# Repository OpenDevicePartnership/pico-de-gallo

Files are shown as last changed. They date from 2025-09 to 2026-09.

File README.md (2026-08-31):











# Pico de Gallo

A USB bridge that turns a [Raspberry Pi Pico 2](https://www.raspberrypi.com/products/raspberry-pi-pico-2/)
into a host-accessible I²C, SPI, UART, GPIO, PWM, ADC, and 1-Wire interface. Write and test
embedded Rust drivers on your development machine without cross-compiling
or flashing firmware to a target board.

## Overview

Pico de Gallo provides:

- **I²C**: read, write, write-then-read, bus scanning, and transaction batching
- **SPI**: read, write, full-duplex transfer, write-then-read, and transaction batching
- **UART**: read, write, flush, and baud rate configuration
- **GPIO**: digital input/output, edge event monitoring (subscribe/unsubscribe)
- **PWM**: 4-channel PWM output with configurable frequency and duty cycle
- **ADC**: 4 GPIO-based analog inputs (12-bit)
- **1-Wire**: bus reset, read, write, strong pullup, and ROM search (PIO hardware)
- **Configuration**: runtime I²C/SPI/UART/PWM frequency and SPI mode changes

All communication uses [postcard-rpc](https://docs.rs/postcard-rpc) over
USB — a compact, typed, binary RPC protocol.

## Book

The [Pico de Gallo Book](https://balbi.sh/pico-de-gallo/)
covers hardware assembly, firmware flashing, and a step-by-step guide to
writing an embedded device driver using Pico de Gallo.

## Crates

| Crate | Description |
|---|---|
| [`pico-de-gallo-firmware`](crates/pico-de-gallo-firmware) | Embassy-rs firmware for the RP2350 |
| [`pico-de-gallo-lib`](crates/pico-de-gallo-lib) | Async host library (requires tokio) |
| [`pico-de-gallo-hal`](crates/pico-de-gallo-hal) | `embedded-hal` + `embedded-hal-async` implementation |
| [`pico-de-gallo-ffi`](crates/pico-de-gallo-ffi) | C FFI bindings (shared library + header) |
| [`gallo`](crates/pico-de-gallo-app) | CLI application for batch-mode access |
| [`gallo-mcp`](crates/pico-de-gallo-mcp) | MCP server exposing the device to AI agents |
| [`pico-de-gallo-internal`](crates/pico-de-gallo-internal) | Shared wire-protocol types (internal) |

### Firmware

Embassy-rs firmware for the RP2350 that exposes I²C, SPI, UART, and GPIO
peripherals over USB via postcard-rpc endpoints.

Two mutually exclusive board-revision features select the target. `hw-rev2`
(v1.1 and later) is the **default**. `hw-rev1` (v1.0) is **deprecated** — it
stays supported, built in CI, and published as `firmware-rev1.uf2`, with
removal no earlier than 2031-09-01 — and must now be requested explicitly
with `--no-default-features --features hw-rev1`. See
[`crates/pico-de-gallo-firmware/README.md`](crates/pico-de-gallo-firmware/README.md)
for build commands and
[Revisions](https://balbi.sh/pico-de-gallo/hardware/revisions.html) for the
policy.

### Library

Async host-side library wrapping the postcard-rpc transport. Provides
typed methods for every firmware endpoint. Requires the tokio runtime.

### HAL

Implements both `embedded-hal` and `embedded-hal-async` traits — including
`I2c`, `SpiBus`, `SpiDevice`, GPIO digital I/O, delay, and `embedded-io`
Read/Write for UART (0.6 and 0.7, selectable by Cargo feature) — so embedded
device drivers written against those traits can be tested on a host machine
with real hardware attached to the Pico de Gallo.

### App

Command-line tool (`gallo`) for interactive and batch-mode I²C/SPI/UART/GPIO
access. Supports hex, binary, and ASCII output formats.

### FFI

C-compatible shared library wrapping the Rust host library. Generates a
C header via cbindgen. Suitable for integration into C/C++/Python/etc.
projects.

### Internal

Shared wire-protocol crate defining all postcard-rpc endpoints, request
and response types, and constants. Used by both firmware and host crates.

## Zephyr

Zephyr module that lets a Zephyr application running on `native_sim` drive
real I²C, SPI, and GPIO peripherals through the `pico_de_gallo` shield — so
you can write and debug a Zephyr driver on your laptop against real silicon,
without cross-compiling or flashing. See [`zephyr/README.md`](zephyr) for the
full guide; the module is documented there rather than in the book, by the
carve-out recorded in `AGENTS.md` §15.1.

## Hardware

KiCAD schematic and PCB design for a Pico 2 daughter board. The v1.1
board features a single keyed 2x12 shrouded header that routes all 20
firmware signals with on-board I²C pull-ups and ADC input protection.

## Case

3D-printable snap-fit enclosure (FreeCAD) in two parts — body and lid.

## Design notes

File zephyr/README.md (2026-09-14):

# pico-de-gallo Zephyr Module

This README describes the `pico-de-gallo/zephyr` Zephyr module, including how
to build and run it. It is the **authoritative** guide for the module: by a
deliberate ruling recorded in `AGENTS.md` §15.1, the module has no `book/`
chapter while it remains work-in-progress. That ruling is revisited once the
upstreaming tracked in
[#98](https://github.com/OpenDevicePartnership/pico-de-gallo/issues/98) lands.

`pico-de-gallo/zephyr` is a Zephyr module that lets Zephyr applications drive
real I2C, SPI, UART, GPIO and PWM peripherals from `native_sim`. It provides the
`pico_de_gallo` [shield](https://docs.zephyrproject.org/latest/hardware/porting/shields.html),
whose drivers forward Zephyr I2C, SPI, UART, GPIO and PWM API calls through the
`pico-de-gallo-ffi` C API to a Pico de Gallo board attached to the host over
USB.

The practical upshot: you write and debug a Zephyr device driver on your
laptop, against the real silicon, without cross-compiling or flashing.

---

## Prerequisites

| Requirement | Notes |
|---|---|
| Zephyr revision | The measured build environment was `main` at `v4.4.0-6123-g26f811ee9d0d`, commit `26f811ee9d0dc8f67e8e596f6aef9e6e79a55db0`. CI pins that exact commit; `.github/workflows/zephyr.yml` fails if this line and its `ZEPHYR_REVISION` disagree. The driver uses `spi_cs_control.delay`, `spi_context`'s `ctx->num_cs_gpios`, `SPI_CONTEXT_CS_GPIOS_INITIALIZE`, and `DEVICE_API`. This checkout does not establish the earliest compatible Zephyr release; treat `main` as the verified baseline rather than an asserted minimum. |
| A 64-bit `native_sim` | Always build `native_sim/native/64`. `zephyr/Kconfig` has `depends on 64BIT`, because `corrosion_set_hostbuild()` forces the rustc host triple. Plain `native_sim` is 32-bit and will not work. |
| Rust 1.90+ and Cargo | The FFI is built from this repository by Corrosion during the Zephyr build. |
| A host C toolchain | `native_sim` compiles with host GCC/Clang. No Zephyr SDK is required. |
| CMake 3.20+ | Corrosion 0.5.2 is used specifically because it still supports Zephyr's 3.20 baseline. |

Record the Zephyr revision before reporting a build result:

```bash
git -C "$ZEPHYR_BASE" describe --always --dirty
```

---

## Setting up a workspace

**You do not need to clone this repository inside your Zephyr workspace.** The
samples add the module themselves via `EXTRA_ZEPHYR_MODULES` in their
`CMakeLists.txt`, so the checkout can live anywhere.

If you do not already have a Zephyr workspace, create one on `main`:

```bash
python3 -m venv ~/zephyr-venv
~/zephyr-venv/bin/pip install west

source ~/zephyr-venv/bin/activate
west init -m https://github.com/zephyrproject-rtos/zephyr --mr main ~/zephyrproject
cd ~/zephyrproject
west update
west packages pip --install
west zephyr-export
```

`west update` pulls several GB and takes a while. A partial clone is much
faster and is sufficient for building:

```bash
west update --narrow -o=--filter=blob:none
```

### Environment

Every command below assumes these three:

```bash
export ZEPHYR_BASE=~/zephyrproject/zephyr
export ZEPHYR_TOOLCHAIN_VARIANT=host
export PATH=~/zephyr-venv/bin:$PATH
```

`ZEPHYR_TOOLCHAIN_VARIANT=host` is the one people miss. `native_sim` needs no
Zephyr SDK, but Zephyr still *searches* for one first and fails hard if what it
finds is too old:

```text
CMake Error at .../FindZephyr-sdk.cmake:165 (find_package):
  Could not find a configuration file for package "Zephyr-sdk" that is
  compatible with requested version "1.0".
```

Setting the variant skips that search. `ZEPHYR_BASE` additionally pins which
Zephyr is used if you have stale entries in `~/.cmake/packages/Zephyr`.

---

## Continuous integration

`.github/workflows/zephyr.yml` builds this module on every pull request that
touches `zephyr/`, `crates/pico-de-gallo-ffi/`, `crates/pico-de-gallo-internal/`,
either root Cargo file, or its own `.github/workflows/zephyr.yml` definition.
It pins Zephyr to the commit recorded above and drives
`zephyr/scripts/ci-build.sh`, which builds fifteen targets: three viable samples,
the two IS31 samples (asserted to fail exactly as they do at baseline), the
four M5 test applications, the UART driver build target, the I2C gather-write
regression image, the UART recording-fake image, the board-attached UART
configuration application, the PWM recording-fake image, and the PWM fade
sample.

To reproduce a CI failure locally, with a Zephyr workspace already set up:

```bash
export ZEPHYR_BASE=~/zephyrproject/zephyr
export ZEPHYR_TOOLCHAIN_VARIANT=host
zephyr/scripts/ci-build.sh --targets i2c_bridge
```

`--self-test` runs the assertion parsers against checked-in fixtures and needs
no Zephyr workspace at all.

The `ci-build.sh` job is build-only. Twister also builds every board-attached
image, but executes the I2C, UART and PWM recording-fake scenarios because their
bottom layers replace USB and the C FFI. A green workflow therefore proves that
the module compiles and links and that those fake-driven top halves pass. It
does **not** prove that the module works against hardware. That remains
`tests/pdg_mfd_m5/run-m5.sh` and `tests/pdg_i2c_burst`, run by hand with a board
and, for the M5 images, the physical jumpers in place. The UART-specific manual
applications are `samples/uart_bridge` and `tests/pdg_board/uart`. **PWM has no
hardware-attached counterpart at all**: it has never been run against a board in
this project, so `tests/pdg_fake/pwm` is the primary evidence for that driver
rather than a supplement to a hardware demo.

For the UART driver specifically, M6 adds executed recording-fake evidence for
top-half control flow and argument transcription. Its compile-time mapping and
topology assertions were checked by review plus a recorded mutation, but
`ci-build.sh` has no target kind that asserts a `BUILD_ASSERT` fires, so CI does
not exercise those negative cases. M7 has since run the driver on hardware; see
[UART hardware verification](#uart-hardware-verification) for the measured
results and the remaining equipment-dependent gaps.

### Twister metadata

Thirteen applications carry a `tests.yaml`: four samples, six board-attached test
images, and the I2C, UART and PWM recording-fake suites. Together they declare
fourteen scenarios. A second CI job runs twister over `zephyr/samples` and
`zephyr/tests`.

Three things about that file are easy to get wrong:

- **It is `tests.yaml`, not `sample.yaml` or `testcase.yaml`.** Upstream has
  retired both older names: `filename:sample.yaml` and
  `filename:testcase.yaml path:tests/drivers` each return zero results against
  `zephyrproject-rtos/zephyr`, while `tests/drivers` alone holds 268
  `tests.yaml` files. Samples keep a `sample:` key *inside* `tests.yaml`.
- **Ten scenarios are `build_only: true`.** Twister classifies `native_sim`
  as `type: native` and would otherwise execute board-attached binaries, which
  reach `gallo_init_strict()` on a runner with no board. The four exceptions
  are the I2C fake scenario, the UART fake's capability-present and
  capability-absent scenarios, and the PWM fake scenario.
- **None declares `depends_on`.** That key is matched against the board's
  `supported:` list, and `native_sim/native/64` does not name `i2c`, `spi`,
  `uart` or `pwm` — only the 32-bit `native_sim` names some of them. Claiming
  one would filter the
  scenario away to nothing on the only platform this module targets, and would
  report it as skipped rather than as an error.

Twister duplicates most of what `ci-build.sh` already does, and does it with
weaker build assertions — it has no equivalent of the two-sided
translation-unit and Kconfig checks. It earns its place for two other reasons.
It forces `CONFIG_COMPILER_WARNINGS_AS_ERRORS=y` **and** `--edtlib-Werror`, so
devicetree
*binding* warnings become build failures; this module ships six custom
bindings and a plain `west build` never checks them that way. It also executes
the four hardware-free recording-fake scenarios. The measured M6 run passed
all three UART and I2C configurations and all 19 cases:

```text
drivers.pico_de_gallo.i2c.fake                 passed   2/2
drivers.pico_de_gallo.uart.fake                passed  14/14
drivers.pico_de_gallo.uart.fake_no_capability  passed   3/3
3 of 3 configurations passed, 19 of 19 test cases passed
```

Adding the PWM fake suite brought that to four executed configurations. The
measured sweep over `zephyr/samples` and `zephyr/tests` at Zephyr
`v4.4.0-6123-g26f811ee9d0d`:

```text
14 test scenarios (14 configurations) selected, 0 configurations filtered
4 of 14 executed test configurations passed (28.57%), 10 built (not run), 0 failed, 0 errored
44 of 44 executed test cases passed (100.00%)
```

The 25 new cases are `drivers.pico_de_gallo.pwm.fake`.

The UART scenarios use one source tree and select capability present or absent
with the compile-time `PDG_FAKE_UART_CAPABILITY` CMake cache variable. This must
be compile-time policy: `POST_KERNEL` device initialization runs before any
ztest hook could change a runtime fake.

#### UART recording-fake coverage

The capability-present scenario enables five dedicated UART instances at
115200, 57600, 38400, 19200 and 9600 baud. Those distinct rates are
load-bearing: every child borrows the same parent `ctx`, so the recorded baud is
the only way to attribute an initialization `set_config` call to a child. The
instances are dedicated because the RX and TX transport latches are permanent
and cannot be re-armed. Keep `CONFIG_ZTEST_SHUFFLE` disabled.

The executed suite covers:

- capability-gated initialization, including aggregate capability/configuration
  event ordering — no configuration is ever preceded by fewer capability probes
  than configurations — and a latched parent close count that remains exactly
  zero. Per-child ordering is NOT proven: capability events carry no child
  discriminator, because the shared parent fake hands every child the same
  context, so that remains source-review evidence;
- the ISR-context refusal matrix and absence of bottom calls;
- exact `uart_poll_in() == -1` behaviour for an empty ring, plus one refill
  serving eight polls with one bottom read and a ninth poll causing the second;
- one bottom write per output byte;
- transcription of all supported data-bit, parity (including mark and space),
  and stop-bit values, with rejected configurations making no bottom call and
  the cached configuration following acknowledged success only;
- side-effect-free `-ENOTSUP` behaviour from the asynchronous and wide stubs;
- RX and TX transport latches that suppress every subsequent call in the
  bounded tested sequence, including staged-ring discard; device-lifetime
  permanence is established by source review, not by this suite; and
- the 10 ms non-transport receive backoff and a successful recovery attempt
  after its deadline.

#### What the UART recording fake does not prove

The recording fake replaces the bottom layer, so that run proves top-half
control flow and recorded arguments only. M7 later closed some of these gaps on
hardware, but not through the fake itself. In particular, the fake does not
prove:

- USB enumeration or transport, firmware execution or rings, postcard framing,
  host timeouts, real backpressure, or the real FFI `Status`-to-errno mapping;
  the tests inject errnos directly and bypass `pdg_common_status_to_errno()`;
- the values of private `tx_dropped`, `rx_errors`, `last_errno`, or
  `link_failed`; exposing them would widen the production driver, so the suite
  asserts their externally visible effects instead;
- that the ISR guard precedes the mutex. It proves only that an ISR-context call
  returns the documented value and makes no bottom call; moving the guard just
  after an uncontended lock would still pass;
- that a successful refill explicitly clears backoff. Success can occur only
  after the deadline has expired, making that assertion vacuous;
- `k_is_pre_kernel()` guards, mutex contention, queued-caller behaviour, or the
  pre-lock/post-lock latch checks with a real waiting thread;
- the console-reentrancy hazard behind `uart_poll_out()`'s never-log rule; the
  suite does not make this UART the active console;
- the measured `timeout_ms = 0` latency (about 359 us versus about 1489 us), the
  low-baud clamp, physical framing, firmware ring behaviour, or the
  indeterminate "byte applied but acknowledgement lost" case; and
- per-child capability-before-configuration ordering. Capability events carry no
  child discriminator, because the shared parent fake hands every child the same
  context, so only the aggregate running-prefix invariant is asserted;
- that the RX and TX transport latches are permanent for the device's lifetime.
  The suite proves suppression only across the bounded sequence of immediate
  follow-up calls it makes; permanence is a source-review property;
- a real read result greater than 1014 bytes, which real firmware cannot
  produce. Only the defensive top-half handling of an injected value is tested.

The manual M7 run below measured physical word lengths, the low-baud clamp, and
RX-ring overflow recovery. It did not make the fake stronger, and the other gaps
above remain limits unless that section says otherwise.

---

## Running the I2C sample

`samples/i2c_bridge` reads ambient temperature from a TI TMP117 at address
`0x48` through the Zephyr sensor API.

Wire a TMP117 to the board's I2C pins, attach the board over USB, then:

```bash
cd zephyr/samples/i2c_bridge
west build -p always -b native_sim/native/64 -- -DSHIELD=pico_de_gallo
west build -t run
```

> **Pass `-b` and `-DSHIELD=` explicitly on the first build.** The sample's
> `CMakeLists.txt` sets `BOARD` and `SHIELD` with `set(... CACHE ...)`, but west
> resolves `BOARD` *before* invoking CMake, so those defaults never take effect.
> A bare `west build -t run` in a clean tree therefore fails. Once the build
> directory is configured, plain `west build -t run` works.

With a board and sensor attached, expect:

```text
*** Booting Zephyr OS build v4.4.0-... ***
Temperature: 23.500000 C
Temperature: 23.507812 C
```

Without a board attached you get this instead, which is the normal way this
looks when the bridge is missing:

```text
gallo_init_strict: device not reachable: Failed to find matching nusb device!
<err> mfd_pico_de_gallo: pico-de-gallo: failed to open a Pico de Gallo bridge (default selector). Returning -ENODEV.
<err> i2c_pico_de_gallo: i2c: Pico de Gallo parent pico-de-gallo is not ready. Returning -ENODEV.
<err> TMP11X: i2c device not ready
*** Booting Zephyr OS build v4.4.0-... ***
TMP117 not ready (Pico de Gallo bridge connected?)
```

The MFD parent owns the USB connection, so it is the node that reports the
open failure. Each controller then fails fast against the parent rather than
retrying the open itself.

The strict parent open can block for up to **300 seconds**. During that wait all
children remain unavailable; this is expected worst-case timeout behaviour, not
by itself evidence of a hang. Registry and FFI diagnostics are written to host
`stderr` and may not appear in the Zephyr log. Capture both streams under west,
CI, services, and redirected runners.

The sample loops forever. `native_sim` accepts runner arguments directly, so
bound the run or slow it to wall-clock time:

```bash
./build/zephyr/zephyr.exe -stop_at=10   # exit after 10 simulated seconds
./build/zephyr/zephyr.exe -rt           # run at host real time, not as fast as possible
./build/zephyr/zephyr.exe --help        # full list of runner options
```

Simulated time otherwise advances as fast as the host allows, which makes
`k_sleep()`-based sampling loops run far faster than the wall clock.

## Running the UART sample

`samples/uart_bridge` is a bounded polling example for `uart_poll_out()` and
`uart_poll_in()`. It sends a fixed greeting one byte at a time, makes at most 64
receive attempts, prints any received bytes, and exits. Set the parent
`serial-number` in `app.overlay`, connect a UART peer to the board's TX/RX pins,
then build and run it:

```bash
cd zephyr/samples/uart_bridge
west build -p always -b native_sim/native/64 -- -DSHIELD=pico_de_gallo
west build -t run
```

The sample's Twister scenario is **build-only**. Running the image reaches
`gallo_init_strict()` and opens a USB device, so CI never executes it. The UART
recording-fake suite described under *Continuous integration* is the
hardware-free runtime coverage; it does not execute this sample or its real
bottom layer.

### Board-attached UART configuration application

`tests/pdg_board/uart` is a plain `main()` application for manual UART driver
bring-up. It exercises `uart_configure()` and `uart_config_get()`, word-length
masking, frame-length timing, invalid-configuration errno mapping, and final
restoration to 115200 8N1. Its Twister scenario is
`board.pico_de_gallo.uart.loopback`, marked `build_only: true`; CI compiles it as
the thirteenth `ci-build.sh` target, `board_uart`, but never runs it.

Physically short UART TX (GPIO 0) to UART RX (GPIO 1) before running it. The
committed `app.overlay` intentionally contains a placeholder serial number.
Create a scratch overlay **outside the repository** with the real selector:

```dts
&pdg0 { serial-number = "5256657D8A5D7F03"; };
```

Then build and run from the repository root:

```bash
west build -p always -b native_sim/native/64 \
    zephyr/tests/pdg_board/uart -- \
    -DSHIELD=pico_de_gallo \
    -DEXTRA_ZEPHYR_MODULES="$PWD" \
    -DEXTRA_DTC_OVERLAY_FILE=/path/to/serial.overlay
west build -t run
```

Use `EXTRA_DTC_OVERLAY_FILE`, which appends the scratch assignment after the
application overlay. `DTC_OVERLAY_FILE` replaces `app.overlay` and silently
loses the UART child configuration. Keep
`CONFIG_UART_USE_RUNTIME_CONFIGURE=y`; without it Zephyr leaves the driver's
configuration slots unavailable and `uart_configure()` returns `-ENOSYS`.

### UART hardware verification

M7 ran on board `5256657D8A5D7F03` with TX and RX shorted, using firmware build
`firmware-v0.11.0-109-g6c4d42fd0796` (firmware 0.12.0, schema 0.8.0,
`hw-rev2`). This was the first execution of the Zephyr UART driver against real
hardware.

Verified results:

- `uart_bridge` echoed all 27 greeting bytes exactly:
  `48 65 6c 6c 6f 20 66 72 6f 6d 20 50 69 63 6f 20 64 65 20 47 61 6c 6c 6f 21 0d 0a`.
- `uart_configure()` and `uart_config_get()` worked through the driver. The 7N1
  masking probe returned `7f 00 55 2a`; restoring 8N1 returned
  `ff 00 55 aa`.
- Invalid configurations remained distinct: baud rate 0 returned `-EINVAL`
  (`-22`), while unsupported data bits returned `-ENOTSUP` (`-95`).
- All four word lengths changed the wire result as expected: 8, 7, 6, and 5
  bits returned `ff 00 55 aa`, `7f 00 55 2a`, `3f 00 15 2a`, and
  `1f 00 15 0a`, respectively.
- A frame-length timing fit measured a 6.18 ms slope per bit per character,
  93% of the physical 6.67 ms prediction. A stale framing register would have
  produced a zero slope.
- The firmware's roughly 143-baud divisor floor was measured at about 147 baud,
  with convergence beginning between requested rates 143 and 100. Earlier
  documentation had inferred this clamp from embassy-rp rather than measuring
  it.
- RX-error latch recovery was provoked by writing 1280 bytes without an
  intervening read against the firmware's 1024-byte RX ring. All three overflow
  trials surfaced `Endpoint(Other)` exactly once and then recovered; both
  no-overflow controls completed without an error. Exactly 1024 bytes arrived
  in order, with four discontinuities at write boundaries, matching an overrun.
- A strict open with the wrong serial refused in 511 ms, named the requested
  selector, and did not fall back to the one attached board.

The loopback rig cannot verify everything:

- Odd versus even and mark versus space parity need an independent UART peer or
  a logic analyser. One PL011 drives and receives both ends, and 8E1, 8O1, 8M1,
  and 8S1 are all 11-bit frames. All four looped back cleanly and had
  statistically indistinguishable medians (511.5, 511.1, 411.5, and 514.3 ms),
  which is evidence of the limitation rather than proof of parity selection.
- The `hw-rev1` capability refusal needs a v1.0 board.
- Unplug, re-enumeration, firmware reset, transport faults, lost
  acknowledgements, TX-ring saturation, and active-console fault injection were
  not exercised.
- Embassy's private `rx_error` register and RX interrupt-enable bits were not
  observed directly; that requires RTT or a debugger. Their recovery
  consequences were measured, but the mechanism remains inferred.

Two measurement traps matter when repeating this work. First, `native_sim` time
was simulated with `CONFIG_NATIVE_SIM_SLOWDOWN_TO_REAL_TIME=y`: elapsed
milliseconds in a drain advance through its polling `k_sleep()`, so absolute
values are not wall-clock measurements even though the fitted slope reflects
physical frame length. Second, separate `gallo` processes cannot measure wire
timing: process startup costs roughly 200–300 ms, timing is quantized around
100 ms, and the line drains between the write and read invocations. A control
even gave the 9600-versus-115200 median difference the wrong sign. Future UART
timing measurements must perform write and read in one process.

### The other two samples do not build yet

`samples/spi_bridge` and `samples/combined_i2c_spi_bridge` drive an
IS31FL3743B LED matrix, and that driver is **not** in Zephyr `main` — only
`is31fl319x`, `is31fl3216a` and `is31fl3733` are upstream. Until it lands,
those two samples cannot be built against an upstream checkout. Use
`samples/spi_nor_id` for SPI instead.

Neither carries a `tests.yaml`, so twister does not see them. That is
deliberate, not an omission. `ci-build.sh` already covers them far more
precisely than twister could: `assert_basefail()` requires the build to fail,
requires `zephyr.elf` to have linked anyway, requires *exactly one* undefined
`__device_dts_ord_N`, and requires that ordinal to resolve to an
`is31fl3743b` node. A twister scenario could only say "this failed", which any
unrelated breakage would also satisfy. Giving them one would add a second,
weaker signal that could go green for the wrong reason.

When the driver lands upstream, `assert_basefail()` starts failing on purpose —
its comment says a *success* is what to act on — and both samples should get a
`tests.yaml` at that point.

### The I2C gather-write regression image

`tests/pdg_i2c_burst` is a board-attached regression test for
[#102](https://github.com/OpenDevicePartnership/pico-de-gallo/issues/102), where
`i2c_burst_write()` was rejected with `-ENOTSUP`. It needs the same TMP117 or
TMP102 at `0x48` as `samples/i2c_bridge`, and it writes to a limit register
rather than reading temperature, restoring the entry value before it exits.

```bash
west build -p always -b native_sim/native/64 zephyr/tests/pdg_i2c_burst \
    -- -DSHIELD=pico_de_gallo -DEXTRA_ZEPHYR_MODULES=$PWD \
       -DDTC_OVERLAY_FILE=$PWD/zephyr/tests/pdg_i2c_burst/burst.overlay
west build -t run
```

Success is `PDG_I2C_BURST_PASS` and exit status 0. Any failure prints
`PDG_I2C_BURST_FAIL` naming the step, the expected value and the observed one.

Every assertion compares against a reference read-back rather than against the
bytes written, because a peripheral need not return what you wrote — a TMP102 in
12-bit mode zeroes the low nibble of its limit registers while a TMP117 keeps
all sixteen bits. Each case first writes its pattern through a single-message
`i2c_write()`, a shape that has always been accepted, and then requires the
gather path to reproduce exactly that result. The register is also set to the
*other* pattern immediately beforehand, so a driver that reported success
without issuing any bus traffic still fails.

CI builds and links this image but never runs it, so a green CI run is not
evidence that it passes.

---

## Running the SPI sample

`samples/spi_nor_id` identifies a JEDEC SPI NOR flash. Nothing in it is Pico
de Gallo specific: it uses Zephyr's stock `jedec,spi-nor` driver and the
generic flash API, and the bridge is just another SPI controller as far as
they are concerned. Geometry is discovered from the part at runtime over SFDP
(`CONFIG_SPI_NOR_SFDP_RUNTIME`), so the values printed are read from the
device rather than echoed back out of the devicetree.

Wire the flash to SCK/MOSI/MISO and put its chip-select on **firmware user
GPIO0 (RP2350 GPIO8, header pin 11)**, then:

```bash
cd zephyr/samples/spi_nor_id
west build -p always -b native_sim/native/64 -- -DSHIELD=pico_de_gallo
west build -t run
```

Illustrative output from a GigaDevice GD25Q16 holding an iCE40 bitstream (the
initialization prefixes and device names vary by Zephyr revision):

```text
<inf> mfd_pico_de_gallo: pico-de-gallo: ready ...
<inf> gpio_pico_de_gallo: gpio: ready ...
<inf> spi_pico_de_gallo: spi: ready on Pico de Gallo serial-number "..." with 1 chip select(s).
<inf> spi_nor: nor@0: SFDP v 1.0 AP ff with 2 PH
<inf> spi_nor: PH0: ff00 rev 1.0: 9 DW @ 30
<inf> spi_nor: nor@0: 2 MiBy flash
<inf> spi_nor: PH1: ffc8 rev 1.0: 3 DW @ 60
*** Booting Zephyr OS build v4.4.0-... ***
Flash device ready: nor@0
size:     2048 KiB
write:    1 B block, erased value 0xFF
erase:    65536 B pages, 32 total
@000000:  FF 00 00 FF 7E AA 99 7E 51 00 01 05 92 00 20 62
```

That the driver reaches `ready` at all is most of the result: it read the
JEDEC ID and walked the SFDP parameter tables across the USB bridge during
initialisation, and refuses to initialise if either fails. `PH1: ffc8` is the
GigaDevice vendor parameter header, so the tables really came from this part.

### Keeping it read-only

The sample calls only `flash_read()`. It never calls `flash_write()`,
`flash_erase()` or `flash_ex_op()`.

That alone is not sufficient, because the driver can also write during
initialisation. Every such path is gated on a devicetree property, and
`app.overlay` omits all of them:

| Property | Would allow |
|---|---|
| `has-lock` | `WREN`+`WRSR` to clear block-protect bits |
| `requires-ulbpr` | `ULBPR` |
| `enter-4byte-addr` | `WREN`+`4BA` |
| `has-dpd` | `DPD` / `RDPD` |
| `mxicy-mx25r-power-mode` | `WREN`+`WRSR` on the configuration registers |
| `use-flag-status-register` | `CLRFLSR` |

With those absent, initialisation issues only `RDID` and `RDSFDP`. Verified
on hardware: both status registers read `0x00` before and after, and flash
contents were byte-identical across the run.

**If you add any of those properties, or call a writing API, the driver will
write to your part.** That is the intended behaviour of the driver, not a
defect — just be deliberate about it when the flash holds something you care
about, such as an FPGA bitstream.

---

## Using the drivers in your own application

The shield declares a `pdg0` multi-function-device parent node and, as its
direct children, the `pdg_gpio0`, `pdg_i2c0`, `pdg_pwm0`, `pdg_uart0` and
`pdg_spi0` controller nodes. All six are **disabled by default**. Your
application enables `pdg0` *and* the controllers it needs, then declares its
peripherals as ordinary child nodes.

`pdg0` owns the USB connection to one physical board; the controllers borrow
it. An enabled controller whose parent is missing, disabled, or of the wrong
compatible is rejected at build time with an explanatory assertion.

### GPIO

`app.overlay`:

```dts
&pdg0 {
	status = "okay";
	serial-number = "E6614C311B8C9E37";
};

&pdg_gpio0 {
	status = "okay";
};
```

`prj.conf`:

```conf
CONFIG_GPIO=y
```

The pins are the board's firmware GPIO indices 0..3, which are RP2350 GPIO
8..11. `ngpios` must equal the firmware-reported GPIO count; a mismatch is a
local devicetree/firmware configuration error and fails initialization with
`-EINVAL`.

**`serial-number` on `&pdg0` is mandatory for an enabled GPIO child**, and the
build fails with an explanatory assertion without it. GPIO actuates physical
pins, and a selector-less connection cannot report which attached board it
selected, so an unpinned parent would drive unidentifiable hardware. Presence
is not uniqueness: two parents carrying the same explicit serial still alias to
one board. The configured serial is logged when the controller initializes
successfully.

Every operation that reaches hardware is a blocking USB round trip. Calls from interrupt context
return `-EWOULDBLOCK`; a transport failure is `-EIO`.

Multi-pin writes are **not atomic**: they are deterministic ascending, per-pin
round trips. If one fails, the acknowledged prefix definitely changed, the
failed pin is indeterminate because its request may have executed with only the
response lost, and later selected pins were never issued. The driver logs the
operation, the failed pin, the requested mask and value, and the acknowledged
prefix, and does not roll back. Output initialization is likewise two round
trips — configure, then level — so the pin becomes an output before the
requested level arrives and the previous or HAL-defined level may briefly
appear. After a failed `gpio_pin_configure()` the requested direction and pull
may nevertheless have been applied, and logical polarity is unreliable until a
successful reconfiguration.

Reads are scoped to input pins, as Zephyr specifies and as the reference
`gpio_emul` controller behaves: a pin the firmware records as an explicit
output reports a zero bit and the scan continues. That is only sound because
`GPIO_INPUT | GPIO_OUTPUT` is rejected, so a reported zero is provably not an
input pin. `gpio_pin_get()` is not a direction oracle. Direction-query APIs are
also unavailable on this controller (`gpio_pin_is_input()` and
`gpio_pin_is_output()` return `-ENOSYS`).

Reads are **not state-neutral**. `gpio_port_get_raw()` scans every pin, and
firmware `gpio/get` switches a `LegacyAuto` pad to input. Because
`gpio_pin_get()` is implemented through that whole-port scan, reading one pin
can reconfigure other, unrelated unconfigured pins. Configure every pin
explicitly before reading and do not use reads as passive state queries.

**Toggle and interrupts are unavailable.** `gpio_pin_toggle()` returns
`-ENOTSUP`, because an explicit output cannot be read back and this driver
deliberately caches no pin state. Interrupt configuration, callback management
and the pending-interrupt query return `-ENOSYS`. Generic toggle consumers,
including blinky, the GPIO shell, the TPS382x watchdog and the LS0xx display,
therefore do not work with this controller.

### I2C

`app.overlay`:

```dts
&pdg0 {
	status = "okay";
};

&pdg_i2c0 {
	status = "okay";

	tmp117: tmp117@48 {
		compatible = "ti,tmp11x";
		reg = <0x48>;
		status = "okay";
	};
};
```

`prj.conf`:

```conf
CONFIG_I2C=y
```

Bus speed comes from the `clock-frequency` property on the controller node
(the shield defaults to `<400000>`).

### UART

`app.overlay`:

```dts
&pdg0 {
	status = "okay";
	/* REQUIRED: UART drives physical TX and RX pads. */
	serial-number = "REPLACE_WITH_YOUR_PICO_DE_GALLO_SERIAL";
};

&pdg_uart0 {
	status = "okay";
	current-speed = <115200>;
	data-bits = <8>;
	parity = "none";
	stop-bits = "1";
};
```

`prj.conf`:

```conf
CONFIG_SERIAL=y
CONFIG_UART_USE_RUNTIME_CONFIGURE=y
```

The UART must be a direct child of an enabled `odp,pico-de-gallo` parent, and
that parent must carry `serial-number`. UART drives two physical pads, so
transmitting onto the wrong board's TX pin is the same class of mistake as
driving the wrong board's chip select. A missing, disabled or wrong-compatible
parent, or a parent without `serial-number`, fails the build with an explanatory
assertion. Presence is not uniqueness: two parents with the same serial still
alias one board.

This is a **thread-context-only polling controller**. Every hardware operation
is a blocking USB round trip. It is not callable from an ISR or before the
kernel is up: `k_mutex_lock()` asserts `!arch_is_in_isr()`, and USB I/O is not
ISR-safe. In either prohibited context `uart_poll_in()` returns `-1` and
`uart_poll_out()` drops and counts the byte without taking the mutex or issuing
an RPC. Implemented and explicit-stub driver callbacks with integer returns use
`-EWOULDBLOCK` from an ISR and `-EAGAIN` pre-kernel; NULL slots follow Zephyr's
wrapper behaviour documented in the limitation matrix below.

It also cannot be an early console. `CONFIG_EARLY_CONSOLE` installs its hook at
`PRE_KERNEL_1`, while this controller initializes at `POST_KERNEL`, so
`device_is_ready()` is false when the hook runs. A per-instance `BUILD_ASSERT`
rejects choosing a Pico de Gallo UART as `zephyr,console` with early console
enabled; another UART may still fill that role.

#### Receive path and permanent transport faults

`uart_poll_in()` stages reads in a 1014-byte ring. It consumes staged bytes
without I/O; when the ring is empty it performs one refill with
**`timeout_ms = 0`**, selecting the firmware's single-poll branch. On board
`5256657D8A5D7F03`, firmware
`firmware-v0.11.0-109-g6c4d42fd0796`, an empty 1014-byte refill measured about
359 us, versus about 1489 us with `timeout_ms = 1` and about 1422 us before the
firmware fast path. The 1 ms design therefore imposed a 4.15x idle-poll
penalty and retained -6% of the optimization.

Zero preserves the load-bearing recovery path. Both firmware branches call
`AsyncRead::read()`, whose first poll reaches Embassy `try_read()`, consumes
the latched `rx_error`, and re-enables RX interrupts. There is deliberately no
`read_ready()` shortcut: it inspects only the software ring and would leave
the error latched forever. M7 later provoked RX-ring overrun three times; each
trial surfaced one error and the next read recovered. That verifies the
driver-visible consequence. Embassy's private `rx_error` register and interrupt
enable bits were not observed directly, so the internal mechanism remains
inferred from source.

The mutex remains held during a refill. **The lost-response mutex bound is the
host library's ordinary call timeout, 5 seconds by default. This bound is
derived from `DEFAULT_CALL_TIMEOUT` in `crates/` and has not been observed.**
No M5, M6 or M7 test can drive it: the M6 fake bypasses the transport, while
unplug produces a fast `-ECOMM`. The previous 30-minute hazard was real:
`bounded_for(0)` gives zero its GPIO meaning of "no caller deadline". The host
library now routes zero-timeout UART reads through `uart_read_bound()` instead;
`uart_read_bound_zero_timeout_is_the_call_bound` and
`uart_read_bound_nonzero_timeout_still_tracks_the_firmware` pin both cases.
TX and reconfiguration queue behind that call. After a non-transport refill
error, the driver records the error and waits 10 ms before another refill. The
interval remains larger than the approximately 359 us refill round trip and
prevents a tight RPC loop. The error is not permanently latched, because a
later read is required for the firmware recovery path.

A confirmed transport error, `-ECOMM` or `-ETIMEDOUT`, instead discards the
staged ring and **permanently** fails fast for the device lifetime. Every later
`uart_poll_in()` returns `-1`, every later `uart_poll_out()` drops and counts its
byte, and neither issues another round trip. There is no reconnect path.

#### Transmit path and diagnostics

Transmission is deliberately unbuffered: every `uart_poll_out()` byte is one
`uart/write` RPC. The function returns `void`, so a dropped byte is never
reported to its caller and is never logged. Logging through the same UART would
re-enter `uart_poll_out()` once per character and could deadlock or recurse
without bound.

The capability gate prevents an unsupported board from becoming ready, but it
does not make later delivery reliable. After initialization a byte can still be
lost because of unplug or detach, a firmware supervisor reset, a half-open
transport, a host call timeout, a lost acknowledgement after the byte was
already queued, an endpoint error, schema skew, or a stale handle. A timed-out
write may therefore already have queued the byte: the driver never retries, and
blind retry is unsafe.

The driver records private `tx_dropped`, `rx_errors`, `last_errno` and
`link_failed` diagnostics. There is no public API, shell command or statistics
surface. M6 deliberately kept them private and tested their externally visible
effects instead; direct observation remains outside the current interface.

#### Configuration and initialization cost

The supported configuration envelope is 5, 6, 7 or 8 data bits; none, odd,
even, mark or space parity; 1 or 2 stop bits; and no flow control. Every non-zero
baud is forwarded. The firmware clamps its divisor to a floor of roughly 143
baud and does not report rounding, so `uart_config_get()` returns a software
shadow of what was requested, not the achieved line rate.

Reconfiguration is not atomic. The firmware restores an enabled `UARTCR` before
returning, leaving a brief window with the new divisor and old framing. Quiesce
and drain **both directions** before calling `uart_configure()`. On acknowledged
success the driver clears its local RX ring, but bytes decoded under the old
framing may remain in the firmware ring and arrive afterwards; they cannot be
distinguished from new-framing bytes.

Initialization gates the driver on `GALLO_CAP_UART` from `device/info`. This is
**not warm and not cached**: `gallo_get_device_info()` re-validates
unconditionally, issuing a fresh `device/info` request after the parent has
already completed its own validation.
**The capability probe's 300-second ceiling is derived from the host library's
`DEVICE_INFO_TIMEOUT` constant, not observed.** A clear capability bit returns
`-ENODEV`; a query failure returns its mapped errno, so unsupported hardware and
an unreachable device remain distinct outcomes.

`uart_err_check()` returns 0 for a healthy initialized thread-context call and
never invents `UART_ERROR_*` bits. The firmware collapses every Embassy UART
error to one `Other` value, so a receive overrun is silent at every layer. The
driver's private health diagnostics above are not line-error bits.

### PWM

`app.overlay`:

```dts
&pdg0 {
	status = "okay";
	serial-number = "REPLACE_WITH_YOUR_PICO_DE_GALLO_SERIAL";
};

&pdg_pwm0 {
	status = "okay";
};
```

`prj.conf`:

```conf
CONFIG_PWM=y
```

Like every other child, the PWM controller must be a direct child of an enabled
`odp,pico-de-gallo` parent that carries `serial-number`, and each of those is a
build-time assertion rather than a runtime surprise. PWM drives physical pads,
so the selector is as load-bearing here as it is for GPIO, UART and SPI.

Four channels, `0` through `3`, are exposed. They are **not** the firmware user
GPIO indices that the `gallo` CLI and `cs-gpios` use — that is a separate
namespace — and they are not header pin numbers:

| PWM channel | RP2350 GPIO | RP2350 slice |
|---|---|---|
| 0 | GPIO12 | slice 6, channel A |
| 1 | GPIO13 | slice 6, channel B |
| 2 | GPIO14 | slice 7, channel A |
| 3 | GPIO15 | slice 7, channel B |

Every operation is a blocking USB round trip. A single `pwm_set_cycles()` costs
up to three of them — `pwm/set-config`, `pwm/get-duty-cycle`,
`pwm/set-duty-cycle` — plus a fourth `pwm/enable` on a slice's first use.

#### Cycles are source-clock ticks

`pwm_get_cycles_per_sec()` reports **150000000**, the PWM *source* clock, for
every channel and in every configuration. `period_cycles` and `pulse_cycles`
are therefore source-clock ticks, and `PWM_HZ()`, `PWM_KHZ()` and `PWM_MSEC()`
work as usual.

It deliberately does not report the counter rate. The counter advances at
`150e6/divider`, the divider changes with every frequency change and differs
between the two slices, and it is not on the wire at all — so it could never be
the stable per-device constant Zephyr's API requires. Reporting the source
clock makes `period_cycles` independent of it.

The driver converts a period to a frequency with a **ceiling**,
`ceil(150e6 / period_cycles)`, and scales the pulse into the firmware's raw
compare domain with round-half-up against the full-scale duty it reads back
from the device. The full scale is read rather than computed: it is `top + 1`
for whatever divider the firmware's own search settled on, which the driver
cannot predict without duplicating that search and then drifting from it
silently.

#### Period bounds

| Period (source-clock cycles) | Result |
|---|---|
| Below 2 | `-EINVAL`; the firmware requires `top >= 1` |
| 2 through 16711680 | accepted |
| Above 16711680 (roughly 9 Hz) | `-ENOTSUP` |

The upper bound is a **panic guard, not a capability statement**. A longer
period derives a frequency the firmware would try to reach with a clock divider
above 255, which embassy-rp panics on rather than refusing, taking the whole
device down. This contains
[#192](https://github.com/OpenDevicePartnership/pico-de-gallo/issues/192) for
Zephyr consumers only; the CLI, `pico-de-gallo-lib`, the C FFI, Python and MCP
can all still reach it.

The ceiling on the frequency conversion is what makes 16711680 safe. Flooring
would lengthen the period and yield 8 Hz there, needing divider 287 — which is
exactly the panic. Ceiling yields 9 Hz, needing exactly 255. The bound itself is
`255 * 65536`, chosen because it is obviously safe by inspection. It is
substantially conservative, not marginally so: with the ceiling conversion the
derived frequency stays at 9 Hz for every period up to 18749999, and only drops
to 8 Hz at 18750000, where `150e6 / period` is exactly 8. So the true safe
maximum is 18749999 and this bound sits comfortably below it.

#### Slice sharing

Channels 0 and 1 share RP2350 slice 6; channels 2 and 3 share slice 7. **A
slice has one period and one enable.** Requesting a period on a channel whose
slice sibling is already configured at a different period is refused with
`-EINVAL`, before any device call, rather than silently changing a period its
owner never asked for. Plan for one period per slice, or use channels 0 and 2
if you need two independent periods. Duty cycles are always independent.

`pwm/set-config` rescales **both** channels' compare values with truncating
integer division, so a reconfiguration would drift a sibling's duty downward.
This driver never has to compensate for that: the conflicting-period refusal
means a slice is never reconfigured while its sibling is in use, so the drift is
**unreachable rather than mitigated**. `tests/pdg_fake/pwm` pins that invariant
directly, so relaxing the conflict rule fails a test rather than quietly
introducing the drift.

#### The driver never disables a slice

There is no disable path, and the omission is structural rather than a
convention: `drivers/pwm/pdg_pwm_bottom.h` declares no disable function, so the
top half cannot call one by accident. The firmware's disable acts on a whole
slice, so disabling one channel would stop its sibling mid-operation.

A slice is enabled on first successful use and left enabled. A pulse width of
zero already produces a constant-low output, which is what "off" means here.

#### Failure behaviour and initialization

A failure *after* the slice has been reconfigured leaves the device in a state
the driver cannot describe, so it discards everything it believed about that
slice and both its channels rather than remembering something possibly false.
That costs nothing: `pwm_set_cycles()` always supplies both period and pulse, so
the next call on either channel re-establishes the lot. The `enabled` flag is
discarded with the rest — not because the slice is believed disabled, but
because the driver no longer claims to know, so it re-asserts the enable on the
next successful call. `pwm/enable` is idempotent, so that costs one extra RPC
and buys a state model with no exceptions.

A failing *enable* is the one post-`set_config` failure that does **not**
invalidate, and deliberately so. By that point both the reconfiguration and the
duty write have succeeded, so the tracked period and duty are accurate and the
device really is at that period; forgetting would throw away true information.
Leaving `enabled` false is the correct residue — the next call retries the
enable.

Initialization gates the driver on `GALLO_CAP_PWM` from `device/info`. Every
shipped firmware advertises PWM on **both** hardware revisions, so this gate
does not fire today; it exists because the capability bit is the contract. A
clear bit returns `-ENODEV`, while a failed query returns its own mapped errno,
so unsupported hardware and an unreachable board stay distinct. As with the
UART gate, this is not a warm read: `gallo_get_device_info()` re-validates
unconditionally and costs a fresh `device/info` round trip.

#### The PWM fade sample

`samples/pwm_fade` fades an LED on a PWM channel. Its Twister scenario is
**build-only**: running it reaches `gallo_init_strict()` and opens a USB device.

```bash
cd zephyr/samples/pwm_fade
west build -p always -b native_sim/native/64 -- -DSHIELD=pico_de_gallo
west build -t run
```

The committed `app.overlay` carries a placeholder serial number; replace it
before running, the same way `tests/pdg_board/uart` describes.

**The PWM driver has never been run against hardware.** `tests/pdg_fake/pwm` is
the primary evidence for it, not a supplement to a hardware demo, and the fake
models the firmware's own divider search — stopping at 255 rather than the
firmware's 4095 — so a test cannot pass on a configuration that would take down
a real board.

### SPI

`app.overlay`:

```dts
#include <zephyr/dt-bindings/gpio/gpio.h>

&pdg0 {
	status = "okay";
	/*
	 * REQUIRED for SPI: chip select actuates a physical GPIO, so the
	 * parent must name the board. Use the serial from `gallo list`.
	 */
	serial-number = "REPLACE_WITH_YOUR_PICO_DE_GALLO_SERIAL";
};

&pdg_gpio0 {
	status = "okay";
};

&pdg_spi0 {
	status = "okay";
	cs-gpios = <&pdg_gpio0 2 GPIO_ACTIVE_LOW>,
		   <&pdg_gpio0 0 GPIO_ACTIVE_LOW>;

	my_device: my-device@0 {
		compatible = "vendor,my-device";
		reg = <0>;
		spi-max-frequency = <1000000>;
		status = "okay";
	};
};
```

`prj.conf`:

```conf
CONFIG_SPI=y
```

#### Chip select is standard `cs-gpios`

`cs-gpios` is **required** on every enabled controller. There is no native-CS
fallback: a missing property fails devicetree processing with
`'cs-gpios' is marked as required in 'properties:'`. A child's `reg` has its
standard Zephyr meaning — an index into the `cs-gpios` array. Above, `reg = <0>`
selects firmware GPIO index 2 and `reg = <1>` selects index 0.

The pin cell is a **firmware user GPIO index**, the same namespace the `gallo`
CLI uses, *not* an RP2350 pin number and not a header pin number:

| Firmware index | Board GPIO | RP2350 GPIO | Header pin |
|---|---|---|---|
| 0 | GPIO0 | GPIO8 | 11 |
| 1 | GPIO1 | GPIO9 | 12 |
| 2 | GPIO2 | GPIO10 | — |
| 3 | GPIO3 | GPIO11 | — |

The board's separately silkscreened `SPI_CS` signal (RP2350 GPIO5) is not
claimed by the firmware and cannot be used here.

`GPIO_ACTIVE_LOW` is typical. `GPIO_ACTIVE_HIGH` is permitted, because GPIO
logical polarity determines the physical edge; the SPI operation flag
`SPI_CS_ACTIVE_HIGH` remains rejected with `-ENOTSUP`.

Every entry must target an **enabled** `odp,pico-de-gallo-gpio` controller
under the **same** `odp,pico-de-gallo` parent, and the parent must declare
`serial-number`. Each of these is a build-time failure with an assertion naming
the `cs-gpios` array index:

| Devicetree mistake | Result |
|---|---|
| No `cs-gpios` on an enabled controller | **Devicetree error** — required property |
| Entry targets a foreign (non-PDG) GPIO controller | **Build fails** — compatible assertion |
| Entry targets a disabled PDG GPIO sibling | **Build fails** — status assertion |
| Entry targets a PDG GPIO under a *different* parent | **Build fails** — same-parent assertion |
| Parent has no `serial-number` | **Build fails** — serial assertion |

The cross-parent case is the one that matters most. It is a real, enabled Pico
de Gallo GPIO port — but on a *different physical board*, so chip select would
be driven on one board while data was clocked on another.

#### What this costs

Chip select is no longer part of an atomic firmware batch. An ordinary
successful transceive is **four** USB round trips:

```text
spi/set-config -> gpio/put(assert) -> spi/transfer -> gpio/put(deassert)
```

Each can fail independently. Host death after the assert leaves chip select
asserted; a fresh session can deassert ordinary residue.
Every host RPC is bounded by a timeout since #178. A response lost at the
transport therefore returns `-ETIMEDOUT` rather than leaving the calling thread
pending forever. The SPI lock remains held until that bounded call returns;
normal deassert and fault-latch handling then apply. Firmware #157 also added a
watchdog supervisor that resets a genuinely wedged dispatcher in about 10.5
seconds.

The Zephyr SPI driver rejects any transfer whose clocked length exceeds 1014
bytes. Every Zephyr SPI operation is one full-duplex `gallo_spi_transfer()`, so
the response frame is the binding limit. The ceiling is derived as 1024 bytes
for the postcard-rpc host inbound transfer buffer, minus a 7-byte response
header, 1-byte postcard `Result` discriminant and 2-byte varint length prefix.
Each term is pinned by a test in `pico-de-gallo-internal`; #179 exports the
result to C as `GALLO_MAX_RESPONSE_PAYLOAD`, and a `_Static_assert` ties the
Zephyr constant to it.

This supersedes the earlier measurements: TX-only 1013 succeeded, 1014 was not
tested, full duplex succeeded at 512 and failed at 3072, and the range from 513
through 1013 was not tested duplex. Issue #158 measured the full-duplex
`spi/transfer` endpoint directly on board `5256657D8A5D7F03`: 1014 works and
1015 fails cleanly; #179 confirmed the boundary on board `49742081C885AC69`.
The old 512-byte documented-safe advice is therefore no longer needed. #158's
triage also could not reproduce the historical 1015-byte TX-only dispatcher
wedge on firmware `62dd64e710fd`: the call returned a clean error in 12 ms and
the board stayed responsive. That is a non-reproduction on one firmware build,
not proof that the earlier wedge never occurred; #157 and #178 landed between
the two runs. The protocol's 4096-byte constant remains a packet-buffer and
argument bound, not the usable response-payload ceiling.

The Zephyr I2C driver uses separate driver limits. Reads are limited to 1014
bytes: 1014 returned exactly the requested length, while the tested lengths at
and above 1015 returned `Postcard(DeserializeUnexpectedEnd)` rather than
wedging the dispatcher. Writes remain limited to 4096 bytes because write
requests at every length through 4096 crossed USB intact, were decoded, started
a bus transaction and returned `NoAcknowledge` cleanly. The probes used an
unpopulated address, so the address NACKed before any payload byte was clocked;
they verify request framing at 4096, not successful bus-level clocking of a
4096-byte payload. The wire format cannot represent a larger probe. No hang was
found at any tested length; that does not prove that no hang window exists. Only
the one-byte-write row of the write/read frontier was measured. Treating the
two limits as independent is an **inference from the request/response
mechanism**, not an observation of longer combined transfers.

Zephyr collapses a child's `spi-cs-setup-delay-ns` and `spi-cs-hold-delay-ns`
into one `DIV_ROUND_UP(MAX(setup_ns, hold_ns), 1000)` microsecond value and
applies it after the assert and before the deassert. Microsecond waits between
millisecond USB round trips cannot provide meaningful nanosecond timing.

Read-only and write-only transfers become **full-duplex** transfers of
`max(tx_len, rx_len)` bytes, with zero-filled TX or discarded RX respectively.

Declaring a pin in `cs-gpios` makes this driver the sole *driver path* for that
pin's mode; it is **not** an ownership reservation. Your application must give
SPI exclusive ownership of every declared chip-select pin, because a direct
GPIO consumer can reconfigure or drive it between SPI operations and nothing
detects it.

#### Initialization

The controller initializes at `CONFIG_SPI_PICO_DE_GALLO_INIT_PRIORITY`
(default 50), after the GPIO child (45) and the MFD parent
(`KERNEL_INIT_PRIORITY_DEFAULT`, currently 40). It configures
every declared chip-select pin as an **explicit output, inactive**, in
ascending array order — two round trips per pin.

Kconfig cannot check that arithmetic, so runtime readiness is authoritative: an
inverted priority makes the loop see an unready GPIO port and return `-ENODEV`
*before* configuring any pin, rather than actuating the wrong line.

There is no rollback on failure. If a pin fails, earlier entries are
acknowledged inactive, that entry's state is indeterminate, and later entries
were never issued; the device stays not-ready. `-EBUSY` means a firmware GPIO
event subscription owns the pin — reset it explicitly with
`gallo_system_reset_subscriptions()` after a strict open and reinitialize, or
power-cycle.

#### Holding chip select, and the fault latch

`SPI_HOLD_ON_CS` requires `SPI_LOCK_ON` and returns `-ENOTSUP` without it:
holding chip select while another configuration could select a second slave
would leave two peripherals selected at once. A successful hold commits the
received data and keeps the line asserted and the bus locked until
`spi_release()` is called with that same configuration. A thread or process
that never releases strands both the line and software ownership. A transceive
with a different configuration then blocks forever; there is no timeout and the
independently fed watchdog does not recover this ownership wait. HOLD alone is
rejected because releasing the controller while CS remained asserted would let
another configuration select a second peripheral, causing simultaneous
selection and MISO contention. On the documented loopback fixture, MOSI and
MISO are physically shorted, so that contention is not hypothetical.

Received data is committed only after the deassert that ends the transaction is
acknowledged, or immediately on a successful deliberate hold. A transfer that
succeeds but whose deassert fails returns the deassert errno and does **not**
commit RX; the peripheral may still be selected.

If a forced deassert returns an error, the driver cannot tell whether the line
went inactive, so the controller **latches**. Every later transceive returns
`-EHOSTDOWN` before issuing any configuration, chip-select edge or clocking,
because a previous peripheral may still be selected. Only a `spi_release()`
whose checked deassert succeeds clears it; a failed release still releases
software ownership so nothing wedges, but leaves the latch set so the exact
configuration can be retried. If release cannot clear it, terminate and
reinitialize, deassert the pin explicitly, or power-cycle.

If you would rather not declare a child node, build the `spi_config` yourself
and address the controller directly. Note that `.cs` must be populated — a
zeroed `.cs` means "no GPIO chip select", and this driver will then drive no
line at all:

```c
static const struct device *const bus = DEVICE_DT_GET(DT_NODELABEL(pdg_spi0));

static const struct spi_config cfg = {
	.frequency = 10000000,
	.operation = SPI_WORD_SET(8) | SPI_OP_MODE_MASTER | SPI_TRANSFER_MSB,
	.cs = SPI_CS_GPIOS_DT_SPEC_GET(DT_NODELABEL(my_device)),
};
```

The driver allocates flattened transfer buffers from the system heap. You do
**not** need to set `CONFIG_HEAP_MEM_POOL_SIZE`: enabling the driver
contributes `CONFIG_HEAP_MEM_POOL_ADD_SIZE_PDG_SPI` (8192 by default) and the
kernel sizes the pool automatically. Lower it if you know your transfers are
small.

### Selecting a specific board

Board selection lives on the `pdg0` parent, not on the controllers. With more
than one Pico de Gallo attached, pin each parent to a board with the optional
`serial-number` property:

```dts
&pdg0 {
	status = "okay";
	serial-number = "E6614C311B8C9E37";
};
```

Every controller under that parent inherits the selection and shares the one
USB connection, so I2C, UART, SPI, GPIO and PWM children on the same board work
without your code managing that. `serial-number` is **not** accepted on a controller node;
a leftover one fails devicetree processing with an undeclared-property error
naming the node and the binding.

If omitted, the first matching board is used, and the host API cannot report
which one it chose. An omitted serial number is therefore safe **only when
exactly one matching board is attached**. A genuine multi-board setup needs a
unique explicit `serial-number` on every enabled parent; the build-time check
rejects two enabled parents that both omit it, but it verifies presence, not
uniqueness, so two parents sharing one explicit value still silently alias to
one board.

---

## Driver limitations

These are enforced in the drivers and reported as errors, not silently ignored.

### GPIO

| Limitation | Result |
|---|---|
| Enabled GPIO child whose parent has no `serial-number` | **Build fails** with an explanatory assertion |
| `ngpios` outside 1..32 | **Build fails** with an explanatory assertion |
| `ngpios` not equal to the firmware-reported GPIO count | `-EINVAL` at init |
| Any call from interrupt context | `-EWOULDBLOCK` |
| `GPIO_DISCONNECTED` (neither input nor output) | `-ENOTSUP` |
| `GPIO_INPUT \| GPIO_OUTPUT` together | `-ENOTSUP` |
| Single-ended, open-source, open-drain | `-ENOTSUP` |
| Interrupt-mode flags, including `GPIO_INT_WAKEUP` | `-ENOTSUP` |
| Any flag bit outside the supported set | `-ENOTSUP` |
| Both pull-up and pull-down | `-EINVAL` |
| Both output init levels, or an init level without `GPIO_OUTPUT` | `-EINVAL` |
| Mask or pins outside the `ngpios`-derived port mask | `-EINVAL` |
| `gpio_pin_toggle()` / `gpio_port_toggle_bits()` | `-ENOTSUP` |
| Interrupt configure, callback management, pending interrupt | `-ENOSYS` |
| `gpio_pin_get_config()`, `gpio_port_get_direction()` | `-ENOSYS` |
| Configure/write pin owned by a live event subscription | `-EBUSY`; a read normalizes subscription `-EBUSY` to `-EIO` |
| Write pin recorded as an explicit input | `-EACCES` |
| Reading a pin configured as an explicit output | reports `0`; the read path treats its `-EACCES` as a zero bit |
| Transport failure | `-EIO` |

`GPIO_ACTIVE_LOW` is supported and handled by Zephyr's common GPIO layer.

### I2C

| Limitation | Result |
|---|---|
| 10-bit addressing | `-ENOTSUP` |
| Target/peripheral mode | `-ENOTSUP`; only `I2C_MODE_CONTROLLER` |
| Addresses above 7 bits | `-EINVAL` |
| `I2C_SPEED_HIGH` / `I2C_SPEED_ULTRA` | `-EINVAL`; use standard, fast, or fast-plus |
| A read that is not the last message of its `I2C_MSG_STOP`-delimited group | `-ENOTSUP` |
| More than one read in a group | `-ENOTSUP` |
| A write-then-read group whose read omits `I2C_MSG_RESTART` | `-ENOTSUP` |
| A final group with no `I2C_MSG_STOP` | `-ENOTSUP` |
| A `NULL` message buffer with a non-zero length | `-EINVAL` |
| A group carrying no data bytes in either direction (an address-only probe) | `-ENOTSUP`, unless `CONFIG_I2C_PICO_DE_GALLO_PROBE_WITH_READ` |
| A probe whose substituted read is NACKed, with that option set | `-ENXIO` |
| A group whose writes total over 4096 bytes | `-EMSGSIZE` |
| A group whose read exceeds 1014 bytes | `-EMSGSIZE` |
| Merge buffer allocation failure on a gather write | `-ENOMEM` |

A group is every message since the previous `I2C_MSG_STOP`, and each group
becomes exactly one bridge transaction. Three shapes are supported:

- **N writes** concatenate into a single write. This is what `i2c_burst_write()`
  and hand-rolled gather writes emit, and it reaches the bus as one START, one
  address phase, all the bytes, one STOP.
- **A single read**, which becomes a plain read.
- **N writes followed by one read**, which becomes a write-then-read with a
  repeated start.

A validated group is then reduced to the operation its data bytes actually
require, so a message carrying no bytes never reaches the bus. Empty writes are
dropped, and a terminating read of zero bytes is dropped rather than sent as an
empty read phase: `W(0) + R(2)` is a plain read, `W(2) + R(0)` is a plain write,
and `W(0) + W(3)` is a 3-byte write. An empty write consumes none of the
per-group size budget.

Only a group holding two or more non-empty writes allocates a merge buffer; see
`CONFIG_HEAP_MEM_POOL_ADD_SIZE_PDG_I2C`. Every other shape is sent straight from
the caller's buffers with no copy.

Validation is a complete pre-pass. A rejected transfer returns before the
controller lock is taken and before any USB call, so no partial bus traffic is
ever emitted.

These bounds and their evidence are described with the SPI measurements above.
In particular, 4096 is not the I2C write ceiling: it is the largest
wire-representable request and the largest request-framing value probed. The
unpopulated target NACKed the address before any payload byte was clocked.

#### Zero-length transfers and the address-only probe

Zephyr permits `msg.buf == NULL` whenever `msg.len == 0`, and both
`i2c_write(dev, NULL, 0, addr)` and `i2c_write_read(dev, addr, NULL, 0, rx, n)`
produce exactly that. A `NULL` buffer is therefore refused only when the message
claims to carry bytes. Relaxing that alone would accomplish nothing: the FFI
rejects a `NULL` pointer unconditionally, ahead of any length check, because
`slice::from_raw_parts(NULL, 0)` is undefined behaviour in Rust. It is the
reduction described above that keeps the pointer away from it.

What is left when a group carries no data bytes in either direction is an
address-only `START + ADDR + STOP` probe. The RP2040/RP2350 `DW_apb_i2c` block
drives the address phase only as a side effect of pushing bytes into
`IC_DATA_CMD`, so that transaction is physically unreachable — see
[rp-rs/rp-hal#678](https://github.com/rp-rs/rp-hal/issues/678) and
[embassy-rs/embassy#4474](https://github.com/embassy-rs/embassy/issues/4474).
It is a hardware limitation, not a policy choice. The driver refuses it with
`-ENOTSUP`, in the validation pre-pass, so a multi-group transfer containing one
is rejected before the controller lock is taken and before any earlier group has
reached the bus.

`CONFIG_I2C_PICO_DE_GALLO_PROBE_WITH_READ` (default `n`) substitutes a 1-byte
read to the same address instead: an ACK means the device is present, a NACK
surfaces as `-ENXIO`.

This matters for Zephyr's shell `i2c scan`, which probes each address with a
single zero-length write message. At the default it reports every address
absent — `i2c scan` prints `0 devices found` on a populated bus. With the option
set it produces a correct per-address answer, at one blocking USB round trip per
address, roughly 116 for the `0x04..0x77` range the shell scans.

Two caveats, which are why the option is off by default. A read probe is not
semantically identical to a write probe: a write-only device may acknowledge its
write address while NACKing its read address, so a scan performed this way can
under-report. That is the same known limitation the firmware's own `i2c/scan`
carries. And the substituted read consumes a byte, which can pop a FIFO or step
an EEPROM address pointer; Zephyr's own `i2c_shell.c` carries the same warning,
that scanning "can confuse your I2C bus, cause data loss, and is known to
corrupt the Atmel AT24RF08 EEPROM". A bus scan is a deliberate act, whereas a
driver silently turning every zero-length write into a read is not.

The supported way to scan through this bridge remains `gallo i2c scan`, or the
firmware's `i2c/scan` endpoint, which probes the whole bus in one round trip.

### UART

| Limitation | Result |
|---|---|
| Enabled UART whose parent is missing, disabled or not `odp,pico-de-gallo` | **Build fails** with an explanatory assertion |
| Enabled UART whose parent has no `serial-number` | **Build fails** with an explanatory assertion |
| Chosen as `zephyr,console` with `CONFIG_EARLY_CONSOLE=y` | **Build fails**; this `POST_KERNEL` device is not ready at the `PRE_KERNEL_1` hook |
| `uart_poll_in()` from ISR or pre-kernel context | `-1`; no lock or RPC |
| `uart_poll_out()` from ISR or pre-kernel context | silently drops and counts the byte; no lock, RPC or log |
| Implemented or explicit-stub integer driver callbacks from ISR / pre-kernel context | `-EWOULDBLOCK` / `-EAGAIN` respectively |
| Baud rate 0 | `-EINVAL` |
| 9 data bits | `-ENOTSUP`; use 5, 6, 7 or 8 |
| 0.5 or 1.5 stop bits | `-ENOTSUP`; use 1 or 2 |
| `UART_CFG_FLOW_CTRL_RTS_CTS` | `-ENOTSUP`; RTS/CTS pins are not routed |
| `UART_CFG_FLOW_CTRL_DTR_DSR` | `-ENOTSUP`; modem-control pins are not exposed |
| `UART_CFG_FLOW_CTRL_RS485` | `-ENOTSUP`; no driver-enable line is exposed |
| `poll_in`, `poll_out`, `err_check` | implemented polling slots |
| `configure`, `config_get` | implemented with `CONFIG_UART_USE_RUNTIME_CONFIGURE` |
| `poll_out_u16` with `CONFIG_UART_WIDE_DATA` | explicit void stub; silently drops and counts |
| `poll_in_u16` | NULL slot: `-ENOSYS` when wide data is enabled, `-ENOTSUP` when it is disabled |
| Async `tx`, `tx_abort`, `rx_enable`, `rx_buf_rsp`, `rx_disable` | explicit `-ENOTSUP` stubs when the global async API is enabled |
| Async wide `tx_u16`, `rx_enable_u16`, `rx_buf_rsp_u16` | explicit `-ENOTSUP` stubs when async and wide APIs are enabled |
| `callback_set` | NULL slot: `-ENOSYS` when the async API is enabled, `-ENOTSUP` when disabled |
| Integer FIFO/IRQ wrappers (`fifo_fill`, `fifo_read`, wide `fifo_fill_u16` / `fifo_read_u16`, `irq_tx_ready`, `irq_tx_complete`, `irq_rx_ready`, `irq_is_pending`, `irq_callback_set`) | NULL slots: `-ENOSYS` when interrupt-driven UART is enabled, `-ENOTSUP` when disabled |
| Void IRQ wrappers (`irq_tx_enable`, `irq_tx_disable`, `irq_rx_enable`, `irq_rx_disable`, `irq_err_enable`, `irq_err_disable`, `irq_update`) | NULL slots: silently no-op; they do **not** return `-ENOSYS` |
| `line_ctrl_set`, `line_ctrl_get`, `drv_cmd` | NULL slots: integer wrappers return `-ENOSYS` when enabled, `-ENOTSUP` when the corresponding global API is disabled |
| Confirmed transport failure (`-ECOMM` or `-ETIMEDOUT`) | ring discarded; permanent fail-fast with no reconnect or later RPC |
| Non-transport RX refill error | `uart_poll_in()` returns `-1`; next refill waits 10 ms |

Parity none, odd, even, mark and space are supported. `uart_err_check()` does
not expose framing, parity or overrun detail; see the UART section above for the
firmware limitation and private diagnostics. Unsupported async stubs are
side-effect-free, but on a failed-init device they report `-ENODEV` first; the
context errors in the table likewise take precedence.

### PWM

| Flag / feature | Result |
|---|---|
| Enabled controller whose parent is missing, disabled or not `odp,pico-de-gallo` | **Build fails** with an explanatory assertion |
| Enabled controller whose parent has no `serial-number` | **Build fails** with an explanatory assertion |
| Channel index above 3 | `-EINVAL`, from both `pwm_set_cycles()` and `pwm_get_cycles_per_sec()` |
| `PWM_POLARITY_INVERTED` | `-ENOTSUP`. Not emulated by inverting the duty cycle, which would change the idle level rather than the polarity |
| `pwm_capture_*` | `-ENOSYS` with `CONFIG_PWM_CAPTURE=y`; the functions do not exist without it. The firmware exposes no capture endpoint, so the API slots are left NULL |
| Phase-correct mode | unreachable. Zephyr has no corresponding concept, and in that mode the firmware's reported full-scale duty no longer tracks the period |
| Disabling a channel | not implemented. Disable acts on a whole slice and would stop the sibling channel; a zero pulse gives a constant-low output instead |
| Independent periods on channels 0+1, or on 2+3 | `-EINVAL`. Each pair shares one RP2350 slice, which has a single period |
| Period below 2 cycles | `-EINVAL`; the firmware requires `top >= 1` |
| Period above 16711680 cycles | `-ENOTSUP`. Would need a clock divider above 255, which panics the firmware — see [#192](https://github.com/OpenDevicePartnership/pico-de-gallo/issues/192) |
| Pulse longer than the period | `-EINVAL`, from Zephyr's own wrapper and independently from the driver's slot |
| Board that does not advertise `GALLO_CAP_PWM` | `-ENODEV` at init; a failed capability query instead returns its own mapped errno |
| Firmware reports a full-scale duty of zero | `-EIO`; every duty cycle would otherwise be a division by zero |
| Any call on a device whose initialization failed | `-ENODEV` |

There is no `set_cycles` fast path that skips the device: even an unchanged
period still reads the full-scale duty back and re-sends the compare value,
because the driver caches no device-side duty.

### SPI

| Limitation | Result |
|---|---|
| `CONFIG_SPI_ASYNC` or `CONFIG_SPI_RTIO` | **Build fails** with an explanatory assertion |
| Enabled controller without `cs-gpios` | **Devicetree error**; the property is required |
| A `cs-gpios` entry on a foreign, disabled, or cross-parent GPIO controller | **Build fails** with an assertion naming the array index |
| Enabled controller whose parent has no `serial-number` | **Build fails** with an explanatory assertion |
| Priority inversion (SPI initializes before its GPIO port) | `-ENODEV` at init, before any pin is configured |
| Peripheral mode | `-ENOTSUP`; only `SPI_OP_MODE_MASTER` |
| Word sizes other than 8-bit | `-ENOTSUP` |
| `SPI_TRANSFER_LSB`, `SPI_MODE_LOOP`, `SPI_HALF_DUPLEX`, `SPI_FRAME_FORMAT_TI` | `-ENOTSUP` |
| `SPI_CS_ACTIVE_HIGH` | `-ENOTSUP`; use `GPIO_ACTIVE_HIGH` in `cs-gpios` |
| `SPI_HOLD_ON_CS` without `SPI_LOCK_ON` | `-ENOTSUP` |
| Chip-select pin explicitly configured as an input | `-EACCES` |
| Chip-select pin under a live GPIO event subscription | `-EBUSY` |
| Transfers over 1014 bytes | `-EMSGSIZE` |
| Legacy firmware lacks a required SPI operation | `-ENOSYS` |
| Firmware SPI operation times out | `-ETIMEDOUT` |
| Controller latched by an unacknowledged chip-select deassert | `-EHOSTDOWN` until a successful `spi_release()` |

Every operation is a blocking USB round trip, so the asynchronous and RTIO
driver ops are deliberately not implemented. Zephyr's SPI subsystem dispatches
`transceive_async()` and `iodev_submit()` without a NULL check, so enabling
either option is refused at build time rather than crashing at runtime. Note
that `CONFIG_SPI_RTIO` is selected transitively by `CONFIG_SENSOR_ASYNC_API`
and by several in-tree SPI sensor drivers, so you can acquire it without asking
for it.

---

## Troubleshooting

**`Could not find a configuration file for package "Zephyr-sdk"`**
Set `ZEPHYR_TOOLCHAIN_VARIANT=host`. `native_sim` does not need the SDK.

**`Failed to find matching nusb device!` / `Returning -ENODEV`**
No board found. The `pdg0` parent reports this; its controllers then fail with
`Pico de Gallo parent ... is not ready`. Check the board is attached and that
you have permission to open it (on Linux, a udev rule or membership of the
right group). If several boards are attached, see *Selecting a specific
board* — the `serial-number` goes on `&pdg0`.

**Build fails with `does not implement iodev_submit()`**
Something enabled `CONFIG_SPI_RTIO`, very likely `CONFIG_SENSOR_ASYNC_API`.
Turn it off; this driver cannot support it. The same applies to
`CONFIG_SPI_ASYNC` and `transceive_async()`.

**`undefined reference to k_malloc`**
An older checkout of this module, before the SPI driver declared its heap
requirement. Update, or set `CONFIG_HEAP_MEM_POOL_SIZE=8192` as a stopgap.

**Build fails with `odp,pico-de-gallo-gpio parent must define serial-number`**
An enabled `pdg_gpio0` requires an explicit `serial-number` on `&pdg0`. See
*GPIO* above for why: GPIO drives physical pins, and an unpinned parent cannot
report which attached board it selected.

**`gpio_pin_toggle()` returns `-ENOTSUP`, or blinky does not work**
Expected. Toggle is unavailable on this controller; use `gpio_pin_set()` with
the level you want. Interrupt-driven GPIO consumers get `-ENOSYS`.

**`i2c scan` prints `--` for every address, or `0 devices found`**
Expected at the default configuration. The shell probes each address with a
zero-length write, which is an address-only transaction the RP2040/RP2350 I2C
block cannot emit, so the driver returns `-ENOTSUP` for every address. Set
`CONFIG_I2C_PICO_DE_GALLO_PROBE_WITH_READ=y` to substitute a 1-byte read per
address — read the caveats in *I2C* above first — or use `gallo i2c scan` on the
host, which scans the whole bus in one round trip.

**Devicetree errors about `pdg_i2c0` / `pdg_spi0`**
`-DSHIELD=pico_de_gallo` was not passed, so the nodes do not exist. It is
required on the first build of a clean tree.

**`'cs-gpios' is marked as required in 'properties:'`**
An enabled `pdg_spi0` has no `cs-gpios`. The property is required and there is
no native-CS fallback; add one entry per chip select. This is raised during
devicetree processing, so nothing is compiled.

**Build fails with `cs-gpios entry N must target an odp,pico-de-gallo-gpio
controller ...`**
The named entry points at a foreign GPIO controller, a disabled Pico de Gallo
GPIO sibling, or — the message ending *"under the same odp,pico-de-gallo
parent"* — a Pico de Gallo GPIO controller belonging to a **different board**.
The last one is the dangerous case: chip select would be driven on one board
while data was clocked on another. Also remember to set
`&pdg_gpio0 { status = "okay"; };`.

**Build fails with `odp,pico-de-gallo-spi parent must define serial-number`**
Same reason as the GPIO child above: SPI chip select actuates a physical pin,
so the parent must name the board.

**SPI returns `-EHOSTDOWN`**
The controller latched after a chip-select deassert that was not acknowledged,
so a previous peripheral may still be selected. Call `spi_release()` with the
retained configuration; only a release whose deassert succeeds clears it. If it
cannot be cleared, terminate the process, reinitialize and deassert the pin
explicitly, or power-cycle the board.

**SPI init fails with `-ENODEV` and a "not ready" chip-select message**
Initialization priority inversion. `CONFIG_SPI_PICO_DE_GALLO_INIT_PRIORITY`
must be greater than `CONFIG_GPIO_PICO_DE_GALLO_INIT_PRIORITY`, which must be
greater than `CONFIG_MFD_PICO_DE_GALLO_INIT_PRIORITY`. No pin was configured.

**SPI init fails with `-EBUSY` on a chip-select pin**
A firmware GPIO event subscription owns that pin — often orphaned by a host
process that died. Call `gallo_system_reset_subscriptions()` after a strict
open, then reinitialize, or power-cycle.

**The application builds but the device is never ready**
Check that `&pdg0` and every required controller node are `status = "okay"` in
your overlay. The parent and all five controllers ship disabled, and a controller
whose parent failed to open reports `Pico de Gallo parent ... is not ready`
rather than a connection error of its own.

If initialization appears idle, allow for the strict parent's 300-second
worst-case open timeout. Capture host `stderr` as well as the Zephyr log because
registry and FFI diagnostics may appear only there.

**An SPI call never returns, and later RPCs also stop responding**
A historical 1015-byte TX-only transfer reproduced a device-wide
firmware-dispatcher wedge. Issue #158 could not reproduce it on firmware
`62dd64e710fd`: the call returned a clean error in 12 ms and the board remained
responsive. That single-build non-reproduction does not prove the earlier wedge
never occurred. Two intervening changes supersede its recovery guidance: #157
added a watchdog supervisor that resets a genuinely wedged dispatcher in about
10.5 seconds, and #178 bounds every host RPC so a lost response becomes a clean
timeout. Issue #158 also made the Rust library, FFI, Python, MCP and `gallo` CLI
refuse over-ceiling payloads locally; Zephyr's 1014-byte check is no longer the
only host-side containment.

If older firmware or host software still wedges, the reproduced historical
recovery was USB re-enumeration; on Windows/WSL this used `usbipd detach`
followed by attach. That observation does not prove detach cancels the blocked
handler. On Linux/macOS unplug/reconnect or use USB unbind/rebind. Power-cycle
if re-enumeration is unavailable or ineffective. `system/reset-subscriptions`
cannot recover a currently blocked dispatcher because it cannot service the
request.

**Corrosion or crates.io is unreachable**
The FFI itself builds from this repository and needs no network. Corrosion is
still fetched from GitHub; point at a local checkout with
`-DFETCHCONTENT_SOURCE_DIR_CORROSION=/path/to/corrosion`.

---

## Notes

Applications are not limited to raw I2C and SPI calls. As `samples/i2c_bridge`
shows, higher-level subsystem APIs — sensor, LED, and others — work as long as
the underlying device sits on a bridged bus, because the bridge is an ordinary
Zephyr bus controller as far as the rest of the system is concerned.

Test coverage, Twister metadata, and CI for this module are tracked in
[#109](https://github.com/OpenDevicePartnership/pico-de-gallo/issues/109);
documentation parity with `book/` is tracked in
[#110](https://github.com/OpenDevicePartnership/pico-de-gallo/issues/110).

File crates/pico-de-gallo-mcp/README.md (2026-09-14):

# gallo-mcp

A [Model Context Protocol](https://modelcontextprotocol.io) (MCP) server that
exposes a [Pico de Gallo](https://github.com/OpenDevicePartnership/pico-de-gallo)
USB bridge to AI coding agents. It wraps
[`pico-de-gallo-lib`](https://crates.io/crates/pico-de-gallo-lib) and presents
one MCP tool per peripheral operation (I²C, SPI, UART, GPIO, PWM, ADC, 1-Wire)
over stdio, so an agent can probe and drive real hardware while writing an
embedded driver.

## Install

```bash
cargo install gallo-mcp
```

## Run

```bash
gallo-mcp [--serial-number <SN>]
```

The server holds no persistent connection to the board. Each tool call opens
the device, runs the operation, and releases it when the call completes, so
the board stays free for the `gallo` CLI or other host processes between
calls. Each call re-opens and re-validates the device, so there is a small
fixed per-call connection cost. The server starts even with no board
attached; tools begin working as soon as a Pico de Gallo is plugged in. Logs
go to stderr; stdout carries the MCP protocol. On each successful connection,
the default `info` filter logs the board serial, firmware version, and firmware
build identity. `RUST_LOG` overrides the filter when set.

The `status` response always includes a `build_id` key: it is `null` before a
board is reached and contains that image's build-time `git describe` identity
after a successful connection. `device_info` returns the same identity. It is
diagnostic only and never controls whether a tool call succeeds.

## Protocol revisions

`gallo-mcp` supports MCP `2024-11-05`, `2025-03-26`, `2025-06-18`,
`2025-11-25`, and `2026-07-28`, negotiating during `initialize`: it echoes the
revision the client requests when it is one of those, and otherwise falls back
to `2025-11-25`.

The tool surface does not vary by revision — the same tools, arguments,
annotations, and JSON payloads are served to every client. Only the envelope
differs: a session on `2026-07-28` receives the `resultType` discriminator and
`ttlMs`/`cacheScope` cache hints on results, and may start with a stateless
`server/discover` instead of `initialize`. Sessions on `2025-11-25` and older
keep the legacy wire shape unchanged.

## SPI chip-select preflight

`spi_batch` runs its steps in a fixed order: parse every operation
payload, connect exactly once, read the GPIO count from the `DeviceInfo`
that connection already validated, classify `cs`, then call the library
once. No second metadata query is issued.

Parsing precedes connecting on purpose. `connect` runs
`system_reset_subscriptions`, which tears down every GPIO subscription on
the board — including ones owned by other host processes — so a merely
malformed request must not reach it. A payload that fails to parse
returns `-32602` (invalid params) without opening the device at all.

Error codes stay disjoint:

- `-32602` — malformed payload, a `cs` at or beyond the reported GPIO
  count, or a device reporting zero GPIOs (its own distinct message).
  Nothing is transmitted and no pin is driven.
- `-32603` — the GPIO count could not be established: transport failure,
  a `device/info` timeout after 300 seconds, legacy firmware, or a schema
  mismatch. Never reported as an invalid argument.

## Choosing a board

Every tool that touches a device takes an optional `serial_number`, and every
device response is wrapped as `{ "serial_number": ..., "result": ... }`, naming
the board that served the call. (`list_devices` and `status` are not wrapped:
one opens no board, the other already reports a serial of its own.) With one
board attached you can omit the argument. With two or more, omitting it is an
error that lists the available serials rather than a silent guess:

```text
Multiple Pico de Gallo devices attached; `serial_number` is required.
Available: 5256657D8A5D7F03, 568E9AAEC72B0D49
```

`--serial-number` pins the server to one board, which then refuses any tool
call naming a different one — use it to scope an agent session to a single
board. A pinned server makes `serial_number` optional again however many
boards are attached. Call `list_devices` to see what is attached and whether a
serial is required. A pin that names no attached board is logged as a warning
at startup rather than refused, so that starting with no board attached keeps
working. That warning is on by default (on stderr, never on the JSON-RPC
stream); `RUST_LOG` still overrides verbosity when set.

Calls to different boards run concurrently; calls to the same board queue, so
a long `gpio_wait_*` holds only the board it addressed.

## UART configuration

`uart_set_config` replaces the complete UART configuration. It requires
`baud_rate` and accepts these optional string arguments:

| Argument | Accepted values | Default when omitted |
|---|---|---|
| `data_bits` | `"5"`, `"6"`, `"7"`, `"8"` | `"8"` |
| `parity` | `"none"`, `"odd"`, `"even"`, `"mark"`, `"space"` | `"none"` |
| `stop_bits` | `"1"`, `"2"` | `"1"` |
| `serial_number` | a board USB serial number | normal target-selection rules |

Omitting a framing field selects its 8N1 default and overwrites the previous
value; it is not a partial update. Repeat all framing fields when changing only
the baud rate. The result contains `baud_rate`, `data_bits`, `parity`, and
`stop_bits` inside the usual `{ "serial_number", "result" }` envelope.

`uart_get_config` returns the same structured fields and spellings, so its
result can be passed back to `uart_set_config`. These are firmware software-
shadow values from the last successful request, not a register read-back; the
reported baud is requested rather than achieved after divisor rounding.

Reconfiguration is not atomic at the UART pins: the device applies the divisor
before the framing and drains neither direction. Quiesce transmit and receive
traffic during the call.

## Use with an MCP client

Add it to your client's MCP configuration. For example, opencode
(`opencode.json`, safe to commit per-project):

```json
{
  "$schema": "https://opencode.ai/config.json",
  "mcp": {
    "pico-de-gallo": { "type": "local", "command": ["gallo-mcp"], "enabled": true }
  }
}
```

## Security

Tools that write to a bus or actuate pins are annotated `destructiveHint`;
read-only tools are annotated `readOnlyHint`. `gallo-mcp` does **not** gate
writes itself — approval is delegated to the MCP client. Configure your
client's permission system (e.g. opencode `permission`) to prompt before
destructive tool calls. Under a client with no permission system, an agent can
actuate hardware without confirmation.

See the [book chapter](https://balbi.sh/pico-de-gallo/crates/mcp.html)
for the full tool catalog and details.

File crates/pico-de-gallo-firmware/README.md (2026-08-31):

# Pico de Gallo Firmware

Embassy-rs firmware for the Raspberry Pi Pico 2 (RP2350) that turns it into
a USB bridge for I2C, SPI, and GPIO access.

## Building

```console
$ rustup target add thumbv8m.main-none-eabihf
```

For rev2 hardware (v1.1 and later) — this is the default:

```console
$ cargo build --release --manifest-path crates/pico-de-gallo-firmware/Cargo.toml --target thumbv8m.main-none-eabihf
```

For rev1 hardware (v1.0):

```console
$ cargo build --release --manifest-path crates/pico-de-gallo-firmware/Cargo.toml --target thumbv8m.main-none-eabihf --no-default-features --features hw-rev1
```

> **`hw-rev1` is deprecated.** It is no longer the default and must be
> requested explicitly. It stays fully supported and built in CI, and
> **will not be removed before 2031-09-01**. Enabling it prints a
> `cargo:warning` at build time and logs a `defmt::warn!` at every boot.
> On rev1 the UART, ADC, and 1-Wire endpoints return `Unsupported`,
> because those signals are not routed on the v1.0 landing board.

## Flashing

Convert the ELF to UF2 and copy to the Pico 2 in BOOTSEL mode:

```console
$ picotool uf2 convert crates/pico-de-gallo-firmware/target/thumbv8m.main-none-eabihf/release/pico-de-gallo-firmware -t elf firmware.uf2
$ picotool load firmware.uf2
```

Or simply drag `firmware.uf2` onto the `RP2350` USB mass storage drive.

## Peripheral Mapping

| Function | RP2350 Pins | Notes |
|---|---|---|
| I2C1 SDA | GPIO 2 | 7-bit addressing, async mode |
| I2C1 SCL | GPIO 3 | |
| SPI0 SCK | GPIO 6 | DMA-backed full-duplex |
| SPI0 TX  | GPIO 7 | |
| SPI0 RX  | GPIO 4 | |
| GPIO 0–3 | GPIO 8–11 | Input/output/edge-wait |
| PWM 0–3  | GPIO 12–15  | PWM slices 6–7 |
| USB | Native USB  | postcard-rpc transport |

## License

Licensed under the terms of the [MIT license](http://opensource.org/licenses/MIT).

## Contribution

Any contribution intentionally submitted for inclusion in the work by
you shall be licensed under the terms of the same MIT license, without
any additional terms or conditions.

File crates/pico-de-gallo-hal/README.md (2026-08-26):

# Pico de Gallo HAL




[embedded-hal](https://crates.io/crates/embedded-hal) and
[embedded-hal-async](https://crates.io/crates/embedded-hal-async)
implementation backed by a [Pico de Gallo](https://github.com/OpenDevicePartnership/pico-de-gallo)
USB bridge.

Run embedded Rust drivers on your host machine by forwarding I²C, SPI,
GPIO, and delay operations to real hardware via USB.

## Quick Start

```rust
use pico_de_gallo_hal::Hal;
use embedded_hal::i2c::I2c;

let hal = Hal::new();
let mut i2c = hal.i2c();

let mut buf = [0u8; 2];
i2c.write_read(0x48, &[0x00], &mut buf).unwrap();
```

Check out the
[examples](https://github.com/OpenDevicePartnership/pico-de-gallo/tree/main/crates/pico-de-gallo-hal/examples)
for more usage patterns.

## Implemented Traits

| Peripheral | Blocking | Async |
|---|---|---|
| GPIO | `OutputPin`, `InputPin`, `StatefulOutputPin` | `Wait` |
| I²C | `I2c` | `I2c` |
| SPI | `SpiBus`, `SpiDevice` | `SpiBus`, `SpiDevice` |
| UART | `embedded_io::Read`, `embedded_io::Write` | `embedded_io_async::Read`, `embedded_io_async::Write` |
| Delay | `DelayNs` | `DelayNs` |

`SpiDevice` manages chip-select (CS) automatically via a GPIO pin.
Use `hal.spi_device(cs_pin)` to create one. It returns
`Result<SpiDev, SpiHalError>` after validating the pin against the
device-reported GPIO count. For raw bus access without CS management,
use `hal.spi()`.

## Feature Flags

`embedded-io` 0.6 and 0.7 have separate feature flags. Enable either
version on its own, or both to support drivers targeting either major.

| Feature | Default | `hal.uart()` implements |
|---|---|---|
| `embedded-io-07` | no | `embedded-io` 0.7 + `embedded-io-async` 0.7 traits |
| `embedded-io-06` | yes | `embedded-io` 0.6 + `embedded-io-async` 0.6 traits |

```toml
# 0.6 only (default)
pico-de-gallo-hal = "0.7"

# 0.7 only
pico-de-gallo-hal = { version = "0.7", default-features = false, features = ["embedded-io-07"] }

# both majors
pico-de-gallo-hal = { version = "0.7", features = ["embedded-io-07"] }
```

Turning both off drops the `embedded-io` dependency.

# License

Licensed under the terms of the [MIT license](http://opensource.org/licenses/MIT).

# Contribution

Any contribution intentionally submitted for inclusion in the work by
you shall be licensed under the terms of the same MIT license, without
any additional terms or conditions.

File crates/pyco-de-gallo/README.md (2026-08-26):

# pyco-de-gallo

Python bindings for [Pico de Gallo](https://github.com/OpenDevicePartnership/pico-de-gallo),
a USB-attached protocol bridge built on the
[Raspberry Pi Pico 2](https://www.raspberrypi.com/products/raspberry-pi-pico-2/)
(RP2350). Talk **I²C, SPI, UART, GPIO, PWM, ADC, and 1-Wire** straight from
Python — no cross-compiling, no flashing on every change. Develop and test
your embedded drivers on your laptop and let the Pico do the wiggling.

The native extension wraps the async Rust host library (`pico-de-gallo-lib`)
with [PyO3](https://pyo3.rs). Every method is **synchronous** from Python's
point of view; the async USB I/O is driven by a Tokio runtime owned by each
device handle, and the GIL is released for the duration of each round-trip so
your other Python threads keep running.

## Requirements

`pip install` gives you the host-side library. To do anything useful you also
need the hardware: a Raspberry Pi Pico 2 (or a Pico de Gallo landing board)
running the [Pico de Gallo firmware](https://github.com/OpenDevicePartnership/pico-de-gallo).

- **Python:** CPython 3.8+ (and PyPy). Prebuilt wheels are published for
  CPython 3.8–3.14.
- **Platforms:** Linux (x86_64 / aarch64, manylinux + musllinux),
  Windows (x64 / x86), macOS (Apple silicon).

## Installation

```sh
pip install pyco-de-gallo
```

The Python import name is `pyco_de_gallo` (underscores), while the
distribution name on PyPI is `pyco-de-gallo` (hyphens).

## Quick start

```python
import pyco_de_gallo as gallo

# Connect to the first attached board and verify the firmware is
# wire-compatible with this library. Raises RuntimeError on mismatch.
dev = gallo.open_strict()

v = dev.version()
print(f"Firmware {v.major}.{v.minor}.{v.patch}")

# I²C: switch to 400 kHz, then write a register pointer and read it back.
dev.i2c_set_config(gallo.I2cFrequency.Fast)
data = dev.i2c_write_read(0x50, [0x00], 16)   # e.g. read 16 bytes from an EEPROM
print(list(data))
```

If several boards are connected, pick one deterministically by serial number:

```python
import pyco_de_gallo as gallo

for d in gallo.list_devices():
    print(d.serial_number, d.manufacturer, d.product)

dev = gallo.open_strict_with_serial_number("E6625C087B...")
```

> `open()` / `open_with_serial_number()` are the lazy variants: they connect
> but only surface failures on the first RPC call. Prefer the `*_strict`
> variants in real code — they fail fast with a clear exception if the device
> is unreachable or the firmware schema doesn't match.

## Peripherals

| Bus | Highlights |
|---|---|
| I²C | `i2c_read` / `i2c_write` / `i2c_write_read`, `i2c_scan`, `i2c_batch`, 100 kHz–1 MHz |
| SPI | `spi_read` / `spi_write` / `spi_transfer`, `spi_batch` under chip-select, configurable phase/polarity |
| UART | `uart_read` (with timeout) / `uart_write` / `uart_flush`, configurable baud rate |
| GPIO | read/write, blocking edge waits (with optional timeout), and push-based edge events |
| PWM | per-channel duty cycle, frequency, phase-correct, enable/disable |
| ADC | single-shot 12-bit reads on 4 channels |
| 1-Wire | reset/presence, read/write, strong-pullup, and ROM search |

> Some peripherals (ADC, UART, 1-Wire) require **hw-rev2** firmware, and not
> every signal is broken out on the V1 landing board. See the firmware and
> hardware docs for the routing details.

### Blink an LED (GPIO)

```python
import time
import pyco_de_gallo as gallo

dev = gallo.open_strict()
dev.gpio_set_config(0, gallo.GpioDirection.Output, gallo.GpioPull.Disabled)

while True:
    dev.gpio_put(0, True)
    time.sleep(0.5)
    dev.gpio_put(0, False)
    time.sleep(0.5)
```

### React to GPIO edges (push events)

```python
import pyco_de_gallo as gallo

dev = gallo.open_strict()

# The subscription must be live before the firmware will buffer events.
with dev.subscribe_gpio_events() as events:
    dev.gpio_subscribe(0, gallo.GpioEdge.Falling)
    for event in events:
        print(event.pin, event.edge, event.state, event.timestamp_us)
```

### Scan the I²C bus

```python
import pyco_de_gallo as gallo

dev = gallo.open_strict()
dev.i2c_set_config(gallo.I2cFrequency.Standard)

for addr in dev.i2c_scan(include_reserved=False):
    print(f"0x{addr:02x}")
```

## Error handling

Failures from the underlying transport and firmware are raised as Python
`RuntimeError` exceptions with a descriptive message (for example, an I²C
NACK, a GPIO timeout, or a firmware schema mismatch).

## More examples

Runnable scripts for every peripheral — including a live TMP108 temperature
graph, a PWM sine-wave fade, a SPI loopback test, and a 1-Wire ROM search —
live in the
[`examples/`](https://github.com/OpenDevicePartnership/pico-de-gallo/tree/main/crates/pyco-de-gallo/examples)
directory.

## Documentation

- Project book: <https://balbi.sh/pico-de-gallo/>
- Source and issues: <https://github.com/OpenDevicePartnership/pico-de-gallo>

## License

MIT

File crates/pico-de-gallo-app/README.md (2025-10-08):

# Gallo



Batch mode application to communicate with a *Pico de Gallo* device.

# Usage

`gallo` is built with [clap](https://crates.io/crates/clap),
therefore, the built-in help is as useful as possible.

```console
$ gallo help
Access I2C/SPI devices through Pico De Gallo

Usage: gallo.exe [OPTIONS] [COMMAND]

Commands:
  version     Get firmware version
  i2c         I2C access methods
  spi         SPI access methods
  set-config  Set bus parameters for I2C and SPI
  help        Print this message or the help of the given subcommand(s)

Options:
  -s, --serial-number <SERIAL_NUMBER>
  -h, --help                           Print help
  -V, --version                        Print version
```

# License

Licensed under the terms of the MIT license
(http://opensource.org/licenses/MIT).

# Contribution

Any contribution intentionally submitted for inclusion in the work by
you shall be licensed under the terms of the same MIT license, without
any additional terms or conditions.

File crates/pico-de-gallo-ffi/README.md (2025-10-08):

# Pico de Gallo FFI



C FFI for Pico de Gallo Lib.

# License

Licensed under the terms of the MIT license
(http://opensource.org/licenses/MIT).

# Contribution

Any contribution intentionally submitted for inclusion in the work by
you shall be licensed under the terms of the same MIT license, without
any additional terms or conditions.

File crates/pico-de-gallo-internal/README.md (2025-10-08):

# Pico de Gallo Internal



Internal library crate shared between Firmware and Library portions of
the pico-de-gallo project. Do not use directly.

# License

Licensed under the terms of the [MIT license](http://opensource.org/licenses/MIT).

# Contribution

Any contribution intentionally submitted for inclusion in the work by
you shall be licensed under the terms of the same MIT license, without
any additional terms or conditions.

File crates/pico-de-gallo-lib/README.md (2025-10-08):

# Pico de Gallo Lib



A library crate used to communicate with a Pico de Gallo device. The
library requires the `tokio` runtime.

[Examples](https://github.com/OpenDevicePartnership/pico-de-gallo/tree/main/crates/pico-de-gallo-lib/examples)
exist to help you understand how to work with this library.

# License

Licensed under the terms of the [MIT license](http://opensource.org/licenses/MIT).

# Contribution

Any contribution intentionally submitted for inclusion in the work by
you shall be licensed under the terms of the same MIT license, without
any additional terms or conditions.

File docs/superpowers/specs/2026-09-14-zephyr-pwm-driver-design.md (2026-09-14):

# Zephyr PWM driver for Pico de Gallo — design

Date: 2026-09-14
Issue: [#155](https://github.com/OpenDevicePartnership/pico-de-gallo/issues/155)
Related: [#192](https://github.com/OpenDevicePartnership/pico-de-gallo/issues/192) (firmware divider panic, filed from this work)

## 1. Goal

Add a Zephyr `pwm` driver as a child of the `odp,pico-de-gallo` MFD parent,
implementing `pwm_set_cycles()` and `pwm_get_cycles_per_sec()` on top of the
existing C FFI (`gallo_pwm_*`).

The hard part is not the plumbing. It is that Zephyr and Pico de Gallo model
PWM differently, and the mapping between them is lossy in ways that are easy
to get wrong silently:

- Zephyr expresses period and pulse in **clock cycles**, against a
  cycles-per-second the driver declares.
- Pico de Gallo expresses configuration as a **frequency** (`pwm/set-config`)
  plus a **raw compare value** (`pwm/set-duty-cycle`), whose usable range is
  the `max_duty` reported by `pwm/get-duty-cycle`.

## 2. Corrections to the issue's premises

Two statements in #155 are wrong and were verified against the source before
this design was settled.

**PWM is not `hw-rev2`-gated.** `crates/pico-de-gallo-firmware/src/handlers/info.rs:30-40`
sets `Capabilities::PWM` on both revisions, and no PWM code path carries a
`#[cfg(feature = "hw-rev2")]` — unlike `adc`, `onewire`, and `uart`, whose
`Context` fields are genuinely gated. The driver still probes the capability
bit, because that is the correct contract and costs little, but the gate will
never fire on a shipped image. Relatedly, `hw-rev2` is the default feature
today (`crates/pico-de-gallo-firmware/Cargo.toml:14`), not `hw-rev1` as the
issue states.

**The firmware PWM code is not in `main.rs`.** It is in
`crates/pico-de-gallo-firmware/src/handlers/pwm.rs`.

## 3. Facts the design depends on

Established by reading the firmware, the wire crate, and embassy-rp 0.10.0.

- `SYS_CLK_HZ = 150_000_000`, `crates/pico-de-gallo-firmware/src/context.rs:43`.
  It is `pub(crate)`: not on the wire, not in `pico_de_gallo.h`.
- Channels 0–3 map to GPIO12–15. Channels 0 and 1 share RP2350 slice 6;
  channels 2 and 3 share slice 7. `pwm/enable` and `pwm/disable` act on the
  **whole slice**.
- `max_duty == top + 1`, not `top`. The doc comment on
  `PwmDutyCycleInfo::max_duty` in `pico-de-gallo-internal` says `top` and is
  wrong; `pico-de-gallo-lib` says `top + 1` and is right.
- Legal compare range is `0..=top+1`, i.e. `0..=max_duty`. A compare of 0 is
  always-low; `top + 1` is always-high. An over-range duty is silently clamped
  by the firmware, never rejected — `PwmError::InvalidDutyCycle` is dead on
  the wire.
- `pwm/set-config` rescales both channels' compares proportionally with
  **truncating** integer division, so duty ratios drift downward on every
  reconfiguration.
- Boot default is `enable = true`, `divider = 1`, `top = 0xFFFF`, compares 0 —
  a running ~2288.8 Hz carrier at 0% duty.
- In phase-correct mode the period is `2 × top` counts while `max_duty` still
  reports `top + 1`.
- Dividers above 255.9375 panic inside embassy-rp (`src/pwm.rs:250-253`),
  while the firmware's search runs to 4095. This is #192.
- All nine PWM `Status` codes are already mapped in
  `zephyr/drivers/common/common.c`. That file needs no change.

## 4. Cycle domain

`pwm_get_cycles_per_sec()` returns a hardcoded **150 000 000**, defined in
`pdg_pwm_bottom.h` with a comment naming `firmware/src/context.rs:43` as the
source of truth.

The value reported is the PWM **source clock**, not the counter rate. This is
the decision the rest of the design rests on. The counter rate is
`150e6 / divider`, which changes with every frequency change and can differ
between the two slices — so it cannot serve as the stable per-device constant
Zephyr's API requires. Reporting the source clock instead makes `period_cycles`
a divider-independent quantity, and the divider then never needs to be known
by the driver at all. That matters because the divider is not on the wire.

Hardcoding was chosen over probing the value at init. Probing is possible —
configuring a channel to 10 kHz yields `divider == 1` exactly, making
`frequency_hz × max_duty` an exact reading of the source clock — but it costs
two RPCs and reconfigures a slice as an init side effect. The coupling to
`context.rs` is accepted and documented instead.
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

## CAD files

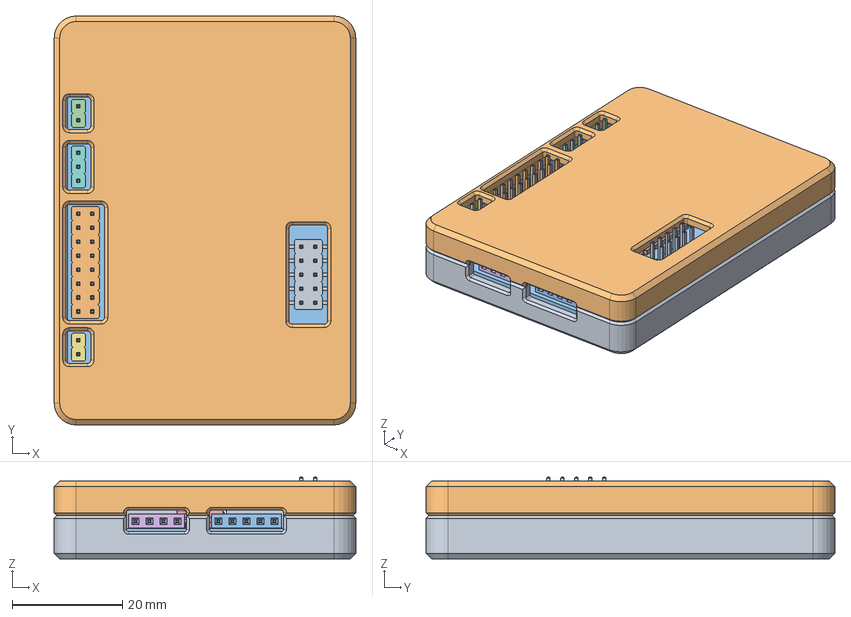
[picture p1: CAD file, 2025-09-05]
case/Case.FCStd
54.8 x 74.3 x 14.9 mm
Lid
PinSocket_1x05_P2.54mm_Horizontal
PinHeader_1x02_P2.54mm_Vertical
RaspberryPi_Pico_Module_KiCad
PinSocket_1x04_P2.54mm_Horizontal
PinHeader_1x02_P2.54mm_Vertical001
PinHeader_1x03_P2.54mm_Vertical
PinHeader_2x05_P2.54mm_Vertical_SMD
PinHeader_2x08_P2.54mm_Vertical
pico-de-gallo_PCB

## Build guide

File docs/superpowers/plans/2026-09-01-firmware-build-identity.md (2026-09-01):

# Firmware Build Identity Implementation Plan

> **For agentic workers:** REQUIRED SUB-SKILL: Use superpowers:subagent-driven-development (recommended) or superpowers:executing-plans to implement this plan task-by-task. Steps use checkbox (`- [ ]`) syntax for tracking.

**Goal:** Add a `build_id` field to `device/info` so a host can tell two firmware builds apart when they report the same schema version.

**Architecture:** The firmware `build.rs` runs `git describe --always --dirty --tags --match firmware-v*` on every build and emits a `BUILD_ID` const. The `device/info` handler returns it as a `heapless::String<64>` appended to the end of the `DeviceInfo` wire struct. Every host surface (lib, CLI, MCP, FFI, Python) then exposes it as informational data — it is never a compatibility gate.

**Tech Stack:** Rust 2024, `postcard` / `postcard-rpc` 0.12 / `postcard-schema` 0.2.5, `heapless` 0.9, `embassy` (no_std RP2350), `tabled` 0.21, PyO3, cbindgen.

**Design doc:** `docs/superpowers/specs/2026-09-01-firmware-build-identity-design.md`

---

## Ground rules for every task

Read these once before Task 1. They are repo policy from `AGENTS.md`, and violating them fails CI.

1. **Every commit must build cleanly on its own** (§4 rule 9). That is why Task 2 is large: appending a field to `DeviceInfo` breaks every construction site at once, so they are fixed in the same commit.
2. **Never bump `[package].version`** anywhere in this plan (§4 rule 12). No exceptions.
3. **LF line endings** on every file (§3).
4. **Firmware logs with `defmt` only** — no `println!`, no `log` (§4 rule 5).
5. **Commit trailers** on every commit:
   ```
   Assisted-by: OpenCode:claude-opus-5
   Co-authored-by: Copilot <223556219+Copilot@users.noreply.github.com>
   ```
   Never `Signed-off-by:` (§4 rule 7).
6. **Two Cargo workspaces.** Host commands run from the repo root. Firmware commands run from `crates/pico-de-gallo-firmware/` and need `--target thumbv8m.main-none-eabihf`.
7. **`pico-de-gallo-internal` tests need `use-std`** or must be run from the workspace root, or the `vec!` macro fails under `no_std` (§13.14).

---

## File Structure

| File | Responsibility | Task |
|---|---|---|
| `crates/pico-de-gallo-firmware/build.rs` | Run `git describe`, emit `BUILD_ID`, force unconditional re-run | 1 |
| `crates/pico-de-gallo-firmware/src/main.rs` | Boot-time `defmt` log of `BUILD_ID`; compile-time length assert | 1, 2 |
| `crates/pico-de-gallo-internal/Cargo.toml` | `heapless` dep, `postcard-schema` feature | 2 |
| `crates/pico-de-gallo-internal/src/lib.rs` | `BUILD_ID_CAPACITY`, the `build_id` field, the `build_id()` accessor, freeze-marker hygiene | 2 |
| `crates/pico-de-gallo-firmware/src/handlers/info.rs` | Populate `build_id` in the handler | 2 |
| `crates/pico-de-gallo-lib/src/lib.rs` | Test fixtures; `validate()` doc; the "never a gate" regression test | 2, 3 |
| `crates/pico-de-gallo-app/src/lib.rs` | `render_device_info` (pure, testable) + `version` printing it | 4 |
| `crates/pico-de-gallo-mcp/src/device.rs` | `StatusResult.build_id`; `fill_status_from_device` extraction | 5 |
| `crates/pico-de-gallo-mcp/src/lib.rs` | Connect-time `tracing` line | 5 |
| `crates/pico-de-gallo-mcp/src/main.rs` | Default `EnvFilter` raised to `info` so that line is emitted | 5 |
| `crates/pico-de-gallo-ffi/src/lib.rs` | `GalloDeviceInfo.build_id` as `char[65]` | 6 |
| `crates/pyco-de-gallo/src/lib.rs` | Python `DeviceInfo.build_id` | 7 |
| `book/src/**`, `crates/*/CHANGELOG.md`, `AGENTS.md` | Documentation parity (§15.1) | 8 |

---

## Task 1: Firmware `build.rs` emits `BUILD_ID`

This lands first and alone because it must not create dead code: the boot log in
`main.rs` consumes `BUILD_ID` immediately, so `clippy -D warnings` stays clean.

**Files:**
- Modify: `crates/pico-de-gallo-firmware/build.rs`
- Modify: `crates/pico-de-gallo-firmware/src/main.rs`

- [ ] **Step 1: Confirm the git incantation on this machine**

Run:
```bash
cd /home/balbi/workspace/pico-de-gallo
git describe --always --dirty --tags --match 'firmware-v*'
```
Expected: something shaped like `firmware-v0.11.0-27-g8ddb1da5a681` (the commit
count will differ). If it prints an `application-v*` string, the `--match` was
dropped; if it prints `firmware-v0.10.0-3xx-g...`, the `--tags` was dropped.

- [ ] **Step 2: Add the build-ID generation to `build.rs`**

In `crates/pico-de-gallo-firmware/build.rs`, add `use std::process::Command;` to
the imports at the top (joining `use std::env;`, `use std::fs::File;`,
`use std::io::Write;`, `use std::path::PathBuf;`).

Then add this function below `fn main()`:

```rust
/// Describe the current firmware build from git.
///
/// Every flag is load-bearing, and each has a *silent* failure mode:
///
/// * `--tags` — the `firmware-v*` tags are a MIX of annotated and lightweight.
///   Without this, `git describe` considers only annotated tags and resolves
///   hundreds of commits too far back (measured: `firmware-v0.10.0-302-g...`).
/// * `--match firmware-v*` — without it, describe picks the nearest tag in ANY
///   namespace (measured: `application-v0.9.0-25-g...`).
/// * `--always` — falls back to a bare hash instead of failing when no matching
///   tag is reachable, e.g. in a shallow CI clone.
/// * `--dirty` — marks a locally modified tree. This is the single most
///   valuable part of the field for a bisecting developer.
///
/// No shell is involved: the arguments are separate argv entries, so
/// `firmware-v*` is passed through literally and is never glob-expanded.
///
/// Returns `"unknown"` when git is unavailable, exits non-zero, or there is no
/// repository. The build always succeeds; a source tarball must still build.
fn build_id() -> String {
    let output = Command::new("git")
        .args([
            "describe",
            "--always",
            "--dirty",
            "--tags",
            "--match",
            "firmware-v*",
        ])
        .current_dir(env!("CARGO_MANIFEST_DIR"))
        .output();

    let described = match output {
        Ok(o) if o.status.success() => String::from_utf8_lossy(&o.stdout).trim().to_string(),
        _ => {
            println!(
                "cargo:warning=`git describe` unavailable; \
                 device/info will report build_id=\"unknown\""
            );
            return "unknown".to_string();
        }
    };

    if described.is_empty() {
        return "unknown".to_string();
    }

    // Truncate on a char boundary. git describe output is ASCII in practice,
    // but a tag name may legally carry UTF-8 and a byte-index slice would
    // panic mid-codepoint. Keep this in sync with
    // `pico_de_gallo_internal::BUILD_ID_CAPACITY`.
    const BUILD_ID_CAPACITY: usize = 64;
    if described.len() <= BUILD_ID_CAPACITY {
        described
    } else {
        let mut end = BUILD_ID_CAPACITY;
        while !described.is_char_boundary(end) {
            end -= 1;
        }
        described[..end].to_string()
    }
}
```

- [ ] **Step 3: Emit `BUILD_ID` into the generated `version.rs`**

In `crates/pico-de-gallo-firmware/build.rs`, replace the `File::create(out.join("version.rs"))` block (currently lines 26-39) with:

```rust
    let build_id = build_id();

    // `{:?}` on a &str emits a properly escaped Rust string literal, quotes
    // included. Git refnames forbid backslash but permit `"`, so a tag like
    // `firmware-v1.0"x` would otherwise emit a syntax error.
    File::create(out.join("version.rs"))
        .unwrap()
        .write_all(
            format!(
                r##"
pub(crate) const VERSION_MAJOR: u16 = {major};
pub(crate) const VERSION_MINOR: u16 = {minor};
pub(crate) const VERSION_PATCH: u32 = {patch};

/// Firmware build identity from `git describe`, or `"unknown"`.
pub(crate) const BUILD_ID: &str = {build_id:?};
"##
            )
            .as_bytes(),
        )
        .unwrap();
```

Note this switches the `format!` from positional to inline captured
identifiers, matching the style already used in
`crates/pico-de-gallo-internal/build.rs`.

- [ ] **Step 4: Force `build.rs` to re-run on every build**

In `crates/pico-de-gallo-firmware/build.rs`, replace the single line
`println!("cargo:rerun-if-changed=memory.x");` (currently line 41) with:

```rust
    println!("cargo:rerun-if-changed=memory.x");

    // Force this build script to re-run on EVERY build. Cargo treats a
    // nonexistent path as always-changed.
    //
    // This is deliberate and load-bearing. `rerun-if-changed=memory.x` above
    // NARROWS re-runs to that one file, so without this line the embedded
    // BUILD_ID goes stale across incremental builds: after a commit, or after
    // editing a handler, cargo rebuilds the crate but does not re-run this
    // script, and the firmware keeps reporting the previous commit with no
    // `-dirty` marker. A stale build ID is worse than none — it would CONFIRM
    // a wrong conclusion, which is exactly the misidentification this field
    // exists to prevent (issue #159; AGENTS.md §13.17, 2026-08-26).
    //
    // Cost is one `git describe` (~5 ms) per build. Do not "optimise" it away.
    // The path is resolved relative to the package root and MUST NOT exist.
    println!("cargo:rerun-if-changed=.pdg-always-rerun");
```

- [ ] **Step 5: Log the build ID at boot**

In `crates/pico-de-gallo-firmware/src/main.rs`, find the `hw-rev1` deprecation
warning inside `main()`. Search for it:

```bash
cd /home/balbi/workspace/pico-de-gallo
rg -n 'hw-rev1' crates/pico-de-gallo-firmware/src/main.rs
```

Immediately **before** that `#[cfg(feature = "hw-rev1")]` warn block, add:

```rust
    // Logged unconditionally at boot so an RTT capture records exactly which
    // image is running, independent of any host-side query.
    defmt::info!("build {}", BUILD_ID);
```

`BUILD_ID` is already in scope via the existing
`include!(concat!(env!("OUT_DIR"), "/version.rs"));` at `main.rs:122`.

- [ ] **Step 6: Build the firmware and verify it compiles**

Run:
```bash
cd /home/balbi/workspace/pico-de-gallo/crates/pico-de-gallo-firmware
cargo build --release --locked --target thumbv8m.main-none-eabihf
```
Expected: PASS, no warnings about unused `BUILD_ID`.

- [ ] **Step 7: Verify the generated constant actually contains the tag**

Run:
```bash
cd /home/balbi/workspace/pico-de-gallo/crates/pico-de-gallo-firmware
grep -rh 'BUILD_ID' target/thumbv8m.main-none-eabihf/release/build/*/out/version.rs
```
Expected: a line like
`pub(crate) const BUILD_ID: &str = "firmware-v0.11.0-27-g8ddb1da5a681";`

It must start with `firmware-v` (not `application-v`), and the commit count
must be small (tens, not hundreds).

- [ ] **Step 8: Verify the always-rerun trigger works**

Run:
```bash
cd /home/balbi/workspace/pico-de-gallo/crates/pico-de-gallo-firmware
touch /tmp/pdg-dirty-probe
cargo build --release --locked --target thumbv8m.main-none-eabihf 2>&1 | tail -3
grep -rh 'BUILD_ID' target/thumbv8m.main-none-eabihf/release/build/*/out/version.rs
```
Expected: the build re-runs the script (the `out/version.rs` timestamp updates)
rather than being fully cached. Confirm with:
```bash
stat -c '%y' crates/pico-de-gallo-firmware/target/thumbv8m.main-none-eabihf/release/build/*/out/version.rs
```
Expected: a timestamp from the run you just did.

- [ ] **Step 9: Lint the firmware**

Run:
```bash
cd /home/balbi/workspace/pico-de-gallo/crates/pico-de-gallo-firmware
cargo fmt --check
cargo clippy --target thumbv8m.main-none-eabihf -- -D warnings
```
Expected: both PASS.

- [ ] **Step 10: Commit**

```bash
cd /home/balbi/workspace/pico-de-gallo
git add crates/pico-de-gallo-firmware/build.rs crates/pico-de-gallo-firmware/src/main.rs
git commit -F - <<'EOF'
feat(firmware): Derive a build identity from git describe

`validate()` gates on the schema version, which tracks type changes
rather than behaviour changes, so two builds can report the same
version and still frame the bus differently. Generate a build identity
so the running image can be named.

`build.rs` now runs `git describe --always --dirty --tags --match
firmware-v*` and emits `BUILD_ID`, which `main()` logs at boot. Every
flag is load-bearing and commented as such: without `--tags` describe
sees only annotated tags and resolves 302 commits too far back, since
the `firmware-v*` tags are a mix of annotated and lightweight; without
`--match` it returns an `application-v*` description.

Force the script to re-run on every build. The pre-existing
`rerun-if-changed=memory.x` narrows re-runs to one file, so the
embedded identity would go stale across incremental builds and report
a clean tree for a dirty one. A stale identity is worse than none
because it confirms a wrong conclusion.

Fall back to "unknown" when git is unavailable so a source tarball
still builds, and truncate on a char boundary at 64 bytes.

Refs: #159

Assisted-by: OpenCode:claude-opus-5
Co-authored-by: Copilot <223556219+Copilot@users.noreply.github.com>
EOF
```

---

## Task 2: Append `build_id` to the `DeviceInfo` wire type

This is the largest commit by necessity: appending a field breaks every
construction site simultaneously, and AGENTS.md §4 rule 9 requires each commit to
build cleanly on its own.

**Files:**
- Modify: `crates/pico-de-gallo-internal/Cargo.toml`
- Modify: `crates/pico-de-gallo-internal/src/lib.rs`
- Modify: `crates/pico-de-gallo-firmware/Cargo.toml` (lockfile only — see Step 9)
- Modify: `crates/pico-de-gallo-firmware/src/handlers/info.rs`
- Modify: `crates/pico-de-gallo-firmware/src/main.rs`
- Modify: `crates/pico-de-gallo-lib/src/lib.rs` (test fixture only)

- [ ] **Step 1: Write the failing tests**

In `crates/pico-de-gallo-internal/src/lib.rs`, inside `mod tests`, add these
three tests immediately after the existing `device_info_no_capabilities_round_trip`
test (which ends around line 3627):

```rust
    #[test]
    fn device_info_round_trip_carries_build_id() {
        // Sweep the three shapes the firmware can actually produce: a full
        // describe string, the git-unavailable fallback, and empty (which a
        // buggy build.rs could emit and which must still decode).
        for id in [
            "firmware-v0.11.0-27-g8ddb1da5a681-dirty",
            "unknown",
            "",
            // Exactly BUILD_ID_CAPACITY bytes.
            "0123456789012345678901234567890123456789012345678901234567890123",
        ] {
            let info = DeviceInfo {
                fw_major: 0,
                fw_minor: 11,
                fw_patch: 0,
                schema_major: 0,
                schema_minor: 7,
                schema_patch: 0,
                hw_version: 2,
                capabilities: Capabilities::I2C,
                num_gpios: NUM_GPIOS as u8,
                build_id: heapless::String::try_from(id).unwrap(),
            };
            let bytes = to_allocvec(&info).unwrap();
            let decoded: DeviceInfo = from_bytes(&bytes).unwrap();
            assert_eq!(info, decoded, "build_id {id:?} must round-trip");
            assert_eq!(decoded.build_id(), id);
        }
    }

    #[test]
    fn build_id_capacity_is_sixty_four() {
        // Pinned because the firmware build script hardcodes the same number
        // for truncation and cannot import this constant.
        assert_eq!(BUILD_ID_CAPACITY, 64);
    }

    #[test]
    fn device_info_rejects_overlong_build_id() {
        // heapless deserialization errors rather than truncating, so an
        // over-long id is a decode failure, not silent data loss. This is why
        // the firmware build script must do the truncating.
        #[derive(Serialize)]
        struct OverlongDeviceInfo {
            fw_major: u16,
            fw_minor: u16,
            fw_patch: u32,
            schema_major: u16,
            schema_minor: u16,
            schema_patch: u32,
            hw_version: u8,
            capabilities: Capabilities,
            num_gpios: u8,
            build_id: &'static str,
        }

        let overlong = OverlongDeviceInfo {
            fw_major: 1,
            fw_minor: 2,
            fw_patch: 3,
            schema_major: 4,
            schema_minor: 5,
            schema_patch: 6,
            hw_version: 7,
            capabilities: Capabilities(8),
            num_gpios: 9,
            // 65 bytes: one past BUILD_ID_CAPACITY.
            build_id: "01234567890123456789012345678901234567890123456789012345678901234",
        };
        let bytes = to_allocvec(&overlong).unwrap();
        assert!(from_bytes::<DeviceInfo>(&bytes).is_err());
    }
```

- [ ] **Step 2: Extend the byte-image test**

The existing `device_info_encodes_fields_in_declared_order` test (around line
3713) asserts an exact 9-byte encoding and **will** fail once the field is
added. That is by design — it is the test that proves the field is genuinely on
the wire in the declared position. Update it.

In `crates/pico-de-gallo-internal/src/lib.rs`, replace the body of
`device_info_encodes_fields_in_declared_order` with:

```rust
    fn device_info_encodes_fields_in_declared_order() {
        // A plain round-trip is self-consistent by construction: it would
        // still pass if a field were never serialized at all. This test pins
        // the actual byte image, which is what proves each field is genuinely
        // on the wire, in the declared position. Every numeric value is below
        // 128 so each postcard varint occupies exactly one byte.
        //
        // `build_id` is last, and postcard encodes a string as a varint length
        // followed by UTF-8 bytes -- `heapless`'s Serialize impl is
        // `serialize_str`, so neither N nor LenT appears on the wire.
        let info = DeviceInfo {
            fw_major: 1,
            fw_minor: 2,
            fw_patch: 3,
            schema_major: 4,
            schema_minor: 5,
            schema_patch: 6,
            hw_version: 7,
            capabilities: Capabilities(8),
            num_gpios: 9,
            build_id: heapless::String::try_from("ab").unwrap(),
        };
        let bytes = to_allocvec(&info).unwrap();
        assert_eq!(bytes.as_slice(), &[1u8, 2, 3, 4, 5, 6, 7, 8, 9, 2, b'a', b'b'][..]);
        assert_eq!(bytes.len(), 12);
        let decoded: DeviceInfo = from_bytes(&bytes).unwrap();
        assert_eq!(info, decoded);

        // An empty build_id costs exactly one byte (the zero length).
        let empty = DeviceInfo {
            build_id: heapless::String::new(),
            ..info
        };
        let bytes = to_allocvec(&empty).unwrap();
        assert_eq!(bytes.as_slice(), &[1u8, 2, 3, 4, 5, 6, 7, 8, 9, 0][..]);
    }
```

Note: `..info` requires `DeviceInfo` to be movable here; `info` is consumed by
the struct-update syntax after its last use, which is fine because the
assertions on `info` happen before it.

- [ ] **Step 3: Run the tests to verify they fail**

Run:
```bash
cd /home/balbi/workspace/pico-de-gallo
cargo test -p pico-de-gallo-internal 2>&1 | tail -20
```
Expected: FAIL to compile — `DeviceInfo` has no field named `build_id`, and
`BUILD_ID_CAPACITY` is not found.

- [ ] **Step 4: Add the dependencies**

In `crates/pico-de-gallo-internal/Cargo.toml`, in `[dependencies]`, add the
`heapless` line and extend the `postcard-schema` features:

```toml
serde = { version = "1.0.228", default-features = false, features = ["derive"] }
postcard = { version = "1", default-features = false }
postcard-rpc = "0.12"
postcard-schema = { version = "0.2.5", features = ["derive", "heapless-v0_9"] }
# Bounded string for `DeviceInfo::build_id`, so the field needs no `use-std`
# split. 0.9.3 is already in both lockfiles via postcard-rpc, and is already a
# direct firmware dependency, so this introduces no new major to either graph.
heapless = { version = "0.9", default-features = false, features = ["serde"] }
```

- [ ] **Step 5: Add the capacity constant and the field**

In `crates/pico-de-gallo-internal/src/lib.rs`, add the constant immediately
above the `DeviceInfo` doc comment (just before the `/// Extended device
information...` block that precedes the struct at ~line 1578):

```rust
/// Maximum length of [`DeviceInfo::build_id()`], in bytes.
///
/// The field must always be spelled `heapless::String<BUILD_ID_CAPACITY>`,
/// leaving `LenT` at its default. `postcard-schema` implements `Schema` only
/// for `String<N>` at the default `LenT`, so naming a non-default `LenT`
/// silently breaks the `Schema` derive.
///
/// This is a *receive-side* bound. `heapless` deserialization rejects a longer
/// string rather than truncating it, so the firmware build script is
/// responsible for truncating; see `crates/pico-de-gallo-firmware/build.rs`.
/// Raising this value is not a wire-format change (the encoding is a plain
/// postcard string either way), but it is a `Schema` change and still needs a
/// lockstep bump per AGENTS.md §6.2.
pub const BUILD_ID_CAPACITY: usize = 64;
```

Then append the field as the **last** field of `DeviceInfo`, after `num_gpios`:

```rust
    /// Firmware build identity.
    ///
    /// The output of `git describe --always --dirty --tags --match
    /// firmware-v*` captured when the firmware was built, or `"unknown"` when
    /// git was unavailable at build time.
    ///
    /// Informational only. This is **never** a compatibility gate: schema
    /// version answers "can we talk?", and this field answers "are you the
    /// build I think you are?". `PicoDeGallo::validate()` deliberately ignores
    /// it. Use [`DeviceInfo::build_id()`] to read it as a `&str`.
    pub build_id: heapless::String<BUILD_ID_CAPACITY>,
```

- [ ] **Step 6: Add the accessor**

In `crates/pico-de-gallo-internal/src/lib.rs`, immediately after the closing
brace of the `DeviceInfo` struct, add:

```rust
impl DeviceInfo {
    /// The firmware build identity as a string slice.
    ///
    /// Provided so host crates never need to name `heapless` themselves.
    ///
    /// Note for doc authors: this method and the `build_id` field share a
    /// name, so a bare intra-doc link `[DeviceInfo::build_id]` is ambiguous
    /// and fails the `RUSTDOCFLAGS` doc job. Always write
    /// `[DeviceInfo::build_id()]` for this method.
    pub fn build_id(&self) -> &str {
        &self.build_id
    }
}
```

- [ ] **Step 7: Fix the schema-freeze markers**

Two `SCHEMA FREEZE` comments are stale — the bump they demanded was performed
and released as `internal-v0.7.0`. Verify that first:

```bash
cd /home/balbi/workspace/pico-de-gallo
git show internal-v0.7.0:crates/pico-de-gallo-internal/Cargo.toml | grep '^version'
git show internal-v0.7.0:crates/pico-de-gallo-internal/src/lib.rs | grep -c 'num_gpios: u8'
```
Expected: `version = "0.7.0"` and a count of `1` — proving the released tag
already contains the change the markers describe.

Now **delete** the stale marker above `SpiError` (currently at `lib.rs:433`):

```rust
// SCHEMA FREEZE: SpiError and DeviceInfo change shape on the `zephyr` branch
```
(delete that comment and its continuation lines)

And **replace** the stale marker above `DeviceInfo` (currently at `lib.rs:1583`,
the four-line `// SCHEMA FREEZE: This field addition is intentionally
incompatible...` block) with:

```rust
// SCHEMA FREEZE: `build_id` was appended after the schema 0.7.0 release
// (tags `internal-v0.7.0` / `firmware-v0.11.0`). The addition is append-only,
// but a host built from this tree cannot decode `device/info` from a released
// 0.11.0 firmware -- postcard hits end-of-input on the new field -- and
// `validate()` cannot warn, because both peers still report schema 0.7.
// Host and firmware must therefore be built from the same tree until release.
//
// Do not release or tag this branch until the maintainer performs the lockstep
// version bump required by AGENTS.md §6.5. The next `pico-de-gallo-internal`
// release must be 0.8.0, NOT 0.7.1: a new wire field is not a patch.
```

- [ ] **Step 8: Populate the field in the firmware handler**

In `crates/pico-de-gallo-firmware/src/handlers/info.rs`:

Change the `crate` import on line 10 from:
```rust
use crate::{HW_VERSION, VERSION_MAJOR, VERSION_MINOR, VERSION_PATCH};
```
to:
```rust
use crate::{BUILD_ID, HW_VERSION, VERSION_MAJOR, VERSION_MINOR, VERSION_PATCH};
```

Then add the field as the last entry of the returned `DeviceInfo` literal,
after `num_gpios: NUM_GPIOS as u8,`:

```rust
        // Cannot fail: `build.rs` truncates to BUILD_ID_CAPACITY and
        // `main.rs` asserts the bound at compile time. `unwrap_or_default()`
        // rather than `unwrap()` because postcard-rpc dispatches handlers
        // serially on a shared context, so a panic here would take the whole
        // dispatcher down rather than failing one call.
        build_id: heapless::String::try_from(BUILD_ID).unwrap_or_default(),
```

- [ ] **Step 9: Add the compile-time length assertion**

In `crates/pico-de-gallo-firmware/src/main.rs`, immediately after the
`include!(concat!(env!("OUT_DIR"), "/version.rs"));` line (currently line 122),
add:

```rust
// Bounds the generated value against the wire capacity: a BUILD_ID that
// would not fit `DeviceInfo::build_id` is a build failure here rather than
// a runtime `unwrap_or_default()` silently reporting an empty identity.
//
// Note what this does NOT do. `build.rs` duplicates the capacity literal
// because a build script cannot import from the crate it is building, and
// this assertion does not compare the two literals -- it only checks the
// value that was actually produced. A build.rs truncating at 128 would
// still pass here whenever `git describe` happened to emit under 64 bytes.
const _: () = assert!(BUILD_ID.len() <= pico_de_gallo_internal::BUILD_ID_CAPACITY);
```

- [ ] **Step 10: Fix the host-lib test fixture**

In `crates/pico-de-gallo-lib/src/lib.rs`, in `mod tests`, the `make_device_info`
helper (around line 1875) constructs a `DeviceInfo` and will no longer compile.
Add the field as its last entry, after `num_gpios: NUM_GPIOS as u8,`:

```rust
            build_id: "test-build".try_into().unwrap(),
```

- [ ] **Step 11: Run the host tests**

Run:
```bash
cd /home/balbi/workspace/pico-de-gallo
cargo test --locked 2>&1 | tail -30
```
Expected: PASS, including the three new `internal` tests and the updated
`device_info_encodes_fields_in_declared_order`.

- [ ] **Step 12: Refresh both lockfiles**

`heapless` becomes a direct dependency of `pico-de-gallo-internal`, so both
workspaces need their locks regenerated (AGENTS.md §7.1).

Run:
```bash
cd /home/balbi/workspace/pico-de-gallo
cargo check --workspace --locked 2>&1 | tail -5 || cargo generate-lockfile
cargo check --workspace --locked
cd crates/pico-de-gallo-firmware
cargo check --locked --target thumbv8m.main-none-eabihf 2>&1 | tail -5 \
  || cargo update -p pico-de-gallo-internal
cargo check --locked --target thumbv8m.main-none-eabihf
```
Expected: both `cargo check --locked` invocations PASS. If the first attempt
reports the lock is out of date, the fallback regenerates it; re-run the check.

- [ ] **Step 13: Confirm cargo-deny is still clean**

`heapless` 0.7 / 0.8 / 0.9 already coexist, so `bans.multiple-versions = "warn"`
status must be unchanged — not newly worse.

Run:
```bash
cd /home/balbi/workspace/pico-de-gallo
cargo deny --manifest-path Cargo.toml check 2>&1 | tail -20
```
Expected: no *new* errors. Pre-existing `multiple-versions` warnings for
`heapless` are acceptable and already documented in `deny.toml`.

- [ ] **Step 14: Build the firmware**

Run:
```bash
cd /home/balbi/workspace/pico-de-gallo/crates/pico-de-gallo-firmware
cargo build --release --locked --target thumbv8m.main-none-eabihf
cargo clippy --target thumbv8m.main-none-eabihf -- -D warnings
cargo clippy --target thumbv8m.main-none-eabihf \
    --no-default-features --features hw-rev1 -- -D warnings
```
Expected: all PASS.

- [ ] **Step 15: Lint and format the host workspace**

Run:
```bash
cd /home/balbi/workspace/pico-de-gallo
cargo fmt --all
cargo fmt --check
cargo clippy --all-targets --locked -- -D warnings
```
Expected: all PASS.

- [ ] **Step 16: Commit**

```bash
cd /home/balbi/workspace/pico-de-gallo
git add crates/pico-de-gallo-internal crates/pico-de-gallo-firmware \
        crates/pico-de-gallo-lib/src/lib.rs Cargo.lock
git commit -F - <<'EOF'
feat(internal,firmware): Report the firmware build identity in device/info

Append `build_id` to `DeviceInfo` as a `heapless::String<64>` and
populate it from the `BUILD_ID` the firmware build script derives from
`git describe`. `postcard-schema` already implements `Schema` for
heapless strings, and heapless 0.9.3 is already in both lockfiles via
postcard-rpc, so this adds no new major to either dependency graph.

The field is informational and is never a compatibility gate.
`validate()` is deliberately untouched: the schema version answers
"can we talk?", and this field answers "are you the build I think you
are?". Those are separate questions, and conflating them would force a
dishonest schema bump for every behavioural change.

Delete two stale SCHEMA FREEZE markers. Both demanded a lockstep bump
that has since been performed and released; `internal-v0.7.0` is
tagged and already contains the changes they describe. Leaving false
markers beside a live one destroys the signal. Replace them with one
that names `build_id` and records that the next internal release must
be 0.8.0, not 0.7.1, because a new wire field is not a patch.

Because the field was appended after 0.7.0 shipped, a host built from
this tree cannot decode `device/info` from a released 0.11.0 firmware,
and `validate()` cannot warn since both peers still report schema 0.7.
Host and firmware must be built from the same tree until release.

Refs: #159

Assisted-by: OpenCode:claude-opus-5
Co-authored-by: Copilot <223556219+Copilot@users.noreply.github.com>
EOF
```

---

## Task 3: Pin the "never a gate" policy in `pico-de-gallo-lib`

**Files:**
- Modify: `crates/pico-de-gallo-lib/src/lib.rs`

- [ ] **Step 1: Write the failing test**

In `crates/pico-de-gallo-lib/src/lib.rs`, in `mod tests`, add this after the
existing `check_schema_compatible_accepts_matching_versions` test:

```rust
    #[test]
    fn check_schema_compatible_ignores_build_id() {
        // `build_id` is informational: it names the image, it does not gate
        // compatibility. If this ever starts failing, someone has wired the
        // field into the compatibility policy, which would force a dishonest
        // schema bump for every behavioural change (issue #159).
        for id in ["", "unknown", "firmware-v0.11.0-27-gdeadbee-dirty"] {
            let mut info = make_device_info(SCHEMA_VERSION_MAJOR, SCHEMA_VERSION_MINOR);
            info.build_id = id.try_into().unwrap();
            check_schema_compatible(&info)
                .unwrap_or_else(|e| panic!("build_id {id:?} must not gate: {e}"));
        }
    }

    #[test]
    fn device_info_exposes_build_id_accessor() {
        let mut info = make_device_info(SCHEMA_VERSION_MAJOR, SCHEMA_VERSION_MINOR);
        info.build_id = "firmware-v0.11.0".try_into().unwrap();
        assert_eq!(info.build_id(), "firmware-v0.11.0");
    }
```

- [ ] **Step 2: Run the tests to verify they pass**

These should pass immediately — `check_schema_compatible` already ignores the
field. That is the point: the tests are regression guards, not drivers.

Run:
```bash
cd /home/balbi/workspace/pico-de-gallo
cargo test -p pico-de-gallo-lib check_schema_compatible_ignores_build_id -- --nocapture
cargo test -p pico-de-gallo-lib device_info_exposes_build_id_accessor
```
Expected: both PASS.

- [ ] **Step 3: Verify the guard actually guards**

A regression test that cannot fail is worthless. Temporarily add this to
`check_schema_compatible` in `crates/pico-de-gallo-lib/src/lib.rs`:

```rust
    if info.build_id() != "expected" {
        return Err(ValidateError::LegacyFirmware);
    }
```

Run:
```bash
cd /home/balbi/workspace/pico-de-gallo
cargo test -p pico-de-gallo-lib check_schema_compatible_ignores_build_id 2>&1 | tail -5
```
Expected: FAIL with `build_id "" must not gate`. **Now remove those three
lines again** and re-run to confirm PASS.

- [ ] **Step 4: Update the `validate()` rustdoc**

In `crates/pico-de-gallo-lib/src/lib.rs`, find the `validate()` doc comment
(around line 1114). Replace the stale paragraph that begins `/// Note: during
the schema freeze on this branch,` and references `0.6.1` with:

```rust
    /// This checks the reported numbers; it cannot make them trustworthy,
    /// and there are two distinct ways they can mislead.
    ///
    /// Wire *shape*: during the current unreleased schema freeze a
    /// matching schema version does not prove shape compatibility.
    /// `DeviceInfo` gained `build_id` after schema 0.7.0 was released, so
    /// this host cannot decode `device/info` from a released firmware
    /// 0.11.0 even though both peers report schema 0.7. Build host and
    /// firmware from the same tree until the 0.8.0 release.
    ///
    /// Wire *behaviour*: the schema version is derived from the wire
    /// crate's package version, so it is intended to track wire-type
    /// changes, not handler changes. Two firmware builds can report
    /// identical versions and still frame the bus differently. To
    /// identify the image, read
    /// [`DeviceInfo::build_id()`](method@pico_de_gallo_internal::DeviceInfo::build_id).
    /// It is informational only and never affects the outcome of this
    /// call.
```

- [ ] **Step 4b: Guard the dated claim with an executable expiry test**

The freeze warning added in Step 4 has an expiry date, and nothing else
forces anyone to revisit it — the paragraph it replaced was itself a stale
dated claim about an already-shipped 0.6.1 freeze. Add this to `mod tests`,
next to the other `build_id` tests:

```rust
    #[test]
    // Both operands are compile-time constants, which is exactly the point:
    // the assertion exists to fail the build's test run when the schema
    // reaches 0.8, not to check anything about runtime state.
    #[allow(clippy::assertions_on_constants)]
    fn validate_schema_freeze_rustdoc_must_be_revisited_before_schema_0_8() {
        // `validate()`'s rustdoc carries a DATED claim: that host and firmware
        // must be built from the same tree "until the 0.8.0 release". Nothing
        // else forces anyone to revisit it, and the paragraph it replaced was
        // itself a stale dated claim about a 0.6.1 freeze that had already
        // shipped. This test is the guard: it fails the moment the schema
        // reaches 0.8, so whoever cuts that release must delete or rewrite the
        // freeze warning rather than leaving public rustdoc quietly wrong.
        assert!(
            SCHEMA_VERSION_MAJOR == 0 && SCHEMA_VERSION_MINOR < 8,
            "validate() rustdoc says host and firmware must be built from the \
             same tree only until schema 0.8.0; remove or rewrite that dated \
             freeze warning as part of the 0.8.0 release"
        );
    }
```

Prove the guard can fire: temporarily change `< 8` to `< 0`, run
`cargo test -p pico-de-gallo-lib validate_schema_freeze`, observe the
failure, then restore `< 8` and confirm it passes.

- [ ] **Step 4c: Add the matching release-checklist item**

Defense in depth, so a human sees it too. Add a numbered step to the
"Step-by-step: cutting a release" list in `.github/RELEASE.md` (renumbering
the following steps to match the file's existing style):

```markdown
5. **If this release bumps the schema minor, revisit the dated
   wire-shape freeze warning** in `PicoDeGallo::validate()`'s rustdoc
   (`crates/pico-de-gallo-lib/src/lib.rs`) and remove or rewrite it.
   The `validate_schema_freeze_rustdoc_must_be_revisited_before_schema_0_8`
   test fails until this is done, so a forgotten warning blocks the
   release rather than shipping stale public documentation.
```

- [ ] **Step 5: Verify the docs build cleanly**

The field and the accessor share a name, so a bare intra-doc link would be
ambiguous and fail the doc job.

Run:
```bash
cd /home/balbi/workspace/pico-de-gallo
RUSTDOCFLAGS="--cfg docsrs" cargo +nightly doc -p pico-de-gallo-lib \
    -p pico-de-gallo-internal --no-deps --all-features 2>&1 | tail -20
```
Expected: PASS with **no** `ambiguous link` warnings.

- [ ] **Step 6: Run the full lib test suite and lint**

Run:
```bash
cd /home/balbi/workspace/pico-de-gallo
cargo test -p pico-de-gallo-lib --locked
cargo clippy -p pico-de-gallo-lib --all-targets --locked -- -D warnings
cargo fmt --check
```
Expected: all PASS.

- [ ] **Step 7: Commit**

```bash
cd /home/balbi/workspace/pico-de-gallo
git add crates/pico-de-gallo-lib/src/lib.rs
git commit -F - <<'EOF'
test(lib): Pin build_id as informational, never a compatibility gate

`check_schema_compatible` already ignores `build_id`, which is the
intended policy but was not enforced by anything. Add regression tests
that fail if someone wires the field into the compatibility decision,
verified by temporarily introducing that bug and watching them fail.

Conflating the two would be actively harmful: the schema version
answers "can we talk?" and must move only when the wire types change,
so gating on build identity would force a dishonest schema bump for
every behavioural change.

Also replace the stale `validate()` note, which described a schema
freeze at 0.6.1 that has since been released, with a pointer to
`DeviceInfo::build_id()` as the way to answer the question `validate()
cannot.

Refs: #159

Assisted-by: OpenCode:claude-opus-5
Co-authored-by: Copilot <223556219+Copilot@users.noreply.github.com>
EOF
```

---

## Task 4: Render `gallo version` with `tabled`

**Files:**
- Modify: `crates/pico-de-gallo-app/src/lib.rs:786-833` (the `version` method)

- [ ] **Step 1: Write the failing test**

The current `version` method prints directly with `println!`, which is
untestable. The fix is to extract a pure rendering function.

In `crates/pico-de-gallo-app/src/lib.rs`, in `mod tests` (starts line 1586), add:

```rust
    fn sample_device_info() -> pico_de_gallo_lib::DeviceInfo {
        pico_de_gallo_lib::DeviceInfo {
            fw_major: 0,
            fw_minor: 11,
            fw_patch: 0,
            schema_major: 0,
            schema_minor: 7,
            schema_patch: 0,
            hw_version: 2,
            capabilities: pico_de_gallo_lib::Capabilities::I2C
                | pico_de_gallo_lib::Capabilities::SPI,
            num_gpios: 4,
            build_id: "firmware-v0.11.0-27-gdeadbee-dirty".try_into().unwrap(),
        }
    }

    /// Index of the rendered line holding `label`, for same-row assertions.
    ///
    /// Asserting a label and its value as unrelated substring searches proves
    /// almost nothing: both would still pass if the values were swapped
    /// between rows. Locating the row is what makes it a real pin.
    fn summary_row(out: &str, label: &str) -> (usize, String) {
        let (idx, line) = out
            .lines()
            .enumerate()
            .find(|(_, line)| line.contains(label))
            .unwrap_or_else(|| panic!("no row for label {label:?}:\n{out}"));
        (idx, line.to_string())
    }

    fn assert_summary_row(out: &str, label: &str, value: &str) {
        let (_, line) = summary_row(out, label);
        assert!(
            line.contains(value),
            "row for {label:?} does not carry value {value:?}:\n{line}\n\nfull output:\n{out}"
        );
    }

    #[test]
    fn render_device_info_reports_every_field() {
        let out = render_device_info(&sample_device_info());
        // Label AND value, on the same rendered row, for every summary field.
        assert_summary_row(&out, "Firmware", "v0.11.0");
        assert_summary_row(&out, "Schema", "v0.7.0");
        assert_summary_row(&out, "HW revision", "2");
        assert_summary_row(&out, "GPIOs", "4");
        assert_summary_row(&out, "Build", "firmware-v0.11.0-27-gdeadbee-dirty");
        // The summary table is key/value, so it must have no internal rule:
        // `Builder` renders record 0 as a header unless horizontals are
        // removed, which would draw a rule under `Firmware` and imply it is a
        // column heading. Counting the left tee across both tables is the
        // robust pin: exactly one may appear, the capabilities table's own
        // genuine header rule. It fails if the summary rule returns (2) and
        // also if someone strips the capabilities header rule (0), without
        // hard-coding either table's full box-drawing layout.
        assert_eq!(
            out.matches('├').count(),
            1,
            "expected exactly one header rule (capabilities only):\n{out}"
        );
    }

    #[test]
    fn render_device_info_puts_build_last() {
        // `Build` is rendered last to mirror `build_id` being the last field
        // of the wire type. Comparing row indices pins the ordering without
        // hard-coding the whole table layout.
        let out = render_device_info(&sample_device_info());
        let (build, _) = summary_row(&out, "Build");
        for label in ["Firmware", "Schema", "HW revision", "GPIOs"] {
            let (other, _) = summary_row(&out, label);
            assert!(
                build > other,
                "`Build` (row {build}) must come after {label:?} (row {other}):\n{out}"
            );
        }
    }

    #[test]
    fn render_device_info_marks_capabilities() {
        let out = render_device_info(&sample_device_info());
        // Every capability column must be present and in the documented order.
        let names = ["I2C", "SPI", "UART", "GPIO", "PWM", "ADC", "1-Wire"];
        let (header_idx, header) = summary_row(&out, "1-Wire");
        for name in names {
            assert!(
                header.contains(name),
                "capability column {name:?} missing from header:\n{header}\n\nfull output:\n{out}"
            );
        }
        // The marks row is two lines below the header (header, rule, marks).
        // Assert its exact contents rather than merely that some tick exists:
        // the fixture sets I2C and SPI only, so dropping or miswiring any
        // column changes this sequence.
        let marks: Vec<&str> = out
            .lines()
            .nth(header_idx + 2)
            .unwrap_or_else(|| panic!("no marks row after header:\n{out}"))
            .split('│')
            .map(str::trim)
            .filter(|cell| !cell.is_empty())
            .collect();
        assert_eq!(
            marks,
            ["✓", "✓", "✗", "✗", "✗", "✗", "✗"],
            "capability marks do not match the fixture (I2C+SPI only):\n{out}"
        );
    }

    #[test]
    fn render_device_info_covers_every_known_capability() {
        // `Capabilities` is an extensible u64 newtype and `render_device_info`
        // keeps its own display list, so a bit added to the wire crate would
        // otherwise be silently missing from `gallo version` with nothing
        // failing. If this test breaks, a capability was added upstream: add
        // it to the table in `render_device_info` and extend this mask.
        use pico_de_gallo_lib::Capabilities;
        let rendered = Capabilities::I2C
            | Capabilities::SPI
            | Capabilities::UART
            | Capabilities::GPIO
            | Capabilities::PWM
            | Capabilities::ADC
            | Capabilities::ONEWIRE;
        assert_eq!(
            rendered.bits(),
            0x7F,
            "a capability bit was added to pico-de-gallo-internal but not to \
             the `gallo version` capability table"
        );
    }

    #[test]
    fn render_device_info_shows_dirty_marker_verbatim() {
        // The `-dirty` suffix is the most valuable part of the build id for a
        // bisecting developer, so make sure nothing strips or reformats it.
        let out = render_device_info(&sample_device_info());
        assert!(out.contains("-dirty"), "dirty marker lost:\n{out}");
    }
```

- [ ] **Step 2: Run the test to verify it fails**

Run:
```bash
cd /home/balbi/workspace/pico-de-gallo
cargo test -p gallo render_device_info 2>&1 | tail -10
```
Expected: FAIL to compile — `render_device_info` not found.

- [ ] **Step 3: Write the rendering function**

In `crates/pico-de-gallo-app/src/lib.rs`, add this as a free function at module
level (outside the `impl Cli` block, near the other helpers):

```rust
/// Render `device/info` as two tables.
///
/// Pure and returning `String` rather than printing, so the formatting is
/// testable. Two tables rather than one because capabilities are naturally a
/// wide boolean row; packing seven ticks into a single value cell is what the
/// previous hand-rolled output did badly.
fn render_device_info(info: &DeviceInfo) -> String {
    use pico_de_gallo_lib::Capabilities;

    let mut summary = Builder::with_capacity(5, 2);
    summary.push_record([
        "Firmware".to_string(),
        format!("v{}.{}.{}", info.fw_major, info.fw_minor, info.fw_patch),
    ]);
    summary.push_record([
        "Schema".to_string(),
        format!(
            "v{}.{}.{}",
            info.schema_major, info.schema_minor, info.schema_patch
        ),
    ]);
    summary.push_record(["HW revision".to_string(), info.hw_version.to_string()]);
    summary.push_record(["GPIOs".to_string(), info.num_gpios.to_string()]);
    // Last, mirroring `build_id` being the last wire field.
    summary.push_record(["Build".to_string(), info.build_id().to_string()]);

    let mut summary = summary.build();
    // Key/value rows, not a header plus data: `Builder` would otherwise
    // render record 0 as a header and draw a rule under `Firmware`.
    summary.with(Style::rounded().remove_horizontals());

    let caps = [
        ("I2C", Capabilities::I2C),
        ("SPI", Capabilities::SPI),
        ("UART", Capabilities::UART),
        ("GPIO", Capabilities::GPIO),
        ("PWM", Capabilities::PWM),
        ("ADC", Capabilities::ADC),
        ("1-Wire", Capabilities::ONEWIRE),
    ];

    let mut caps_table = Builder::with_capacity(2, caps.len());
    caps_table.push_record(caps.iter().map(|(name, _)| (*name).to_string()));
    caps_table.push_record(caps.iter().map(|(_, flag)| {
        if info.capabilities.contains(*flag) {
            "✓".to_string()
        } else {
            "✗".to_string()
        }
    }));

    let mut caps_table = caps_table.build();
    caps_table.with(Style::rounded());

    format!("{summary}\n{caps_table}")
}
```

- [ ] **Step 4: Run the test to verify it passes**

Run:
```bash
cd /home/balbi/workspace/pico-de-gallo
cargo test -p gallo render_device_info 2>&1 | tail -10
```
Expected: 3 tests PASS.

- [ ] **Step 5: Wire it into the `version` command**

In `crates/pico-de-gallo-app/src/lib.rs`, in the `version` method, replace the
entire `Ok(info) => { ... }` arm body (the five `println!` calls and the
`status` closure, currently lines 789-816) with:

```rust
            Ok(info) => {
                println!("{}", render_device_info(&info));
                Ok(())
            }
```

Leave the `Err(_) =>` legacy-firmware arm exactly as it is: that branch has only
a version number and one explanatory sentence, and exists for firmware too old
to have `device/info` at all, so a one-row table would be worse.

- [ ] **Step 6: Verify the whole crate still builds and lints**

Run:
```bash
cd /home/balbi/workspace/pico-de-gallo
cargo test -p gallo --locked
cargo clippy -p gallo --all-targets --locked -- -D warnings
cargo fmt --check
```
Expected: all PASS. If clippy complains about an unused `Alignment` or `Rows`
import, that means the `i2c scan` code no longer needs it — do **not** remove
those imports; `i2c_scan` still uses them.

- [ ] **Step 7: Commit**

```bash
cd /home/balbi/workspace/pico-de-gallo
git add crates/pico-de-gallo-app/src/lib.rs
git commit -F - <<'EOF'
feat(application): Show the firmware build identity in gallo version

Print the build identity so a developer can tell which image is
actually flashed, which the firmware and schema versions cannot
answer on their own.

Rebuild the output on `tabled`, which the crate already depends on for
`i2c scan`, leaving one table idiom rather than two. `version` was the
last hand-rolled `println!` block. Render into a `String` from a pure
function so the formatting is covered by tests instead of eyeballed.

Also print the GPIO count, which is on the wire type and on the Python
class but has never been shown by the CLI.

The legacy-firmware fallback keeps plain `println!`: it has only a
version number and one explanatory sentence, and exists for firmware
predating `device/info` entirely.

Refs: #159

Assisted-by: OpenCode:claude-opus-5
Co-authored-by: Copilot <223556219+Copilot@users.noreply.github.com>
EOF
```

---

## Task 5: Surface the build identity in `gallo-mcp`

**Files:**
- Modify: `crates/pico-de-gallo-mcp/src/device.rs` (`StatusResult`, `build_status`, `status`)
- Modify: `crates/pico-de-gallo-mcp/src/lib.rs` (`connect`)
- Modify: `crates/pico-de-gallo-mcp/src/main.rs` (default `EnvFilter`)

- [ ] **Step 1: Write the failing test**

In `crates/pico-de-gallo-mcp/src/device.rs`, in the existing `mod tests` block
(near line 252), add:

```rust
    #[test]
    fn status_result_serializes_build_id() {
        let mut out = build_status(vec![Some("ABC123".to_string())], None, None);
        out.build_id = Some("firmware-v0.11.0-27-gdeadbee-dirty".to_string());
        let json = serde_json::to_value(&out).unwrap();
        assert_eq!(
            json["build_id"],
            serde_json::json!("firmware-v0.11.0-27-gdeadbee-dirty")
        );
    }

    #[test]
    fn status_result_build_id_is_null_before_connecting() {
        // `build_status` runs before any connection, so it cannot know the
        // build identity. It must say null rather than inventing one.
        let out = build_status(vec![Some("ABC123".to_string())], None, None);
        assert!(out.build_id.is_none());
        let json = serde_json::to_value(&out).unwrap();
        assert!(json.get("build_id").is_some(), "field must still be present");
        assert!(
            json["build_id"].is_null(),
            "build_id must serialize as null, not be omitted"
        );
    }
```

Also add a test for the extracted population helper introduced in Step 5a.
`status` can only reach that logic through `connect()`, i.e. with a physical
board attached, so without this test the population is completely uncovered:
deleting the `build_id` assignment leaves the whole suite green.

```rust
    #[test]
    fn fill_status_from_device_populates_every_device_field() {
        let mut out = build_status(vec![Some("ABC123".to_string())], None, None);
        let info = DeviceInfo {
            fw_major: 0,
            fw_minor: 11,
            fw_patch: 0,
            schema_major: 0,
            schema_minor: 7,
            schema_patch: 0,
            hw_version: 2,
            capabilities: pico_de_gallo_lib::Capabilities::NONE,
            num_gpios: pico_de_gallo_lib::NUM_GPIOS as u8,
            build_id: "firmware-v0.11.0-27-gdeadbee-dirty".try_into().unwrap(),
        };
        fill_status_from_device(&mut out, Some("ABC123"), &info);
        assert_eq!(out.serial_number.as_deref(), Some("ABC123"));
        assert_eq!(out.firmware_version.as_deref(), Some("0.11.0"));
        assert_eq!(out.schema_major, Some(0));
        assert_eq!(out.schema_minor, Some(7));
        assert_eq!(
            out.build_id.as_deref(),
            Some("firmware-v0.11.0-27-gdeadbee-dirty")
        );
    }
```

- [ ] **Step 2: Run the tests to verify they fail**

Run:
```bash
cd /home/balbi/workspace/pico-de-gallo
cargo test -p gallo-mcp status_result_ 2>&1 | tail -10
cargo test -p gallo-mcp fill_status_from_device 2>&1 | tail -10
```
Expected: FAIL to compile — `StatusResult` has no field `build_id`, and
`fill_status_from_device` does not exist.

- [ ] **Step 3: Add the field to `StatusResult`**

In `crates/pico-de-gallo-mcp/src/device.rs`, add to the `StatusResult` struct as
the last field, after `schema_minor: Option<u16>,`:

```rust
    /// Firmware build identity (`git describe`), null until a board is
    /// reached. Informational: it names the running image, and never affects
    /// whether a call succeeds.
    build_id: Option<String>,
```

- [ ] **Step 4: Initialize it in `build_status`**

In the same file, in `build_status`, add to the returned `StatusResult` literal
as the last field, after `schema_minor: None,`:

```rust
        build_id: None,
```

- [ ] **Step 5a: Extract the device-field population into a pure function**

The five assignments inside `status`'s `Ok(dev)` arm sit behind `connect()`,
so they can only be exercised with a physical board. Extract them so they are
unit-testable. Add above the `#[tool_router(...)] impl GalloMcp` block in
`crates/pico-de-gallo-mcp/src/device.rs`:

```rust
/// Fill in the fields of a `status` response that require a reached board.
///
/// Split out from `status` so it is unit-testable: the caller needs a live
/// `connect()` and therefore a physical board, which means anything left
/// inline there has no automated coverage at all.
fn fill_status_from_device(out: &mut StatusResult, serial: Option<&str>, info: &DeviceInfo) {
    out.serial_number = serial.map(str::to_string);
    out.firmware_version = Some(format!(
        "{}.{}.{}",
        info.fw_major, info.fw_minor, info.fw_patch
    ));
    out.schema_major = Some(info.schema_major);
    out.schema_minor = Some(info.schema_minor);
    out.build_id = Some(info.build_id().to_string());
}
```

`DeviceInfo` needs importing: widen the existing import at the top of the file
to `use pico_de_gallo_lib::{DeviceDescription, DeviceInfo};`.

`Device::serial()` returns `Option<&str>` and `Device::info()` returns
`&DeviceInfo`, so the signature above needs no clone-juggling at the call site.

- [ ] **Step 5b: Call it from the `status` tool**

In the same file, replace the whole `Ok(dev) => { ... }` arm body — the five
inline assignments — with a single call:

```rust
                Ok(dev) => fill_status_from_device(&mut out, dev.serial(), dev.info()),
```

This reads the **cached** `dev.info()` captured at connect-time validation, so
it costs no extra RPC. The serialized JSON is unchanged by the extraction.

- [ ] **Step 6: Run the tests to verify they pass**

Run:
```bash
cd /home/balbi/workspace/pico-de-gallo
cargo test -p gallo-mcp status_result_ 2>&1 | tail -10
cargo test -p gallo-mcp fill_status_from_device 2>&1 | tail -10
```
Expected: 3 tests PASS.

- [ ] **Step 7: Log the build identity on connect**

In `crates/pico-de-gallo-mcp/src/lib.rs`, in `connect`, immediately after the
line `let info = inner.validate().await.map_err(error::map_validate_err)?;`
(currently line 420), add:

```rust
        // Put the build identity in the transcript on every connect. An
        // agent-driven session otherwise has no record of which image it
        // talked to, and the schema version cannot supply one: two builds can
        // report the same version and behave differently (issue #159).
        tracing::info!(
            serial = serial.as_deref().unwrap_or("<none>"),
            firmware = %format_args!("{}.{}.{}", info.fw_major, info.fw_minor, info.fw_patch),
            build_id = info.build_id(),
            "connected"
        );
```

- [ ] **Step 7a: Raise the default log filter so that line is actually emitted**

The `info!` above is discarded by default without this. `main.rs` supplies a
fallback `EnvFilter` used whenever `RUST_LOG` is unset — the normal case, since
MCP clients spawn the server with whatever environment they happen to have —
and that fallback was `error,gallo_mcp=warn`. `EnvFilter` treats a directive's
level as a *maximum* verbosity, so `gallo_mcp=warn` enables ERROR and WARN and
excludes INFO: the connect line would never reach the transcript.

In `crates/pico-de-gallo-mcp/src/main.rs`, change the fallback:

```rust
                .unwrap_or_else(|_| tracing_subscriber::EnvFilter::new("error,gallo_mcp=info")),
```

Do **not** downgrade the log call to `warn!` to sneak past the filter — INFO is
the correct level for a successful routine connection.

While there, fix the now-stale comment above that fallback. It claimed
`gallo_mcp` "has exactly two tracing call sites, one `warn!` and one `debug!`",
which the new line falsifies. Reword it so it describes the *policy* rather
than enumerating call sites, or it will go stale again on the next log line:
say that INFO carries routine-but-important facts (notably the per-connect
identity line), and that anything chattier belongs at `debug!` or below, which
the filter still excludes.

Verify it executably rather than by inspection — a temporary test that builds a
subscriber with each filter string over a capturing writer and emits a
`tracing::info!` from inside this crate shows `""` under
`error,gallo_mcp=warn` and the formatted event under `error,gallo_mcp=info`.

- [ ] **Step 8: Verify the whole crate builds, lints and tests**

Run:
```bash
cd /home/balbi/workspace/pico-de-gallo
cargo test -p gallo-mcp --locked
cargo clippy -p gallo-mcp --all-targets --locked -- -D warnings
cargo fmt --check
```
Expected: all PASS. Note the 7 board-attached tests remain `#[ignore]`d and are
not expected to run.

- [ ] **Step 9: Commit**

```bash
cd /home/balbi/workspace/pico-de-gallo
git add crates/pico-de-gallo-mcp/src/device.rs crates/pico-de-gallo-mcp/src/lib.rs \
    crates/pico-de-gallo-mcp/src/main.rs
git commit -F - <<'EOF'
feat(mcp): Report the firmware build identity in status and on connect

`device_info` already serializes the whole wire struct, so it gained
the field for free. Add it to `status`, which is the tool an agent
reaches for first, reading the DeviceInfo cached at connect-time
validation so it costs no extra round trip.

Also log serial, firmware version and build identity once per connect.
An agent-driven session otherwise leaves no record of which image it
talked to, and the schema version cannot supply one, which is how a
hardware verification session previously reached a wrong conclusion.

The field is null until a board is actually reached, rather than
being invented: `build_status` runs before any connection exists.

Refs: #159

Assisted-by: OpenCode:claude-opus-5
Co-authored-by: Copilot <223556219+Copilot@users.noreply.github.com>
EOF
```

---

## Task 6: Expose the build identity through the C FFI

**Files:**
- Modify: `crates/pico-de-gallo-ffi/src/lib.rs` (`GalloDeviceInfo`, `gallo_get_device_info`)

- [ ] **Step 1: Write the failing test**

In `crates/pico-de-gallo-ffi/src/lib.rs`, in `mod tests`, add:

```rust
    #[test]
    fn gallo_build_id_len_matches_wire_capacity() {
        // cbindgen folds const initializers syntactically, so the array bound
        // must be a literal. This assertion is what stops the literal from
        // drifting away from the wire capacity.
        assert_eq!(GALLO_BUILD_ID_LEN, lib::BUILD_ID_CAPACITY + 1);
    }

    #[test]
    fn write_build_id_nul_terminates() {
        let mut buf = [0xAA_u8 as c_char; GALLO_BUILD_ID_LEN];
        write_build_id(&mut buf, "abc");
        assert_eq!(buf[0], b'a' as c_char);
        assert_eq!(buf[1], b'b' as c_char);
        assert_eq!(buf[2], b'c' as c_char);
        assert_eq!(buf[3], 0, "must be NUL terminated");
    }

    #[test]
    fn write_build_id_handles_maximum_length() {
        // A full-capacity id must fit with room for the terminator, and must
        // not run off the end of the array.
        let full = "0123456789012345678901234567890123456789012345678901234567890123";
        assert_eq!(full.len(), lib::BUILD_ID_CAPACITY);
        let mut buf = [0xAA_u8 as c_char; GALLO_BUILD_ID_LEN];
        write_build_id(&mut buf, full);
        assert_eq!(buf[lib::BUILD_ID_CAPACITY], 0, "terminator must be present");
        for (i, b) in full.bytes().enumerate() {
            assert_eq!(buf[i], b as c_char);
        }
    }

    #[test]
    fn write_build_id_truncates_overlong_input() {
        // The helper's truncation branch is otherwise never executed by the
        // suite. A wire-decoded build_id cannot exceed BUILD_ID_CAPACITY, but
        // the bound is enforced here rather than assumed, so it must be tested
        // rather than trusted.
        let overlong = "0123456789012345678901234567890123456789012345678901234567890123456789";
        assert!(overlong.len() > lib::BUILD_ID_CAPACITY);
        let mut buf = [0xAA_u8 as c_char; GALLO_BUILD_ID_LEN];
        write_build_id(&mut buf, overlong);
        assert_eq!(buf[GALLO_BUILD_ID_LEN - 1], 0, "must still be terminated");
        for (i, b) in overlong.bytes().take(lib::BUILD_ID_CAPACITY).enumerate() {
            assert_eq!(buf[i], b as c_char, "byte {i} must be copied verbatim");
        }
    }

    #[test]
    fn write_build_id_handles_empty() {
        let mut buf = [0xAA_u8 as c_char; GALLO_BUILD_ID_LEN];
        write_build_id(&mut buf, "");
        assert_eq!(buf[0], 0);
    }
```

- [ ] **Step 2: Run the test to verify it fails**

Run:
```bash
cd /home/balbi/workspace/pico-de-gallo
cargo test -p pico-de-gallo-ffi build_id 2>&1 | tail -10
```
Expected: FAIL to compile — `GALLO_BUILD_ID_LEN` and `write_build_id` not found.

- [ ] **Step 3: Add the length constant**

In `crates/pico-de-gallo-ffi/src/lib.rs`, next to the existing
`GALLO_NUM_GPIOS` constant (around line 298), add:

```rust
/// Size of [`GalloDeviceInfo::build_id`], in bytes.
///
/// One more than `pico_de_gallo_internal::BUILD_ID_CAPACITY` to leave room for
/// the NUL terminator.
///
/// Written as a literal on purpose: cbindgen folds const initializers
/// syntactically and silently emits nothing for a computed value, so
/// `BUILD_ID_CAPACITY + 1` here would vanish from the generated header. The
/// assertion below is what keeps the literal honest.
pub const GALLO_BUILD_ID_LEN: usize = 65;
```

And add to the existing block of assertions just below (which already contains
`const _: () = assert!(GALLO_NUM_GPIOS == lib::NUM_GPIOS);`):

```rust
const _: () = assert!(GALLO_BUILD_ID_LEN == lib::BUILD_ID_CAPACITY + 1);
```

- [ ] **Step 4: Add the struct field**

In `crates/pico-de-gallo-ffi/src/lib.rs`, add to `GalloDeviceInfo` as the
**last** member, after `pub capabilities: u64,`:

```rust
    /// Firmware build identity, NUL-terminated.
    ///
    /// The firmware's `git describe --always --dirty --tags --match
    /// firmware-v*` output, or `"unknown"` when git was unavailable when the
    /// firmware was built. A trailing `-dirty` means the firmware was built
    /// from a modified working tree.
    ///
    /// Informational only: it names the running image and never affects
    /// whether a call succeeds.
    ///
    /// Terminated only when the call returned `Status::Ok`; see
    /// [`gallo_get_device_info`].
    pub build_id: [c_char; GALLO_BUILD_ID_LEN],
```

Also update the struct's doc comment, changing
`schema (wire protocol) version, hardware revision, and peripheral
capabilities.` to
`schema (wire protocol) version, hardware revision, peripheral capabilities,
and the firmware build identity.`

- [ ] **Step 5: Add the writer helper**

In `crates/pico-de-gallo-ffi/src/lib.rs`, immediately above
`gallo_get_device_info`, add:

```rust
/// Copy `src` into a fixed C buffer and NUL-terminate it.
///
/// Truncates rather than overflowing if `src` somehow exceeds the buffer. That
/// cannot happen for a wire-decoded `build_id`, whose length is already bounded
/// by `BUILD_ID_CAPACITY`, but the bound is enforced here rather than assumed.
fn write_build_id(dst: &mut [c_char; GALLO_BUILD_ID_LEN], src: &str) {
    let n = src.len().min(GALLO_BUILD_ID_LEN - 1);
    for (slot, byte) in dst.iter_mut().zip(src.as_bytes()[..n].iter()) {
        *slot = *byte as c_char;
    }
    dst[n] = 0;
}
```

- [ ] **Step 6: Populate the field**

In `gallo_get_device_info`, inside the `unsafe { ... }` block, after
`(*out).capabilities = info.capabilities.bits();`, add:

```rust
                write_build_id(&mut (*out).build_id, info.build_id());
```

Also add to `gallo_get_device_info`'s doc comment, after the `Returns
Status::Ok on success, ...` paragraph, a paragraph documenting that the
out-param is untouched on failure. Without it the `build_id` field's own
"NUL-terminated" claim reads as unconditional, and a caller could inspect an
uninitialised struct after an error:

```rust
/// `*out` is written **only** on `Status::Ok`. On every error path —
/// including a null pointer and a failed `validate()` — no field is
/// written, so an uninitialised `GalloDeviceInfo` still holds
/// indeterminate bytes and `build_id` is NOT NUL-terminated. Inspect the
/// struct only after a successful return.
```

- [ ] **Step 7: Run the tests to verify they pass**

Run:
```bash
cd /home/balbi/workspace/pico-de-gallo
cargo test -p pico-de-gallo-ffi build_id 2>&1 | tail -10
```
Expected: 5 tests PASS.

- [ ] **Step 8: Verify the generated header contains the field**

cbindgen prunes anything not reachable from an exported prototype.
`GalloDeviceInfo` is reachable via `gallo_get_device_info`, so no
`cbindgen.toml` change should be needed — but verify rather than assume.

Run:
```bash
cd /home/balbi/workspace/pico-de-gallo
cargo build -p pico-de-gallo-ffi 2>&1 | tail -3
find . -name 'pico_de_gallo.h' -newer crates/pico-de-gallo-ffi/src/lib.rs \
  -exec grep -n -A2 'build_id\|GALLO_BUILD_ID_LEN' {} +
```
Expected: the header shows `#define GALLO_BUILD_ID_LEN 65` and a
`char build_id[GALLO_BUILD_ID_LEN];` member inside `GalloDeviceInfo`.

If `GALLO_BUILD_ID_LEN` is **absent** from the header, the constant was pruned:
add `"GALLO_BUILD_ID_LEN"` to the `[export] include` list in
`crates/pico-de-gallo-ffi/cbindgen.toml` and re-run.

- [ ] **Step 9: Check the Zephyr consumer still compiles**

`zephyr/` links the FFI. Growing `GalloDeviceInfo` at the end should not break
it, but check that nothing there does a positional initialization.

Run:
```bash
cd /home/balbi/workspace/pico-de-gallo
rg -n 'GalloDeviceInfo' zephyr/
```
Expected: any hits either use designated initializers or only read fields. If a
positional initializer exists, add `.build_id = {0}` to it.

- [ ] **Step 10: Lint and format**

Run:
```bash
cd /home/balbi/workspace/pico-de-gallo
cargo test -p pico-de-gallo-ffi --locked
cargo clippy -p pico-de-gallo-ffi --all-targets --locked -- -D warnings
cargo fmt --check
```
Expected: all PASS.

- [ ] **Step 11: Commit**

```bash
cd /home/balbi/workspace/pico-de-gallo
git add crates/pico-de-gallo-ffi
git commit -F - <<'EOF'
feat(ffi): Expose the firmware build identity in GalloDeviceInfo

Add `build_id` as a NUL-terminated `char[65]`, the last member of
`GalloDeviceInfo`, filled by `gallo_get_device_info`.

Inline rather than a separate accessor so C callers get the identity
from the call they already make. The struct grows only at the end, so
the layout change reaches only consumers that recompile, and `zephyr/`
recompiles in-tree.

The array bound is a literal because cbindgen folds const initializers
syntactically and would silently emit nothing for a computed value; a
const assertion ties it to `BUILD_ID_CAPACITY + 1` so the literal
cannot drift. This follows the existing `GALLO_NUM_GPIOS` precedent.

No new `Status` code: status values are stable C ABI and consumers are
told to write an exhaustive switch with no default, so a new value
would fall through. The field cannot fail independently of the call.

Refs: #159

Assisted-by: OpenCode:claude-opus-5
Co-authored-by: Copilot <223556219+Copilot@users.noreply.github.com>
EOF
```

---

## Task 7: Expose the build identity in the Python bindings

**Files:**
- Modify: `crates/pyco-de-gallo/src/lib.rs`

- [ ] **Step 1: Write the failing test**

In `crates/pyco-de-gallo/src/lib.rs`, in `mod tests`, add after the existing
`device_info_conversion_carries_num_gpios` test:

```rust
    #[test]
    fn device_info_conversion_carries_build_id() {
        for id in ["", "unknown", "firmware-v0.11.0-27-gdeadbee-dirty"] {
            let mut info = lib_info(4);
            info.build_id = id.try_into().unwrap();
            let converted: DeviceInfo = info.into();
            assert_eq!(converted.build_id, id);
        }
    }
```

- [ ] **Step 2: Run the test to verify it fails**

Run:
```bash
cd /home/balbi/workspace/pico-de-gallo
cargo test -p pyco-de-gallo build_id 2>&1 | tail -10
```
Expected: FAIL to compile — `DeviceInfo` has no field `build_id`.

- [ ] **Step 3: Add the field to the Python class**

In `crates/pyco-de-gallo/src/lib.rs`, add to the `#[pyclass] struct DeviceInfo`
as the last field, after the `num_gpios: u8,` entry:

```rust
    /// Firmware build identity.
    ///
    /// The firmware's ``git describe --always --dirty --tags --match
    /// firmware-v*`` output captured at build time, or ``"unknown"`` when git
    /// was unavailable. A trailing ``-dirty`` means the firmware was built
    /// from a modified working tree.
    ///
    /// Informational only: it names the running image and never affects
    /// whether a call succeeds. Two firmware builds can report the same
    /// firmware and schema version and still behave differently, so this is
    /// the field to log when reproducing a result.
    #[pyo3(get)]
    build_id: String,
```

- [ ] **Step 4: Convert it**

In the same file, in `impl From<LibDeviceInfo> for DeviceInfo`, add as the last
entry after `num_gpios: info.num_gpios,`:

```rust
            build_id: info.build_id().to_string(),
```

- [ ] **Step 5: Run the test to verify it passes**

Run:
```bash
cd /home/balbi/workspace/pico-de-gallo
cargo test -p pyco-de-gallo build_id 2>&1 | tail -10
```
Expected: PASS.

- [ ] **Step 6: Lint, format and run the full crate suite**

Run:
```bash
cd /home/balbi/workspace/pico-de-gallo
cargo test -p pyco-de-gallo --locked
cargo clippy -p pyco-de-gallo --all-targets --locked -- -D warnings
cargo fmt --check
```
Expected: all PASS.

- [ ] **Step 7: Commit**

```bash
cd /home/balbi/workspace/pico-de-gallo
git add crates/pyco-de-gallo/src/lib.rs
git commit -F - <<'EOF'
feat(pyco): Expose the firmware build identity on DeviceInfo

Add `build_id` to the Python `DeviceInfo` class, converted from the
wire type's accessor. The docstring is Google/Sphinx style so it
renders as the attribute's `__doc__`.

No `Clone` or `from_py_object` needed: `DeviceInfo` is only ever
returned to Python, never accepted as an argument.

Refs: #159

Assisted-by: OpenCode:claude-opus-5
Co-authored-by: Copilot <223556219+Copilot@users.noreply.github.com>
EOF
```

---

## Task 8: Documentation parity

AGENTS.md §15.1 makes this a blocker, not a nit: a PR that ships code without the
matching `book/` edits is incomplete.

**Files:**
- Modify: `book/src/internals/wire-protocol.md`
- Modify: `book/src/appendix/endpoints.md`
- Modify: `book/src/getting-started/verify.md`
- Modify: `book/src/internals/firmware.md`
- Modify: `book/src/crates/{lib,ffi,mcp,python}.md`
- Modify: `crates/pico-de-gallo-mcp/README.md`
- Modify: `crates/pico-de-gallo-{internal,lib,app,mcp,ffi,firmware}/CHANGELOG.md`, `crates/pyco-de-gallo/CHANGELOG.md`
- Modify: `AGENTS.md`

- [ ] **Step 1: Capture the real CLI output to paste into the book**

The book must describe the code that is on `main`, so copy real output rather
than inventing it. If no board is attached, render it from the test fixture
instead:

```bash
cd /home/balbi/workspace/pico-de-gallo
cargo test -p gallo render_device_info_reports_every_field -- --nocapture 2>&1 | head -30
```

Use the actual table characters from that output.

- [ ] **Step 2: Update `book/src/internals/wire-protocol.md`**

In the `DeviceInfo` discussion (the section around the `num_gpios`
runtime-authoritative paragraph, ~lines 123-127), add after that paragraph:

```markdown
### Build identity

`DeviceInfo::build_id` carries the firmware's
`git describe --always --dirty --tags --match firmware-v*` output, captured when
the firmware was built, or `"unknown"` when git was unavailable. A trailing
`-dirty` means the image was built from a modified working tree.

It is **informational only and never a compatibility gate.** `validate()`
deliberately ignores it.

The two fields answer different questions, and conflating them would be a
mistake in both directions:

| Question | Field |
|---|---|
| *Can we talk?* | `schema_major` / `schema_minor` |
| *Are you the build I think you are?* | `build_id` |

The schema version is derived from `pico-de-gallo-internal`'s package version,
so it moves when the wire **types** change. Firmware behaviour can change while
the types do not — `i2c/batch` moved from per-operation START/STOP to a single
transaction inside an unchanged schema 0.7 — and bumping the schema version for
such a change would falsely signal a wire-format break. `build_id` covers that
gap without disturbing the compatibility axis.

The field is a `heapless::String<BUILD_ID_CAPACITY>` (64 bytes), encoded by
postcard as a plain varint-length string, so an empty value costs one byte.
Decoding an over-long string fails rather than truncating; the firmware build
script truncates.
```

- [ ] **Step 3: Update `book/src/appendix/endpoints.md`**

Change the `device/info` row (line 27) from:

```markdown
| device/info | Firmware version + schema version + capability bitfield + runtime GPIO count. |
```
to:
```markdown
| device/info | Firmware version + schema version + capability bitfield + runtime GPIO count + firmware build identity. |
```

- [ ] **Step 4: Update `book/src/getting-started/verify.md`**

The sample output block there is stale — it shows `FW v0.8.0` / `Schema v0.4.0`
and the old flat format. Replace the output block with the real two-table output
captured in Step 1, and add two rows to the "What Each Field Means" table:

```markdown
| `GPIOs` | Number of user-controllable GPIO pins this firmware exposes. This is the authoritative bound for a GPIO index and for an SPI chip-select pin. |
| `Build` | Firmware build identity from `git describe`. A trailing `-dirty` means the image was built from a modified working tree. Informational only — it never affects whether a command succeeds. Quote this when reporting a bug or reproducing a measurement. |
```

- [ ] **Step 5: Update `book/src/internals/firmware.md`**

Add a subsection describing the build-script behaviour. Note the outer fence
is four backticks because the content itself contains a fenced block:

````markdown
### Build identity

`crates/pico-de-gallo-firmware/build.rs` runs

```text
git describe --always --dirty --tags --match firmware-v*
```

and emits the result as a `BUILD_ID` constant, which `main()` logs at boot over
`defmt` and the `device/info` handler returns.

Every flag matters, and each has a *silent* failure mode:

| Flag | Removing it causes |
|---|---|
| `--tags` | The `firmware-v*` tags are a mix of annotated and lightweight. Without this, `git describe` sees only annotated tags and resolves hundreds of commits too far back. |
| `--match firmware-v*` | Describe picks the nearest tag in any namespace, returning an `application-v*` description. |
| `--always` | Describe fails outright when no matching tag is reachable, e.g. in a shallow CI clone. |
| `--dirty` | The locally-modified marker is lost — the single most useful part for a developer mid-bisect. |

When git is unavailable, exits non-zero, or there is no repository, the script
emits `"unknown"` and a `cargo:warning`. The build still succeeds, so a source
tarball remains buildable.

The script re-runs on **every** build, by design. The pre-existing
`rerun-if-changed=memory.x` narrows re-runs to a single file, so without an
unconditional trigger the embedded identity would go stale across incremental
builds and keep reporting a clean tree for a dirty one. A stale identity is
worse than none, because it confirms a wrong conclusion rather than merely
failing to prevent one.

Release workflows must fetch tags (`fetch-depth: 0`), or `git describe`
degrades to a bare commit hash.
````

- [ ] **Step 6: Update the four crate chapters and the MCP README**

- `book/src/crates/lib.md` — note `DeviceInfo::build_id()` and that `validate()` ignores it.
- `book/src/crates/ffi.md` — add `build_id` to the `GalloDeviceInfo` description and mention `GALLO_BUILD_ID_LEN`.
- `book/src/crates/mcp.md` and `crates/pico-de-gallo-mcp/README.md` — `status` gains `build_id`; the server logs it on connect.
- `book/src/crates/python.md` — `DeviceInfo.build_id`.

- [ ] **Step 7: Add CHANGELOG entries**

For each of `crates/pico-de-gallo-internal`, `pico-de-gallo-lib`,
`pico-de-gallo-app`, `pico-de-gallo-mcp`, `pico-de-gallo-ffi`,
`pyco-de-gallo`, `pico-de-gallo-firmware`, insert an `## [Unreleased]` section
immediately below the Keep-a-Changelog preamble and above the current top
release heading. No `[package].version` changes.

For `pico-de-gallo-internal/CHANGELOG.md`:

```markdown
## [Unreleased]

### Breaking Changes

- Appended `DeviceInfo::build_id`, a `heapless::String<64>` carrying the
  firmware's `git describe --always --dirty --tags --match firmware-v*`
  output, or `"unknown"` when git was unavailable. The field is
  informational and is never a compatibility gate: `validate()` ignores
  it. Closes #159.

  This is append-only on the wire, but it landed **after** schema 0.7.0
  shipped, so a host built from this tree cannot decode `device/info`
  from a released firmware 0.11.0 — postcard hits end-of-input on the new
  field — and `validate()` cannot warn, because both peers still report
  schema 0.7. **Host and firmware must be built from the same tree until
  the next release.** That release must be 0.8.0, not 0.7.1: a new wire
  field is not a patch.

### Added

- `BUILD_ID_CAPACITY` (64) and the `DeviceInfo::build_id()` accessor, so
  host crates never need to name `heapless` themselves.
```

Write the corresponding shorter entries for the other six crates, each
describing only that crate's surface.

- [ ] **Step 8: Add the AGENTS.md regression row**

In `AGENTS.md` §13.17, append a row to the table:

```markdown
| 2026-09-01 | Two firmware builds reporting the same schema version behaving differently on the wire — `i2c/batch` framing (2026-08-26) and the zero-length-write guard (2026-08-26), the latter of which **misidentified a flash during its own hardware verification**. | `validate()` compares schema versions only, and `SCHEMA_VERSION_*` is derived from `pico-de-gallo-internal`'s package version, so it tracks type changes rather than handler behaviour. Nothing distinguished the two images, and the recorded mitigation was "track the flashed image yourself", which is not a mitigation. | Appended `DeviceInfo::build_id` (`heapless::String<64>`), generated by the firmware `build.rs` from `git describe --always --dirty --tags --match firmware-v*` and surfaced by `gallo version`, `gallo-mcp` `status` / `device_info` / connect log, the FFI `GalloDeviceInfo`, and `pyco-de-gallo`. Informational only — never a gate, with a regression test that fails if anyone wires it into `check_schema_compatible`. Three traps recorded in `build.rs` comments: without `--tags` describe sees only annotated tags and resolves 302 commits too far back, since the `firmware-v*` tags are a mix of annotated and lightweight; without `--match` it returns an `application-v*` description; and the pre-existing `rerun-if-changed=memory.x` narrows re-runs to one file, so the script must be forced to re-run unconditionally or the embedded identity goes stale and reports a clean tree for a dirty one. Also deleted two stale `SCHEMA FREEZE` markers whose bump had already been released as `internal-v0.7.0`; they caused a wrong conclusion during this very design session. Issue #159. |
```

- [ ] **Step 9: Verify the book builds**

Run:
```bash
cd /home/balbi/workspace/pico-de-gallo
mdbook build book 2>&1 | tail -20
```
Expected: PASS, no broken links or missing files.

- [ ] **Step 10: Confirm LF endings on every edited file**

Run:
```bash
cd /home/balbi/workspace/pico-de-gallo
git diff --cached --name-only | xargs -r file | grep -i crlf || echo "all LF"
```
Expected: `all LF`.

- [ ] **Step 11: Commit**

```bash
cd /home/balbi/workspace/pico-de-gallo
git add book AGENTS.md crates/*/CHANGELOG.md crates/pico-de-gallo-mcp/README.md
git commit -F - <<'EOF'
docs(repo): Document the firmware build identity

Cover the new `device/info` field across the book, the per-crate
CHANGELOGs, and the MCP README, per the book/code parity rule.

Explain why build identity and schema version are separate axes:
the schema version is derived from the wire crate's package version
and so tracks type changes, while firmware behaviour can change with
the types unchanged. Bumping the schema for a behavioural change would
falsely signal a wire-format break, and not bumping it leaves two
indistinguishable images.

Record the three build-script traps: the `firmware-v*` tags are a mix
of annotated and lightweight so `--tags` is required, `--match` is
required to avoid an `application-v*` description, and the script must
re-run unconditionally or the embedded identity goes stale.

Refresh the stale `gallo version` sample in the verify chapter, which
still showed FW v0.8.0 / Schema v0.4.0 in the old flat format, and add
an AGENTS.md regression row.

Refs: #159

Assisted-by: OpenCode:claude-opus-5
Co-authored-by: Copilot <223556219+Copilot@users.noreply.github.com>
EOF
```

---

## Task 9: Full CI preflight

**Files:** none — verification only.

- [ ] **Step 1: Run the host workspace gates**

Run:
```bash
cd /home/balbi/workspace/pico-de-gallo
cargo fmt --check
cargo clippy --all-targets --locked -- -D warnings
cargo test --locked
cargo check --workspace --locked
cargo deny --manifest-path Cargo.toml check
```
Expected: all PASS. Test count should be the ~589 baseline plus the roughly
14 tests added by this plan.

- [ ] **Step 2: Run the per-crate feature powerset**

Run:
```bash
cd /home/balbi/workspace/pico-de-gallo/crates/pico-de-gallo-internal
cargo hack --feature-powerset check
```
Expected: PASS. This specifically exercises `pico-de-gallo-internal` **without**
`use-std`, i.e. the `no_std` path that the firmware uses.

- [ ] **Step 3: Check the MSRV**

Run:
```bash
cd /home/balbi/workspace/pico-de-gallo/crates/pico-de-gallo-internal
cargo +1.90 check
```
Expected: PASS. `heapless` 0.9.3 declares `rust-version = "1.87"`, comfortably
under the repo's 1.90.

- [ ] **Step 4: Build both firmware revisions**

Both are published as release artifacts, so a preflight that only exercises the
default leaves the deprecated-but-still-published image untested.

Run:
```bash
cd /home/balbi/workspace/pico-de-gallo/crates/pico-de-gallo-firmware
cargo fmt --check
cargo clippy --target thumbv8m.main-none-eabihf -- -D warnings
cargo build --release --locked --target thumbv8m.main-none-eabihf
cargo clippy --target thumbv8m.main-none-eabihf \
    --no-default-features --features hw-rev1 -- -D warnings
cargo build --release --locked --target thumbv8m.main-none-eabihf \
    --no-default-features --features hw-rev1
cargo deny --manifest-path Cargo.toml check
```
Expected: all PASS.

- [ ] **Step 5: Build the docs**

Run:
```bash
cd /home/balbi/workspace/pico-de-gallo
RUSTDOCFLAGS="--cfg docsrs" cargo +nightly doc --workspace --no-deps --all-features 2>&1 | tail -20
mdbook build book 2>&1 | tail -5
```
Expected: both PASS, with **no** ambiguous-intra-doc-link warnings (the
`build_id` field and `build_id()` method share a name).

- [ ] **Step 6: Confirm no version was bumped**

Run:
```bash
cd /home/balbi/workspace/pico-de-gallo
git diff upstream/main --stat -- '*/Cargo.toml'
git diff upstream/main -- '*/Cargo.toml' | grep -E '^[-+]version' || echo "no version changes"
```
Expected: `no version changes`. The only `Cargo.toml` diff should be the
`heapless` dependency and the `postcard-schema` feature in
`pico-de-gallo-internal`.

- [ ] **Step 7: Confirm both lockfiles are in sync**

Run:
```bash
cd /home/balbi/workspace/pico-de-gallo
cargo check --workspace --locked && echo "host lock OK"
cd crates/pico-de-gallo-firmware
cargo check --locked --target thumbv8m.main-none-eabihf && echo "firmware lock OK"
```
Expected: both `OK`.

- [ ] **Step 8: Review the full diff**

Run:
```bash
cd /home/balbi/workspace/pico-de-gallo
git log --oneline upstream/main..HEAD
git diff upstream/main --stat
```
Expected: 8 commits (2 spec + 6 implementation) plus the docs commit. Confirm no
stray files, no `.pdg-always-rerun` file was created, and no generated header was
committed.

---

## Task 10: Hardware acceptance (manual, board required)

This is the issue's stated acceptance criterion. It **cannot** run in CI and
**must not** be skipped before claiming the issue is closed.

**Files:** none — verification only.

- [ ] **Step 1: Flash a clean build and record the identity**

```bash
cd /home/balbi/workspace/pico-de-gallo
git status --porcelain    # must be empty for a clean -dirty-free build
cd crates/pico-de-gallo-firmware
cargo build --release --locked --target thumbv8m.main-none-eabihf
```
Flash the resulting image, then:
```bash
cd /home/balbi/workspace/pico-de-gallo
cargo run -p gallo -- version
```
Record the `Build` value. Expected: `firmware-v0.11.0-N-g<hash>` with **no**
`-dirty`.

- [ ] **Step 2: Make a behaviour-only change and rebuild**

Edit any firmware handler in a way that changes behaviour but no wire type — for
example add a `defmt::info!` line to `crates/pico-de-gallo-firmware/src/handlers/info.rs`.
Do **not** commit it. Rebuild and reflash:
```bash
cd /home/balbi/workspace/pico-de-gallo/crates/pico-de-gallo-firmware
cargo build --release --locked --target thumbv8m.main-none-eabihf
```

- [ ] **Step 3: Verify the two builds are now distinguishable**

```bash
cd /home/balbi/workspace/pico-de-gallo
cargo run -p gallo -- version
```
Expected: the `Build` value now ends in `-dirty` and therefore **differs** from
Step 1, while `Firmware` and `Schema` are unchanged.

**This is the acceptance criterion.** Two images differing only in handler
behaviour now produce two distinguishable `device/info` responses, which is
precisely what `validate()` could not do.

- [ ] **Step 4: Verify the always-rerun trigger under incremental build**

This is the regression test for the staleness failure mode. Without Step 4 of
Task 1, this step reports a **stale** identity.

Revert the edit from Step 2, rebuild **without** cleaning, and re-check:
```bash
cd /home/balbi/workspace/pico-de-gallo
git checkout -- crates/pico-de-gallo-firmware/src/handlers/info.rs
cd crates/pico-de-gallo-firmware
cargo build --release --locked --target thumbv8m.main-none-eabihf
```
Reflash, then:
```bash
cd /home/balbi/workspace/pico-de-gallo
cargo run -p gallo -- version
```
Expected: the `-dirty` suffix is **gone** without a `cargo clean`. If it is
still present, the always-rerun trigger is not working.

- [ ] **Step 5: Verify the MCP surfaces**

With a board attached, confirm the `status` tool reports `build_id`, and that
the server log contains a `connected` line carrying `build_id`.

- [ ] **Step 6: Record the results in the PR body**

State which board, which two build IDs were observed, and that Step 4 passed
without a clean. Per AGENTS.md, behavioural claims about hardware require the
manual procedure, and CI is not evidence for them.

---

## Post-implementation notes for the PR body

Include these explicitly — reviewers need them and they are easy to forget:

1. **No version bumps.** This PR deliberately moves no `[package].version`
   (AGENTS.md §4 rule 12). The maintainer cuts the lockstep 0.8.0 release
   separately.
2. **Same-tree requirement.** Until that release, a host built from this tree
   cannot decode `device/info` from released firmware 0.11.0, and `validate()`
   cannot warn. Build both sides from the same tree.
3. **Zephyr impact.** `GalloDeviceInfo` grew a member at the end.
   `zephyr.yml` is path-filtered on `crates/pico-de-gallo-ffi/`, so confirm it
   actually ran, and note that a green run proves it compiles and links, not
   that behaviour is unchanged.
4. **Stale markers removed.** Two `SCHEMA FREEZE` comments were deleted because
   their bump has already shipped as `internal-v0.7.0`; leaving them beside a
   live marker caused a wrong conclusion during design.
5. **Known gap.** Nothing automated covers the `build.rs` git invocation or the
   firmware handler; both need real git and real registers. Task 10 is the only
   coverage, and it is manual.

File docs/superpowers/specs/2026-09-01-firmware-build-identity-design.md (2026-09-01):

# Firmware build identity in `device/info`

Design for issue [#159](https://github.com/OpenDevicePartnership/pico-de-gallo/issues/159).

Date: 2026-09-01
Status: approved, ready for implementation planning
Scope: `pico-de-gallo-internal`, `pico-de-gallo-firmware`, `pico-de-gallo-lib`,
`pico-de-gallo-app`, `pico-de-gallo-mcp`, `pico-de-gallo-ffi`, `pyco-de-gallo`, `book/`

---

## 1. Problem

`PicoDeGallo::validate()` gates on the schema version. Two firmware builds
reporting the **same** schema version can behave differently on the wire, because
`SCHEMA_VERSION_*` is derived from `pico-de-gallo-internal`'s `[package].version`
and therefore tracks **type** changes, not **behaviour** changes.

This has bitten twice, both recorded in AGENTS.md §13.17:

- **2026-08-26, `i2c/batch` atomicity.** Framing moved from per-operation
  START/STOP to a single `transaction()` call inside unchanged schema 0.7.
  AGENTS.md: *"schema-0.7 firmware built before this commit reports the same
  version but frames the bus differently."*
- **2026-08-26, zero-length I2C write guard.** The A/B verification session
  *"misidentified a flash during this very verification"*, and the recorded
  mitigation is *"track the flashed image yourself"*.

The second case is the motivating one: this is not a theoretical hazard. It
produced a wrong conclusion during a hardware verification session, and the
offered mitigation is not a mitigation.

Version numbers answer *"can we talk?"*. They cannot answer *"are you the build I
think you are?"*. That needs a separate field.

### 1.1 Non-goals

- Making build identity a compatibility gate. It is informational only (§6).
- Recording host-side build identity. Firmware only.
- Reproducible-build metadata beyond the git description. No timestamp.

---

## 2. Decisions

| # | Decision | Rationale |
|---|---|---|
| D1 | Carry the identity as `heapless::String<64>` appended to `DeviceInfo` | `postcard-schema` 0.2.5 ships a native `Schema` impl; `heapless` 0.9.3 is already in **both** lockfiles and is already a direct firmware dep, so no new major enters the graph |
| D2 | `git describe --always --dirty --tags --match firmware-v*` | Yields the tag on CI release builds, `tag-N-ghash` mid-branch, `-dirty` for a modified tree |
| D3 | Fall back to the literal `"unknown"`; the build always succeeds | A source tarball or shallow CI checkout must still build |
| D4 | `build.rs` re-runs on **every** build | A stale build ID is worse than none — it would have *confirmed* the 2026-08-26 misidentification |
| D5 | Inline `char build_id[65]` as the last member of `GalloDeviceInfo` | One call, no lifetime questions, mirrors the wire type; struct grows only at the end |
| D6 | Informational only; `validate()` never gates on it | Matches the issue framing; keeps the compatibility policy single-axis |
| D7 | No `[package].version` edits in this PR | AGENTS.md §4 rule 12: a version bump is a deliberate release commit, never a drive-by |
| D8 | `gallo version` renders via `tabled` | The crate already depends on `tabled` for `i2c scan`; `version` was the last hand-rolled `println!` block |
| D9 | `gallo list` is untouched | It makes zero RPCs today; adding one means opening every board, which is slow, per-board fallible, and re-enters the WinUSB single-claim hazard (AGENTS.md §13.17, 2026-07-20) |

---

## 3. Wire type — `pico-de-gallo-internal`

Append **one** field to the end of `DeviceInfo`. postcard encodes struct fields
positionally with no names, so appending is the only safe edit — identical to the
enum-variant rule in AGENTS.md §6.1.

```rust
/// Maximum length of [`DeviceInfo::build_id`], in bytes.
///
/// The field must always be spelled `heapless::String<BUILD_ID_CAPACITY>`,
/// leaving `LenT` at its default. `postcard-schema`'s `Schema` impl is
/// `impl<const N: usize> Schema for String<N>`, i.e. for the default `LenT`
/// only; naming a non-default `LenT` silently breaks the `Schema` derive.
pub const BUILD_ID_CAPACITY: usize = 64;

pub struct DeviceInfo {
    // ... existing nine fields, unchanged, in order ...

    /// Firmware build identity: the output of
    /// `git describe --always --dirty --tags --match firmware-v*` at firmware
    /// build time, or `"unknown"` when git was unavailable.
    ///
    /// Informational only. This is **never** a compatibility gate — see
    /// [`DeviceInfo::build_id()`] and `PicoDeGallo::validate()`.
    pub build_id: heapless::String<BUILD_ID_CAPACITY>,
}

impl DeviceInfo {
    /// The firmware build identity as a string slice.
    ///
    /// Provided so host crates never need to name `heapless` themselves.
    pub fn build_id(&self) -> &str {
        &self.build_id
    }
}
```

**Rustdoc disambiguation.** A public field `build_id` and an inherent method
`build_id()` coexist fine in Rust, but an intra-doc link written as
`[`DeviceInfo::build_id`]` is **ambiguous** and rustdoc emits a warning — which
CI turns into a failure via the `RUSTDOCFLAGS` doc job. Every intra-doc link to
the accessor must therefore be written with parentheses,
`[`DeviceInfo::build_id()`]`, and links to the field with the `field@`
disambiguator. This applies to every crate that documents the field, not just
`internal`.

### 3.1 Dependencies

Added to `crates/pico-de-gallo-internal/Cargo.toml`:

```toml
heapless = { version = "0.9", default-features = false, features = ["serde"] }
postcard-schema = { version = "0.2.5", features = ["derive", "heapless-v0_9"] }
```

Cost analysis:

- `heapless` 0.9.3 is already in the host `Cargo.lock` (via postcard-rpc) and in
  the firmware `Cargo.lock`, and is already a **direct** firmware dependency
  (`crates/pico-de-gallo-firmware/Cargo.toml`, `heapless = "0.9"`). No new major
  enters either graph.
- `heapless` 0.7.17 and 0.8.0 also exist transitively; `deny.toml` already
  documents the 0.7 situation. `bans.multiple-versions = "warn"` status is
  therefore unchanged by this work.
- `heapless` 0.9.3 declares `rust-version = "1.87"`, below the repo MSRV of 1.90.

### 3.2 Derives

`DeviceInfo` derives `Serialize, Deserialize, Schema, Debug, PartialEq`.
`heapless::String` satisfies all five, so **no derive changes are required**. In
particular `DeviceInfo` deliberately remains non-`Clone` and non-`Copy`.

### 3.3 No `use-std` split

Unlike the byte-payload response types, `build_id` uses one type on both sides.
This is possible because `heapless::String` is `no_std`-native and the host does
not need to grow the value.

### 3.4 Wire encoding

`heapless`'s `Serialize` impl is `serializer.serialize_str(self)`, so postcard
encodes the field as a **plain varint-length string**: one length byte for
anything under 128 bytes, then the UTF-8 payload. Neither `N` nor `LenT` appears
on the wire. An empty `build_id` therefore costs exactly one byte.

Consequences:

- `BUILD_ID_CAPACITY` is a *receive-side* bound only. Deserialization of a longer
  string fails with an `invalid_length` error rather than truncating, so the
  firmware must do the truncating (§4.1).
- Raising the capacity later is **not** a wire-format change; it only widens what
  a host will accept. It is still a `Schema` change and so still needs a bump.

---

## 4. Firmware

### 4.1 `build.rs`

`crates/pico-de-gallo-firmware/build.rs` already writes `$OUT_DIR/version.rs`
containing `VERSION_MAJOR/MINOR/PATCH`. Extend that generated file with:

```rust
pub(crate) const BUILD_ID: &str = "...";
```

Generation, via `std::process::Command` — **no shell is involved**, so
`firmware-v*` is passed through literally as its own argv entry and is never
glob-expanded:

```rust
Command::new("git")
    .args(["describe", "--always", "--dirty", "--tags", "--match", "firmware-v*"])
    .current_dir(env!("CARGO_MANIFEST_DIR"))
    .output()
```

Every flag is load-bearing. `build.rs` carries a comment saying so, because each
one has a specific silent-failure mode if removed:

| Flag | Consequence of removing it |
|---|---|
| `--tags` | The `firmware-v*` tags are a **mix** of annotated and lightweight. Without `--tags`, describe considers only annotated tags and resolves to `firmware-v0.10.0-302-g417739147e1c` — 302 commits wrong, with no error. |
| `--match firmware-v*` | Describe picks the nearest tag in **any** namespace. Measured on this tree: `application-v0.9.0-25-g417739147e1c`. |
| `--always` | Describe fails outright in a repo with no matching tag instead of falling back to a bare hash. |
| `--dirty` | Loses the locally-modified marker, which is the state a bisecting developer is in and the single most valuable part of this field. |

Measured on `417739147e1c` at design time:

```
git describe --always --dirty --tags                        -> application-v0.9.0-25-g417739147e1c
git describe --always --dirty --match firmware-v*           -> firmware-v0.10.0-302-g417739147e1c
git describe --always --dirty --tags --match firmware-v*    -> firmware-v0.11.0-25-g417739147e1c
```

**Fallback.** If `git` is absent, exits non-zero, or there is no `.git`, emit the
literal `"unknown"` and additionally emit a `cargo:warning` so the degradation is
visible rather than silent. The build succeeds either way.

**Truncation.** `build.rs` truncates to `BUILD_ID_CAPACITY` bytes on a `char`
boundary. git describe output is ASCII in practice, but a tag name can legally
carry UTF-8, and a byte-index slice would panic mid-codepoint.

**Always re-run (D4).** The existing `cargo:rerun-if-changed=memory.x` *narrows*
re-runs to that single file, so after a commit — or after editing a handler —
cargo rebuilds the crate but does not re-run `build.rs`, and the embedded ID
would keep reporting the previous commit with no `-dirty` marker. That is the
exact misidentification this field exists to prevent. Therefore:

```rust
// Force build.rs to re-run on EVERY build. Cargo treats a nonexistent path as
// always-changed. This is deliberate and load-bearing: without it the embedded
// BUILD_ID goes stale across incremental builds and reports a clean tree for a
// dirty one, which is precisely the misidentification this field exists to
// prevent (issue #159, AGENTS.md §13.17 2026-08-26). Cost is one `git describe`
// (~5 ms) per build. Do not "optimise" this away.
println!("cargo:rerun-if-changed=.pdg-always-rerun");
```

Cargo resolves that path relative to the package root, i.e.
`crates/pico-de-gallo-firmware/.pdg-always-rerun`. The file **must not exist**
and must not be created; a `.gitignore` entry is unnecessary and would only
invite someone to create it.

The existing `rerun-if-changed=memory.x` line stays: it is harmless once an
always-rerun trigger is present, and it documents the real dependency.

### 4.2 Bound enforcement

The firmware carries a compile-time assertion:

```rust
const _: () = assert!(BUILD_ID.len() <= BUILD_ID_CAPACITY);
```

so a capacity mistake is a build failure rather than a runtime
`unwrap_or_default()` that silently reports an empty string.

### 4.3 Handler

`handlers/info.rs::device_info_handler` stays synchronous and infallible. It adds
one field:

```rust
build_id: heapless::String::try_from(BUILD_ID).unwrap_or_default(),
```

The `unwrap_or_default()` is unreachable given §4.2, but keeps the handler
panic-free. `main.rs` registers this handler as `blocking`, and postcard-rpc
dispatches handlers serially on a shared context, so a panic here takes the whole
dispatcher with it.

### 4.4 Boot log

`main()` logs the identity once at boot, beside the existing `hw-rev1`
deprecation warning:

```rust
defmt::info!("build {}", BUILD_ID);
```

`BUILD_ID` is a `&'static str`, so this needs no `heapless/defmt` feature.

---

## 5. Host surfaces

### 5.1 `pico-de-gallo-lib`

No structural change. `DeviceInfo` is re-exported verbatim, so the field arrives
on both call paths — `device_info()` (unbounded, unvalidated) and `validate()`
(bounded by `DEVICE_INFO_TIMEOUT`, schema-checked).

`check_schema_compatible` is **not** touched (D6).

`validate()`'s rustdoc gains a pointer to `DeviceInfo::build_id()`. That doc
already warns that a matching schema version is not proof of matching behaviour;
`build_id` is the field that closes the gap it describes.

### 5.2 `gallo` CLI

`version` is rebuilt on `tabled`, following the `i2c_scan` idiom exactly
(`Builder` → `build()` → `Style::rounded()`), so the crate has one table idiom:

```
╭─────────────┬─────────────────────────────────────────╮
│ Firmware    │ v0.11.0                                 │
│ Schema      │ v0.7.0                                  │
│ HW revision │ 2                                       │
│ GPIOs       │ 4                                       │
│ Build       │ firmware-v0.11.0-25-g417739147e1c-dirty │
╰─────────────┴─────────────────────────────────────────╯
╭─────┬─────┬──────┬──────┬─────┬─────┬────────╮
│ I2C │ SPI │ UART │ GPIO │ PWM │ ADC │ 1-Wire │
├─────┼─────┼──────┼──────┼─────┼─────┼────────┤
│ ✓   │ ✓   │ ✓    │ ✓    │ ✓   │ ✓   │ ✓      │
╰─────┴─────┴──────┴──────┴─────┴─────┴────────╯
```

Two tables, not one: capabilities are a wide boolean row, and packing seven ✓/✗
into a single value cell is what the current `println!` already does badly.

- **`GPIOs` is new output.** `num_gpios` is on the wire type and on the Python
  class but has never been printed by the CLI. Including it is coherent with
  rebuilding this block.
- **`Build` is last**, mirroring `build_id` being the last wire field and the
  last `GalloDeviceInfo` member.
- **The legacy-firmware fallback keeps plain `println!`.** That branch has only a
  version number and one explanatory sentence, and exists for firmware too old to
  have `device/info` at all.
- `tabled` is already a dependency, so there is no `Cargo.toml` or lockfile churn.

`list` is untouched (D9).

### 5.3 `gallo-mcp`

- `device_info` tool: free — it already serializes the whole wire struct.
- `StatusResult` gains `build_id: Option<String>`, filled from the **cached**
  `dev.info()` next to `firmware_version`. No extra RPC.
- One `tracing` line on connect carrying serial, firmware version, and build ID,
  so an agent-driven session has it in the transcript. This is the specific
  ask in the issue.

### 5.4 `pico-de-gallo-ffi`

`GalloDeviceInfo` gains `char build_id[65]` as its **last** member,
NUL-terminated, written by `gallo_get_device_info`.

- Growing only at the end means the layout change affects only consumers who
  recompile. `zephyr/` recompiles in-tree, and `zephyr.yml` is path-filtered to
  include `crates/pico-de-gallo-ffi/`, so the gate will run.
- `GalloDeviceInfo` survives cbindgen pruning today only because
  `gallo_get_device_info`'s signature references it (AGENTS.md §8). That is
  unchanged, so `cbindgen.toml` needs no edit.
- The `65` must be written as a **literal**, because cbindgen folds const
  initializers syntactically and silently emits nothing for a computed value.
  A `const` assertion ties it to `BUILD_ID_CAPACITY + 1`, following the
  `GALLO_NUM_GPIOS` precedent.
- No new `Status` code. Status values are stable C ABI, and C consumers are told
  to write an exhaustive `switch ((enum Status)x)` with no `default:`
  (AGENTS.md §8), so a new value would fall through.

### 5.5 `pyco-de-gallo`

`DeviceInfo` gains `build_id: String` with `#[pyo3(get)]`, converted in the
existing `From<LibDeviceInfo>` impl. It is only ever returned, never taken as an
argument, so no `Clone` / `from_py_object` is needed.

---

## 6. Compatibility policy

`build_id` is **informational and never a gate**.

`validate()` continues to compare schema major and minor only. A host that wants
to assert it is talking to a specific image reads `DeviceInfo::build_id()` and
decides for itself. No new `ValidateError` variant, no new FFI `Status` value, no
new policy surface in any binding.

This is the issue's own framing: version numbers answer *"can we talk?"*,
`build_id` answers *"are you the build I think you are?"*, and only the former is
a gate.

---

## 7. Versioning

**No `[package].version` is edited by this change** (D7).

### 7.1 Why the issue's Notes are not followed literally

The issue says *"schema bump, lockstep version bumps across all eight released
crates, both `Cargo.lock`s"*. That describes the **release commit**, not the
feature commit. AGENTS.md §4 rule 12 is unconditional: a version bump is a
deliberate, manual release step, never a drive-by edit in a feature PR.

The established two-step is visible in the tree: a feature PR lands the wire
change and leaves a `SCHEMA FREEZE` marker; the maintainer's later release commit
performs the lockstep bump across all eight crates, rewrites every cross-crate
dep spec, hand-writes the CHANGELOGs, and regenerates both lockfiles.

### 7.2 Stale markers to delete

`pico-de-gallo-internal/src/lib.rs` carries two `SCHEMA FREEZE` comments, at
`:433` (`SpiError`) and `:1583` (`DeviceInfo`), both saying *"Do not release or
tag this branch until the maintainer performs the lockstep version bump."*

**Both are stale.** Verified at design time:

- `internal-v0.7.0` is tagged, and that tag's `lib.rs` already contains
  `num_gpios: u8` and the appended `SpiError` variants.
- `git show internal-v0.7.0:crates/pico-de-gallo-internal/Cargo.toml` reads
  `version = "0.7.0"`.
- `firmware-v0.11.0` is tagged.

The bump those markers demanded **has been performed**; nobody removed them at
release. Delete both. Leaving false markers beside a live one destroys the
signal — during this very design session they caused an incorrect recommendation
that schema 0.7 was still unreleased. This cleanup is in scope precisely because
the change depends on that mechanism being readable.

### 7.3 New marker

Add a fresh `SCHEMA FREEZE` marker on `build_id` recording that:

- the addition is append-only but still requires a lockstep bump per §6.2;
- the next release of `pico-de-gallo-internal` must therefore be **0.8.0**, not
  0.7.1 — a new wire field is not a patch;
- the branch must not be released or tagged until that bump is performed.

### 7.4 CHANGELOGs

Each affected crate gets an entry under a new `## [Unreleased]` heading, which is
the Keep a Changelog answer for "landed, not yet versioned". There is no root
`CHANGELOG.md`.

---

## 8. Risks and accepted limitations

| # | Risk | Disposition |
|---|---|---|
| R1 | A **new host** talking to **released firmware 0.11.0** never gets a `device/info` answer at all. Appending `build_id` changed `DeviceInfo`'s schema, and postcard-rpc derives each endpoint's key from the response type's schema (`Key::for_path::<T>(path)`, `RESP_KEY` in the `endpoints!` macro), so the endpoint is silently re-keyed. The firmware replies under the old key, the new host's dispatcher finds no match, drops the frame, and never wakes the pending call. `validate()` cannot warn, because both sides still report schema 0.7. | **Accepted and unavoidable** for any shape change to an already-released type — this is broader than appends. It is **not** a decode error: postcard is never reached, so `map_validate_error` never sees `DeserFailed`. `validate()` surfaces it as `ValidateError::Timeout` after the full `DEVICE_INFO_TIMEOUT` (300 s), misattributed to an unresponsive board; the host cannot distinguish the two, and the remediation text now says so. `gallo version` bounds its `device/info` call at 5 s and falls back to the legacy `version` endpoint, whose `VersionInfo` schema — and therefore key — is unchanged. `device_info_response_key_is_pinned` in `pico-de-gallo-internal` now makes any future re-key a test failure instead of a field hang. Host and firmware must be built from the same tree until the 0.8.0 release. Stated in the PR body and the CHANGELOG entries. |
| R2 | `GalloDeviceInfo` layout change breaks C consumers that do not recompile. | Accepted. The struct grows only at the end; every released crate bumps in lockstep at release; `zephyr/` recompiles in-tree and `zephyr.yml` covers the FFI path filter. |
| R3 | Always-rerunning `build.rs` costs one `git describe` per firmware build. | Accepted, ~5 ms. The alternative (tracking `.git/HEAD`, refs and index) misses unstaged `.rs` edits, which reintroduces the exact stale-ID failure. |
| R4 | No automated test covers the `build.rs` git invocation or the firmware handler. | **Honest gap.** The git invocation is not unit-testable in-tree and the handler needs real registers. Covered only by the manual acceptance procedure in §9.2. |
| R5 | Spelling the field with a non-default `LenT` silently breaks the `Schema` derive, since `postcard-schema` only impls `Schema for String<N>` at the default. | Guarded by the doc comment on `BUILD_ID_CAPACITY` (§3) and by the `Schema` derive failing to compile if violated. `LenT` has no wire effect (§3.4). |
| R6 | `git describe` in a shallow CI clone may not reach a `firmware-v*` tag, yielding a bare hash. | Acceptable — `--always` still gives a usable identity. Release workflows should fetch tags; noted in §9.1. |
| R7 | The field `build_id` and the accessor `build_id()` share a name, making bare intra-doc links ambiguous and failing the `RUSTDOCFLAGS` doc job. | Guarded by convention: always write `[`DeviceInfo::build_id()`]` for the method and the `field@` disambiguator for the field (§3). |

---

## 9. Testing

### 9.1 Automated

| Layer | Test |
|---|---|
| `internal` | `device_info_round_trip_carries_build_id` — postcard round-trip with a full 64-char ID, an empty ID, and `"unknown"`. `device_info_encodes_fields_in_declared_order` is **extended** to pin the new byte image, since it currently asserts an exact 9-byte encoding and will fail loudly otherwise. `device_info_rejects_overlong_build_id` asserts that decoding a 65-byte string errors rather than truncating (§3.4). |
| `lib` | Extend the fake-transport `make_device_info` helper with a build ID. Assert `validate()` **succeeds** on an unexpected build ID, pinning D6. |
| `app` | Snapshot the two-table `version` output for a fixed `DeviceInfo`, so the `tabled` formatting is covered rather than eyeballed. |
| `ffi` | `build_id` is NUL-terminated; a full 64-char ID does not overflow `char[65]`; the `const` assert ties `65` to `BUILD_ID_CAPACITY + 1`. |
| `pyco` | Sibling of `device_info_conversion_carries_num_gpios` covering `build_id`. |
| `mcp` | `StatusResult` serializes `build_id`; it is absent when not connected. |
| firmware | None — see R4. |

Release workflows that build firmware must fetch tags (`fetch-depth: 0` or an
explicit tag fetch), or `git describe` degrades to a bare hash (R6).

### 9.2 Manual acceptance (board-attached, not CI)

From the issue: flash two firmware images built from commits that differ only in
handler behaviour, and confirm `gallo version` reports two **different** `Build`
values. Additionally confirm that editing a source file without committing
produces a `-dirty` suffix on the next build, which is the D4 regression test.

---

## 10. Documentation

Per AGENTS.md §15.1 book-parity, in the same PR:

| File | Change |
|---|---|
| `book/src/internals/wire-protocol.md` | New `DeviceInfo` field; the "informational, never a gate" ruling; the R1 same-tree caveat |
| `book/src/appendix/endpoints.md` | `device/info` row wording gains build identity |
| `book/src/getting-started/verify.md` | The `gallo version` sample output block — **currently stale** at `FW v0.8.0` / `Schema v0.4.0`, and now also the wrong format. Replace with the two-table output and extend the field-meanings table. |
| `book/src/internals/firmware.md` | `build.rs` behaviour, the four load-bearing git flags, and the always-rerun rationale |
| `book/src/crates/{lib,ffi,mcp,python}.md` | New field on each surface |
| `crates/pico-de-gallo-mcp/README.md` | `status` gains `build_id`; connect-time log line |
| `AGENTS.md` §13.17 | A row recording that this closes the documented misidentification class |

---

## 11. Out of scope

- Host-side (CLI / library) build identity.
- Any expected-build-id assertion API. Explicitly rejected in favour of D6;
  callers can compare `build_id()` themselves.
- `gallo list` build-ID column (D9).
- The lockstep 0.8.0 release itself (§7).

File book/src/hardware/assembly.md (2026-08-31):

# Assembly & Flashing

Getting a working Pico de Gallo on your desk takes two steps:

1. **Get a populated PCB.**
2. **Flash the firmware.**

Step 1 has three options, ordered from easiest to most hands-on.
Step 2 is the same regardless of how you got the board.

## Step 1: Get a Populated PCB

### Option A — Have the PCB house assemble it

Most modern PCB fabrication services (JLCPCB, PCBWay, OSH Park
with their assembly partners, Aisler, etc.) will both fabricate
**and assemble** the board for you. Upload the gerbers, BOM, and
pick-and-place files from the
[`hardware-v*`](https://github.com/OpenDevicePartnership/pico-de-gallo/releases)
release, choose your solder mask color, and a fully-built board
arrives at your door. This is the recommended path — it's cheap
at small quantities, and your time is worth more than the
assembly fee.

> [!NOTE]
>
> Pico de Gallo PCB assembly is not affiliated with any specific
> PCB house. Any cost, mistake, or damage associated with PCB
> fabrication and assembly is your responsibility.

### Option B — Fabricate bare, solder yourself

If you'd rather solder, the board uses through-hole and
medium-pitch components only — there's nothing exotic.

**Order of operations:**

1. **Solder the Pico 2 first.** It's the lowest component on the
   board. Tack one corner pad, check alignment, tack the opposite
   corner, then run a bead along all remaining pads. A bit of
   no-clean flux makes this much easier — solder follows flux onto
   exposed copper.
2. **Right-angle headers next.** Hold them in place with a piece
   of polyimide ("Kapton") tape or a third hand, tack one pin,
   verify the header sits flush, then solder the rest.
3. **Straight headers last.** Same approach — one pin first, check
   alignment, finish the rest.
4. **Clean off the flux** with 99% IPA and an ESD-safe brush in a
   well-ventilated area.

> [!CAUTION]
>
> Isopropyl alcohol is flammable. Don't smoke or have open flames
> near it. Use it in a well-ventilated area.

After cleanup, eyeball the board for solder bridges between
adjacent pins before applying USB power.

### Option C — Skip the PCB, wire a bare Pico 2

The firmware works on a bare Pico 2 too. Wire your peripherals
directly to the RP2350 GPIOs listed in [Pinout &
Connector](./pinout.md). You'll need to provide your own I²C
pull-ups (4.7 kΩ to 3.3 V on SDA and SCL) if you want I²C to work.

## Step 2: Flash the Firmware

The Pico 2 ships with a built-in UF2 bootloader, so you don't need
a programmer, a debug probe, or any extra software. Just a USB
cable.

1. Download the latest `firmware.uf2` from the
   [Releases](https://github.com/OpenDevicePartnership/pico-de-gallo/releases)
   page (look for a tag like `firmware-v0.8.0`). Pick the build
   that matches your board revision:
   - `firmware-rev2.uf2` for the v1.1 board — this is the default
   - `firmware-rev1.uf2` for the v1.0 board — `hw-rev1` is
     [deprecated](./revisions.md#hw-rev1-is-deprecated) but still
     built and published; removal not before 2031-09-01
2. With the Pico 2 **unplugged**, press and **hold** the `BOOTSEL`
   button on top of the module.
3. Plug the USB cable in while still holding `BOOTSEL`, then
   release.
4. A USB mass-storage drive named `RP2350` appears on your host.
5. Drag-and-drop the `firmware.uf2` onto that drive (or
   `cp`/`Copy-Item` from a shell).
6. The drive vanishes; the Pico 2 reboots into the new firmware
   automatically.

That's it — no command-line flashing tool required.

> [!TIP]
>
> If the `RP2350` drive doesn't show up, the Pico 2 didn't enter
> bootloader mode. Unplug, hold `BOOTSEL`, plug back in. Don't
> release `BOOTSEL` until you see the drive.

## Step 3: Verify

Confirm the firmware is alive by running `gallo version`. See
[Verifying Your Device](../getting-started/verify.md) for the
expected output and what each field means.

## When Things Go Wrong

- **Drive doesn't appear in BOOTSEL mode** — try a different USB
  cable (some "charge-only" cables don't carry data) or a
  different USB port.
- **`gallo` can't find the device after flashing** — on Linux you
  may need a udev rule; on Windows the WinUSB driver may need to
  be installed via Zadig. See
  [USB & OS Notes](../getting-started/usb.md).
- **You flashed `hw-rev1` onto a v1.1 board (or vice versa)** —
  no damage done; just re-enter BOOTSEL and flash the right
  build.

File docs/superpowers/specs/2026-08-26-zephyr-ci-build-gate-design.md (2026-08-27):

# Zephyr CI build gate — design

- **Date:** 2026-08-26
- **Issue:** [#130](https://github.com/OpenDevicePartnership/pico-de-gallo/issues/130) — *ci: No CI job builds or lints the Zephyr module*
- **Related:** #98 (upstreaming tracker), #109 (twister metadata and hardware-free
  unit tests), #131 (the human-review half, landed in #144 as `bf06fc9`)
- **Status:** approved, pending implementation

---

## 1. Problem

Nothing in CI builds, compiles or lints `zephyr/`. `rg -ln zephyr .github/workflows/`
returns nothing. `check.yml` covers the seven host crates, `nostd.yml` covers the
firmware for both hardware revisions, `gh-pages.yml` builds the book. The Zephyr
module — five drivers, four samples, four test applications, four devicetree
bindings and a shield — has no gate at all.

This matters more than an ordinary coverage gap because the Zephyr drivers are a
**consumer of `pico-de-gallo-ffi`**. They call `gallo_*` through the cbindgen-generated
`pico_de_gallo.h`, linked by Corrosion at Zephyr build time. An FFI change can
therefore break `zephyr/` while every existing gate stays green:

- `check.yml` builds the FFI crate, which still compiles.
- cbindgen regenerates the header without complaint.
- The Zephyr translation unit that consumed the removed or renamed symbol is
  never compiled by anyone.

AGENTS.md §15.1 already states the consequence outright: the module's two
compile-time safety mechanisms "only fire when a human runs a Zephyr build by
hand."

Those two mechanisms are real and currently dormant:

- `zephyr/drivers/common/common.c` maps every FFI `Status` to an `errno` in a
  switch with no `default:` inside it, compiled under `-Werror=switch`
  (`zephyr/drivers/CMakeLists.txt:34`). A new `Status` variant is a build failure.
- `zephyr/tests/pdg_mfd_m5/common/m5_bottom.c:37-51` carries eight
  `_Static_assert`s pinning `GalloGpioEdge`, `GalloGpioDirection` and
  `GalloGpioPull` to the wire-enum variant order, which is itself ABI (§6.1). A
  reordered wire enum is a build failure.

Neither has ever fired in CI, because CI has never compiled them.

## 2. Scope

### 2.1 In scope

A single GitHub Actions workflow that **builds** the Zephyr module against a
pinned upstream Zephyr revision on `native_sim/native/64`, and asserts per-target
outcomes including non-vacuity.

### 2.2 Explicitly out of scope — this gate is BUILD ONLY

The workflow never executes a produced binary. No `west build -t run`, no direct
launch of `zephyr.exe`, no invocation of `zephyr/tests/pdg_mfd_m5/run-m5.sh`, no
twister run. GitHub-hosted runners have no USB and no attached board.

This is safe, and the safety is a property of the code rather than of the
workflow's good manners. Per
`docs/superpowers/specs/2026-08-17-zephyr-mfd-m1-parent.md:236-240`:

> No build path reaches `gallo_init_strict()`. Configure invokes only
> `rustc --version --verbose`; Corrosion compiles and cbindgen generates; linking
> merely resolves the call compiled into `gallo_registry.c`. USB opens only when
> the native_sim process starts. Builds are safe; produced binaries must never run
> (no direct launch, `west build -t run`, test runner, or hardware command).

`gallo_init_strict()` is called from `zephyr/drivers/common/gallo_registry.c:174`,
reached only at runtime. Linking resolves the symbol; it never calls it.

### 2.3 What the gate does and does not catch

| Regression class | Caught | Mechanism |
|---|---|---|
| `gallo_*` renamed or removed | yes | undefined reference at the native_simulator runner link |
| `gallo_*` signature changed | yes | compile error at the call site |
| New FFI `Status` variant | yes | `-Werror=switch` in `common.c` |
| Reordered wire enum | yes | `_Static_assert` in `m5_bottom.c` (M5 targets only) |
| DT binding, Kconfig or shield breakage | yes | configure or devicetree error |
| `Cargo.lock` out of sync with `Cargo.toml` | yes | `corrosion_import_crate(... LOCKED)` |
| Wire or firmware **behaviour** change | **no** | needs attached hardware |
| Anything `run-m5.sh` verifies | **no** | needs attached hardware and physical jumpers |

Issue #130's claim that "compile coverage alone would have caught both prior
regressions" is not adopted here. The AGENTS.md §13.17 rows dated 2026-08-17 and
2026-08-19 record wire and firmware **behaviour** defects found on hardware; a
compile gate would not have caught either. This spec claims the narrower thing
that is true: the gate closes the FFI/link-surface hole, and hardware coverage
remains a separate, manual procedure.

## 3. Decisions

### D1 — Pin Zephyr to `26f811ee9d0dc8f67e8e596f6aef9e6e79a55db0`

`zephyr/README.md:26` records the measured build environment as `main` at
`v4.4.0-6123-g26f811ee9d0`. The `git describe` form in
`docs/superpowers/specs/2026-08-17-zephyr-mfd-m1-parent.md:242` is
`v4.4.0-6123-g26f811ee9d0d`; the README truncates the abbreviated SHA by one
character. The full commit is
`26f811ee9d0dc8f67e8e596f6aef9e6e79a55db0`, committed 2026-06-24, verified present
upstream.

Pinning to that exact revision is chosen over any newer commit because it is the
only revision this module has ever been measured against. Selecting a newer one
would assert an untested compatibility claim. The README's own framing — "treat
`main` as the verified baseline rather than an asserted minimum" — is honestly
encoded by pinning the measured commit rather than by tracking a moving branch.

Pin rot is the accepted cost. A non-blocking scheduled job tracking Zephyr `main`
was considered and deferred (§8).

### D2 — One job driving a checked-in helper script

Rejected: a matrix over the eight build targets. It matches house style more
closely (`check.yml` and `nostd.yml` both matrix heavily) and yields eight
independent checks, but every leg re-restores a multi-gigabyte west workspace
cache and re-runs Corrosion's `PROFILE release` build of `pico-de-gallo-ffi`.

Chosen: one `ubuntu-latest` job that performs workspace setup once and then runs
`zephyr/scripts/ci-build.sh`, which builds all eight targets sequentially and
writes a per-target result table to `$GITHUB_STEP_SUMMARY`. Per-target attribution
is recovered from the summary table and `::group::` log folding.

The script is checked in rather than inlined in YAML for three reasons: the
assertion logic in §5 is intricate enough that it needs to be readable and
greppable; a maintainer with a Zephyr environment can run the whole gate by hand
with one command; and the repository has no local Zephyr environment, so a
hand-runnable artifact is the only practical escape hatch for reproducing a CI
failure.

### D3 — Eight build targets; the fifth M5 image is excluded

The four samples and the four M5 test applications are built. The fifth M5 image,
`spi_loopback`, is deliberately excluded.

`spi_loopback` builds the **upstream** suite at
`$ZEPHYR_BASE/tests/drivers/spi/spi_loopback` with this repository's overlay and
config fragments, and additionally requires `/tmp/m5-measured.conf`, which
`zephyr/tests/pdg_mfd_m5/run-m5.sh:537` synthesises from a live hardware timing
measurement. A build-only gate would have to fabricate that value.

Its marginal value for this issue is nil: it links the same
`pdg_spi.c`, `pdg_spi_bottom.c`, `common.c` and `gallo_registry.c` as the
`m5_acceptance` target, so it adds no `gallo_*` call site that target 7 does not
already cover. What it does add is upstream Zephyr API-surface coverage, which is
not what #130 is about, plus a dependency on an upstream source path and a
fabricated config value.

### D4 — Every pass target asserts non-vacuity

A green build proves nothing if the shield overlay silently left every
`CONFIG_*_PICO_DE_GALLO` disabled: the sample would compile with zero of this
module's translation units and pass forever, including under mutation.
`2026-08-17-zephyr-mfd-m1-parent.md` §6.2 flags the same hazard, requiring an
enabling overlay to "prove any otherwise-disabled translation unit is compiled."

Each pass target therefore additionally asserts the artefacts listed in §5.1.
Without this, the mutation check in §7.2 could pass for the wrong reason.

### D5 — Baseline failures are attributed by node, not by ordinal

`2026-08-17-zephyr-mfd-m1-parent.md` §6.2 is explicit:

> Baseline symbols were `__device_dts_ord_43` and `__device_dts_ord_44`, but the
> new shield node may renumber ordinals. Compare per sample by the same single
> undefined symbol's attribution, never by literal integer or cross-sample
> identity.

The assertion in §5.2 resolves the ordinal from the generated devicetree header at
build time and compares against the undefined symbol, so it is correct under
renumbering.

### D6 — The workflow and README SHA agreement is enforced, not promised

Issue #130's acceptance criterion 2 requires that the pinned revision be recorded
in both the workflow and `zephyr/README.md`, and that the two agree. A step greps
`zephyr/README.md` for the literal pinned SHA held in the workflow's `env:` and
fails if it is absent. The criterion becomes a test.

### D7 — Path-filtered triggers, with a required-check caveat

Triggers are `push` to `main` and `pull_request`, both filtered on `zephyr/**`,
`crates/pico-de-gallo-ffi/**`, `crates/pico-de-gallo-internal/**`, `Cargo.lock`,
`Cargo.toml` and `.github/workflows/zephyr.yml`.

`Cargo.lock` is in the list because `zephyr/CMakeLists.txt` imports the crate with
`corrosion_import_crate(... LOCKED)`, so a manifest/lock split breaks the Zephyr
build as well as `check.yml`'s `lockfile` job.

**Caveat, recorded deliberately:** a path-filtered workflow reports as *skipped* on
unrelated pull requests. If this job is later configured as a required status
check, GitHub will block merges on the skipped result unless a companion no-op job
is added. That configuration choice belongs to the maintainer and is not made here.

## 4. Target inventory

All builds use `-p always`, board `native_sim/native/64`, `-DSHIELD=pico_de_gallo`,
an absolute `-DEXTRA_ZEPHYR_MODULES=<repo root>`, and a build directory under
`/tmp`. Repository-root `build/` is not gitignored (only `zephyr/build/` is), so
build directories must never land in the tree.

The M5 applications use named overlays rather than `app.overlay`, so west does not
apply them automatically; each is passed explicitly via `-DDTC_OVERLAY_FILE`. The
command forms below follow
`docs/superpowers/specs/2026-08-19-zephyr-mfd-m5-acceptance.md:562-566` verbatim.

| # | Target | Source directory | Overlay | Expected |
|---|---|---|---|---|
| 1 | `i2c_bridge` | `zephyr/samples/i2c_bridge` | automatic (`app.overlay`) | pass |
| 2 | `spi_nor_id` | `zephyr/samples/spi_nor_id` | automatic | pass |
| 3 | `spi_bridge` | `zephyr/samples/spi_bridge` | automatic | baseline-fail |
| 4 | `combined_i2c_spi_bridge` | `zephyr/samples/combined_i2c_spi_bridge` | automatic | baseline-fail |
| 5 | `m5_reset` | `zephyr/tests/pdg_mfd_m5/reset_subscriptions` | `reset.overlay` | pass |
| 6 | `m5_jumper` | `zephyr/tests/pdg_mfd_m5/jumper_preflight` | `jumper.overlay` | pass |
| 7 | `m5_acceptance` | `zephyr/tests/pdg_mfd_m5/acceptance` | `acceptance.overlay` | pass |
| 8 | `m5_teardown` | `zephyr/tests/pdg_mfd_m5/recovery_teardown` | `recovery.overlay` | pass |

Targets 3 and 4 fail because they instantiate an `is31fl3743b@0` node whose
`issi,is31fl3743b` driver is not in Zephyr `main`; only `is31fl319x`,
`is31fl3216a` and `is31fl3733` are upstream. `zephyr/README.md` documents this.
That compatible string appears in exactly two files in the repository, both
`app.overlay` files of targets 3 and 4.

### 4.1 Expected translation units per target

Derived from each target's overlay, which decides the `DT_HAS_*_ENABLED` Kconfig
defaults. Used by the §5.1 non-vacuity assertion.

| Target | Zephyr-side objects | native_simulator-side objects |
|---|---|---|
| 1 `i2c_bridge` | `pdg_mfd`, `pdg_i2c` | `common`, `gallo_registry`, `pdg_i2c_bottom` |
| 2 `spi_nor_id` | `pdg_mfd`, `pdg_gpio`, `pdg_spi` | `common`, `gallo_registry`, `pdg_gpio_bottom`, `pdg_spi_bottom` |
| 5 `m5_reset` | `pdg_mfd` | `common`, `gallo_registry`, `m5_bottom` |
| 6 `m5_jumper` | `pdg_mfd`, `pdg_gpio` | `common`, `gallo_registry`, `pdg_gpio_bottom` |
| 7 `m5_acceptance` | `pdg_mfd`, `pdg_gpio`, `pdg_spi` | `common`, `gallo_registry`, `pdg_gpio_bottom`, `pdg_spi_bottom`, `m5_bottom` |
| 8 `m5_teardown` | `pdg_mfd`, `pdg_gpio`, `pdg_spi` | `common`, `gallo_registry`, `pdg_gpio_bottom`, `pdg_spi_bottom`, `m5_bottom` |

Target 6 deliberately does not link `m5_bottom.c`; its `CMakeLists.txt` says so
explicitly ("This image uses only the Zephyr GPIO API. It needs no host-context
shim"). Target 5 sets `CONFIG_GPIO=n` and `CONFIG_SPI=n` in `prj.conf`.

The two halves are detected by different means, following M4's measured
practice. Zephyr-side translation units appear in the build's
`compile_commands.json`; native_simulator-side units do not, because the runner
is a separate sub-build, so those are located as object files. Object-file
suffix is matched tolerantly (`.o` or `.obj`) because it varies by generator and
platform.

## 5. Assertion contracts

All four mechanisms below are taken from
`docs/superpowers/specs/2026-08-19-zephyr-mfd-m4-acceptance.md` (checks A-01,
A-08 and A-11) and `2026-08-17-zephyr-mfd-m3-gpio-tests.md` §"Ordinal
resolution". They are reused verbatim rather than reinvented, because they were
executed against real builds of this module and this design cannot be executed
locally before merge.

### 5.1 Pass targets (1, 2, 5, 6, 7, 8)

1. `west build` exits zero.
2. `libpico_de_gallo_ffi.a` exists under the build directory — proves Corrosion
   built the crate and cbindgen generated the header.
3. `grep -o 'pdg_[a-z0-9_]*\.c' <build>/compile_commands.json | sort -u` contains
   every Zephyr-side translation unit in the target's §4.1 row, and contains
   none of the other three driver translation units. This is M4 A-01's
   mechanism.
4. Every native_simulator-side object in the §4.1 row is found under the build
   directory by name — this is the half that actually calls `gallo_*`. M4 A-08
   locates the same objects this way.
5. `<build>/zephyr/.config` contains `CONFIG_MFD_PICO_DE_GALLO=y` plus the
   `CONFIG_{GPIO,I2C,SPI}_PICO_DE_GALLO=y` entries implied by the target's §4.1
   row. A Kconfig symbol silently dropping to `n` is the precise mechanism by
   which a vacuous pass would occur, so it is asserted directly rather than
   inferred from the compiled set.

Assertion 3 is deliberately two-sided rather than a plain containment check: a
target that compiles *more* drivers than its overlay enables signals a broken
overlay just as much as one that compiles fewer.

It is scoped to the four driver translation units — `pdg_mfd.c`, `pdg_gpio.c`,
`pdg_i2c.c`, `pdg_spi.c` — rather than asserted as whole-file set equality,
because M4 A-01 recorded only that `compile_commands.json` *contains* those
names. It did not establish whether the native_simulator sub-build contributes
its own `pdg_*_bottom.c` entries to the same file. Asserting equality over every
`pdg_*.c` match would therefore encode an unverified assumption about the
sub-build's layout, and would fail for a reason unrelated to the property under
test. Assertion 4 covers the bottom half independently and by a different
mechanism.

### 5.2 Baseline-failure targets (3, 4)

1. `west build` exits **non-zero**. A zero exit is a failure of this gate: it means
   the IS31FL3743B driver reached upstream Zephyr and this branch of the script,
   plus `zephyr/README.md`, must be revisited.
2. `<build>/zephyr/zephyr.elf` exists — proves the failure is at the
   native_simulator runner link producing `zephyr.exe`, not earlier.
3. The build log contains exactly one distinct undefined `__device_dts_ord_N`
   symbol.
4. `N` equals the ordinal resolved for the `is31fl3743b@0` node from
   `<build>/zephyr/include/generated/zephyr/devicetree_generated.h`.

Step 4 reuses M3's measured resolution idiom, which maps ordinal to node rather
than the reverse:

```bash
grep -o '__device_dts_ord_[0-9]*' "$log" | sort -u | while read -r s; do
  n=${s##*_}
  grep -n "DT_N_.*ORD $n\$" "$build"/zephyr/include/generated/zephyr/devicetree_generated.h
done
```

The trailing `$` anchor is load-bearing: it pins the match to the `_ORD` define
whose value is the bare ordinal, excluding the sibling `_ORD_STR_SORTABLE`
define, whose value is a quoted string. The resolved define name embeds the
node's full devicetree path, which the shield can change, so the resulting name
is then required to contain `is31fl3743b`. M4 A-11 recorded the resolved path as
`/pico-de-gallo/spi/is31fl3743b@0` for both targets, and recorded distinct
ordinals for them (49 and 50), which is why cross-sample ordinal identity must
never be asserted.

Steps 3 and 4 together are the per-sample attribution D5 requires, expressed
without reference to any literal ordinal.

## 6. Workflow structure

`.github/workflows/zephyr.yml`, one job, `runs-on: ubuntu-latest`, no container.
House style is followed: a top-of-file comment block explaining why the workflow
exists, `permissions: contents: read`, the standard `concurrency` block from
`check.yml`, and a `name:` following the `platform / toolchain / purpose` idiom
(`ubuntu / host / zephyr`).

No Zephyr SDK is installed. `ZEPHYR_TOOLCHAIN_VARIANT=host` builds `native_sim`
with the host compiler, and `native/64` avoids `gcc-multilib`. This removes the
single most expensive component of a conventional Zephyr CI setup and is why a
plain runner suffices where the repository otherwise uses containers only for
`docker://rhysd/actionlint`.

Steps, in order:

1. `actions/checkout@v7` with `submodules: true`, matching house style.
2. Assert `zephyr/README.md` contains the pinned SHA (D6).
3. Install apt build dependencies with `--no-install-recommends`.
4. Install `west` via pip.
5. `actions/cache` over the west workspace, keyed on the pinned SHA. The key is
   stable because the revision is pinned, so steady-state runs restore rather than
   clone.
6. On cache miss only: `west init -m <zephyr> --mr <SHA>` followed by
   `west update --narrow -o=--filter=blob:none`, the fast path documented in
   `zephyr/README.md`.
7. `dtolnay/rust-toolchain@stable`.
8. Run `zephyr/scripts/ci-build.sh`.

`actions/cache` is a deliberate deviation from house style, which uses no caching
anywhere. The justification is that a Zephyr west workspace is multi-gigabyte and
the cache key is exactly stable under D1.

The script is invoked from the west workspace root with absolute source paths into
this repository, rather than relying on west discovering its topdir by walking up
from the repository directory. This sidesteps west workspace resolution entirely.

## 7. Verification

### 7.1 Static

- `actionlint` on the new workflow. The repository baseline is clean (exit 0
  across all ten existing workflows), so any finding is attributable to this
  change. `check.yml` also runs `actionlint` in CI.
- `shellcheck -S warning` on the new script. The repository baseline is clean at
  that severity for the existing 600-line `run-m5.sh`, so the new script is held
  to the same bar.
- `dos2unix` on both new files, per AGENTS.md §3. CRLF in a workflow `run:` block
  breaks `actionlint` with `unexpected character $'\r'`.

### 7.2 Mutation check

Issue #130's acceptance criterion 3 requires demonstrating that a deliberate FFI
symbol rename fails the job. No Zephyr environment is available locally, so the
demonstration is performed by CI, using this protocol agreed with the maintainer:

1. Push the clean branch and confirm the workflow passes.
2. Add a commit renaming a `gallo_*` symbol in `pico-de-gallo-ffi`.
3. Push; confirm the workflow fails at the native_simulator runner link.
4. `git reset --hard` back to the clean commit and `git push --force-with-lease`.
5. Link the failing run in the pull request body as evidence.

The mutated symbol is `gallo_gpio_unsubscribe`, chosen because it is called only
from `zephyr/tests/pdg_mfd_m5/common/m5_bottom.c` and not from any sample.
A green result under that mutation would therefore also prove targets 5 through 8
are vacuous, making the mutation a simultaneous check of D4.

The mutation is never merged.

### 7.3 Not verifiable before first CI run

Everything else. The first CI run is the first execution of both new files.

Reusing M3's and M4's measured idioms (§5) removes the largest category of
guesswork, since those greps ran against real builds of this module. What remains
unverified is the surrounding scaffolding rather than the assertion logic. In
descending order of expected probability:

1. A missing or misnamed apt package in the runner setup.
2. `west` workspace or `ZEPHYR_BASE` resolution, mitigated by invoking builds
   from the workspace root with absolute source paths.
3. The native_simulator object-file path or suffix in §5.1 assertion 4, which is
   the one place a `find` by name could come up empty for a benign reason.
4. Cache key or restore behaviour on the first populated run.

None of these are silent-pass failures: each fails loudly and visibly. The
failure mode this design most needs to avoid — a green run that proves nothing —
is guarded by §5.1 assertions 3 and 5, and independently by the §7.2 mutation
check.

## 8. Follow-ups, deliberately not in this change

- **Weekly non-blocking `main` tracker.** Pin rot is D1's accepted cost. A
  `schedule:` job building against Zephyr `main` with `continue-on-error: true`
  would surface upstream drift without failing pull requests. Deferred because
  #130's acceptance criteria say nothing about upstream drift, and adding a
  scheduled job that has never been observed to pass is poor practice.
- **Twister metadata and hardware-free unit tests.** Issue #109 covers
  `sample.yaml` and `testcase.yaml` files, the dangling `tests:` and
  `snippet_root:` entries in `zephyr/module.yml`, and unit tests for the pure
  helper functions. This change deliberately does not add twister metadata; it
  drives `west build` directly.

  > **Partly overtaken 2026-08-27.** Two of those premises were already stale
  > when this was written, and a third was wrong. `zephyr/tests/` exists, so
  > only `snippet_root:` dangled. And upstream has retired *both* `sample.yaml`
  > and `testcase.yaml` in favour of `tests.yaml`
  > (`filename:sample.yaml repo:zephyrproject-rtos/zephyr` → 0 results;
  > `filename:testcase.yaml path:tests/drivers` → 0, against 268 `tests.yaml`).
  > Twister metadata and a `twister` CI job landed under #109; the unit tests
  > for the helpers remain outstanding.
- **Hardware runs.** `run-m5.sh` remains a manual, board-attached procedure.
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

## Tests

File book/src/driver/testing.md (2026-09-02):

# Testing with `pico-de-gallo-hal`

This is the whole payoff.

Because the driver is written against `embedded-hal`, and because
`pico-de-gallo-hal` implements those traits on top of a USB-connected
Pico de Gallo board, we can run the driver on a host machine against a
*real* TMP102.

No mocks. No firmware flashing loop. No sacrificial example binary that
only exists so you can manually test one register read.

## A hardware-in-the-loop test

Our public API is async, so the test is too:

```rust,no_run
#[cfg(feature = "hil")]
#[tokio::test]
async fn tmp102_reports_a_plausible_temperature() {
    use pico_de_gallo_hal::Hal;
    use tmp102::{Celsius, Tmp102, A0};

    let hal = Hal::new();
    let i2c = hal.i2c();
    let mut sensor = Tmp102::new(i2c, A0::Gnd);

    let Celsius(temp) = sensor.temperature().await.unwrap();

    assert!((-40.0..=125.0).contains(&temp));
}
```

That range is intentionally broad: it matches the device's operating
range and keeps the test robust across different lab environments.

The blocking siblings we add in the next chapter work the same way with
a plain `#[test]` and no `.await`.

## Why this is special

Most embedded-driver test setups force you into one of two extremes:

- pure mocks, which are fast but can only prove your expectations about
  bus traffic
- target-hardware tests, which are realistic but slow and usually drag
  in flashing, runners, probes, and target-specific setup

Pico de Gallo sits in a very productive middle ground:

- the sensor is real
- the electrical path is real
- the I<sup>2</sup>C transactions are real
- the test still runs from your normal host-side Rust test harness

That means you can put a USB-connected board on a CI runner and execute
real hardware-in-the-loop tests with `cargo test`.

## Gate HIL tests behind a feature

Not every CI environment has hardware attached, so gate the test behind
an opt-in feature:

```rust,noplayground
#[cfg(feature = "hil")]
#[tokio::test]
async fn tmp102_reports_a_plausible_temperature() {
    // ...
}
```

And in `Cargo.toml`:

```toml
[features]
default = []
defmt = ["dep:defmt", "device-driver/defmt"]
hil = []
```

Now normal CI can run `cargo test`, while the hardware-backed runner can
run:

```console
$ cargo test --features hil
```

> [!TIP]
> Keep `pico-de-gallo-hal` in `[dev-dependencies]`. End users of your
> published crate do not need the host transport layer just because you
> used it for tests.

## Mocks still have a place

`pico-de-gallo-hal` is not a replacement for `embedded-hal-mock`.
Instead, the two complement each other nicely:

- use `embedded-hal-mock` for pure logic tests, edge cases, and exact
  bus-sequence assertions
- use Pico de Gallo for integration tests against a real sensor

That combination is hard to beat:

- mocks keep your fast inner loop fast
- HIL tests catch the mistakes that only show up with actual hardware

For driver authors, that is exactly why `pico-de-gallo-hal` exists.

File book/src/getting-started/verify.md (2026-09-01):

# Verifying Your Device

Plug the freshly-flashed Pico de Gallo into your host and run:

```console
$ gallo version
╭─────────────┬──────────────────────────────╮
│ Firmware    │ v0.12.0                      │
│ Schema      │ v0.8.0                       │
│ HW revision │ 2                            │
│ GPIOs       │ 4                            │
│ Build       │ firmware-v0.12.0-42-g1a2b3c4 │
╰─────────────┴──────────────────────────────╯
╭─────┬─────┬──────┬──────┬─────┬─────┬────────╮
│ I2C │ SPI │ UART │ GPIO │ PWM │ ADC │ 1-Wire │
├─────┼─────┼──────┼──────┼─────┼─────┼────────┤
│ ✓   │ ✓   │ ✓    │ ✓    │ ✓   │ ✓   │ ✓      │
╰─────┴─────┴──────┴──────┴─────┴─────┴────────╯
```

If you see that block, you're done. Success 🎉.

## What Each Field Means

| Field | What it tells you |
|---|---|
| `Firmware` | The firmware semver. Lockstepped with the wire crate at release time. |
| `Schema` | The wire-protocol schema version. The host crate must understand this. |
| `HW revision` | `1` if you flashed `hw-rev1` firmware, `2` for `hw-rev2`. |
| `GPIOs` | Number of user-controllable GPIO pins this firmware exposes. This is the authoritative bound for a GPIO index and for an SPI chip-select pin. |
| `Build` | Firmware build identity from `git describe`. A trailing `-dirty` means the image was built from a modified working tree. Informational only — it never affects whether a command succeeds. Quote this when reporting a bug or reproducing a measurement. |
| Capability table | Which peripherals **this firmware build** exposes. A `✗` means the endpoint returns `Unsupported`. |

> [!IMPORTANT]
>
> The `HW revision` line reflects the **firmware build**, not the
> PCB you have. If you flashed the wrong build, re-enter BOOTSEL
> and flash the right one. See [Assembly &
> Flashing](../hardware/assembly.md).

## Ping

For a quick round-trip sanity check:

```console
$ gallo ping
Ping OK
```

`ping` sends a random `u32` to the firmware and asserts the echo
matches. If you can ping, USB and the wire protocol are fully
functional.

The payload is randomised per invocation, so a stale or
default-initialised response can't pass as a healthy round trip. If
the round trip completes but the value comes back wrong, you get the
mismatch instead of a generic transport error:

```console
$ gallo ping
Error: ping echo mismatch: sent 0x9f2c41ab, received 0x00000000
```

> [!NOTE]
>
> `ping` and `version` are the only device subcommands that skip the
> up-front schema check described below. That is deliberate: a board
> whose schema doesn't match your `gallo` build should still be able
> to prove its USB path works.

## Listing Multiple Devices

If you have more than one Pico de Gallo connected, `gallo list`
shows them:

```console
$ gallo list
Serial Number         Bus    Address
E6633861A34B8C24      2      14
E6633861A34B9F17      1      8
```

Pick a specific device with `-s` (or `--serial-number`):

```console
$ gallo -s E6633861A34B8C24 version
```

Without `-s`, `gallo` uses the first device it finds — which is
non-deterministic if you have more than one plugged in.

## Schema Mismatch

If the firmware and your host CLI disagree on the wire protocol,
`gallo version` will tell you:

```console
$ gallo version
Error: schema mismatch (firmware v0.5.0, host expects v0.4.x)
```

The fix is to update whichever side is behind. See
[Releases & Compatibility](../internals/releases.md) for the rules
on which versions are compatible.

## Next

You're up and running. Pick an interface to play with — start
with [I²C](../interfaces/i2c.md) or [GPIO](../interfaces/gpio.md),
or skip to [Writing a Device Driver](../driver/index.md) for the
guided tour.

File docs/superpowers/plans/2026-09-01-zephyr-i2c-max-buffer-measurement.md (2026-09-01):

# I2C Transfer-Ceiling Measurement Implementation Plan

> **For agentic workers:** REQUIRED SUB-SKILL: Use superpowers:subagent-driven-development (recommended) or superpowers:executing-plans to implement this plan task-by-task. Steps use checkbox (`- [ ]`) syntax for tracking.

**Goal:** Measure the real `i2c/write` and `i2c/write-read` payload ceilings on attached hardware, and set `PDG_I2C_MAX_BUFFER` from that measurement instead of from the unmeasured 4096-byte protocol constant.

**Architecture:** A throwaway Rust harness in `/tmp/opencode/i2c-probe/` drives one RPC per probe under a timeout, classifies the result into returned / errored / hung, and recovers a hung board via `USBDEVFS_RESET`. Three sweep phases (write edge, read edge, write+read frontier) locate the boundary by coarse ladder then bisection. The resulting numbers drive a one-line constant change plus documentation across the Zephyr module and the book.

**Tech Stack:** Rust 1.97 / edition 2024, `pico-de-gallo-lib` 0.8.0 by path dependency, `tokio` (rt-multi-thread, macros, time), `libc` for the `USBDEVFS_RESET` ioctl, Linux sysfs for device resolution. Zephyr via `~/zephyrproject` with `west` and `twister`. `mdbook` for the book.

**Spec:** `docs/superpowers/specs/2026-09-01-zephyr-i2c-max-buffer-measurement.md`

**Board under test:** serial `49742081C885AC69`, firmware 0.11.0, schema 0.7, hardware revision 2. Bus has exactly one target, a TMP102 at `0x48`. Address `0x50` is unpopulated and is the write-probe target.

---

## File Structure

**Harness — throwaway, never committed.** Lives outside the repo so it cannot be committed by accident.

| File | Responsibility |
|---|---|
| `/tmp/opencode/i2c-probe/Cargo.toml` | package manifest, path deps into the repo |
| `/tmp/opencode/i2c-probe/src/record.rs` | CSV line formatting and append-and-flush recorder |
| `/tmp/opencode/i2c-probe/src/usb.rs` | sysfs device resolution and `USBDEVFS_RESET` |
| `/tmp/opencode/i2c-probe/src/probe.rs` | `Outcome`, the single-RPC probe, liveness ping, recovery loop |
| `/tmp/opencode/i2c-probe/src/search.rs` | pure `bisect` helper, unit-tested |
| `/tmp/opencode/i2c-probe/src/main.rs` | phase orchestration and CLI phase selection |
| `/tmp/opencode/i2c-probe/results.csv` | raw measurement output |

Split by responsibility: USB recovery knows nothing about I2C, the search is pure and testable without hardware, and the recorder is independent of both.

**Repository — what actually lands.**

| File | Change |
|---|---|
| `zephyr/drivers/i2c/pdg_i2c.c:101` | `PDG_I2C_MAX_BUFFER` value and its comment |
| `zephyr/README.md` | measured-limits paragraph and the `-EMSGSIZE` table row |
| `zephyr/CHANGELOG.md` | Changed entry |
| `book/src/interfaces/batching.md` | the "no general ceiling is published" claim |
| `book/src/interfaces/i2c.md` | I2C containment note |
| `book/src/appendix/troubleshooting.md` | I2C limit narrative and host-surface reachability warning |
| `AGENTS.md` | §13.17 row, only if a hang is found |

---

## Task 1: Scaffold the harness and the recorder

**Files:**
- Create: `/tmp/opencode/i2c-probe/Cargo.toml`
- Create: `/tmp/opencode/i2c-probe/src/main.rs`
- Create: `/tmp/opencode/i2c-probe/src/record.rs`

- [ ] **Step 1: Create the package directory**

```bash
mkdir -p /tmp/opencode/i2c-probe/src
```

- [ ] **Step 2: Write the manifest**

Create `/tmp/opencode/i2c-probe/Cargo.toml`:

```toml
[package]
name = "i2c-probe"
version = "0.1.0"
edition = "2024"
publish = false

[dependencies]
pico-de-gallo-lib = { path = "/home/balbi/workspace/pico-de-gallo/crates/pico-de-gallo-lib" }
pico-de-gallo-internal = { path = "/home/balbi/workspace/pico-de-gallo/crates/pico-de-gallo-internal", features = ["use-std"] }
tokio = { version = "1", features = ["rt-multi-thread", "macros", "time"] }
libc = "0.2"
```

- [ ] **Step 3: Write the failing test for CSV formatting**

Create `/tmp/opencode/i2c-probe/src/record.rs`:

```rust
//! Append-and-flush CSV recording. Every probe is written immediately so a
//! crash or a power-cycle never loses data already gathered.

use std::fs::{File, OpenOptions};
use std::io::Write;

/// Formats one probe result as a CSV line, without the trailing newline.
///
/// `detail` is free text and is quoted, because error Debug output contains
/// commas.
pub fn csv_line(kind: &str, w_len: u32, r_len: u32, outcome: &str, detail: &str, elapsed_ms: u128) -> String {
    let escaped = detail.replace('"', "'");
    format!("{kind},{w_len},{r_len},{outcome},\"{escaped}\",{elapsed_ms}")
}

/// Owns the results file and appends to it.
pub struct Recorder {
    file: File,
}

impl Recorder {
    /// Opens `path`, creating it and writing the header if it is new.
    pub fn open(path: &str) -> std::io::Result<Self> {
        let is_new = !std::path::Path::new(path).exists();
        let mut file = OpenOptions::new().create(true).append(true).open(path)?;
        if is_new {
            writeln!(file, "kind,w_len,r_len,outcome,detail,elapsed_ms")?;
            file.flush()?;
        }
        Ok(Self { file })
    }

    /// Appends one line and flushes immediately.
    pub fn record(&mut self, line: &str) -> std::io::Result<()> {
        writeln!(self.file, "{line}")?;
        self.file.flush()
    }
}

#[cfg(test)]
mod tests {
    use super::*;

    #[test]
    fn csv_line_quotes_detail_and_orders_fields() {
        let line = csv_line("write", 1013, 0, "nack", "NoAcknowledge", 7);
        assert_eq!(line, "write,1013,0,nack,\"NoAcknowledge\",7");
    }

    #[test]
    fn csv_line_replaces_embedded_quotes() {
        let line = csv_line("write", 1, 0, "err", "Comms(\"boom\")", 1);
        assert_eq!(line, "write,1,0,err,\"Comms('boom')\",1");
    }
}
```

- [ ] **Step 4: Write a placeholder main so the crate builds**

Create `/tmp/opencode/i2c-probe/src/main.rs`:

```rust
mod record;

fn main() {
    println!("i2c-probe");
}
```

- [ ] **Step 5: Run the tests and verify they pass**

```bash
cd /tmp/opencode/i2c-probe && cargo test
```

Expected: `test result: ok. 2 passed`. If the path dependency fails to resolve, the repo checkout has moved — fix the paths in `Cargo.toml`, do not vendor the crate.

---

## Task 2: USB resolution and reset

**Files:**
- Create: `/tmp/opencode/i2c-probe/src/usb.rs`
- Modify: `/tmp/opencode/i2c-probe/src/main.rs`

- [ ] **Step 1: Write the module**

Create `/tmp/opencode/i2c-probe/src/usb.rs`:

```rust
//! Device resolution via sysfs and re-enumeration via USBDEVFS_RESET.
//!
//! The bus path changes across re-enumeration, so it is resolved fresh on
//! every call and never cached.

use std::os::fd::AsRawFd;
use std::time::{Duration, Instant};

const VID: &str = "045e";
const PID: &str = "067d";

/// `_IO('U', 20)` — Linux `USBDEVFS_RESET`.
const USBDEVFS_RESET: libc::c_ulong = 0x5514;

/// Returns the `/dev/bus/usb/BBB/DDD` node for the board with `serial`.
///
/// Walks `/sys/bus/usb/devices/` matching vendor, product and serial, then
/// reads `busnum` and `devnum` to build the device node path.
pub fn resolve_node(serial: &str) -> Option<String> {
    let entries = std::fs::read_dir("/sys/bus/usb/devices").ok()?;
    for entry in entries.flatten() {
        let dir = entry.path();
        let read = |name: &str| std::fs::read_to_string(dir.join(name)).ok().map(|s| s.trim().to_string());

        if read("idVendor").as_deref() != Some(VID) {
            continue;
        }
        if read("idProduct").as_deref() != Some(PID) {
            continue;
        }
        if read("serial").as_deref() != Some(serial) {
            continue;
        }

        let bus: u32 = read("busnum")?.parse().ok()?;
        let dev: u32 = read("devnum")?.parse().ok()?;
        return Some(format!("/dev/bus/usb/{bus:03}/{dev:03}"));
    }
    None
}

/// Issues `USBDEVFS_RESET` on the board, forcing re-enumeration.
///
/// Returns an error string rather than panicking: a failed reset is a
/// result worth recording, not a crash.
pub fn reset(serial: &str) -> Result<(), String> {
    let node = resolve_node(serial).ok_or_else(|| format!("no device node for serial {serial}"))?;
    let file = std::fs::OpenOptions::new()
        .write(true)
        .open(&node)
        .map_err(|e| format!("open {node}: {e}"))?;

    // SAFETY: `file` is an open USB device node and USBDEVFS_RESET takes no
    // argument, so the third parameter is ignored by the kernel.
    let rc = unsafe { libc::ioctl(file.as_raw_fd(), USBDEVFS_RESET, 0) };
    if rc != 0 {
        return Err(format!("USBDEVFS_RESET on {node}: {}", std::io::Error::last_os_error()));
    }
    Ok(())
}

/// Blocks until the board reappears in sysfs, up to `timeout`.
pub fn wait_for_node(serial: &str, timeout: Duration) -> Result<String, String> {
    let deadline = Instant::now() + timeout;
    loop {
        if let Some(node) = resolve_node(serial) {
            // The node exists but udev may not have applied its ACL yet.
            std::thread::sleep(Duration::from_millis(500));
            return Ok(node);
        }
        if Instant::now() >= deadline {
            return Err(format!("device {serial} did not reappear within {timeout:?}"));
        }
        std::thread::sleep(Duration::from_millis(200));
    }
}
```

- [ ] **Step 2: Register the module**

Replace `/tmp/opencode/i2c-probe/src/main.rs` with:

```rust
mod record;
mod usb;

fn main() {
    let serial = "49742081C885AC69";
    match usb::resolve_node(serial) {
        Some(node) => println!("resolved {serial} to {node}"),
        None => println!("could not resolve {serial}"),
    }
}
```

- [ ] **Step 3: Verify resolution works against the live board**

```bash
cd /tmp/opencode/i2c-probe && cargo run
```

Expected: `resolved 49742081C885AC69 to /dev/bus/usb/001/025` (the device number will differ if the board has re-enumerated since).

If it prints `could not resolve`, the board is unplugged or the serial is wrong. Confirm with `lsusb -d 045e:067d` before continuing — every later task assumes resolution works.

- [ ] **Step 4: Verify reset works, before relying on it for recovery**

This is the single riskiest assumption in the plan (spec §8), so test it in isolation now rather than discovering it mid-sweep.

Temporarily replace the body of `main` with:

```rust
fn main() {
    let serial = "49742081C885AC69";
    println!("before: {:?}", usb::resolve_node(serial));
    match usb::reset(serial) {
        Ok(()) => println!("reset issued"),
        Err(e) => println!("reset failed: {e}"),
    }
    match usb::wait_for_node(serial, std::time::Duration::from_secs(15)) {
        Ok(node) => println!("after: {node}"),
        Err(e) => println!("did not reappear: {e}"),
    }
}
```

Run it:

```bash
cd /tmp/opencode/i2c-probe && cargo run
```

Expected: `reset issued` followed by `after: /dev/bus/usb/001/NNN` with a **different** device number than `before`. A changed device number is the evidence that re-enumeration actually happened.

**Stop and report if the reset fails or the node does not reappear.** Without working recovery the sweep cannot bisect through a hang, and the plan needs revisiting with the user rather than pressing on.

---

## Task 3: The pure bisection helper

**Files:**
- Create: `/tmp/opencode/i2c-probe/src/search.rs`
- Modify: `/tmp/opencode/i2c-probe/src/main.rs`

Written before the hardware probe deliberately: it is the only part of the harness that can be tested without a board, and a bisection bug would silently produce a wrong boundary.

- [ ] **Step 1: Write the failing test**

Create `/tmp/opencode/i2c-probe/src/search.rs` with the test module only, plus a stub:

```rust
//! Pure boundary search. No hardware, no I/O — so it can be tested.

/// Finds the largest value in `(lo, hi)` for which `passes` holds.
///
/// Caller must establish the invariant: `passes(lo)` is true and
/// `passes(hi)` is false. Returns the largest known-passing value.
pub fn bisect<F>(_lo: u32, _hi: u32, _passes: F) -> u32
where
    F: FnMut(u32) -> bool,
{
    todo!()
}

#[cfg(test)]
mod tests {
    use super::*;

    #[test]
    fn finds_exact_edge_of_a_step_function() {
        // passes for n <= 1013, fails above.
        let edge = bisect(1, 4096, |n| n <= 1013);
        assert_eq!(edge, 1013);
    }

    #[test]
    fn handles_adjacent_bounds_without_probing() {
        let mut probes = 0;
        let edge = bisect(100, 101, |_| {
            probes += 1;
            true
        });
        assert_eq!(edge, 100);
        assert_eq!(probes, 0, "adjacent bounds leave nothing to probe");
    }

    #[test]
    fn finds_edge_at_the_bottom_of_the_range() {
        let edge = bisect(1, 4096, |n| n <= 1);
        assert_eq!(edge, 1);
    }

    #[test]
    fn finds_edge_just_below_the_top() {
        let edge = bisect(1, 4096, |n| n <= 4095);
        assert_eq!(edge, 4095);
    }
}
```

- [ ] **Step 2: Run the test to verify it fails**

```bash
cd /tmp/opencode/i2c-probe && cargo test search
```

Expected: FAIL, panicking at `not yet implemented`.

- [ ] **Step 3: Implement**

Replace the `bisect` stub with:

```rust
pub fn bisect<F>(mut lo: u32, mut hi: u32, mut passes: F) -> u32
where
    F: FnMut(u32) -> bool,
{
    while hi - lo > 1 {
        let mid = lo + (hi - lo) / 2;
        if passes(mid) {
            lo = mid;
        } else {
            hi = mid;
        }
    }
    lo
}
```

- [ ] **Step 4: Run the tests to verify they pass**

```bash
cd /tmp/opencode/i2c-probe && cargo test search
```

Expected: `test result: ok. 4 passed`.

- [ ] **Step 5: Register the module**

Add `mod search;` to `/tmp/opencode/i2c-probe/src/main.rs`.

---

## Task 4: The probe

**Files:**
- Create: `/tmp/opencode/i2c-probe/src/probe.rs`
- Modify: `/tmp/opencode/i2c-probe/src/main.rs`

- [ ] **Step 1: Write the module**

Create `/tmp/opencode/i2c-probe/src/probe.rs`:

```rust
//! One RPC per probe, under a timeout, on a fresh connection.
//!
//! A fresh connection per probe means a hung probe cannot leak transport
//! state into the next one. On Linux the interface is released
//! synchronously on drop, so the repeated open/close does not hit the
//! WinUSB exclusive-claim problem recorded in AGENTS.md 13.17 (2026-07-20).

use std::time::{Duration, Instant};

use pico_de_gallo_lib::PicoDeGallo;

use crate::usb;

/// 4096 bytes at 100 kHz standard-mode I2C is roughly 0.4 s of bus time,
/// so this is about a 10x margin. A false `Hang` would corrupt the
/// boundary, so the bias is deliberately toward over-waiting.
pub const PROBE_TIMEOUT: Duration = Duration::from_secs(5);

/// What happened to a single probe.
#[derive(Debug, Clone, PartialEq, Eq)]
pub enum Outcome {
    /// The call returned success.
    Ok,
    /// `I2cError::NoAcknowledge` — the healthy answer at an unpopulated
    /// address. Counts as "the call returned".
    Nack,
    /// Any other error, recorded verbatim. A working transport refusing a
    /// request.
    Err(String),
    /// The timeout fired. A wedged dispatcher.
    Hang,
}

impl Outcome {
    /// True when the call returned at all, which is the property under
    /// measurement. Both `Ok` and `Nack` qualify.
    pub fn returned(&self) -> bool {
        matches!(self, Outcome::Ok | Outcome::Nack)
    }

    /// Short tag for the CSV `outcome` column.
    pub fn tag(&self) -> &'static str {
        match self {
            Outcome::Ok => "ok",
            Outcome::Nack => "nack",
            Outcome::Err(_) => "err",
            Outcome::Hang => "hang",
        }
    }

    /// Free-text detail for the CSV `detail` column.
    pub fn detail(&self) -> String {
        match self {
            Outcome::Err(e) => e.clone(),
            other => format!("{other:?}"),
        }
    }
}

/// Classifies a `Result` from either I2C call into an `Outcome`.
fn classify<T>(result: Result<T, pico_de_gallo_lib::PicoDeGalloError<pico_de_gallo_internal::I2cError>>) -> Outcome {
    match result {
        Ok(_) => Outcome::Ok,
        Err(pico_de_gallo_lib::PicoDeGalloError::Endpoint(pico_de_gallo_internal::I2cError::NoAcknowledge)) => {
            Outcome::Nack
        }
        Err(e) => Outcome::Err(format!("{e}")),
    }
}

/// What kind of RPC a probe issues.
#[derive(Debug, Clone, Copy, PartialEq, Eq)]
pub enum Kind {
    /// `i2c/write` of `w_len` bytes. `r_len` is ignored.
    Write,
    /// `i2c/write-read` of `w_len` bytes out and `r_len` bytes back.
    WriteRead,
}

impl Kind {
    pub fn tag(&self) -> &'static str {
        match self {
            Kind::Write => "write",
            Kind::WriteRead => "write_read",
        }
    }
}

/// Opens the board, issues exactly one RPC under `PROBE_TIMEOUT`, closes.
///
/// `w_len` of 0 is never issued: the host library refuses an empty write
/// with `ZeroLengthWrite` and the firmware refuses it too (issue #101), so
/// zero is not part of the measurable range.
pub async fn probe(serial: &str, kind: Kind, address: u8, w_len: u32, r_len: u32) -> (Outcome, u128) {
    let started = Instant::now();

    let pg = match PicoDeGallo::try_new_with_serial_number(serial) {
        Ok(pg) => pg,
        Err(e) => return (Outcome::Err(format!("open failed: {e}")), started.elapsed().as_millis()),
    };

    let payload = vec![0u8; w_len as usize];

    let outcome = match kind {
        Kind::Write => {
            let call = pg.i2c_write(address, &payload);
            match tokio::time::timeout(PROBE_TIMEOUT, call).await {
                Ok(result) => classify(result),
                Err(_) => Outcome::Hang,
            }
        }
        Kind::WriteRead => {
            let call = pg.i2c_write_read(address, &payload, r_len as u16);
            match tokio::time::timeout(PROBE_TIMEOUT, call).await {
                Ok(result) => classify(result),
                Err(_) => Outcome::Hang,
            }
        }
    };

    (outcome, started.elapsed().as_millis())
}

/// Cheap liveness check. Run before every probe so that a wedge is
/// detected before its failures get attributed to the next length.
pub async fn alive(serial: &str) -> bool {
    let Ok(pg) = PicoDeGallo::try_new_with_serial_number(serial) else {
        return false;
    };
    matches!(tokio::time::timeout(Duration::from_secs(2), pg.ping(0xC0FFEE)).await, Ok(Ok(_)))
}

/// Resets the board and waits for it to answer a ping again.
///
/// Returns `Err` if the board is still unreachable after `attempts`
/// rounds, so the caller can stop rather than record garbage from a
/// still-wedged board.
pub async fn recover(serial: &str, attempts: u32) -> Result<(), String> {
    for attempt in 1..=attempts {
        eprintln!("  recover: attempt {attempt}/{attempts}");

        if let Err(e) = usb::reset(serial) {
            eprintln!("  recover: reset failed: {e}");
        }
        match usb::wait_for_node(serial, Duration::from_secs(15)) {
            Ok(node) => eprintln!("  recover: reappeared at {node}"),
            Err(e) => {
                eprintln!("  recover: {e}");
                continue;
            }
        }
        if alive(serial).await {
            eprintln!("  recover: board is answering again");
            return Ok(());
        }
    }
    Err(format!(
        "board {serial} still unreachable after {attempts} reset attempts; power-cycle it"
    ))
}
```

- [ ] **Step 2: Register the module**

`/tmp/opencode/i2c-probe/src/main.rs` module list becomes:

```rust
mod probe;
mod record;
mod search;
mod usb;
```

- [ ] **Step 3: Verify it compiles**

```bash
cd /tmp/opencode/i2c-probe && cargo build 2>&1 | tail -20
```

Expected: compiles. If `PicoDeGalloError` or `I2cError` paths are wrong, check the real ones with:

```bash
grep -n "pub use\|pub enum PicoDeGalloError" /home/balbi/workspace/pico-de-gallo/crates/pico-de-gallo-lib/src/lib.rs | head
```

---
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

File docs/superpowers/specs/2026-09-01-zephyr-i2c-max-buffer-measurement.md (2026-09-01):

# Measuring the I2C transfer ceiling (issue #146)

**Status:** design, approved 2026-09-01. Uncommitted by request — the
measurement harness and this document are one-off validation artifacts.
Only the resulting constant and the documentation land.

**Board under test:** serial `49742081C885AC69`, firmware 0.11.0, schema
0.7, hardware revision 2, `num_gpios` 4. One I2C target on the bus: a
TMP102 at `0x48`.

---

## 1. Problem

`PDG_I2C_MAX_BUFFER` in `zephyr/drivers/i2c/pdg_i2c.c:101` is `4096U`,
inherited from `pico_de_gallo_internal::MAX_TRANSFER_SIZE`. That is a
packet-buffer and argument bound, not a measured end-to-end ceiling.

The sibling SPI driver was built on the same mental model and the model
was wrong twice: on `spi/transfer`, 4096 TX-only failed `-ECOMM`, a
reasoned 3072-byte full-duplex guess also failed `-ECOMM`, and 1015
TX-only wedged the firmware dispatcher device-wide.
`PDG_SPI_MAX_BUFFER` was consequently lowered to 1013 (AGENTS.md
§13.17, 2026-08-19).

`i2c/write` carries its whole payload in the request frame exactly as
`spi/transfer` does, and `i2c/write-read` carries a payload in each
direction, which is structurally what defeated the 3072-byte duplex
guess. No equivalent measurement has ever been taken for I2C.

## 2. Goal

Measure, on attached hardware, the largest `i2c/write` and
`i2c/write-read` payloads for which the call returns at all. Set
`PDG_I2C_MAX_BUFFER` from that measurement, with the same explicitly
"measured, not derived" framing `PDG_SPI_MAX_BUFFER` carries.

Out of scope, and deliberately so: guarding the host surfaces (CLI,
Rust, C, Python, MCP), and deriving the ceiling from framing as a shared
contract in `pico-de-gallo-internal`. Both are named in issue #146 as the
longer-term fix; both carry schema and lockstep-release implications.

## 3. Harness

A throwaway binary at `/tmp/opencode/i2c-probe/`, depending on
`pico-de-gallo-lib` by path. Not committed.

### 3.1 `probe(kind, w_len, r_len) -> Outcome`

Opens the board by serial number, issues exactly one RPC under a
`tokio::time::timeout`, and closes the connection. One connection per
probe, so a hang cannot leak state into the next probe.

Four outcomes:

| Outcome | Meaning |
|---|---|
| `Ok` | the call returned success |
| `Nack` | `I2cError::NoAcknowledge` — the expected healthy answer at an unpopulated address |
| `Err(e)` | any other error, recorded verbatim; transport failures live here |
| `Hang` | the timeout fired |

`Ok` and `Nack` both count as "the call returned", which is the property
under measurement. `Err` and `Hang` are distinguished because they mean
very different things: an error is a working transport refusing a
request, a hang is a wedged dispatcher.

**Timeout: 5 s.** 4096 bytes at 100 kHz standard-mode I2C is roughly
0.4 s of bus time, so this is about a 10x margin. A false `Hang` would
corrupt the boundary, so the bias is deliberately toward over-waiting.

### 3.2 `recover()`

Run after any `Hang`:

1. Re-resolve the device by VID:PID `045e:067d`. The bus path changes
   across re-enumeration, so it must be looked up fresh, never cached.
2. Issue `USBDEVFS_RESET` (`0x5514`) on the device node. Verified
   available unprivileged: the node carries an ACL for the invoking
   user.
3. Wait for the node to reappear.
4. Confirm liveness with `ping`.

If `ping` still fails after a bounded number of attempts, the harness
stops and asks for a power-cycle rather than silently producing garbage
from a still-wedged board.

### 3.3 Liveness check between every probe

A `ping` before each probe. Without it, one missed wedge silently
poisons every subsequent data point by attributing the wedge's failures
to the lengths being probed.

### 3.4 Output

One CSV line per probe:
`kind,w_len,r_len,outcome,detail,elapsed_ms`. Appended and flushed
immediately, so a crash or power-cycle does not lose probes already
taken.

## 4. Sweep procedure

### Phase A — write-only edge

`i2c_write(0x50, [0u8; N])` against an unpopulated address. The full
payload still crosses USB and is decoded, so request framing is fully
exercised, but nothing is written to any real device.

Coarse ladder first: 1, 64, 256, 512, 1013, 1015, 1024, 2048, 3072,
4096. Chosen so results are directly comparable to the SPI table and so
the SPI edge pair 1013/1015 is checked explicitly even if the real I2C
edge is elsewhere.
Then bisect between the largest passing and smallest failing rung to the
exact byte.

The healthy outcome here is `Nack`, not `Ok`. An `Ok` at `0x50` would
mean something is actually present; stop and re-scan the bus.

### Phase B — read-only edge

`i2c_write_read(0x48, [0x00], N)` against the TMP102. The 1-byte write
is the pointer register; the TMP102 clocks out its register pair
repeatedly for arbitrary read lengths, so a genuine N-byte response is
produced and response framing is really exercised. Same ladder, same
bisection.

### Phase C — the W+R frontier

For each of roughly five write lengths spanning Phase A's range (1, 25%,
50%, 75%, and just under the Phase A edge), bisect the largest read
length that still returns. Against `0x48`, so both directions are real.

Phase C is the phase that earns its keep. If the frontier is a rectangle
(`max_w` and `max_r` independent), the constraint is per-direction. If
it is a diagonal (`w + r <= K`), it is a shared budget — the shape that
made the SPI 3072-byte duplex guess wrong. Two independent 1-D
bisections cannot distinguish those, which is why they were rejected.

### Bisection and hangs

Bisection treats `Hang` as failure. Every `Hang` costs a `recover()`. If
a hang window exists — a band where the call neither returns nor errors
— record both its edges, and explicitly record any length inside it that
was **not** probed, in the same plainly-stated style the SPI comment
uses.

### TMP102 state

Read back CONFIG (`0x01`), TLOW (`0x02`), THIGH (`0x03`) before Phase B;
restore and verify after Phase C. Phases B and C only ever write the
1-byte pointer, so this should be a no-op. It is there to catch the case
where it is not.

## 5. Derivation rule

Fixed in advance, so the data cannot be rationalised after the fact.

**`PDG_I2C_MAX_BUFFER` becomes the largest length that returned across
every phase** — the minimum of the Phase A edge, the Phase B edge, and
the frontier's worst case.

If Phase C shows a shared budget rather than independent per-direction
limits, a single constant cannot express it faithfully. In that case the
constant takes the conservative value and the comment says outright that
the real constraint is a sum, that the driver's two separate checks
approximate it, and what a caller must do to stay safe. Overstating what
one number can encode is how this constant reached 4096 in the first
place.

Three publishable outcomes:

- **A real ceiling below 4096.** Lower the constant. Issue #146's
  "lowering would regress working behaviour" objection dissolves,
  because those writes are now known not to work.
- **4096 passes everything.** Keep the constant, replace its comment: it
  stops being an unmeasured bound kept out of caution and becomes
  measured and holding. This is a real result, not a null one.
- **A ceiling and a hang window.** Constant goes below the window; the
  comment documents the window's edges and the unprobed lengths inside
  it.

The comment is modelled on `PDG_SPI_MAX_BUFFER`'s, with the same four
parts: what was measured and on what hardware; what is still unknown,
stated plainly; the firmware hang and its recovery procedure if one was
found; and the follow-up warning against raising or lowering by
guesswork. It cites the date, board serial, firmware and schema
versions, and the fact that write probes ran against an unpopulated
address — a future reader needs to know the bus never ACKed in order to
judge whether the number transfers.

No claim is made that the number generalises beyond `i2c/write` and
`i2c/write-read` on firmware 0.11.0 / schema 0.7 on hardware revision 2.
One board, one firmware build, one host stack.

## 6. Deliverables

Branch `issue-146`.

**Code.** `PDG_I2C_MAX_BUFFER` set from the measurement, with the
rewritten comment. The check sites at `pdg_i2c.c:318` (running total for
writes) and `:342` (read check) need no logic change — that is still the
right shape — unless Phase C shows a shared budget, in which case the
read check's error message must stop implying the two limits are
independent.

**Documentation.** This is **not** a book-exempt Zephyr-only change. The
AGENTS.md §15.1 carve-out covers changes the book does not describe, and
the book already publishes claims this measurement will falsify or
sharpen.

| File | Change |
|---|---|
| `zephyr/drivers/i2c/pdg_i2c.c` | constant and comment |
| `zephyr/README.md` | I2C limitation table (`-EMSGSIZE` row, line 713) and a measured-limits paragraph mirroring the SPI one at line 547 |
| `zephyr/CHANGELOG.md` | under Changed, with full reasoning, matching how the SPI lowering was recorded |
| `book/src/interfaces/batching.md` | the "no general ceiling is published" row (line 278) is no longer true for I2C |
| `book/src/interfaces/i2c.md` | the I2C equivalent of the SPI containment note |
| `book/src/appendix/troubleshooting.md` | ditto, including the host-surface reachability warning — a Zephyr constant contains nothing outside Zephyr |
| `AGENTS.md` §13.17 | a new row, if a hang is found: same class as the three existing dispatcher-wedge rows |
| issue #146 | the measurement CSV and a results table, so the raw data outlives the session |

## 7. Verification

In order:

1. `cargo fmt --check` and clippy — unaffected, no Rust changes land.
2. `west build` of `zephyr/tests/pdg_i2c_burst` and the M5 targets
   against `~/zephyrproject`, proving the module still compiles and
   links with the new constant.
3. `twister` on `zephyr/tests/pdg_fake/i2c` — the one hardware-free
   suite that actually executes.
4. `mdbook build book` clean.

**Not claimed as verified:** that the Zephyr driver behaves correctly at
the new boundary on real hardware. `pdg_i2c_burst` is board-attached and
CI only links it. If the new constant is materially lower than 4096,
run `pdg_i2c_burst` on the board manually and say so; if that is not
possible, say that instead. A green build must not be allowed to imply a
behavioural result.

## 8. Open risks

- **A USB reset may not clear the wedge.** The SPI work observed
  recovery via `usbipd detach`/attach on Windows. `USBDEVFS_RESET` on
  Linux is the analogous operation, not the same operation. If it does
  not work, the sweep degrades to manual power-cycles; stop and report
  rather than pressing on.
- **Phase C may show a shape a single constant cannot express.**
  Handled by the derivation rule in §5, but it changes the
  documentation burden.
- **Repeated wedge/reset cycles are the one genuinely aggressive part
  of this plan.** Firmware-level hangs recovered by USB reset, on a
  development board. Judged acceptable for this board and this
  measurement.

## 9. References

- Issue #146; issue #102, the burst-write fix this was split out of
- AGENTS.md §13.17, 2026-08-19 — the SPI framing measurement
- `zephyr/drivers/spi/pdg_spi.c`, the `PDG_SPI_MAX_BUFFER` comment
  (lines 194–234)
- `zephyr/CHANGELOG.md`, "Known Issues" and "Breaking Changes"
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

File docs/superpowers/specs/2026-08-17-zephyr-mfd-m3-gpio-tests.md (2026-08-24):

# Zephyr MFD restructure M3 — adversarial probe suite

Date: 2026-08-17
Branch: `zephyr`
Milestone: M3 — additive `pdg_gpio` controller
Source of truth: `docs/superpowers/specs/2026-08-17-zephyr-mfd-m3-gpio.md`
Written black-box against the spec. **No implementation was read; none exists.**

---

## 0. Assurance boundary — read this first

Nothing on this branch has ever executed (plan §9.3). M5 is the first milestone
that runs anything. There is no `zephyr/tests` directory and M2 resolved
"invent a test framework" as out of inventory. These probes are therefore
**ephemeral**: overlays and Kconfig fragments are materialised into `/tmp` at
execution time, greps are run from a shell, and nothing is added to the
repository.

Every probe below is labelled with exactly one class:

| Class | Meaning | Strength |
| --- | --- | --- |
| **A** | Compile-time provable now. A build that must succeed, or must fail with a *named* diagnostic substring. | Real gate. |
| **B** | Source-structural. A grep/awk assertion that a required construct exists, or a forbidden one does not. | Weaker than execution. Proves shape, never behaviour. |
| **C** | Requires execution. **Cannot be verified in M3 at all.** Listed, deferred, owned by a named later milestone. | No assurance in M3. |

**No Class C case is disguised as A or B.** Where a runtime behaviour has a
structural shadow, the structural probe is listed as B and the behaviour is
*separately* listed as C. Passing the B probe is not evidence for the C case.

### 0.1 Precedent this suite is bound by

- M1's harness test **T10 was explicitly criticised** for grepping the bare
  string `mix`, which an under-documented binding satisfied by luck
  (plan §8.3). Every Class B probe below therefore asserts on **structure with
  positional constraints** (function extents, byte offsets, exact counts),
  never on a lone word that could appear in prose.
- Plan §9.1 records that `pdg_[a-z_]*\.c` **can never match `pdg_i2c.c`** —
  digits are excluded. Every TU grep here uses `pdg_[a-z0-9_]*\.c`.
- #104 acceptance confirmed its suite by **re-introducing the bug** and
  observing 3 of 7 tests fail. §5 below specifies mutations for the strongest
  probes on the same principle.

---
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

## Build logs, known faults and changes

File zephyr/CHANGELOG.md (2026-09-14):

# Changelog

All notable changes to the Pico de Gallo Zephyr module will be documented in
this file.

The format is based on
[Keep a Changelog](https://keepachangelog.com/en/1.1.0/).

## [Unreleased]

### Changed

- `PDG_SPI_MAX_BUFFER` is now **1014**, up from 1013, and moved from
  `drivers/spi/pdg_spi.c` to `drivers/spi/pdg_spi_bottom.h`. Refs #158.

  The old value was measured rather than derived, and was off by one against
  the real edge. It came from the M5 acceptance run, which probed 1013
  (worked) and 1015 (hung) but never 1014, and so could not narrow the
  boundary without stepping into the hang. Issues #179 and #158 closed both
  gaps: the ceiling is now derived exactly as `1024 - 7 - 1 - 2 = 1014` from
  postcard-rpc's host inbound transfer buffer, and 1014/1015 were measured
  directly on `spi/transfer`.

  Every Zephyr SPI operation reaches the device through one full-duplex
  `gallo_spi_transfer()`, so the binding limit is what a single *response*
  frame can carry. `pdg_spi_bottom.c` now carries a `_Static_assert` tying
  the constant to the FFI's `GALLO_MAX_RESPONSE_PAYLOAD`, so drift is a build
  failure. That is the "one shared contract rather than a constant duplicated
  per consumer" the old FOLLOW-UP comment asked for; contrary to the
  expectation recorded there, it needed no wire-format or schema change.

  Three claims attached to the old constant are superseded and are recorded
  as such rather than deleted: that the 1013/1024 relationship was
  "SUGGESTIVE ONLY" with "no evidence" for a framing decomposition (there is
  now, and it is exact); that duplex was unverified above 512 bytes
  (`spi/transfer` *is* the duplex endpoint and was measured at 1014); and
  that a 1015-byte transfer wedges the dispatcher device-wide (#158 could not
  reproduce this on firmware `62dd64e710fd` — a non-reproduction on one
  build, not proof it never happened).

- `M5_SPI_CEILING` in `tests/pdg_mfd_m5/acceptance` tracks the new value, so
  its over-ceiling probe is now 1015. The `BUILD_ASSERT` that previously
  forbade any T5 case from reaching 1015 is retired deliberately, with the
  reasoning recorded inline: 1015 is refused by `bufset_len_()` with
  `-EMSGSIZE` before any transport call, which is exactly what T5b and T5c
  assert, so it cannot reach the wire from this test.

- The module's local checks are no longer the only containment. Issue #158
  made `pico-de-gallo-lib`, the C FFI, Python, MCP and the `gallo` CLI all
  refuse over-ceiling payloads locally, so `zephyr/README.md` no longer
  claims otherwise.

### Added

- A `pwm` driver, `drivers/pwm/pdg_pwm.c`, as a child of the
  `odp,pico-de-gallo` MFD parent, with the binding
  `dts/bindings/pwm/odp,pico-de-gallo-pwm.yaml`. Refs #155.

  Four channels, 0 to 3, map to RP2350 GPIO12 through GPIO15.

  `pwm_get_cycles_per_sec()` reports the 150 MHz PWM **source** clock, not
  the counter rate. The counter advances at `150e6/divider`, which changes
  with every frequency change and differs between the two slices, so it could
  not serve as the stable per-device constant Zephyr's API requires.
  Reporting the source clock makes `period_cycles` independent of the
  divider — which matters, because the divider is not on the wire and the
  driver cannot observe it.

  The frequency is derived with a **ceiling**, not a floor. Flooring
  lengthens the period and forces a larger divider; at the maximum supported
  period it yields 8 Hz, which needs divider 287 and panics inside
  embassy-rp. Ceiling yields 9 Hz, which needs exactly 255. The driver
  therefore refuses any period above `255 * 65536 = 16711680` cycles with
  `-ENOTSUP`, and any period below 2 cycles with `-EINVAL`. The upper bound is
  **containment of #192, not a fix**: the underlying firmware defect remains
  reachable from the CLI, `pico-de-gallo-lib`, the C FFI, Python and MCP.

  Channels 0+1 and 2+3 each share an RP2350 slice, which has a single period
  and a single enable. A channel requesting a period differing from its
  sibling's is refused with `-EINVAL` rather than silently changing the
  sibling's period. The firmware rescales both compares with truncating
  integer division on every reconfiguration, which would drift a sibling's
  duty downward. This driver never has to compensate: the conflicting-period
  refusal means a slice is never reconfigured while its sibling is in use, so
  the drift is unreachable rather than mitigated. The driver enables a slice
  on first use and **never disables one** — a zero pulse already gives a
  constant-low output, and disabling would stop the sibling channel.
  `drivers/pwm/pdg_pwm_bottom.h` declares no disable function at all, so that
  is structurally enforced rather than merely documented.

  `PWM_POLARITY_INVERTED` returns `-ENOTSUP` and is deliberately not
  emulated by inverting the duty cycle, which would change the idle level
  rather than the polarity. Phase-correct mode is never requested.

  Coverage is `tests/pdg_fake/pwm`, executed by twister with no board
  attached. PWM cannot currently be verified on hardware in this project, so
  this suite is the primary evidence rather than a supplement to a hardware
  demo. Its fake models the firmware's `compute_pwm_params()` — including
  stopping the divider search at 255 rather than the firmware's 4095 — so
  the full-scale duty it reports is realistic and a test cannot pass on a
  configuration that would take down a real board.

  The suite also carries the same best-effort post-link `nm` gate as
  `tests/pdg_fake/uart`, `verify_overrides.cmake`. It has nothing to catch
  today, because all five declared bottom functions are overridden; it exists
  for a future sixth, which would otherwise resolve to the weak production
  definition and hand the fake's opaque non-pointer token to the real FFI
  without any link error.

- A `pwm_fade` sample under `samples/`, build-only.

- `scripts/ci-build.sh` gained the `pwm_fake` and `pwm_fade` build targets,
  bringing the table to fifteen. `pdg_pwm.c` and `CONFIG_PWM_PICO_DE_GALLO`
  joined the two-sided translation-unit and Kconfig assertion sets, so a
  target that compiles the PWM driver without asking for it now fails.

- Added `samples/uart_bridge`, a bounded, polling-only example for
  `uart_poll_out()` and `uart_poll_in()`. Its Twister scenario is build-only:
  running it reaches `gallo_init_strict()` and requires a USB-attached board and
  UART peer.

- Added the executed `tests/pdg_fake/uart` recording-fake suite with two
  scenarios: `drivers.pico_de_gallo.uart.fake` (14 cases with UART capability)
  and `drivers.pico_de_gallo.uart.fake_no_capability` (3 cases without it),
  selected by the compile-time `PDG_FAKE_UART_CAPABILITY` cache variable. A
  measured Twister run on `native_sim/native/64`, together with the existing
  two-case I2C fake, passed 3/3 configurations and 19/19 test cases.

  Five dedicated UART children use distinct 115200, 57600, 38400, 19200 and
  9600 baud rates so initialization calls can be attributed despite their
  shared parent context. Dedicated instances isolate permanent transport
  latches; `CONFIG_ZTEST_SHUFFLE` remains off. The shared parent fake now also
  records a latched close count, which the suite requires to remain zero because
  children borrow and must never close the parent connection.

  Executed coverage includes ISR-context refusal results and bottom-call
  suppression; exact empty-ring `uart_poll_in() == -1`; one refill serving
  eight polls with one bottom read; one write per byte; accepted and rejected
  configuration transcription including mark/space parity and both stop-bit
  counts; cache updates only after acknowledged success; async/wide
  `-ENOTSUP` stubs; RX/TX transport latches that suppress every subsequent call
  in the bounded tested sequence, including staged-ring discard;
  10 ms non-transport backoff with a post-deadline recovery attempt; and the
  capability gate, whose capability/configuration ordering is asserted in
  aggregate only.

  This is top-half control-flow and argument-recording evidence only. The fake
  bypasses USB, firmware, postcard framing and real FFI status mapping. It does
  not observe the private diagnostics, prove ISR-guard-before-mutex ordering,
  prove explicit backoff clearing, reach pre-kernel guards, contend the mutex,
  exercise console reentrancy, or establish physical timing, framing,
  backpressure, firmware-ring, baud-clamp or lost-ack behaviour. M7 later
  measured a subset of those properties; the board-attached entry below records
  exactly which ones and which gaps remain.

- Added `tests/pdg_board/uart`, a plain, board-attached `main()` application for
  `uart_configure()` / `uart_config_get()`, loopback masking, frame-length
  timing, invalid configuration mapping, and baseline restoration. Its Twister
  scenario is `board.pico_de_gallo.uart.loopback` with `build_only: true`, and
  `zephyr/scripts/ci-build.sh` registers it as the thirteenth target,
  `board_uart`. It requires TX (GPIO 0) physically shorted to RX (GPIO 1).

  The committed `app.overlay` retains a placeholder serial. Operators append a
  scratch overlay outside the repository with
  `-DEXTRA_DTC_OVERLAY_FILE=/path/to/serial.overlay`; using
  `DTC_OVERLAY_FILE` would replace `app.overlay` and lose its UART child.
  `CONFIG_UART_USE_RUNTIME_CONFIGURE=y` is load-bearing because otherwise
  `uart_configure()` returns `-ENOSYS`.

- M7 hardware verification ran on board `5256657D8A5D7F03`, firmware
  `firmware-v0.11.0-109-g6c4d42fd0796` (firmware 0.12.0, schema 0.8.0,
  `hw-rev2`), with TX and RX shorted. This was the first execution of the driver
  against real hardware.

  The `uart_bridge` sample echoed all 27 greeting bytes exactly. Runtime
  configure/get worked; stable 7N1 returned `7f 00 55 2a` and restored 8N1
  returned `ff 00 55 aa`. All four widths produced the expected masks: 8, 7,
  6, and 5 bits returned `ff 00 55 aa`, `7f 00 55 2a`, `3f 00 15 2a`, and
  `1f 00 15 0a`. Invalid baud 0 and unsupported data bits remained distinct at
  `-EINVAL` (-22) and `-ENOTSUP` (-95).

  Frame-length timing fitted 6.18 ms per bit per character against a physical
  prediction of 6.67 ms (93%); a stale framing register would have produced a
  zero slope. The roughly 143-baud divisor floor, previously inferred from
  embassy-rp, measured about 147 baud, with convergence beginning between 143
  and 100.

  RX-ring overflow closed the driver's highest-risk unverified premise. Sending
  1280 bytes without an intervening read against the 1024-byte firmware ring
  produced one `Endpoint(Other)` and then recovery in all 3 trials; both
  no-overflow controls had no error. Exactly 1024 bytes arrived in order with
  four write-boundary discontinuities. A wrong-serial strict open also refused
  in 511 ms, named the selector, and did not fall back to the attached board.

  Odd/even and mark/space parity remain unverified: one PL011 drives both ends,
  and all four 11-bit configurations loop back cleanly. Their medians (511.5,
  511.1, 411.5, and 514.3 ms) were statistically indistinguishable. An
  independent UART peer or logic analyser is required. A v1.0 board is required
  for the `hw-rev1` capability refusal. Unplug/re-enumeration/reset,
  transport-fault and lost-ack injection, TX saturation, active-console faults,
  and direct observation of embassy's `rx_error` and RX interrupt-enable bits
  also remain untested; the last item requires RTT or a debugger.

  Two method limits are now recorded. `native_sim` time is simulated under
  `CONFIG_NATIVE_SIM_SLOWDOWN_TO_REAL_TIME=y`, so drain milliseconds advance
  through polling sleeps rather than directly measuring wall time, although the
  slope remains physical. Separate `gallo` write/read processes are unusable
  for timing because startup costs 200–300 ms, measurements quantize near
  100 ms, and the line drains between processes; a control produced the
  9600-versus-115200 difference with the wrong sign. Future timing work must
  keep write and read in one process.

- Added the polling-only `odp,pico-de-gallo-uart` controller as a direct child
  of the `odp,pico-de-gallo` MFD parent, with its devicetree binding, Kconfig,
  disabled shield node and build wiring. The child borrows the parent-owned
  connection. Because UART drives two physical pads, every enabled instance
  requires `serial-number` on its parent, as GPIO and SPI do. Part of #152.

  The implemented API is `uart_poll_in()`, `uart_poll_out()` and
  `uart_err_check()`, plus `uart_configure()` and `uart_config_get()` under
  `CONFIG_UART_USE_RUNTIME_CONFIGURE`. The asynchronous and interrupt-driven
  APIs are unsupported. Async slots that Zephyr dispatches without checking
  for `NULL` carry side-effect-free `-ENOTSUP` stubs solely to prevent a crash
  when another driver enables the global async API.

  This controller is thread-context-only: no callback may be used from an ISR
  or before the kernel is up. It cannot serve as an early console because it
  initializes at `POST_KERNEL`, while the `CONFIG_EARLY_CONSOLE` hook installs
  at `PRE_KERNEL_1`; choosing this instance as that console is rejected at
  build time.

  Receive uses a 1014-byte staging ring. An empty ring causes one refill with
  `timeout_ms = 0`, selecting the firmware's single-poll branch; a refill can
  then serve many polling calls. On board `5256657D8A5D7F03`, firmware
  `firmware-v0.11.0-109-g6c4d42fd0796`, an empty refill measured about 359 us,
  versus about 1489 us with `timeout_ms = 1` and about 1422 us before the
  firmware fast path. The superseded 1 ms design therefore cost 4.15x as much
  per idle poll and retained -6% of the optimization. Transmit is deliberately
  unbuffered at one round trip per byte because the firmware already owns an
  interrupt-drained TX ring and the polling API provides no flush hook for a
  second ring.

  `uart_poll_out()` returns `void`, so an unsent or indeterminately delivered
  byte is counted in a private dropped-byte counter and never logged. Logging
  through the same UART would recurse once per character. No failed write is
  retried automatically because its byte may already have been queued before
  the acknowledgement was lost.

  A confirmed `-ECOMM` or `-ETIMEDOUT` permanently latches transport failure,
  discards staged receive bytes and makes later polling calls fail fast without
  another RPC; there is no reconnect path during the device lifetime. A
  non-transport refill error is not permanently latched, because the next read
  drives firmware receive-error recovery, but it receives a 10 ms backoff --
  larger than the approximately 359 us refill round trip -- to prevent an
  unbounded tight loop of RPCs. Both firmware branches call
  `AsyncRead::read()`, whose first poll reaches Embassy `try_read()`, consumes
  the latched `rx_error` and re-enables RX interrupts. There is deliberately no
  `read_ready()` shortcut because it inspects only the software ring and would
  leave the error latched forever.

  Initialization gates the controller on `GALLO_CAP_UART`, so `hw-rev1` fails
  with `-ENODEV` instead of silently swallowing transmitted bytes. This is not
  a cached lookup: it costs a second `device/info` round trip after the parent
  has already validated the connection.

  Supported configuration is 5--8 data bits, none/odd/even/mark/space parity,
  1 or 2 stop bits and no flow control; other framing and flow-control values
  return `-ENOTSUP`. `uart_config_get()` reports the last successfully
  **requested** configuration, not the achieved one: firmware clamps the baud
  divisor to a floor of roughly 143 baud. Reconfiguration is not atomic, and
  clearing the local receive staging cannot identify bytes already decoded in
  the firmware under the old framing, so callers must quiesce and drain both
  directions first.

  `uart_err_check()` returns 0 for a healthy initialized thread-context call
  and never invents `UART_ERROR_*` bits. Firmware collapses all UART line
  errors into one variant, so receive overrun is silent at every layer; exact
  driver health remains in private counters rather than the UART error mask.

  The configuration ABI has two compile-time gates. `_Static_assert`s tie the
  neutral 4 data-bit, 5 parity and 2 stop-bit selectors to the FFI enums, while
  `BUILD_ASSERT`s pin the Zephyr-to-neutral mapping used at runtime. Reordering
  a mirrored wire enum therefore fails the build instead of silently selecting
  different framing.

  `zephyr/scripts/ci-build.sh` now has a tenth target, `uart_driver`, which
  compiles and links the MFD parent and UART top and bottom halves. Its
  two-sided translation-unit and Kconfig universes now cover all five drivers,
  so the other nine targets also prove that UART remains absent when disabled.

  The worst-case mutex hold for a lost refill reply is the host library's
  ordinary call timeout, 5 seconds by default. The previous 30-minute hazard
  was real: `bounded_for(0)` interpreted zero with the GPIO meaning of "no
  caller deadline". The host library now special-cases UART in
  `uart_read_bound()`, pinned by
  `uart_read_bound_zero_timeout_is_the_call_bound` and
  `uart_read_bound_nonzero_timeout_still_tracks_the_firmware`. The 5-second
  mutex bound and the capability probe's 300 s ceiling are **derived from
  constants in `crates/`, not measured**. No M5, M6 or M7 test can drive the
  refill bound because the M6 fake bypasses the transport and unplug produces
  a fast `-ECOMM`.

  **M5 evidence was compile-and-link only: no runtime test and no hardware test
  was performed.** M6 later added the recording-fake coverage above, and M7 has
  now completed the scoped hardware campaign recorded above, including RX-error
  latch recovery. The listed equipment-dependent gaps remain.

- `pdg_common_status_to_errno()` maps the new `CallTimeout` status to
  `-ETIMEDOUT`. Refs #178.

  `CallTimeout` means the request was sent but no reply arrived, with the
  transport and the board both very likely healthy — hence `-ETIMEDOUT`
  rather than `-EIO`. For a batch operation the transaction's fate is
  unknown, so a caller must not retry blindly.

  This case was mandatory rather than optional: the switch carries no
  `default:` and the drivers build with `-Werror=switch`, so the module would
  not compile until it was added. Working as designed.

### Breaking Changes

- **A zero-length I2C write now returns `-ENOTSUP` rather than `-EINVAL`.**
  Callers that passed a non-`NULL` buffer with `len == 0` previously reached
  `gallo_i2c_write(..., 0)` and got `InvalidArgument` → `-EINVAL` back from the
  host-surface guard (#136), or `I2cError::ZeroLengthWrite` from the firmware
  before it (#101). The group is now classified as an address-only probe and
  refused locally, with an errno that names the reason. Callers that were
  probing this way should either enable
  `CONFIG_I2C_PICO_DE_GALLO_PROBE_WITH_READ` or use a 1-byte read.
  ([#137](https://github.com/OpenDevicePartnership/pico-de-gallo/issues/137))

- **The Zephyr SPI driver now rejects transfers over 1013 bytes.** Transfers
  above it return `-EMSGSIZE`
  locally, before any allocation, controller lock, set-config or chip-select
  edge. Applications transferring more than 1013 bytes in one call must split.
  If you are designing around large SPI transfers through this bridge, plan for
  this.

  `PDG_SPI_MAX_BUFFER` was previously documented as
  `pico_de_gallo_internal::MAX_TRANSFER_SIZE`, the "firmware single-transfer
  limit". That was wrong, and the wrong mental model produced two wrong values
  in succession. The constant is a **packet-buffer budget** that must hold the
  payload *plus* the postcard-rpc header, the length varint and the COBS
  framing, and it must cover the **request** frame *and* the **response**
  frame, so usable payload sits strictly below it:

  - **4096** (`MAX_TRANSFER_SIZE`) — 4096 TX-only passes the local check,
    reaches the transport and fails `-ECOMM`.
  - **3072** — a "conservative" guess reasoned from the firmware's
    `PacketBuffers<MAX_TRANSFER_SIZE + 1024>` headroom. 3072 **full duplex**
    also fails `-ECOMM`. That reasoning considered only one direction.
  - **1013** — the largest TX-only length measured to work on hardware.

  Every observed failure was `-ECOMM` and never `-EMSGSIZE`, so the transport
  was always the limiter and the compiled constant never was.

  **1013 is measured, not derived, and the picture is incomplete:** the TX-only
  boundary is unresolved between 1013 and 1015 (1014 was never probed, and 1015
  hangs); full duplex succeeded at 512, failed at 3072, and was not tested from
  513 through 1013; and while 1013 sits just under 1024 in a way
  that would be consistent with a ~1 KiB budget and ~11 bytes of framing, there
  is no evidence for that decomposition and it must not be relied on.

  Still owed: derive the usable `spi/transfer` payload ceiling from the
  worst-case request and response framing, express it as one generated or
  shared contract instead of a constant duplicated per consumer, and pin limit
  and limit+1 tests against it. That requires a wire-crate change with schema
  and lockstep-release implications, so it is out of scope for this module.

  Applications needing a documented-safe duplex size must use 512 bytes or
  less. `PDG_SPI_MAX_BUFFER = 1013` is containment, not a duplex-capacity
  guarantee, and the 4096 protocol constant is a packet-buffer/argument bound,
  not a demonstrated end-to-end application-payload guarantee.

- The `odp,pico-de-gallo-i2c` and `odp,pico-de-gallo-spi` controllers must
  now be **direct children of an enabled `odp,pico-de-gallo` parent**. A
  controller at the devicetree root, under a disabled parent, under an
  unrelated parent, or nested more than one level deep is rejected at build
  time with an explanatory static assertion rather than an unresolved device
  ordinal at link time.

- `serial-number` **moved from the controllers to the parent**. It is no
  longer declared on either controller binding, so a leftover child property
  fails devicetree processing with an undeclared-property error naming the
  node and the binding; it is not silently ignored. The parent's selection
  applies to all of its children. Omitting it remains safe only when exactly
  one matching board is physically attached: the host API cannot report which
  board it chose, and the build-time multi-parent check counts devicetree
  parents, not attached USB devices.

- The shield's controller nodes were renamed and reparented: `/pdg-i2c` and
  `/pdg-spi` are now `/pico-de-gallo/i2c` and `/pico-de-gallo/spi`. **Absolute
  devicetree node paths and the generated identifiers and dependency ordinals
  derived from them change accordingly.** The `pdg0`, `pdg_i2c0` and
  `pdg_spi0` labels are unchanged, so overlays that use `&pdg_i2c0` /
  `&pdg_spi0` continue to resolve; overlays or code referring to the absolute
  paths must be updated. Sample and application overlays must now also enable
  `&pdg0`.

- The parent is now the sole owner of the board's USB handle; the controllers
  borrow it and never close it. Happy-path I2C and SPI transfer behaviour is
  unchanged. Initialization ownership, failure coupling, failure location and
  worst-case boot latency change: one parent validation now gates both
  children. Physical USB opens were already deduplicated to one and remain
  one; registry calls and references drop from three to one. A parent open
  failure now fails both controllers coherently, at the parent's
  `POST_KERNEL/CONFIG_MFD_PICO_DE_GALLO_INIT_PRIORITY` (default
  `KERNEL_INIT_PRIORITY_DEFAULT`, currently 40) rather than the controllers'
  `POST_KERNEL/50`, and the
  worst case falls from as many as three independent five-minute strict opens
  to one attempt plus two fast child failures. The cost is that a controller
  can no longer initialize independently of the parent.

- The SPI controller now uses **standard Zephyr `cs-gpios`**, and the
  temporary Pico-de-Gallo-specific chip-select index property has been
  **deleted**. `cs-gpios` is
  **required** on every enabled controller — a missing property fails
  devicetree processing, because the bridge has no native chip select to fall
  back to — and an SPI child node's `reg` regains its ordinary Zephyr meaning
  as an index into that array. Every entry must target an **enabled**
  `odp,pico-de-gallo-gpio` controller under the **same** `odp,pico-de-gallo`
  parent; a foreign controller, a disabled sibling, and a Pico de Gallo GPIO
  controller belonging to a *different* parent are each rejected at build time
  with an assertion naming the `cs-gpios` array index. The cross-parent case is
  the reason the check exists: it is a real, enabled Pico de Gallo GPIO port on
  a *different physical board*. The parent of an enabled SPI controller must
  now also define `serial-number`, as the GPIO child already required, because
  chip select actuates a physical pin. Enabling `&pdg_gpio0` is consequently a
  prerequisite for SPI. `GPIO_ACTIVE_HIGH` is permitted in `cs-gpios`;
  `SPI_CS_ACTIVE_HIGH` remains `-ENOTSUP`. This supersedes the temporary
  index-mapping property introduced for #104, which never shipped in a
  release; the underlying "`reg` is not a firmware GPIO index" fix is preserved
  by `cs-gpios` giving `reg` its standard meaning.

- **Chip select is no longer atomic with the data phase.** The Zephyr module
  stopped using the `spi/batch` firmware endpoint and now issues
  `spi/set-config`, `gpio/put` (assert), `spi/transfer` and `gpio/put`
  (deassert) — four USB round trips on an ordinary successful transceive, each
  independently fallible. Host death after the assert can leave chip select
  asserted; recovery is a fresh session that deasserts the pin, or a
  power-cycle. Only RPCs that return have defined behaviour: one that never
  returns leaves the call pending forever with no errno, no cleanup and the SPI
  lock still held. The non-Zephyr `spi/batch` APIs (`gallo` CLI, Rust, C,
  Python, MCP) are unchanged and remain fully supported.

  Zephyr also collapses `spi-cs-setup-delay-ns` and `spi-cs-hold-delay-ns` into
  a single `DIV_ROUND_UP(MAX(setup_ns, hold_ns), 1000)` microsecond value
  applied at *both* edges, instead of the batch path's separately honoured
  setup and hold delays. Read-only and write-only transfers are now full-duplex
  transfers of `max(tx_len, rx_len)` bytes with zero-filled TX or discarded RX.

- `SPI_HOLD_ON_CS` is now supported, but **requires `SPI_LOCK_ON`** and returns
  `-ENOTSUP` without it: holding chip select while another configuration could
  select a second slave would leave two peripherals selected at once. A
  successful hold commits received data and retains both the asserted line and
  the bus lock until `spi_release()` is called with that same configuration.
  `SPI_LOCK_ON` is likewise now supported; both were previously rejected.

- Added a **chip-select fault latch**. If a forced deassert returns an error
  the driver cannot tell whether the line went inactive, so the controller
  latches and every later transceive returns `-EHOSTDOWN` before issuing any
  configuration, chip-select edge or clocking. Only a `spi_release()` whose
  checked deassert succeeds clears it; a failed release still releases software
  ownership so nothing wedges, but retains the latch and the exact
  configuration pointer so recovery can be retried. Received data is committed
  only after an acknowledged deassert or a successful deliberate hold — a
  transfer that succeeds but whose deassert fails returns the deassert errno
  and does not commit RX.

- The SPI controller now initializes at
  `CONFIG_SPI_PICO_DE_GALLO_INIT_PRIORITY` (new, default 50) instead of
  `CONFIG_SPI_INIT_PRIORITY`, and **configures every declared chip-select pin
  as an explicit inactive output at init** — two USB round trips per pin, in
  ascending array order. That couples SPI initialization to the GPIO child:
  the SPI priority must be greater than
  `CONFIG_GPIO_PICO_DE_GALLO_INIT_PRIORITY` (45), which must be greater than
  `CONFIG_MFD_PICO_DE_GALLO_INIT_PRIORITY` (40). Kconfig cannot check the
  arithmetic, so runtime readiness is authoritative: an inversion returns
  `-ENODEV` before configuring any pin. There is no rollback on failure —
  earlier entries are acknowledged inactive, the failing entry is
  indeterminate, and later entries were never issued. `-EBUSY` means a firmware
  GPIO event subscription owns the pin; reset it explicitly with
  `gallo_system_reset_subscriptions()` after a strict open, or power-cycle.

- A declared chip-select pin must be owned **exclusively** by SPI. The GPIO
  child being the sole *driver path* for the pin's mode is not an ownership
  reservation; a direct GPIO consumer can reconfigure or drive it between SPI
  operations and nothing detects it. This is an application obligation.

### Changed

- **The Zephyr I2C driver now uses separate read and write limits.** The old
  `PDG_I2C_MAX_BUFFER = 4096` treated
  `pico_de_gallo_internal::MAX_TRANSFER_SIZE` as an end-to-end limit in both
  directions. That was wrong for reads: the constant bounds wire arguments and
  packet buffers, while returned data must still fit response framing.

  Hardware measurement on 2026-09-01 found a 1014-byte read edge. Reads of 1014
  bytes returned exactly 1014 bytes. The 1015-byte probe failed in about 99 ms;
  larger tested lengths returned the same host-side response decode error,
  `Postcard(DeserializeUnexpectedEnd)`, with increasing latency, reaching 391 ms
  at 4096. No dispatcher wedge or hang was found at any tested I2C length. This
  records the observed test range, not a proof that no I2C hang window exists.

  The write limit remains 4096, but its meaning is now explicit. No failing
  write request length was observed from 1 through 4096: every request crossed
  USB intact, was decoded, initiated a bus transaction and returned the
  expected address NACK in 1--4 ms. The address was unpopulated, so no payload
  byte was clocked. This verifies request framing at 4096, not successful
  bus-level clocking of a 4096-byte payload. The probe could go no higher because
  4096 is `MAX_TRANSFER_SIZE`.

  Only write length 1 was paired with the read sweep. The available TMP102
  rejects longer writes, so whether the write/read frontier is rectangular or
  diagonal was not observed. Independent per-direction bounds are an
  **inference from mechanism**: a shared roughly 1015-byte framing budget is
  hard to reconcile with a 4096-byte write request being delivered, decoded and
  initiating a bus transaction, while the read failure occurs during response
  decoding and writes travel in the request. Closing that measurement gap
  requires a target that accepts long writes.
  ([#146](https://github.com/OpenDevicePartnership/pico-de-gallo/issues/146))

### Added

- **Twister metadata, initially for seven buildable applications**, and a
  `twister` job in `.github/workflows/zephyr.yml` that processes them.
  ([#109](https://github.com/OpenDevicePartnership/pico-de-gallo/issues/109))

  The file is `tests.yaml`, not `sample.yaml` or `testcase.yaml`. Upstream has
  retired both older names: against `zephyrproject-rtos/zephyr`,
  `filename:sample.yaml` and `filename:testcase.yaml path:tests/drivers` each
  return zero results, while `tests/drivers` alone holds 268 `tests.yaml`.
  Samples keep their `sample:` key inside `tests.yaml`.

  At introduction, every scenario was `build_only: true`. M6 expanded the
  inventory to ten files and eleven scenarios. The board-attached UART
  application later brought it to eleven files and twelve scenarios: nine are
  build-only, while the I2C fake and two UART fake scenarios execute without
  hardware. None
  declares `depends_on`, because that key matches the board's `supported:` list
  and `native_sim/native/64` names neither `i2c`, `spi` nor `uart` — only the
  32-bit `native_sim` does — so claiming one would silently filter the scenario
  to nothing on the sole platform this module targets.

  This is mostly redundant with `zephyr/scripts/ci-build.sh`, and weaker: there
  is no twister equivalent of that script's two-sided translation-unit and
  Kconfig assertions. It is worth having for two things `ci-build.sh` cannot do.
  Twister forces `CONFIG_COMPILER_WARNINGS_AS_ERRORS=y` **and**
  `--edtlib-Werror`, turning devicetree *binding* warnings into build failures
  — this module ships four custom bindings and a plain `west build` never
  checks them that way. And `type: unit` scenarios run only under twister.

  `samples/spi_bridge` and `samples/combined_i2c_spi_bridge` deliberately get no
  `tests.yaml`. They cannot build (the IS31FL3743B driver is not upstream), and
  `ci-build.sh`'s `assert_basefail()` already pins their failure far more
  precisely than a twister scenario could — it requires exactly one undefined
  `__device_dts_ord_N` resolving to an `is31fl3743b` node.

- `CONFIG_I2C_PICO_DE_GALLO_PROBE_WITH_READ` (default `n`). Substitutes a
  1-byte read to the same address for an address-only probe: an ACK means the
  device is present, a NACK surfaces as `-ENXIO`. That makes Zephyr's shell
  `i2c scan` work, at one blocking USB round trip per address — about 116 for
  the `0x04..0x77` range the shell scans.
  ([#137](https://github.com/OpenDevicePartnership/pico-de-gallo/issues/137))

  Selected with `IS_ENABLED()` inside an ordinary `if`, never `#ifdef`, so both
  arms compile in every configuration.

  It is off by default for two reasons that must be documented rather than
  discovered. A read probe is **not** semantically identical to a write probe:
  a write-only device may acknowledge its write address while NACKing its read
  address, so a scan performed this way can under-report — the same known
  limitation the firmware's own `i2c/scan` carries. And the substituted read
  consumes a byte, which can pop a FIFO or step an EEPROM address pointer;
  Zephyr's own `i2c_shell.c` carries the same warning, that scanning "can
  confuse your I2C bus, cause data loss, and is known to corrupt the Atmel
  AT24RF08 EEPROM". A bus scan is a deliberate act, whereas a driver silently
  turning every zero-length write into a read is not.

  The supported way to scan through this bridge remains `gallo i2c scan`, or
  the firmware's `i2c/scan` endpoint, which probes the whole bus in one round
  trip.

- `CONFIG_HEAP_MEM_POOL_ADD_SIZE_PDG_I2C` (default 8192). The I2C driver now
  `k_malloc()`s a merge buffer for a group holding two or more non-empty
  writes, at most `PDG_I2C_MAX_WRITE` (4096) bytes and at most one live at a
  time. Declaring the contribution is mandatory, not optional: `k_malloc()`
  lives in `kernel/mempool.c`, which Zephyr compiles only when the system heap
  is non-empty, and `CONFIG_HEAP_MEM_POOL_SIZE` defaults to 0 — omitting it
  reproduces #111 exactly, as an undefined reference to `k_malloc` at link
  time.

  Nothing allocates on the common paths. A single message, a single write
  followed by a read, and a group whose writes are all empty are each sent
  straight from the caller's buffers with no copy. Excluding the all-empty case
  from the merge path is deliberate: an empty payload has nothing to merge, and
  allocating for it would introduce an `-ENOMEM` failure mode on a call that
  can otherwise not fail locally. An all-empty group no longer reaches the
  firmware at all: #137 reduces it to an address-only probe and refuses it
  locally, described under *Fixed* above.

- `tests/pdg_i2c_burst`, a board-attached regression image for #102. Covers
  `i2c_burst_write()`, a three-message hand-rolled gather, a gathered
  write-then-read, the three rejection shapes, and the per-group running total
  — including that the oversize rejection emits no bus traffic at all. Every
  assertion compares against a reference read-back through a single-message
  `i2c_write()` rather than against the bytes written, so it holds on parts
  that mask register bits. Registered in `zephyr/scripts/ci-build.sh`, which
  brings the CI target count to nine; that gate builds and links it but, like
  every other target, never runs it.

- CI gate (`.github/workflows/zephyr.yml`) building the module against a pinned
  Zephyr revision on `native_sim/native/64`, driven by
  `zephyr/scripts/ci-build.sh`. Covers the two viable samples, baseline-failure
  assertions for the two IS31 samples, and the four M5 test applications.
  At introduction this was build-only and added no runtime coverage; M6 later
  added the executed recording-fake scenarios described above.
  ([#130](https://github.com/OpenDevicePartnership/pico-de-gallo/issues/130))

- Added the `odp,pico-de-gallo-gpio` devicetree compatible and its Zephyr GPIO
  controller driver. The controller is a direct child of an enabled
  `odp,pico-de-gallo` parent, borrows the parent's USB connection and never
  releases it, and initializes at `POST_KERNEL/45` — after the parent
  (`KERNEL_INIT_PRIORITY_DEFAULT`, currently 40) and
  before the I2C and SPI controllers (50). The shield ships one **disabled**
  `pdg_gpio0` node with `ngpios = <4>`.

  - The parent of every enabled GPIO child **must** define `serial-number`; a
    missing selector is rejected at build time, because GPIO actuates physical
    pins and a selector-less connection cannot report which attached board it
    chose. Presence is not uniqueness — two parents naming the same serial
    still alias. The configured serial is logged on successful initialization.
  - `ngpios` is bounded to 1..32 at build time and must equal the
    firmware-reported `device/info.num_gpios` at initialization; a mismatch is
    a local devicetree/firmware configuration error and fails with `-EINVAL`.
  - Six API slots are implemented: `pin_configure`, `port_get_raw`,
    `port_set_masked_raw`, `port_set_bits_raw`, `port_clear_bits_raw` and
    `port_toggle_bits`.
  - Every operation that reaches hardware is a blocking USB round trip. Calls from interrupt context
    return `-EWOULDBLOCK`; transport failure is reported as `-EIO`.
  - Flag mapping is a positive allow-list, so no flag is silently ignored.
    `GPIO_DISCONNECTED`, `GPIO_INPUT | GPIO_OUTPUT`, single-ended /
    open-source / open-drain, interrupt-mode flags including `GPIO_INT_WAKEUP`,
    and any unknown bit return `-ENOTSUP`; both pulls, both output init levels,
    and an init level without `GPIO_OUTPUT` return `-EINVAL`. `GPIO_ACTIVE_LOW`
    is supported through Zephyr's common GPIO layer.
  - Multi-pin writes and output initialization are explicitly **non-atomic**.
    On a partial failure the acknowledged prefix definitely changed, the failed
    pin is indeterminate because its request may have executed with only the
    response lost, and later selected pins were never issued. The driver logs
    the operation, the failed pin, the requested mask and value, and the
    acknowledged prefix, and never rolls back.
  - Reads are scoped to input pins: a pin the firmware records as an explicit
    output contributes a zero bit and the scan continues, matching Zephyr's
    reference `gpio_emul` controller. This is coupled to the rejection of
    `GPIO_INPUT | GPIO_OUTPUT` and the two must not be changed independently.
  - `port_toggle_bits` dispatches but returns `-ENOTSUP`: an explicit output
    cannot be read back and no pin state is cached. Generic toggle consumers,
    including blinky, the GPIO shell, the TPS382x watchdog and the LS0xx
    display, do not work with this controller.
  - Interrupt configuration, callback management and the pending-interrupt
    query are deliberately not implemented and return `-ENOSYS`.

- Added the `odp,pico-de-gallo` devicetree compatible: a multi-function
  device parent node representing one physical USB-attached board. It owns
  the host connection for that board and exposes its opaque context to child
  peripheral controller drivers. The shield ships one disabled `pdg0` node,
  with the I2C and SPI controllers as its direct children; they borrow the
  parent's connection and carry no selector of their own. At most
  one enabled parent may omit `serial-number`; multiple enabled parents
  without it are rejected at build time.

- Added validation against the firmware-reported GPIO count and explicit
  mappings for all #104 statuses: `-71` to `-EINVAL`, `-72` to `-EACCES`,
  `-73` to `-EBUSY`, `-74` to `-ENODEV`, and `-75` to `-ETIMEDOUT`. The
  mapping uses `switch ((enum Status)status)` with no `default:` label inside
  the switch and is enforced by `-Werror=switch`. At that point full
  `cs-gpios` support was rejected because it would split one atomic `spi/batch`
  into four USB round trips and stop holding chip-select atomically. Closes
  #104. **Superseded in the same Unreleased development cycle:** SP1 later added
  a real GPIO controller and replaced that temporary mapping with required,
  same-parent standard `cs-gpios`; the Zephyr path now uses checked GPIO edges
  around `spi/transfer`, while non-Zephyr `spi/batch` remains supported.

### Removed

- **`snippet_root: zephyr` from `zephyr/module.yml`.** It pointed at a
  `zephyr/snippets/` directory that has never existed. `tests: - zephyr/tests`
  was reported as dangling by the same issue but is now backed by a real
  directory.
  ([#109](https://github.com/OpenDevicePartnership/pico-de-gallo/issues/109))

### Fixed

- **`i2c_burst_write()` no longer returns `-ENOTSUP`.** The I2C controller
  accepted a `I2C_MSG_STOP`-delimited message group only when it held one
  message, or a write followed by a repeated-start read. Zephyr's
  `i2c_burst_write()` emits two *writes* — `I2C_MSG_WRITE`, then
  `I2C_MSG_WRITE | I2C_MSG_STOP` — which matched neither and was rejected. So
  was every hand-rolled gather write, which is where most affected in-tree
  sensor, EEPROM and display drivers actually are; `i2c_burst_write()` and
  `i2c_burst_write_dt()` were the only `i2c.h` helpers that produced the
  rejected shape.
  ([#102](https://github.com/OpenDevicePartnership/pico-de-gallo/issues/102))

  A group's write messages now concatenate into a single payload and reach the
  bus as one transaction: one START, one address phase, all the bytes, one
  STOP. That is what a real controller emits for this message sequence. Three
  shapes are supported — N writes, a single read, and N writes followed by one
  read. Rejections are narrower but still explicit: a read that is not the last
  message of its group, and more than one read in a group, remain `-ENOTSUP`,
  because the FFI has no shape for reading and then continuing within one
  transaction and splitting the group would insert a STOP the caller never
  asked for.

  Requiring `I2C_MSG_RESTART` on the terminating read of a multi-message group
  is **unchanged**: a group that was rejected for lacking it before is still
  rejected for lacking it now.

  This was deliberately **not** fixed by routing through the `i2c/batch`
  firmware endpoint. Zephyr's SPI driver moved *away* from `spi/batch` for
  unrelated reasons, and more importantly `i2c/batch` only became atomic
  recently (#128) inside unreleased schema 0.7, where `validate()` cannot tell
  the two firmware behaviours apart. Depending on it would have converted a
  loud `-ENOTSUP` into silent register corruption against a firmware built
  before that fix. `gallo_i2c_write()` has no such ambiguity.

- **The transfer size limit is now checked per group, not per message.** Two
  4096-byte writes each passed the old per-message check and would have
  concatenated to 8192. The check is now an overflow-safe running total over a
  group's writes, with the group's terminating read bounded separately. At the
  time of this change, both used the same 4096-byte figure and returned
  `-EMSGSIZE`.

  This did not narrow what was accepted at the time: the driver-visible range
  was already `[0, 4096]` through a single `i2c_msg`.

  **Superseded by the newer separate read/write limit entry above.** Later
  measurement established a 1014-byte read edge and verified write-request
  framing through 4096. The write probes used an unpopulated address, so they
  did not establish that 4096 payload bytes can be clocked to an ACKing target.
  The original decision not to lower the write bound by analogy with SPI still
  stands: a bound measured on a differently framed endpoint is a guess.
  ([#146](https://github.com/OpenDevicePartnership/pico-de-gallo/issues/146))

- **A `NULL` message buffer is now refused only when the message claims to
  carry bytes.** Zephyr's I2C API permits `msg.buf == NULL` whenever
  `msg.len == 0`, and both `i2c_write(dev, NULL, 0, addr)` and
  `i2c_write_read(dev, addr, NULL, 0, rx, n)` produce exactly that. The driver
  rejected every `NULL` buffer with `-EINVAL` regardless of length.
  ([#137](https://github.com/OpenDevicePartnership/pico-de-gallo/issues/137))

  Relaxing that check alone would have accomplished nothing. The FFI rejects a
  `NULL` pointer unconditionally, *before* any length check, because
  `slice::from_raw_parts(NULL, 0)` is undefined behaviour in Rust. So the
  pointer had to be kept away from it rather than merely allowed past the
  driver's own guard.

- **A validated group is now reduced to the operation its data bytes actually
  require.** A new `classify_group_()` judges a group by #147's `write_len` —
  already the concatenated total of its writes — and the length of its
  terminating read, and no message carrying zero bytes is forwarded:

  | group | operation |
  |---|---|
  | writes total > 0, read > 0 | write-then-read (unchanged) |
  | writes total > 0, no read or read == 0 | plain write; the empty read phase is dropped |
  | writes total == 0, read > 0 | plain read; the empty writes are dropped |
  | writes total == 0, no read or read == 0 | address-only probe |

  This composes with #147's gather rather than replacing it: `W(0 NULL) + W(3)`
  still gathers to a 3-byte write, and an empty write consumes none of the
  per-group size budget. No `NULL` pointer and no zero length reaches the FFI.

- **An address-only probe is refused with `-ENOTSUP`,** in the validation
  pre-pass — before the controller mutex and before any group reaches the bus,
  preserving the "validation is a complete pre-pass, no partial bus traffic"
  property #147 relies on.

  The refusal is a hardware limitation, not a policy choice. The RP2040/RP2350
  `DW_apb_i2c` block drives the address phase only as a side effect of pushing
  bytes into `IC_DATA_CMD`, so `START + ADDR + STOP` is physically unreachable
  ([rp-rs/rp-hal#678](https://github.com/rp-rs/rp-hal/issues/678),
  [embassy-rs/embassy#4474](https://github.com/embassy-rs/embassy/issues/4474)).

  This also corrects a **live wrong answer** that was independent of the `NULL`
  question. Zephyr's shell `i2c scan` (`drivers/i2c/i2c_shell.c`) probes each
  address with a single `{ buf = &dst, len = 0, flags = I2C_MSG_WRITE |
  I2C_MSG_STOP }` message. `buf` is non-`NULL` there, so the old check never
  blocked it: it reached `gallo_i2c_write(..., 0)` and, since the host-surface
  guard in #136, returned `InvalidArgument` for every address. **`i2c scan`
  prints `0 devices found` on a populated bus today.** At the new default it
  still reports every address absent, but for a stated reason rather than
  silently; with the new Kconfig below it produces a correct answer.

### Known Issues

- **A 1015-byte TX-only `spi/transfer` never returns and wedges the firmware
  dispatcher device-wide.** Deterministic, reproduced across two byte-identical
  consecutive runs on board `5256657D8A5D7F03`.

  Once triggered, **every** subsequent RPC hangs — including from a freshly
  started host process, and including `system/reset-subscriptions`, which is
  the endpoint that exists to recover orphaned state. The condition therefore
  survives host process death entirely.

  The 2 s watchdog does **not** catch it: the dedicated feeder task keeps
  feeding while a request handler blocks, which is precisely the gap left open
  by the serial-dispatch hazard recorded in AGENTS.md §13.17 (2026-06-03).

  In the reproduced tests, the device resumed responding after USB
  re-enumeration. On Windows/WSL this was `usbipd detach` followed by attach.
  This is an observed procedure, not proof that detach directly cancels the
  blocked handler, and it has not been generalized to other dispatcher-wedge
  triggers. On Linux/macOS use cable reconnect or USB unbind/rebind; power-cycle
  if re-enumeration is unavailable or ineffective. The blocked dispatcher cannot
  service `system/reset-subscriptions`.

  Root cause is in the firmware/wire layer (`crates/`) and is out of scope for
  this module. `PDG_SPI_MAX_BUFFER = 1013` puts the hang out of reach *through
  this driver* by rejecting 1014 and above locally with `-EMSGSIZE` before any
  transport call, but that is containment, not a fix, and it does not prove
  that no other hang window exists below 1013.

### Verification

- **#137 was built-only, not behaviourally verified.** No Zephyr environment on
  the authoring machine, no host-side unit-test harness in the module, and no
  board. At that time `.github/workflows/zephyr.yml` gated the PR
  (path-filtered, `zephyr/**` touched) but executed no produced binary, and it
  built only the default configuration, so the
  `CONFIG_I2C_PICO_DE_GALLO_PROBE_WITH_READ=y` arm compiles by construction
  (`IS_ENABLED`, not `#ifdef`) and is never exercised.

  One thing *was* executed. `struct pdg_i2c_group`, `enum pdg_i2c_op`,
  `validate_group_()` and `classify_group_()` were extracted **verbatim** from
  `pdg_i2c.c` into a throwaway host harness and driven through **18 group
  shapes**: the pre-existing shapes; #147's gather shapes crossed with zero
  lengths (`W(1)+W(0 NULL)`, `W(0 NULL)+W(3)`, `W(0)+W(0)`, `W(0)+W(0)+R(2)`,
  `W(2)+W(1)+R(0 NULL)`); the Zephyr shell scan probe; both `NULL`-buffer
  forms; #147's three rejection shapes, which still reject; and the per-group
  running total at and over the 4096-byte limit. All 18 matched, clean under
  `-Wall -Wextra -Werror -Wswitch-enum -Wformat=2` at `-O0`, `-Os`, `-O2` and
  `-O3`.

  The harness is **not committed and is not a test suite**. It covers four
  items and says nothing about `pdg_i2c_transfer()`, `gather_writes_()`, the
  Kconfig wiring, or any transport behaviour, and it cannot fail in CI. Note
  that `tests/pdg_i2c_burst` (added for #102) is board-attached and is not run
  by CI either.

- **Upstream `tests/drivers/spi/spi_loopback` on `native_sim/native/64`:
  41 PASS / 12 SKIP / 1 FAIL / 2 NOT BUILT.** This is **not** a clean upstream
  pass, and must not be read as one.

  The single FAIL is upstream's own `test_spi_complete_multiple_timed`. It is
  **unrunnable on this target rather than a driver defect**: `spi.c:406` asserts
  `time_spent_us >= minimum_transfer_time_us`, a **lower** bound, measured with
  the Zephyr clock — which on `native_sim` does not advance while the host
  thread is blocked inside a USB call, so every transfer measures 0 µs.
  `CONFIG_SPI_IDEAL_TRANSFER_DURATION_SCALING` bounds only the **upper** limit,
  so **no multiplier value can affect this assertion**. It fails on SLOW and
  passes on FAST purely because SLOW's theoretical minimum (432 µs) is larger;
  that is structural, not flaky.

  The 12 SKIPs are all expected and were verified exactly: five word sizes
  rejected by the driver with `-ENOTSUP`, `test_spi_deinit` (no
  `miso-gpios`/`mosi-gpios` on `zephyr,user`) and `test_spi_hold_on_cs`
  (HOLD without LOCK is unsupported), across two spec iterations. The 2 NOT
  BUILT are the async cases, which require `CONFIG_SPI_ASYNC=y`; this driver
  `BUILD_ASSERT`s that off.

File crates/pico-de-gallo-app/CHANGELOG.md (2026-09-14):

# Changelog

All notable changes to `gallo` will be documented in this file.

The format is based on [Keep a Changelog](https://keepachangelog.com/en/1.1.0/),
and this project adheres to [Semantic Versioning](https://semver.org/spec/v2.0.0.html).

## [Unreleased]

### Added

- `gallo uart set-config` now accepts long-only `--data-bits`, `--parity`,
  and `--stop-bits` options and echoes the accepted baud rate and framing.
  Omitting them applies 8N1. No short forms are provided, avoiding ambiguity
  with the top-level `-s, --serial-number`. Closes #152.

### Fixed

- The read-count arguments of `i2c read`, `i2c write-read`, `spi read`, and
  `spi write-read` are now parsed as `u16` instead of `usize` and then cast
  with `as u16`. Part of #158.

  The old cast silently wrapped `--count 65537` to 1, so the command asked
  for 65,537 bytes, exited successfully, and printed one byte. No lower layer
  could reject it because the library received the already-wrapped, legal
  value 1. Clap now refuses values outside the `u16` range; values between
  the response ceiling and `u16::MAX` reach the library's local guard and
  return `BufferTooLong`.

  The byte arguments' `num_args(1..)` setting is a minimum, not a maximum.
  Oversized write payloads are now refused by the inherited library guard
  rather than being accepted without any ceiling.

## [0.10.0] — 2026-09-01

### Changed

- `gallo version` now renders summary and capability tables, including the
  runtime GPIO count and the firmware build identity. Closes #159.

### Fixed

- `gallo version` no longer hangs indefinitely against a firmware built
  from a different tree. `PicoDeGallo::device_info` carries no timeout of
  its own, so the existing fallback to the legacy `version` endpoint was
  unreachable: no `Err` was ever produced. The call is now bounded at five
  seconds — `device/info` has no user-controllable work, unlike the
  `spi_batch` worst case that sizes the library's 300-second bound — and an
  elapsed timeout takes the fallback path. `VersionInfo`'s schema is
  unchanged, so the legacy endpoint still matches across the mismatch.
  Refs #159.

- The firmware-validation failure message no longer advises retrying or
  replugging on a `device/info` timeout. postcard-rpc keys each endpoint by
  its response type's schema, so a host and firmware built from different
  trees exchange `device/info` under different keys and the reply is dropped
  as unmatched rather than decoded — a compile-time mismatch that no retry
  can fix. The message now names both that cause and a genuinely
  unresponsive board, and states that the host cannot distinguish them.
  Refs #159.

## [0.9.0] — 2026-08-27

### Breaking Changes

- Replaced `gallo gpio put --high` with the required
  `--level <high|low>`. There is no `-h` alias: the old derived short
  option collided with clap's `--help`, causing startup to panic and
  making it impossible to request a low level. Closes #104.

### Changed

- `spi batch --cs` is validated against device-reported metadata before
  operations are parsed or anything is transmitted. Closes #104.

- Documented that `gallo i2c batch` sends one I²C transaction rather than one
  independent transaction per operation. Adjacent same-direction operations
  concatenate, direction changes use a repeated START, and only the final
  operation receives a STOP. The command-line surface is unchanged. Closes
  #128.

## [0.8.0] — 2026-08-19

### Breaking Changes

- `gallo spi set-config` now takes `--mode <0|1|2|3>` in place of the
  `--first-transition` and `--idle-low` boolean flags. See the entry
  under **Fixed** for why the old flags could not simply be given
  correct defaults. Values outside 0–3 are rejected by the argument
  parser rather than masked. The old flags were never documented in the
  book — it described a `--phase` / `--polarity` pair that never
  existed — so no working documented invocation changes meaning.

### Added

- `gallo ping` is now implemented. It round-trips a random `u32`
  through the firmware's `ping` endpoint and prints `Ping OK` when the
  echo matches. The subcommand was already documented in the book
  (`getting-started/verify.md`, `appendix/troubleshooting.md`) but had
  never been implemented, so `gallo 0.7.1` answered with
  `error: unrecognized subcommand 'ping'`. The payload is randomised
  per invocation so a stale, duplicated, or default-initialised
  response cannot pass as a healthy round trip; a completed round trip
  carrying the wrong value is reported as
  `ping echo mismatch: sent 0x…, received 0x…` rather than as a generic
  transport error, because the two failures have different causes.
  Fixes [#113](https://github.com/OpenDevicePartnership/pico-de-gallo/issues/113).
- `-s, --serial-number` now has help text. The flag previously rendered
  with an empty description column in `gallo -h`.

### Changed

- `ping` and `version` are now the only device subcommands exempt from
  the up-front schema-version check. `ping` is the transport-level
  liveness probe, so validating first would report a schema error on a
  board whose USB path is precisely what the operator is trying to test.

### Fixed

- `gallo spi set-config` no longer changes the SPI mode as a side
  effect of setting the clock. `--first-transition` and `--idle-low`
  were opt-in flags defaulting to `false`, which the handler mapped to
  `CaptureOnSecondTransition` and `IdleHigh` — so a bare
  `gallo spi set-config --frequency 1000000` silently selected **mode
  3**, while the firmware boots in **mode 0**. Selecting mode 0 required
  passing both flags, the exact inverse of what their names suggest.
  Giving the flags a `true` default does not fix this: `clap` derives
  `ArgAction::SetTrue` for a bare `bool`, so `false` becomes
  unreachable (`--idle-low=false` errors with *"unexpected value for an
  argument found"*) and modes 1–3 would be impossible to select. The
  flags are therefore replaced by `--mode`, which defaults to 0 and
  matches the firmware's power-on configuration. The previous
  regression test asserted the parsed flag values rather than the
  resulting bus configuration, which is why it never caught this; the
  replacement asserts the `(SpiPhase, SpiPolarity)` pair.
- `gallo --help` no longer prints the crate's internal API
  documentation. `clap` derives `long_about` from the `Cli` struct's
  rustdoc when one is present, so long help rendered *"Top-level CLI
  argument parser. Parse with [`clap::Parser::parse`] and execute with
  [`Cli::run`]."* in place of the configured `about` string. `-h` was
  unaffected. Now pinned with `long_about = None`.

## [0.7.1] — 2026-07-20

### Fixed

- `gallo` now opens a **single** USB connection per invocation and
  shares it (by reference) across schema validation and the command
  handler. Previously every subcommand except `list`/`version`
  opened one connection to run `validate()`, dropped it, then opened
  a second connection for the operation (`spi write-read` opened a
  third). On Windows, WinUSB grants exclusive access to one session
  per interface, and the first connection's background `nusb` worker
  had not released the handle before the second `claim_interface`,
  so the operation panicked with
  `Failed claiming interface: … Access is denied`. Commands such as
  `gallo i2c scan`, `i2c get-config`, and `adc info` failed
  deterministically on Windows, while `version`/`list` (single/zero
  connections) worked — making it look like a driver or permissions
  problem. Linux and macOS release the interface synchronously on
  drop, so CI never caught it. Regression from the 2026-06-04
  up-front `validate()` change (Category A finding #4). No CLI
  surface changed.

## [0.7.0] — 2026-06-22

### Fixed (2026-06-04 — Category A hotfix host-only PR)

- `gallo` now calls `validate()` at the top of every subcommand
  except `list` and `version`. Previously the CLI connected
  lazily and surfaced schema-version mismatches as confusing
  `CommsFailed` errors on the first RPC; now the mismatch is
  reported up-front with an actionable error message that
  points at `gallo version` for the device-reported schema and
  recommends either re-flashing the firmware or installing a
  matching `gallo` build. Closes Category A finding #4 (reviewer
  R4) at the CLI layer.

  `list` is exempt because it doesn't touch a connected device.
  `version` is exempt because it IS the diagnostic subcommand
  that reports schema skew (it already handles legacy firmware
  via `device_info()` with fallback).

### Changed (2026-06-04 — Category A hotfix host-only PR)

- Bumped `pico-de-gallo-lib` dependency to 0.6.0 (validate() now
  also checks `schema_major`, so any future major-version skew
  surfaces immediately rather than silently mis-decoding wire
  bytes).

### Changed (2026-06-03 — Category A hotfix wire PR)

- Bumped `pico-de-gallo-lib` dependency to 0.6.0. Required for
  lockstep release with the wire-protocol schema bump in
  `pico-de-gallo-internal` 0.6.0 / `pico-de-gallo-firmware` 0.10.0
  (`timeout_ms` field on `GpioWaitRequest`, `GpioError::Timeout`
  variant).
- Existing `gallo` CLI behavior is unchanged in this release: the
  pre-existing `gpio` subcommands (`get`, `put`, `set-config`,
  `monitor`) all keep working. The CLI does not currently expose
  `gpio wait-for-*` subcommands, so no new flags are added here.
  Bounded waits remain accessible to Rust / C / Python consumers
  via `pico-de-gallo-lib`, `pico-de-gallo-hal`, and `pico-de-gallo-ffi`.

## [0.6.0] — 2026-05-04

### Added

- `gallo version` now shows schema version, HW revision, and
  capabilities with graceful fallback for legacy firmware.

## [0.5.0] — 2026-04-22

### Added

- `gallo gpio monitor --pin N --edge rising|falling|any` command.
  Subscribes, prints edge events with timestamps, unsubscribes on
  Ctrl+C.
- `gallo i2c batch` and `gallo spi batch` CLI commands for
  executing batched operations (e.g.,
  `--op write:0x00,0x10 --op read:16`).
- `gallo pwm` subcommand group with `set-duty`, `get-duty`,
  `enable`, `disable`, `set-config`, and `get-config` commands.
- `gallo adc` subcommand group with `read` and `info` commands.
- `gallo onewire` subcommand group with `reset`, `read`, `write`,
  `write-pullup`, and `search` commands.
- `gallo uart` subcommand group with `read`, `write`, `flush`,
  `set-config`, and `get-config` commands.
- `gallo i2c scan` now uses the dedicated scan endpoint (single
  round-trip) instead of 112 individual reads.
- `gallo gpio set-config`, `gallo gpio get`, and `gallo gpio put`
  subcommands for direct GPIO access from the command line.
- `gallo i2c get-config` and `gallo spi get-config` subcommands.

## [0.4.0] — 2025-04-20

### Breaking Changes

- CLI `set-config` command replaced by `i2c set-config` and
  `spi set-config` subcommands.

### Added

- `list` command to show connected devices with serial numbers.

### Changed

- `I2cFrequency` exposed as `--frequency standard|fast|fast-plus`
  CLI arg.

## [0.2.1] — 2025-03-15

### Fixed

- Bumped library dependency for latest fixes.

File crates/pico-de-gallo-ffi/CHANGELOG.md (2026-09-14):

# Changelog

All notable changes to `pico-de-gallo-ffi` will be documented in this file.

The format is based on [Keep a Changelog](https://keepachangelog.com/en/1.1.0/),
and this project adheres to [Semantic Versioning](https://semver.org/spec/v2.0.0.html).

## [Unreleased]

### Breaking Changes

- `gallo_uart_set_config` and `gallo_uart_get_config` both changed from two
  parameters to five. Every C consumer must be recompiled. Closes #152.

  ```c
  /* Old */
  Status gallo_uart_set_config(const PicoDeGallo *gallo,
                               uint32_t baud_rate);
  Status gallo_uart_get_config(const PicoDeGallo *gallo,
                               uint32_t *out_baud_rate);

  /* New */
  Status gallo_uart_set_config(const PicoDeGallo *gallo,
                               uint32_t baud_rate,
                               uint8_t data_bits,
                               uint8_t parity,
                               uint8_t stop_bits);
  Status gallo_uart_get_config(const PicoDeGallo *gallo,
                               uint32_t *out_baud_rate,
                               uint8_t *out_data_bits,
                               uint8_t *out_parity,
                               uint8_t *out_stop_bits);
  ```

  Valid values are named by `GalloUartDataBits` (`GalloUartDataBits_Five`,
  `GalloUartDataBits_Six`, `GalloUartDataBits_Seven`,
  `GalloUartDataBits_Eight`), `GalloUartParity` (`GalloUartParity_None`,
  `GalloUartParity_Odd`, `GalloUartParity_Even`, `GalloUartParity_Mark`,
  `GalloUartParity_Space`), and `GalloUartStopBits`
  (`GalloUartStopBits_One`, `GalloUartStopBits_Two`). The signatures retain
  `uint8_t`, so these enums are conveniences; the ABI break is the changed
  arity. No `Status` value was added or renumbered.

### Added

- `GALLO_MAX_REQUEST_FRAME` (5119), mirroring
  `pico_de_gallo_internal::MAX_REQUEST_FRAME` and emitted into
  `pico_de_gallo.h` as a `#define`. Part of #186.

  It bounds a whole `gallo_i2c_batch` or `gallo_spi_batch` request frame and
  is the only ceiling on a batch's outgoing bytes; an individual batch
  `Write` is deliberately not capped at `GALLO_MAX_TRANSFER_SIZE`. Written
  as a literal with a `const` assertion tying it to the wire crate, because
  cbindgen folds const initializers syntactically and silently emits nothing
  for a computed value. Verified present in the generated header.

  No new `Status` value: an over-ceiling batch returns the existing
  `Status::BufferTooLong` with `failed_op = 0`.

### Added

- `GALLO_MAX_RESPONSE_PAYLOAD` (1014), mirroring
  `pico_de_gallo_internal::MAX_RESPONSE_PAYLOAD` and emitted into
  `pico_de_gallo.h` as a `#define`. Part of #158.

  C callers that sized a read, or a duplex `gallo_spi_transfer`, against
  `GALLO_MAX_TRANSFER_SIZE` could construct a request whose response the host
  transport could not carry. The existing `GALLO_MAX_TRANSFER_SIZE` comment
  now states explicitly that it does not bound device-to-host responses.

- `Status::CallTimeout` (-76): the device did not answer an RPC within its
  bound. Closes #178 on the C surface.

  Appended, never renumbered — `Status` values are stable C ABI (AGENTS.md
  section 8). Kept distinct from `CommsFailed` because the transport is
  healthy and the board very likely is too, and distinct from
  `DeviceInfoTimeout`, which covers only the validated metadata fetch.

  C consumers writing the recommended exhaustive
  `switch ((enum Status)x)` will fail to build until they add a case. That
  is intended: a silent fallthrough is how a new status becomes a wrong
  `errno`.

### Changed

- **Behaviour change for C consumers:** the six size-checked entry points —
  `gallo_i2c_read`, `gallo_i2c_write`, `gallo_i2c_write_read`,
  `gallo_spi_read`, `gallo_spi_write`, and `gallo_spi_transfer` — now check
  the ceiling appropriate to the direction of their bytes and return
  `Status::BufferTooLong` when it is exceeded. Part of #158.

  Previously they returned `Status::InvalidArgument` only above `u16::MAX`
  and enforced no smaller maximum. No `Status` value was added: those values
  are stable C ABI, and adding one would fall through the exhaustive
  `switch ((enum Status)x)` consumers are instructed to write (AGENTS.md
  section 8). Because both direction-specific ceilings are far below
  `u16::MAX`, the subsequent `usize`-to-`u16` narrowing is now provably
  lossless; a `const` assertion pins that invariant.

### Fixed

- `gallo_*` calls can no longer block indefinitely when a response is lost.
  On `gallo_i2c_batch` timeout the output length is set to zero rather than
  left partial. Callers should note a timed-out batch may still have executed.
## [0.9.0] — 2026-09-01

### Breaking Changes

- Appended `char build_id[GALLO_BUILD_ID_LEN]` to `GalloDeviceInfo`, with
  `GALLO_BUILD_ID_LEN` fixed at 65 bytes including the NUL terminator.
  `gallo_get_device_info` populates it only on `Status::Ok`; no status code was
  added or renumbered. Closes #159.

## [0.8.0] — 2026-08-27

### Added

- Added `gallo_num_gpios` and the coherent #104 status set:
  `SpiInvalidCsPin = -71`, `SpiCsPinUnavailable = -72`,
  `SpiCsPinMonitored = -73`, `SpiNoGpios = -74`, and
  `DeviceInfoTimeout = -75`. Existing C ABI status codes remain stable
  and are never renumbered.

### Changed

- SPI batch calls now bound-check chip-select against device-reported
  metadata on the host, keeping an invalid pin, zero GPIOs, and metadata
  failure as distinct outcomes. Closes #104.

- `gallo_i2c_write` rejects `len == 0`, and `gallo_i2c_batch` rejects a
  `Write` op with `data_len == 0`, returning `InvalidArgument` before the
  device is contacted — before the `gallo` pointer is even dereferenced. For
  a batch, `*out_failed_op` receives the offending operation's index and
  `*out_len` is set to zero. Firmware has refused these since #101, so no
  previously-working call breaks; the refusal is now local and costs no USB
  round-trip. Closes #136.

- **Documentation correction.** The `GalloI2cBatchOp` doc comment and the
  book previously stated that `data` may be `NULL` when `data_len == 0`,
  which advertised the exact call that used to wedge the device. A `Write`
  op now documents `data_len > 0` and a non-NULL `data`. Only the I²C batch
  op changed; `GalloSpiBatchOp` still permits an empty payload, which is
  legitimate for SPI.

- Corrected the `gallo_i2c_batch` documentation to describe one atomic I²C
  transaction: adjacent same-direction operations concatenate, direction
  changes use a repeated START, and only the final operation receives a STOP.
  A bus failure now returns `out_failed_op = 0` because it cannot be attributed
  to one operation; validation failures retain an exact index.
  The C ABI is unchanged. Closes #128.

- `I2cError::ZeroLengthWrite` (new upstream in `pico-de-gallo-internal`)
  maps to the existing `InvalidArgument = -5`. No new status code is
  added: `Status` values are stable C ABI, and a new value falls through
  the exhaustive `switch ((enum Status)x)` that C consumers are told to
  write. A zero-length write is an argument this hardware cannot honour,
  so `InvalidArgument` is the honest existing code. Closes #101.

## [0.7.1] — 2026-08-03

### Changed

- The C FFI API now runs on a shared multi-threaded Tokio runtime
  instead of a per-call `futures::executor::block_on`. This prevents
  `postcard-rpc`'s nusb transport from panicking when it spawns
  background tasks during device initialization, and keeps those
  background tasks between individual FFI calls. The C ABI is
  unchanged — the exported functions, `#[repr(C)]` struct layouts, and
  `Status` code values in `pico_de_gallo.h` are the same (only a
  documentation-comment example in the generated header was
  reformatted).
- Bumped the `pico-de-gallo-lib` dependency to 0.7.1 for its new
  fallible `try_new` / `try_new_with_serial_number` constructors.

### Fixed

- `gallo_init_strict()` and `gallo_init_strict_with_serial_number()`
  now return `NULL` (with a diagnostic on stderr) when no matching
  device is reachable or the USB interface cannot be claimed, instead
  of panicking. They are now built on `pico-de-gallo-lib`'s fallible
  `try_new` constructors rather than the panicking `new()`.

## [0.7.0] — 2026-06-22

### Added (2026-06-04 — Category A hotfix host-only PR)

- `gallo_init_strict()` and `gallo_init_strict_with_serial_number(c_serial_number)`.
  Both call `PicoDeGallo::validate()` internally before returning
  the opaque pointer. Return `NULL` on device-not-found, schema
  version mismatch, legacy firmware, or any validation error.
  Prefer in production C code over the lazy `gallo_init` —
  failures (device not present, schema mismatch) surface at
  construct time rather than on the first RPC. Closes Category A
  finding #4 at the FFI layer.

### Changed (2026-06-04 — Category A hotfix host-only PR)

- Bumped `pico-de-gallo-lib` dependency to 0.6.0 (validate() now
  also checks `schema_major`, so the new `gallo_init_strict`
  surfaces major-version skew that the previous validation
  silently accepted).

### Added (2026-06-03 — Category A hotfix wire PR)

- `gallo_gpio_wait_for_{high,low,rising_edge,falling_edge,any_edge}_with_timeout_ms`
  C functions. `timeout_ms == 0` preserves wait-forever behavior;
  non-zero bounds the firmware-side wait and returns
  `Status::GpioTimeout` on expiry. Available on firmware schema
  0.6+; older firmware returns `Status::SchemaMismatch`.
- `Status::GpioTimeout = -70` enum variant (appended at end of
  `Status` enum; preserves stable C ABI per AGENTS.md §8).

### Changed (2026-06-03 — Category A hotfix wire PR)

- Bumped `pico-de-gallo-lib` dependency to 0.6.0 for the
  `gpio_wait_for_*_with_timeout` host methods.

### Added

- `gallo_system_reset_subscriptions(const PicoDeGallo *, uint8_t
  *out_reset)`. `out_reset` may be `NULL`. New appended `Status`
  code: `SystemResetSubscriptionsFailed = -69`.
- `gallo_spi_transfer`, `gallo_spi_batch`, and `gallo_i2c_batch`
  expose the high-throughput SPI full-duplex and atomic CS-held
  batch primitives (and the equivalent I<sup>2</sup>C multi-op
  primitive) to C consumers that previously could only call them
  from Rust. Batch ops are passed via C-friendly tagged structs
  (`GalloSpiBatchOp`, `GalloI2cBatchOp`); on per-operation failure,
  an optional `out_failed_op` pointer receives the zero-based index
  of the failing op. Three new appended `Status` codes:
  `I2cBatchFailed = -66`, `SpiBatchFailed = -67`,
  `SpiTransferFailed = -68`. The wire protocol is unchanged — these
  are pure FFI surface additions over existing endpoints.
  ([REVIEW-2026-05-29 P1-2])

### Changed

- All `gallo_*` functions now take `const PicoDeGallo *` for the
  device handle (previously `PicoDeGallo *` on every function
  except `gallo_init*` / `gallo_free`). The C ABI (pointer width,
  calling convention, status codes) is unchanged, but C consumers
  that typed their handle as `PicoDeGallo *` and previously cast
  away `const` on every call can now drop those casts. Header
  consumers with `-Wcast-qual` enabled will stop warning. The
  opaque handle remains thread-safe (`Send + Sync`) and
  interior-mutable. ([REVIEW-2026-05-29 P1-4])

## [0.6.0] — 2026-05-04

### Added

- `gallo_get_device_info()` function, `GalloDeviceInfo` C struct
  with `capabilities` u64 bitfield, `GALLO_CAP_*` constants. 4 new
  status codes: `DeviceInfoFailed` (−62), `SchemaMismatch` (−63),
  `LegacyFirmware` (−64), `Unsupported` (−65).

## [0.5.0] — 2026-04-22

### Breaking Changes

- Added 8 new status codes (`I2cNack`, `I2cBusError`,
  `I2cArbitrationLoss`, `I2cOverrun`, `BufferTooLong`,
  `I2cAddressOutOfRange`, `GpioInvalidPin`, `CommsFailed`).

### Added

- `gallo_gpio_subscribe(pin, edge)` and `gallo_gpio_unsubscribe(pin)`
  FFI functions. 4 new status codes: `GpioPinMonitored` (-54),
  `GpioPinNotMonitored` (-55), `GpioSubscribeFailed` (-56),
  `GpioUnsubscribeFailed` (-57).
- 6 PWM FFI functions (`gallo_pwm_set_duty_cycle`,
  `gallo_pwm_get_duty_cycle`, `gallo_pwm_enable`,
  `gallo_pwm_disable`, `gallo_pwm_set_config`,
  `gallo_pwm_get_config`) and 9 status codes (-41 to -49).
- 2 ADC FFI functions (`gallo_adc_read`, `gallo_adc_get_config`)
  and 4 status codes (-50 to -53).
- 5 1-Wire FFI functions (`gallo_onewire_reset`,
  `gallo_onewire_read`, `gallo_onewire_write`,
  `gallo_onewire_write_pullup`, `gallo_onewire_search`) and 5
  status codes (-57 to -61).
- 5 UART FFI functions (`gallo_uart_read`, `gallo_uart_write`,
  `gallo_uart_flush`, `gallo_uart_set_config`,
  `gallo_uart_get_config`) and 10 status codes (-31 to -40).
- `gallo_i2c_scan()` function (writes responding addresses to
  caller buffer) and `I2cScanFailed` status code.
- `gallo_gpio_set_config()` function and `GpioSetConfigFailed` /
  `GpioWrongDirection` status codes.
- `gallo_i2c_get_config()` and `gallo_spi_get_config()` functions,
  `I2cGetConfigFailed` and `SpiGetConfigFailed` status codes.

## [0.4.0] — 2025-04-20

### Breaking Changes

- Split `gallo_set_config()` into `gallo_i2c_set_config()` and
  `gallo_spi_set_config()`.

### Added

- Compile-time `Send + Sync` assertion for thread safety.

## [0.3.0] — 2025-03-15

### Changed

- Updated dependencies to match library changes.

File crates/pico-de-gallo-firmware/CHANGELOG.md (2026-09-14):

# Changelog

All notable changes to `pico-de-gallo-firmware` will be documented in this file.

The format is based on [Keep a Changelog](https://keepachangelog.com/en/1.1.0/),
and this project adheres to [Semantic Versioning](https://semver.org/spec/v2.0.0.html).

## [Unreleased]

### Changed

- `uart/set-config` now writes the requested word-length, parity, and stop-bit
  encodings through `UARTLCR_H` (`WLEN`, `PEN`, `EPS`, `SPS`, and `STP2`) using
  `embassy_rp::pac`; embassy-rp exposes only baud rate as a runtime
  reconfiguration API. Hardware verification established `WLEN`, `PEN`, and
  `STP2`; `EPS` was unobservable, while `SPS` was exercised but not proven with
  single-board loopback. The change is not atomic: the baud divisor is applied
  before framing, and neither UART direction is drained. Closes #152.

### Fixed

- Independently of UART framing, a `uart/read` with `timeout_ms == 0` now
  polls the read future exactly once with `embassy_futures::poll_once` instead
  of waiting on a 1 ms timeout. It deliberately does not use `read_ready()`:
  only `try_read` clears a latched RX error and re-enables RX interrupts.
  Closes #152.

  Measured in-process on board `5256657D8A5D7F03` with firmware
  `firmware-v0.11.0-109-g6c4d42fd0796`, an idle one-byte read fell from
  1422 µs to a 324.5 µs median (437.4 µs p95), 4.38× faster. A one-byte write
  remained unchanged within noise: 335 µs before, 329.4 µs median and
  447.9 µs p95 after. Read and write medians are now both approximately one
  USB round trip.

### Changed

- `BufStorage` is now declared in terms of
  `pico_de_gallo_internal::FIRMWARE_PACKET_BUFFER` rather than restating
  `MAX_TRANSFER_SIZE + 1024`. Part of #186.

  The host derives `MAX_REQUEST_FRAME` from that constant, and it must apply
  the resulting bound itself: an over-ceiling request frame is discarded by
  postcard-rpc's `receive()` before any handler runs, so the firmware cannot
  refuse it. Sharing the constant is what stops the host's bound and the
  buffer it describes from drifting apart. No behavioural change — the
  compiled `.text` is byte-identical.

### Fixed

- `spi/write` and `i2c/write` now bound their payload against
  `MAX_TRANSFER_SIZE` (4096) and return `BufferTooLong` above it. Part of
  #158.

  They were the only two handlers with no upper bound at all. Both stream
  from `req.contents` rather than `context.buf`, so there was never a
  memory-safety problem — which is precisely why the omission went
  unnoticed: every other handler's check exists to protect that shared
  buffer, not to enforce a contract. But `MAX_TRANSFER_SIZE` is documented
  as the per-transaction limit and is exported to every host surface as
  `GALLO_MAX_TRANSFER_SIZE`, so two endpoints silently accepting more made
  that contract untrue. Measured on hardware during #158 triage: `spi/write`
  accepted 4097 and 5000 bytes and drove them onto the bus, and `i2c/write`
  at 4097 reached the wire and returned a bus NAK rather than
  `BufferTooLong`.

  No wire-format or schema change: `BufferTooLong` already existed on both
  error types and only the bound is new.

- `i2c/batch` and `spi/batch` now bound their aggregate read length against
  `MAX_RESPONSE_PAYLOAD` (1014) instead of `MAX_TRANSFER_SIZE` (4096).
  Closes #179.

  The old bound let a batch reading 1015..=4096 bytes run to completion — for
  I²C the whole `I2c::transaction()`, including every `Write`; for SPI a full
  chip-select assert/deassert cycle with the clock driven — and only then
  lose its response, which the host transport cannot carry. The caller was
  handed a transport deserialization failure with no indication that the
  device state had already changed. The refusal happens during
  pre-validation, before any bus activity or chip-select edge, and reports
  `BufferTooLong` with `failed_op: 0`.

  No wire-format or schema change: `BufferTooLong` already existed on both
  error types and only the bound moved.

### Changed

- `MAX_HANDLER_TIMEOUT` and `DEFAULT_DISPATCH_BUDGET` are now derived from
  `MAX_HANDLER_TIMEOUT_MS` and `UNDECLARED_DISPATCH_BUDGET_MS` in
  `pico-de-gallo-internal`, so the host cannot drift from the firmware's
  actual guarantees. Refs #178.

  Same values, no behavioural change, no wire or schema change.
## [0.12.0] — 2026-09-01

### Added

- The build script now derives `BUILD_ID` from
  `git describe --always --dirty --tags --match firmware-v*`, falling back to
  `"unknown"` and truncating to 64 bytes on a character boundary. The firmware
  logs it at boot and returns it as the final `DeviceInfo` field. The script
  reruns on every build so incremental builds cannot retain stale identity.
  Closes #159.

### Added

- Dispatch-progress supervision now feeds the RP2350 watchdog only while the
  postcard-rpc dispatch and aggregate transmit slots remain within their
  budgets. An expired slot logs its frame breadcrumb, records it in watchdog
  scratch registers, and forces a reset; the next boot reports the cause over
  RTT. A reset drops USB and all GPIO subscriptions. The supervisor does not
  cover a wedge inside `receive()`, and the TX slot has no hardware acceptance
  trigger. Because that slot measures aggregate rather than per-sender
  progress, one starved sender can remain masked while another completes at
  least once per 60-second TX budget. Board-attached acceptance is pending.

### Changed

- **BREAKING (behaviour):** the five `gpio/wait-*` handlers now cap every
  caller-supplied timeout at 30 minutes. `timeout_ms == 0` selects that ceiling
  instead of waiting forever, oversized values are clamped to it, and expiry
  returns `GpioError::Timeout`. `uart/read` remains asymmetric: `0` is still a
  1 ms non-blocking poll, while only its non-zero path is clamped.

  > The `timeout_ms == 0` clamp changes documented wire semantics without
  > changing wire shape. `pico-de-gallo-internal` remains at `0.7.0`, and
  > `internal-v0.7.0` is already published, so `validate()` cannot distinguish a
  > pre-clamp 0.7 firmware from a post-clamp one. Host and firmware must be
  > built from the same tree until the bump lands. Before any release,
  > AGENTS.md §16 step 2 requires bumping `internal` to `0.8.0` in lockstep
  > across all eight released crates, with dep-spec rewrites, per-crate
  > CHANGELOGs and both regenerated `Cargo.lock`s.

- **BREAKING (build):** `hw-rev2` is now the default Cargo feature;
  `hw-rev1` is no longer default. A build with no feature flags produces
  a **rev2** image. Building for a v1.0 landing board now requires
  `--no-default-features --features hw-rev1` explicitly. Previously the
  default produced a rev1 image, so anyone building from source without
  reading the feature table got a device whose UART, ADC, and 1-Wire
  endpoints returned `Unsupported` despite the README advertising seven
  peripherals. The `[rev1, rev2]` matrices in `nostd.yml` and
  `release-firmware.yml` were swapped to match, so `firmware-rev1.uf2`
  and `firmware-rev2.uf2` keep targeting the same board revisions they
  always did. Closes #156.

### Deprecated

- `hw-rev1` is deprecated as of this change. It remains fully supported,
  built and linted in CI, and published as `firmware-rev1.uf2` on every
  firmware release. **Removal will not happen before 2031-09-01** — a
  floor, not a commitment to remove on that date. Cargo features cannot
  carry `#[deprecated]`, so two signals are emitted instead: `build.rs`
  prints a `cargo:warning` naming the removal floor, and `main()` logs a
  `defmt::warn!` over RTT at every boot so a rev1 image is identifiable
  from the device and not only from the build log. The boot warning is
  compiled in, so a rev1 image built from this commit differs in content
  from `firmware-v0.11.0`'s.

## [0.11.0] — 2026-08-27

### Fixed

- `spi/batch` now applies three ordered refusals before touching the
  chip-select pin: invalid index, monitored pin, then `ExplicitInput`.
  Only `ExplicitInput` would corrupt tracked state, so `LegacyAuto` and
  `ExplicitOutput` remain accepted. An accepted pin is parked high; its
  prior level is not restored, and `pin_modes` is not written. Removed
  both pre-existing `.unwrap()` calls from the chip-select path. Closes
  #104.

- `i2c/batch` now issues one
  `embedded_hal_async::i2c::I2c::transaction()` instead of executing each
  operation as a separate transaction with its own START and STOP. Adjacent
  same-direction operations concatenate, direction changes use a repeated
  START, and only the final operation is followed by a STOP. A TMP102 hardware
  reproduction showed two adjacent writes previously returning success while
  modifying a register the caller never named. Bus failures now report
  `failed_op = 0` because the atomic transaction fails as a unit; validation
  failures retain their exact operation index. Direct dependencies on
  `embedded-hal-async` 1.0 and `heapless` 0.9 were added from versions already
  present in the resolved graph. Closes #128.

- `i2c/write` and `i2c/batch` now refuse an empty write payload with
  `I2cError::ZeroLengthWrite` instead of forwarding it to
  `embassy_rp::i2c::write_async`. The RP2040/RP2350 `DW_apb_i2c` block
  drives the address phase only by pushing bytes into `IC_DATA_CMD`, so
  an address-only `START + ADDR + STOP` is physically unreachable
  (rp-rs/rp-hal#678, embassy-rs/embassy#4474). embassy-rp 0.10.0 guards
  this in `write_blocking_internal` but not in `write_async_internal`:
  with an empty iterator it queues no command, starts no transaction, and
  then still awaits a `STOP_DET`/`TX_ABRT` interrupt that can never fire.
  Because postcard-rpc dispatches handlers serially, that await wedged
  every endpoint on the device until USB re-enumeration, and the
  independently fed watchdog did not fire. Reachable from the C FFI,
  `pico-de-gallo-lib`, the embedded-hal `I2c::write` impl, Python, MCP
  and Zephyr. In a batch the refusal happens during validation, so no
  earlier operation in that batch reaches the bus. Closes #101.

## [0.10.1] — 2026-08-04

### Added

- WebUSB platform capability in the BOS descriptor, plus a
  landing-page URL descriptor pointing at
  <https://balbi.sh/pico-de-gallo/>. Browsers now surface a
  notification when the device is plugged in and can discover it as a
  WebUSB-aware device. Closes #87.

  The USB device is now built through postcard-rpc's
  `WireStorage::init_without_build()` so that
  `embassy_usb::class::web_usb::WebUsb::configure()` can append the
  capability before `Builder::build()`. This adds a second,
  endpoint-less vendor-class interface; postcard-rpc's bulk interface
  remains interface 0, which all host transports depend on. No new
  dependencies and no wire-protocol change.

  Windows users on the manual Zadig fallback path must bind WinUSB to
  **interface 0** — the device now presents two interfaces with an
  identical `(0xFF, 0x00, 0x00)` triple, and interface 1 has no
  endpoints. See the Windows section of the book's USB & OS Notes.

## [0.10.0] — 2026-06-22

### Added (2026-06-03 — Category A hotfix)

- `gpio_wait_for_*` handlers now honor the per-request `timeout_ms`
  field added in `pico-de-gallo-internal` 0.6. A value of `0`
  preserves the pre-0.6 wait-forever behavior. Non-zero wraps the
  embassy `wait_for_*_edge()` future in
  `embassy_time::with_timeout(Duration::from_millis(timeout_ms))`
  and returns `GpioError::Timeout` on expiry.
- Embassy-rp watchdog enabled at 2-second timeout, fed every
  800 ms by a dedicated `watchdog_feeder_task`. `pause_on_debug(true)`
  is set so debugger sessions don't reset the chip. Recovers the
  device from any future handler hang regression (1-Wire PIO
  stalls, embassy-rp peripheral bugs, etc.). The feeder is a
  separate embassy task — RPC handlers cannot be trusted to feed
  because a wedged handler would also wedge any handler-based
  feed scheme (see closed dispatcher-wedge regression below).

### Fixed (2026-06-03 — Category A hotfix)

- `i2c_scan_handler` now wraps each per-address probe in
  `with_timeout(Duration::from_millis(50))`. A single stuck
  address (slave NAKs slowly, electrical issue, etc.) no longer
  burns the entire scan budget. The watchdog feeder task runs
  independently so the device stays alive even during long scans.

### Why

- Closes the dispatcher-wedge regression where a `gpio_wait_for_*`
  on a never-transitioning pin blocked **every other endpoint**
  until power-cycle (reliability finding B1, captured in
  `docs/superpowers/specs/2026-06-03-pico-de-gallo-category-a-review-synthesis.md`).
- Closes the no-recovery-from-handler-hang gap (reliability
  finding R5).
- Reduces worst-case impact of a flaky I²C bus on `i2c_scan`
  (reliability finding B2 / #33).

### Lockstep

- Coupled to `pico-de-gallo-internal` 0.6.0 (schema minor bump
  adding `timeout_ms` to `GpioWaitRequest` and `GpioError::Timeout`
  variant). See AGENTS.md §6.5.

### Added (system/reset-subscriptions)

- `system/reset-subscriptions` endpoint handler. Firmware iterates
  its GPIO monitor slots, signals stop on each live one, awaits the
  `Flex` pin back from the monitor task, and returns it to
  `Context`. Idempotent and cheap when no subscriptions are active.
  The endpoint is the recovery path for the leak described in P1-3:
  a host process that crashed without sending `gpio/unsubscribe`
  would previously strand the affected pins until a power cycle.

## [0.9.0] — 2026-05-04

### Added

- `hw-rev1` and `hw-rev2` Cargo feature flags (mutually exclusive).
  `hw-rev1` is the default and matches the current v1 landing
  board. Unsupported peripherals (UART, ADC, 1-Wire on v1) return
  `Unsupported` errors instead of silently failing.
- `device_info_handler` returning firmware version, schema version,
  hardware revision, and capabilities bitfield. Capabilities are
  gated by hardware revision feature flag.
- Hardware v1.1 landing board — single keyed 2×12 (0.1″ pitch)
  shrouded header replacing the seven individual connectors of
  v1.0. Routes all 20 firmware signals (UART, SPI CS, 1-Wire, ADC
  now connected). On-board passives: 4.7 kΩ I²C pull-ups (R1/R2),
  100 Ω ADC series resistors (R3–R5), 100 nF decoupling capacitor
  (C1). VREF pin hardwired to 3.3 V. Uses `hw-rev2` firmware.

### Changed

- `release-firmware.yml` now generates the `.uf2` with
  [`elf2uf2-rs`](https://github.com/JoNil/elf2uf2-rs) instead of
  downloading `picotool` from the `pico-sdk-tools` release tarball.
  The tool is installed from git (`cargo install --git ...
  --locked`) because the published crates.io 2.2.0 release does not
  yet expose the `--family` CLI option. The conversion uses
  `--family rp2350-arm-ns` (non-secure Cortex-M33; TrustZone is not
  enabled). Output artifact names (`firmware-{rev1,rev2}.uf2` and
  `pico-de-gallo-firmware-{rev1,rev2}` ELF) are unchanged.
- Renamed firmware crate package from `pico-de-gallo-fw` to
  `pico-de-gallo-firmware` (matches the directory name). The
  release ELF asset uploaded by `release-firmware.yml` is now
  `pico-de-gallo-firmware-{rev1,rev2}` (was
  `pico-de-gallo-fw-{rev1,rev2}`). The `firmware-{rev1,rev2}.uf2`
  artifact name is unchanged.
- CI: `nostd.yml` now builds and lints firmware for both `hw-rev1`
  and `hw-rev2`. `release-firmware.yml` produces per-revision
  release assets (`firmware-rev1.uf2`, `firmware-rev2.uf2`).

### Fixed

- Pin `embassy-usb-driver = "=0.2.0"` to work around an upstream
  incompatibility — `embassy-usb-driver 0.2.1` bumped
  `embedded-io-async` from 0.6 to 0.7, but `embassy-usb 0.5.1`'s
  CDC-ACM `embedded_io_async::ErrorType` impl still expects the 0.6
  trait. The mismatch produces an `EndpointError:
  embedded_io_async::Error` trait-bound error inside `embassy-usb`.
  We can't move to embassy-usb 0.6 because `postcard-rpc 0.12` only
  ships an `embassy-usb-0_5-server` feature.

## [0.8.0] — 2026-04-22

### Breaking Changes

- Reduced GPIO count from 8 (GPIO 8–15) to 4 (GPIO 8–11). GPIO
  12–15 are now reserved for PWM output. All GPIO indices are now
  0–3 instead of 0–7. (Joint firmware/internal change.)
- `gpios` field in `Context` changed from `[Flex<'static>;
  NUM_GPIOS]` to `[Option<Flex<'static>>; NUM_GPIOS]`. GPIO
  operations on a monitored pin return `GpioError::PinMonitored`.
- I2C handlers now map embassy-rp `AbortReason` variants to rich
  error types. SPI `set-config` validates frequency before applying
  (prevents panic on zero frequency).

### Added

- GPIO event monitoring via 4 pooled `gpio_monitor_task` instances.
  Subscribe takes ownership of the pin, monitors for edges, and
  publishes `GpioEvent` via `Sender::publish`. Unsubscribe returns
  the pin to the context. Static channels for
  start/stop/return/armed synchronization.
- `i2c_batch_handler` and `spi_batch_handler` with pre-validation,
  CS assertion/deassertion for SPI batches. SPI batch executes
  atomically under chip-select.
- PWM output on GPIO 12–15 (PWM slices 6–7, 4 channels).
  Frequency/phase-correct configuration with automatic
  top/divider computation. Duty-cycle compare values scaled
  proportionally when frequency changes.
- ADC support on GPIO 26–29 (4 GPIO channels). Uses
  `Adc::new_blocking` for single-shot reads.
- 1-Wire support via PIO0/SM0 on GPIO 16 using embassy-rp's
  `PioOneWire` driver. 6 async handlers. ROM search state held in
  Context.
- UART0 support via `BufferedUart` (interrupt-driven, 1024-byte
  TX/RX buffers). 5 UART handlers with timeout support on reads.
  Baud rate validation (must be > 0). Uses GPIO0 (TX) and GPIO1
  (RX).
- `i2c_scan_handler` — probes addresses by 1-byte read, collects
  responding addresses. Supports `include_reserved` flag.
- `gpio_set_config_handler` and per-pin `PinMode` tracking. Once a
  pin is configured via `gpio/set-config`, it enters explicit mode
  and get/put/wait respect the configured direction (returns
  `WrongDirection` on mismatch). Legacy auto-switching preserved
  for unconfigured pins.
- `i2c_get_config_handler` and `spi_get_config_handler` — return
  the currently active configuration. Firmware now tracks config
  values set by `set-config` endpoints.

## [0.7.0] — 2025-04-20

### Breaking Changes

- Wire protocol updated — firmware and host must be upgraded
  together.

### Changed

- Handler functions modernized with improved ergonomics.
- Buffer increased to `MAX_TRANSFER_SIZE` (4096 bytes).
- `PacketBuffers` sized to `MAX_TRANSFER_SIZE + 1024` per
  direction.

## [0.6.0] — 2025-03-15

### Added

- Updated all Embassy and postcard-rpc dependencies.
- Addressed critical safety issues and improved API ergonomics.
- Added more tests and extracted `connect()` helper.

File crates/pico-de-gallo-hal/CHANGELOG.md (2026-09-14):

# Changelog

All notable changes to `pico-de-gallo-hal` will be documented in this file.

The format is based on [Keep a Changelog](https://keepachangelog.com/en/1.1.0/),
and this project adheres to [Semantic Versioning](https://semver.org/spec/v2.0.0.html).

## [Unreleased]

### Changed

- Documented that `Hal::uart()` uses the device's current baud rate and
  framing and cannot configure either. Callers that require a specific UART
  configuration must set it through the CLI, `pico-de-gallo-lib`, the C FFI,
  or Python before using the HAL, without racing HAL reads or writes. Part of
  #152.

- `UartHalError::kind()` now reports
  `embedded_io::ErrorKind::InvalidInput` for `UartError::BufferTooLong`
  instead of `Other`. Part of #158.

  `InvalidInput` is documented upstream as "A parameter was incorrect",
  which accurately describes a count or payload above the applicable
  ceiling. `I2cHalError::kind()` and `SpiHalError::kind()` deliberately keep
  reporting `Other`: `embedded_hal::i2c::ErrorKind` offers only `Bus`,
  `ArbitrationLoss`, `NoAcknowledge`, `Overrun`, and `Other`, while
  `embedded_hal::spi::ErrorKind` offers only `Overrun`, `ModeFault`,
  `FrameFormat`, `ChipSelectFault`, and `Other`. None describes an oversized
  argument, and `Overrun` would falsely imply that a transfer occurred.
  Tests pin all three mappings.

- **Breaking:** all eight `*HalError` enums gained a `Timeout(Duration)`
  variant, carrying through the new `PicoDeGalloError::Timeout` from
  `pico-de-gallo-lib`. Refs #178.

  `embedded-hal` has no timeout `ErrorKind`, so `kind()` reports
  `Other`. The concrete variant is preserved for callers that inspect the
  error directly, which is the only place the distinction can be made.

### Fixed

- HAL operations inherit the host-side call bound, so a device that never
  answers now surfaces an error instead of blocking the caller forever.
## [0.8.0] — 2026-09-01

### Breaking Changes

- Version bumped in lockstep with the wire-coupled crates for schema 0.8.
  This crate has no source change; it moves because it depends on
  `pico-de-gallo-lib`, which tracks `pico-de-gallo-internal`, and the eight
  wire-coupled crates must never drift in version space (AGENTS.md §6.5).
  `Hal::new_validated` consequently requires firmware reporting schema 0.8.

## [0.7.0] — 2026-08-27

### Breaking Changes

- `Hal::spi_device(cs_pin)` is now fallible because it validates the
  index against the device-reported GPIO count. Metadata failure, zero
  GPIOs, and an invalid index remain distinct errors. Closes #104.

### Added

- Added public, runtime-authoritative `Hal::num_gpios()`. Closes #104.

- `embedded-io` 0.7 support. `Uart` now implements the blocking and
  async `Read`/`Write` traits from `embedded-io` 0.7 /
  `embedded-io-async` 0.7 under the additive `embedded-io-07`
  feature. The existing 0.6 impls remain enabled by default behind
  `embedded-io-06`; enable `embedded-io-07` alongside it to support
  both majors. Either feature can be selected alone, or disable both
  to drop the `embedded-io` dependency entirely.

### Changed

- `I2c::write(addr, &[])` and any transaction containing an empty `Write`
  operation now fail without a USB round-trip, inheriting the guard added to
  `pico-de-gallo-lib`. No HAL code changed. `embedded-hal` permits an empty
  write and some drivers use it as a probe, but this hardware genuinely
  cannot perform one, so the honest answer is an error: `I2cHalError::I2c(
  ZeroLengthWrite)`, whose `ErrorKind` is `Other`. It is deliberately not
  `NoAcknowledge`, which would wrongly imply the bus was driven and the
  target stayed silent. Tests pin both the conversion and the kind. Closes
  #136.

- Documented the corrected I²C transaction semantics inherited from firmware.
  The HAL implements only `I2c::transaction`; the embedded-hal defaults for
  `read`, `write`, and `write_read` all route through it and therefore through
  `i2c/batch`. Adjacent same-direction operations now concatenate, direction
  changes use a repeated START, and only the final operation receives a STOP.
  The Rust API is unchanged. Closes #128.

## [0.6.0] — 2026-06-22

### Added (2026-06-04 — Category A hotfix host-only PR)

- `Hal::new_validated()` and
  `Hal::new_validated_with_serial_number(serial)` constructors call
  `validate()` before returning, failing loudly on
  device-not-connected or schema-version mismatch. The existing
  lazy `Hal::new()` / `Hal::new_with_serial_number()` continue to
  defer failures until the first RPC.
- `Hal::validate()` accessor for callers that constructed via the
  lazy constructors and want to validate after the fact.
- `Hal::system_reset_subscriptions() -> Result<u8, SystemHalError>`
  exposes the firmware-side subscription teardown previously only
  reachable via `pico-de-gallo-lib`. Recommended after
  `new_validated()` in any application that uses GPIO subscriptions,
  so a prior host's crashed-mid-subscription state is cleared.
- `HalInitError` (wraps `pico_de_gallo_lib::ValidateError`) and
  `SystemHalError` (just `Comms` today).
- Re-exported `AdcChannel`, `AdcConfigurationInfo`, `GpioDirection`,
  `GpioEdge`, `GpioPull` from `pico-de-gallo-lib`. Driver authors
  no longer need to add `pico-de-gallo-lib` to their `Cargo.toml`
  for these types.

### Fixed (2026-06-04 — Category A hotfix host-only PR)

- Removed the stale doc-comment reference to a non-existent
  `Hal::uart_set_config` method on the `Uart` struct. Documentation
  now correctly notes that UART baud is fixed at the firmware
  default and changes require dropping to `pico-de-gallo-lib`.

### Changed (2026-06-04 — Category A hotfix host-only PR)

- Bumped `pico-de-gallo-lib` dependency to 0.6.0 (validate() now
  also checks `schema_major`).
- Updated `docs/ai-agents/pico-de-gallo-hal-examples.md`:
  - §4 Cargo setup: removed the "not re-exported by the HAL"
    bullet for `AdcChannel` et al. (they are re-exported now).
  - §6.4–§6.7 GPIO snippets: switched `use pico_de_gallo_lib::{...}`
    to `use pico_de_gallo_hal::{...}` for `GpioDirection`,
    `GpioPull`, `GpioEdge`.
  - §6.7 GPIO subscribe gotcha: documents
    `hal.system_reset_subscriptions()` as the recovery path.
  - §6.9 ADC snippet/HIL/gotchas: switched `AdcChannel` import
    to the HAL re-export; historical note preserved.

### Added (2026-06-03 — Category A hotfix wire PR)

- `Gpio::wait_for_{high,low,rising_edge,falling_edge,any_edge}_with_timeout`
  async methods accept a `std::time::Duration` and return
  `Err(GpioHalError::Gpio(GpioError::Timeout))` on expiry.
  `embedded-hal-async`'s `Wait` trait does not support timeouts, so
  these are exposed as inherent methods on `Gpio` instead. Recommended
  for production code; the trait methods retain their wait-forever
  semantics for compatibility with existing drivers.

### Changed (2026-06-03 — Category A hotfix wire PR)

- Bumped `pico-de-gallo-lib` dependency to 0.6.0.
- Updated `docs/ai-agents/pico-de-gallo-hal-examples.md` §6.6 Gotchas
  to recommend the bounded `_with_timeout` variants for production
  use.

## [0.4.0] — 2026-04-22

### Breaking Changes

- Single `Error` type replaced with `I2cHalError`, `SpiHalError`,
  and `GpioHalError` — each wraps the endpoint-specific error plus
  a `Comms` variant. I2C `ErrorKind` mapping now returns accurate
  variants (NoAcknowledge, ArbitrationLoss, Bus, Overrun) instead
  of `Other` for all errors.
- `I2c::transaction()` and `SpiDevice::transaction()` now use batch
  endpoints under the hood — one USB round-trip per transaction
  instead of one per operation. This is a behavioral change:
  previously each operation in a transaction was an independent USB
  transfer.

### Added

- `gpio_subscribe(pin, edge)` and `gpio_unsubscribe(pin)` blocking
  methods. Re-exported `GpioEdge`, `GpioEvent`.
- `I2c::transaction()` and `SpiDevice::transaction()` (blocking and
  async) rewritten to use batch endpoints — 10–50× fewer USB
  round-trips for multi-operation transactions.
- `PwmChannel` wrapper implementing
  `embedded_hal::pwm::SetDutyCycle`. `PwmHalError` type.
  `Hal::pwm_channel(n)` accessor. `pwm_set_config` and
  `pwm_get_config` convenience methods on `Hal`.
- `AdcHalError` type. `Hal::adc_read(channel)`, `adc_get_config()`
  convenience methods.
- `OneWire` handle struct with blocking wrappers. `OneWireHalError`
  type. `Hal::onewire()` accessor.
- `Uart` wrapper struct implementing `embedded_io::Read`,
  `embedded_io::Write`, `embedded_io_async::Read`, and
  `embedded_io_async::Write`. `UartHalError` type with
  `embedded_io::Error` impl. `Hal::uart()` accessor with 1000ms
  default timeout.
- `Hal::i2c_scan(include_reserved)` method returning `Vec<u8>`.
- `SpiDev` type implementing both `embedded_hal::spi::SpiDevice`
  and `embedded_hal_async::spi::SpiDevice`. Manages chip-select
  (CS) via a GPIO pin, asserting CS low before operations and
  deasserting high afterward with automatic flush. Created via
  `Hal::spi_device(cs_pin)`.
- `Gpio::set_config(pin, direction, pull)` method.
- `Hal::i2c_get_config()` and `spi_get_config()` methods.

## [0.3.0] — 2025-04-20

### Breaking Changes

- Split `set_config()` into `i2c_set_config()` and
  `spi_set_config()`.

### Added

- Per-call async context detection (reuses existing tokio runtime
  if available).

## [0.2.0] — 2025-03-15

### Changed

- Updated dependencies and API to match library.

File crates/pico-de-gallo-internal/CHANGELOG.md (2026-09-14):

# Changelog

All notable changes to `pico-de-gallo-internal` will be documented in this file.

The format is based on [Keep a Changelog](https://keepachangelog.com/en/1.1.0/),
and this project adheres to [Semantic Versioning](https://semver.org/spec/v2.0.0.html).

## [Unreleased]

### Breaking Changes

- Extended `UartSetConfigurationRequest` and `UartConfigurationInfo` with
  word length, parity, and stop-bit fields, and added the wire enums
  `UartDataBits`, `UartParity`, and `UartStopBits`. The `uart/set-config` and
  `uart/get-config` endpoint keys and payloads therefore changed. Closes #152.

  The enum variant indices are postcard wire ABI and follow source order:
  data bits are `Five = 0`, `Six = 1`, `Seven = 2`, `Eight = 3`; parity is
  `None = 0`, `Odd = 1`, `Even = 2`, `Mark = 3`, `Space = 4`; and stop bits
  are `One = 0`, `Two = 1`. `UartStopBits` deliberately does not use Zephyr's
  numbering (`0_5 = 0`, `1 = 1`, `1_5 = 2`, `2 = 3`): the RP2350 PL011 has
  only the `STP2` bit, so half stop bits are unreachable.

  This wire change rides the already-pending, unreleased schema 0.8 bump. The
  crate was already at 0.8.0, `build.rs` already derives schema v0.8.0 from
  that version, and the attached test board reported v0.8.0, so no version
  moved for this change.

### Added

- `MAX_REQUEST_FRAME` (5119), the largest request frame the firmware will
  accept, and `i2c_batch_request_frame_len` / `spi_batch_request_frame_len`
  to size a batch against it. Closes #186.

  Derived, not fitted: `FIRMWARE_PACKET_BUFFER` (5120) less the one byte an
  exactly-filling frame cannot use, because postcard-rpc's `receive()` ends a
  frame on a short USB packet and a frame that fills the window never sees
  one. The two frame-length helpers account for the widest request header
  (13 bytes: 1 discriminant + 8 key + 4 sequence), the request's `u8`
  selector, and the three postcard varints around the operation stream.

  The arithmetic is pinned against real `postcard::to_allocvec` encodings of
  `I2cBatchRequest` and `SpiBatchRequest` across the varint width boundaries,
  the header width is pinned against `VarHeader::write_to_slice`, and the
  result is pinned against the hardware edge.

- `FIRMWARE_PACKET_BUFFER` (5120), the size of each postcard-rpc packet
  buffer on the firmware. Part of #186.

  Exported so the firmware's `BufStorage` is declared in terms of it rather
  than restating `MAX_TRANSFER_SIZE + 1024`. The host derives
  `MAX_REQUEST_FRAME` from the same constant, so the two cannot drift.

### Added

- `MAX_RESPONSE_PAYLOAD` (1014), the largest byte payload a single response
  frame can actually deliver to the host. Closes #179.

  Derived, not fitted: 1024 bytes of postcard-rpc inbound transfer buffer,
  less a 7-byte header (1 discriminant + 2 key + 4 sequence), less the
  `Result` discriminant, less the payload's 2-byte length prefix. Each term
  is pinned by a test; the result matches the edge measured on two boards
  across four endpoints.

  This is a *deliverable-response* ceiling, distinct from
  `MAX_TRANSFER_SIZE`, which bounds a request argument and the firmware's
  scratch buffer. Conflating the two is the defect in #179.

  Constant only — no wire-format or schema change.

- `MAX_HANDLER_TIMEOUT_MS` (30 minutes) and `UNDECLARED_DISPATCH_BUDGET_MS`
  (10 seconds), the two firmware-side timing guarantees hosts need in order
  to bound their own waits. Refs #178.

  Both were previously private to the firmware's `progress` module, which
  meant a host wanting to bound a call had to hard-code a copy and hope it
  stayed in step. The firmware now *derives* its `MAX_HANDLER_TIMEOUT` and
  `DEFAULT_DISPATCH_BUDGET` from these, so there is exactly one definition of
  each.

  `MAX_HANDLER_TIMEOUT_MS` is also the clamp applied to a caller-supplied
  `timeout_ms`, including the rule that `0` selects the ceiling rather than
  meaning "wait forever".

  Constants only — no wire-format or schema change.

### Fixed

- `encode_i2c_batch_ops` and `encode_spi_batch_ops` no longer panic when a
  single batch operation serializes to more than 1024 bytes — in practice a
  `Write`/`Transfer` op carrying more than 1021 bytes of data, which aborted
  the caller with `SerializeBufferFull`. Closes #176.

  Both functions serialized each operation through a fixed scratch array and
  copied the result into the growable output buffer, so the array's size was
  a hard ceiling on any one operation. It was 128 bytes originally and 1024
  after `7f33117`, giving cliffs at 125 and 1021 bytes of payload. Neither
  was documented: the `# Panics` sections mentioned only `MAX_BATCH_OPS`.

  The scratch array served no purpose — both functions are gated on
  `use-std`, already return `Vec<u8>`, and `use-std` already enables
  `postcard/alloc`. It existed only because `postcard::to_slice` requires a
  caller-supplied buffer. Encoding now uses `postcard::to_extend`, writing
  straight into the accumulating `Vec`, which removes the ceiling and the
  per-operation copy.

  Reachable from `spi_batch`/`i2c_batch` in `pico-de-gallo-lib` and hence
  from the HAL, the C FFI, Python and MCP. The FFI and Python paths were the
  most severe, since a panic there unwinds across an `extern "C"` boundary or
  takes down the interpreter.

  **No wire-format change.** Output is byte-identical to the previous
  implementation for every input the previous implementation accepted.

## [0.8.0] — 2026-09-01

### Breaking Changes

- Appended `DeviceInfo::build_id`, a `heapless::String<64>` carrying the
  firmware's `git describe --always --dirty --tags --match firmware-v*`
  output, or `"unknown"` when git was unavailable. The field is
  informational and is never a compatibility gate: `validate()` ignores
  it. Closes #159.

  This is append-only on the wire, but the encoding is not the
  compatibility axis that matters. postcard-rpc derives each endpoint's
  key from the response type's schema, so changing `DeviceInfo` also
  changed the `device/info` endpoint key. A peer built against the other
  shape replies under the other key, the dispatcher drops the unmatched
  frame, and the call never returns. It is not a decode error — postcard
  is never reached — so `validate()` reports it as a `Timeout` after
  `DEVICE_INFO_TIMEOUT`, misattributed to an unresponsive board.

  **Schema 0.7 and 0.8 components must not be mixed, and a mixed pair
  cannot diagnose itself.** For any other wire type a version skew is
  self-describing: `device/info` still answers and `validate()` returns
  `SchemaMismatch`. Not here — the endpoint that re-keyed *is* the
  compatibility probe, so the schema numbers naming the incompatibility
  are sealed inside the dropped message. Bumping the schema version does
  not make this detectable; the version is payload, not key. `DeviceInfo`
  is a blind spot for its own versioning mechanism. `gallo version` still
  works across such a pair, because `VersionInfo`'s schema and key are
  deliberately held stable.

### Added

- `BUILD_ID_CAPACITY` (64) and the `DeviceInfo::build_id()` accessor, so
  host crates never need to name `heapless` themselves.
- `device_info_response_key_is_pinned` and
  `version_response_key_is_pinned`, which hard-code the postcard-rpc
  `RESP_KEY` bytes for `device/info` and `version`. Any future change to
  either response type's shape now fails the test suite instead of
  silently re-keying the endpoint and producing a hang in the field.

## [0.7.0] — 2026-08-27

### Breaking Changes

- Appended `SpiError::InvalidCsPin`, `SpiError::CsPinUnavailable`, and
  `SpiError::CsPinMonitored`, in that order after `Other`, and added
  `DeviceInfo::num_gpios: u8` as the final field. Both are append-only
  wire changes, but AGENTS.md §6.2 still requires a lockstep schema
  bump. This release is that bump: `SCHEMA_VERSION_MINOR` is derived
  from this crate's version by `build.rs` and now reads 7. Closes #104.
- Appended `I2cError::ZeroLengthWrite` at index 7, after `Other`. The
  firmware now returns it instead of forwarding an empty payload to
  `embassy_rp::i2c::write_async`, which never returns on RP2040/RP2350
  and wedges the dispatcher device-wide. Ships inside this same schema
  0.7 bump. Closes #101.

### Changed

- Clarified the `i2c/batch` contract without changing its wire shape:
  operations form one I²C transaction, adjacent operations in the same
  direction continue without a STOP, direction changes use a repeated START,
  and only the final operation is followed by a STOP. Validation failures keep
  their exact `failed_op`; a bus failure applies to the transaction as a whole
  and reports `failed_op = 0`. Closes #128.

## [0.6.0] — 2026-06-22

### Breaking Changes (2026-06-03 — Category A hotfix)

- `GpioWaitRequest` gained a `timeout_ms: u32` field, used by all
  five `gpio/wait-*` endpoints (`gpio/wait-high`, `wait-low`,
  `wait-rising`, `wait-falling`, `wait-any`). A value of `0`
  preserves pre-0.6 wait-forever behavior; non-zero bounds the
  firmware-side wait and returns `GpioError::Timeout` on expiry.
- `GpioError::Timeout` variant appended at end of enum (safe wire-
  protocol addition per AGENTS.md §6.1).
- Schema version bumps via the `pico-de-gallo-internal` version
  bump (`0.5.0` → `0.6.0`); under the pre-1.0 schema-versioning
  rule this is a breaking schema bump, so hosts and firmware must
  be upgraded together. This work ships in the same `0.6.0`
  release as the `system/reset-subscriptions` change below.
  Lockstep version bumps: `pico-de-gallo-internal` `0.5.0` →
  `0.6.0`, `pico-de-gallo-lib` `0.5.0` → `0.6.0`,
  `pico-de-gallo-hal` `0.5.0` → `0.6.0`, `pico-de-gallo-ffi`
  `0.6.0` → `0.7.0`, `gallo` (CLI) `0.6.0` → `0.7.0`,
  `pyco-de-gallo` `0.2.0` → `0.4.2`, `pico-de-gallo-firmware`
  `0.9.0` → `0.10.0`. Closes Category A finding #2 (reliability
  subagent B1: GPIO `wait_for_*` on a never-transitioning pin
  previously wedged the entire firmware dispatcher).

### Breaking Changes

- New `system/reset-subscriptions` endpoint appended to the wire
  protocol. Schema version bumps via the `pico-de-gallo-internal`
  version bump (`0.5.0` → `0.6.0`); under the pre-1.0
  schema-versioning rule this is a breaking schema bump, so hosts
  and firmware must be upgraded together. Lockstep version bumps:
  `pico-de-gallo-internal` `0.5.0` → `0.6.0`, `pico-de-gallo-lib`
  `0.5.0` → `0.6.0`, `pico-de-gallo-hal` `0.5.0` → `0.6.0`,
  `pico-de-gallo-ffi` `0.6.0` → `0.7.0`, `gallo` (CLI) `0.6.0` →
  `0.7.0`, `pyco-de-gallo` `0.2.0` → `0.4.2`,
  `pico-de-gallo-firmware` `0.9.0` → `0.10.0`. ([REVIEW-2026-05-29
  P1-3])

### Added

- `system/reset-subscriptions` endpoint (request `()`, response `u8`
  count). The endpoint is the recovery path for the leak described
  in P1-3: GPIO subscriptions are server-side state that survives
  the USB transport, so a host process that crashed (or was killed,
  or dropped its `nusb::Interface`) without sending
  `gpio/unsubscribe` would permanently strand the affected pins
  until a power cycle.

## [0.5.0] — 2026-05-04

### Breaking Changes

- `UartGetConfigurationResponse` and `AdcGetConfigurationResponse`
  are now `Result<…>` instead of bare struct values, so endpoints
  can report `Unsupported` on hardware revisions that don't route
  the peripheral. Wire protocol is **not** backward compatible —
  firmware and host must be upgraded together.
- New `Unsupported` variant added to `UartError`, `AdcError`, and
  `OneWireError`. Because these enums are not `#[non_exhaustive]`,
  existing exhaustive matches in downstream code must add the new
  arm.

### Added

- `GetDeviceInfo` endpoint (`"device/info"`), `DeviceInfo` struct,
  `Capabilities` bitflag newtype (`u64`) with named constants
  (`I2C`, `SPI`, `UART`, `GPIO`, `PWM`, `ADC`, `ONEWIRE`). Schema
  version constants auto-generated from `Cargo.toml` via `build.rs`.

## [0.4.0] — 2026-04-22

### Breaking Changes

- Reduced GPIO count from 8 (GPIO 8–15) to 4 (GPIO 8–11). GPIO
  12–15 are now reserved for PWM output. All GPIO indices are now
  0–3 instead of 0–7. (Joint firmware/internal change.)
- Replaced 12 unit-struct error types (`I2cReadFail`,
  `SpiWriteFail`, etc.) with 3 rich error enums: `I2cError` (7
  variants), `SpiError` (2 variants), `GpioError` (2 variants).
  Wire protocol is **not** backward compatible — firmware and host
  must be upgraded together.
- `GpioError` now has 4 variants — added `PinMonitored` and
  `PinNotMonitored` for the GPIO event subscription system.

### Added

- `GpioEventTopic` (device-to-host topic), `GpioEdge` enum
  (Rising/Falling/Any), `GpioEvent` struct (pin, edge,
  timestamp_us), `GpioSubscribe`/`GpioUnsubscribe` endpoints with
  request/response types. `TOPICS_OUT_LIST` now contains the GPIO
  event topic.
- `I2cBatch` and `SpiBatch` endpoints, `I2cBatchOp`/`SpiBatchOp`
  enums, `I2cBatchRequest`/`SpiBatchRequest`/`I2cBatchError`/
  `SpiBatchError` types, `encode_i2c_batch_ops`/
  `encode_spi_batch_ops` helpers, `i2c_batch_response_len`/
  `spi_batch_response_len`/`count_i2c_batch_ops`/
  `count_spi_batch_ops` parsing helpers. Constants:
  `MAX_BATCH_OPS`, `BATCH_OP_READ`, `BATCH_OP_WRITE`,
  `BATCH_OP_TRANSFER`, `BATCH_OP_DELAY_NS`.
- 6 PWM endpoints (`pwm/set-duty-cycle`, `pwm/get-duty-cycle`,
  `pwm/enable`, `pwm/disable`, `pwm/set-config`, `pwm/get-config`),
  `PwmError` enum (4 variants), request/response types,
  `PwmDutyCycleInfo` and `PwmConfigurationInfo` structs,
  `NUM_PWM_CHANNELS` constant.
- 2 ADC endpoints (`adc/read`, `adc/get-config`), `AdcChannel` enum
  (4 variants: Adc0–Adc3), `AdcError` enum (2 variants),
  `AdcReadRequest` and `AdcConfigurationInfo` types. Constants:
  `NUM_ADC_GPIO_CHANNELS`, `ADC_RESOLUTION_BITS`,
  `ADC_NOMINAL_REFERENCE_MV`.
- 6 1-Wire endpoints (`onewire/reset`, `onewire/read`,
  `onewire/write`, `onewire/write-pullup`, `onewire/search`,
  `onewire/search-next`), `OneWireError` enum (4 variants),
  `OneWireReadRequest`, `OneWireWriteRequest`,
  `OneWireWritePullupRequest` types. Response type aliases with
  `use-std` feature gating for `onewire/read`.
- 5 UART endpoints (`uart/read`, `uart/write`, `uart/flush`,
  `uart/set-config`, `uart/get-config`), `UartError` enum (7
  variants), `UartReadRequest`, `UartWriteRequest`,
  `UartSetConfigurationRequest`, and `UartConfigurationInfo` types.
  Response type aliases with `use-std` feature gating for owned vs
  borrowed data.
- `I2cScan` endpoint and `I2cScanRequest` type for firmware-side
  bus scanning. Returns a `Vec<u8>` of responding addresses — a
  single USB round-trip replaces 112 individual reads.
- `GpioDirection` and `GpioPull` enums,
  `GpioSetConfigurationRequest`, `GpioSetConfigurationResponse`,
  and `GpioSetConfiguration` endpoint for runtime GPIO pin
  direction and pull-resistor configuration.
- `GpioError::WrongDirection` variant — returned when a get/wait is
  attempted on a pin configured as output, or a put on a pin
  configured as input.
- `I2cGetConfiguration` and `SpiGetConfiguration` endpoints with
  `SpiConfigurationInfo` struct for querying the active bus
  configuration without relying on local state.

## [0.3.0] — 2025-04-20

### Breaking Changes

- Split `SetConfigurationRequest` into `I2cSetConfigurationRequest`
  and `SpiSetConfigurationRequest`.
- Replaced raw `u32` I2C frequency with `I2cFrequency` enum
  (`Standard`, `Fast`, `FastPlus`).

### Added

- SPI full-duplex transfer endpoint (`spi/transfer`) using DMA.
- `From<bool>` / `Into<bool>` conversions for `GpioState`.
- `MAX_TRANSFER_SIZE` constant (4096 bytes) shared across crates.

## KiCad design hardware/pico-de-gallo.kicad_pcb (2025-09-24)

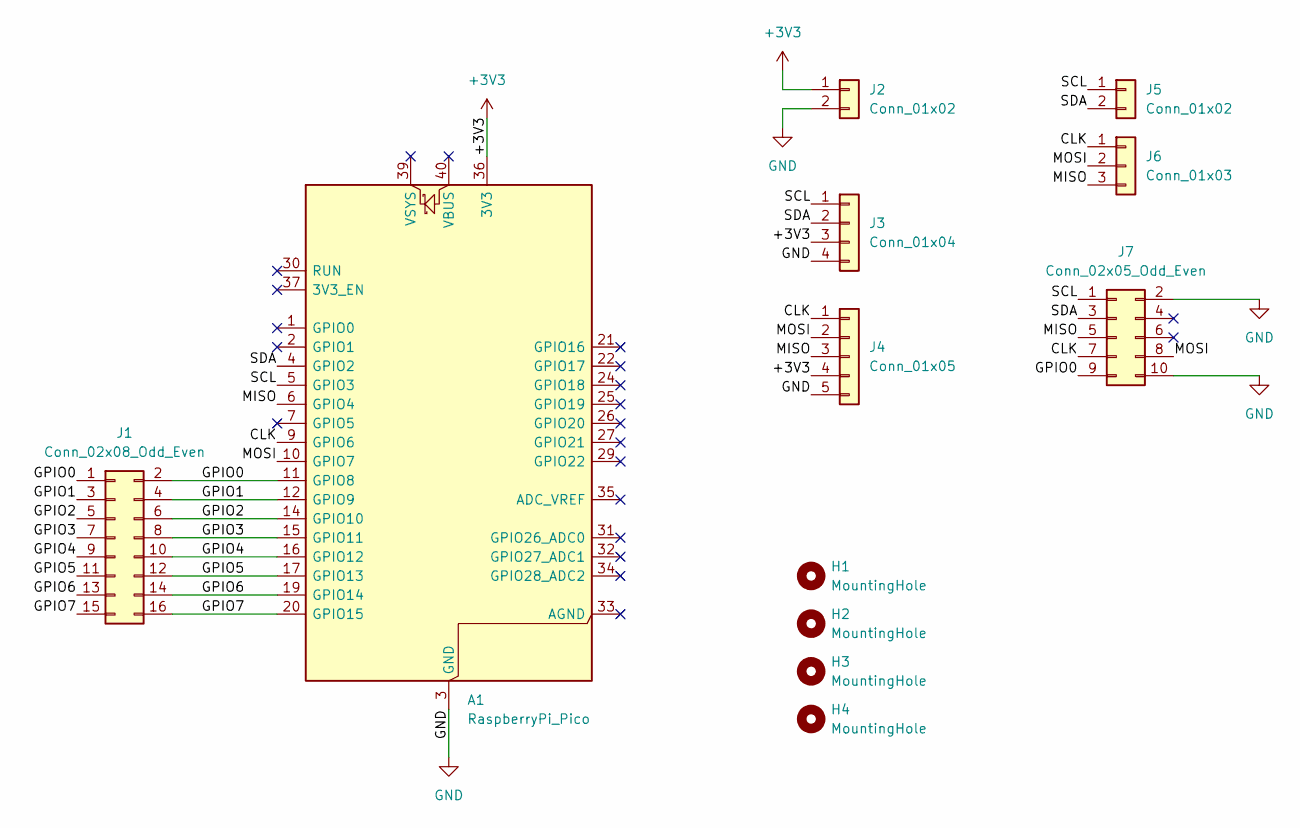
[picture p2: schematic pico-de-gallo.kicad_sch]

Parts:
A1: RaspberryPi_Pico; RaspberryPi_Pico_Common_Unspecified
H1, H2, H3, H4: MountingHole; MountingHole_3.2mm_M3
J1: Conn_02x08_Odd_Even; PinHeader_2x08_P2.54mm_Vertical
J2, J5: Conn_01x02; PinHeader_1x02_P2.54mm_Vertical
J3: Conn_01x04; PinSocket_1x04_P2.54mm_Horizontal
J4: Conn_01x05; PinSocket_1x05_P2.54mm_Horizontal
J6: Conn_01x03; PinHeader_1x03_P2.54mm_Vertical
J7: Conn_02x05_Odd_Even; PinHeader_2x05_P2.54mm_Vertical_SMD

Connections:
+3V3: A1.36 (3V3), J2.1, J3.3, J4.4
/CLK: A1.9 (GPIO6), J4.1, J6.1, J7.7
/GPIO0: A1.11 (GPIO8), J1.1, J1.2, J7.9
/GPIO1: A1.12 (GPIO9), J1.3, J1.4
/GPIO2: A1.14 (GPIO10), J1.5, J1.6
/GPIO3: A1.15 (GPIO11), J1.7, J1.8
/GPIO4: A1.16 (GPIO12), J1.9, J1.10
/GPIO5: A1.17 (GPIO13), J1.11, J1.12
/GPIO6: A1.19 (GPIO14), J1.13, J1.14
/GPIO7: A1.20 (GPIO15), J1.15, J1.16
/MISO: A1.6 (GPIO4), J4.3, J6.3, J7.5
/MOSI: A1.10 (GPIO7), J4.2, J6.2, J7.8
/SCL: A1.5 (GPIO3), J3.1, J5.1, J7.1
/SDA: A1.4 (GPIO2), J3.2, J5.2, J7.3
GND: A1.3 (GND), A1.8 (GND), A1.13 (GND), A1.18 (GND), A1.23 (GND), A1.28 (GND), A1.38 (GND), J2.2, J3.4, J4.5, J7.2, J7.10

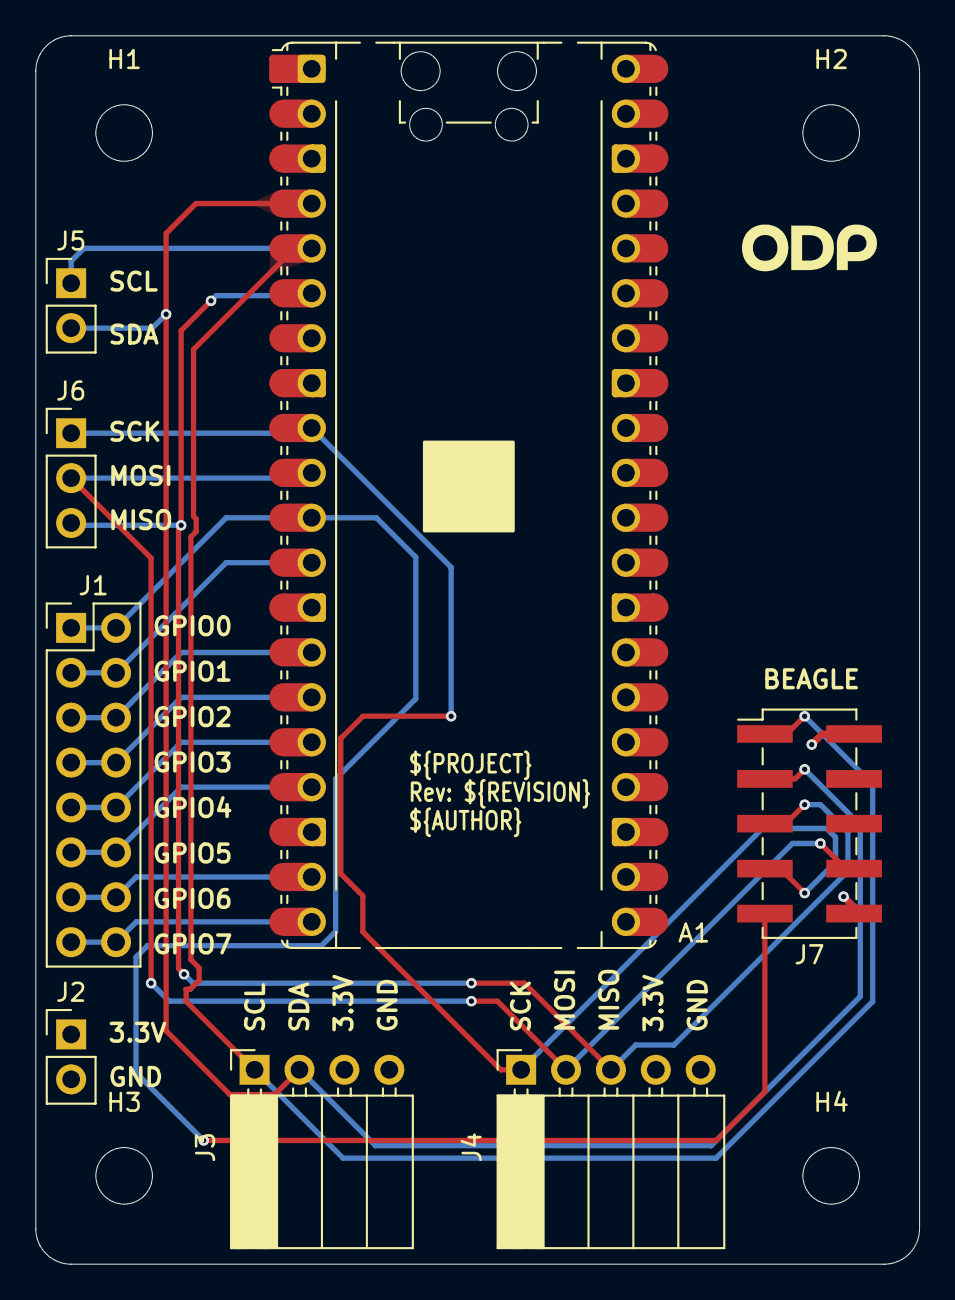
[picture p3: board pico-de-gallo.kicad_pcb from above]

Board: 4 copper layers, 50.0 x 69.5 mm, 12 parts (0 on the bottom side), 15 nets.

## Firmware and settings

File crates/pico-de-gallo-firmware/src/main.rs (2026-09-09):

#![no_std]
#![no_main]
//! Pico de Gallo firmware for the Raspberry Pi Pico 2 (RP2350).
//!
//! This firmware implements a USB bridge that exposes I2C, SPI, UART, GPIO,
//! PWM, ADC, and 1-Wire peripherals to a host computer via [postcard-rpc](https://docs.rs/postcard-rpc)
//! endpoints. It runs on the [Embassy](https://embassy.dev) async runtime.
//!
//! # Peripheral Mapping
//!
//! | Function | RP2350 Pins | Notes |
//! |----------|-------------|-------|
//! | UART0 TX | GPIO 0 | Buffered, interrupt-driven |
//! | UART0 RX | GPIO 1 | |
//! | I2C1 SDA | GPIO 2 | 7-bit addressing, async mode |
//! | I2C1 SCL | GPIO 3 | |
//! | SPI0 SCK | GPIO 6 | DMA-backed full-duplex |
//! | SPI0 TX  | GPIO 7 | |
//! | SPI0 RX  | GPIO 4 | |
//! | GPIO 0–3 | GPIO 8–11 | Input/output/edge-wait |
//! | PWM 0    | GPIO 12 | Slice 6 channel A |
//! | PWM 1    | GPIO 13 | Slice 6 channel B |
//! | PWM 2    | GPIO 14 | Slice 7 channel A |
//! | PWM 3    | GPIO 15 | Slice 7 channel B |
//! | 1-Wire   | GPIO 16 | PIO0/SM0, open-drain |
//! | ADC 0    | GPIO 26 | 12-bit, 0–3.3 V nominal |
//! | ADC 1    | GPIO 27 | 12-bit, 0–3.3 V nominal |
//! | ADC 2    | GPIO 28 | 12-bit, 0–3.3 V nominal |
//! | ADC 3    | GPIO 29 | 12-bit, 0–3.3 V nominal |
//! | USB      | Native USB | postcard-rpc transport |
//!
//! # Endpoints
//!
//! See [`pico_de_gallo_internal::ENDPOINT_LIST`] for the full list of
//! supported endpoints and their request/response types.
//!
//! # Buffer Size
//!
//! The firmware uses a shared buffer of [`MAX_TRANSFER_SIZE`](pico_de_gallo_internal::MAX_TRANSFER_SIZE)
//! (4096) bytes for I2C and SPI data. Requests exceeding this limit are
//! rejected with an error.

#[cfg(all(feature = "hw-rev1", feature = "hw-rev2"))]
compile_error!("Features `hw-rev1` and `hw-rev2` are mutually exclusive");
#[cfg(not(any(feature = "hw-rev1", feature = "hw-rev2")))]
compile_error!("One of `hw-rev1` or `hw-rev2` must be enabled");

mod context;
mod handlers;
mod progress;

use core::sync::atomic::{AtomicU16, Ordering};
use defmt::{debug, warn};
use embassy_executor::Spawner;
#[cfg(feature = "hw-rev2")]
use embassy_rp::adc::{self, Adc};
use embassy_rp::clocks::ClockConfig;
#[cfg(feature = "hw-rev2")]
use embassy_rp::gpio::Pull;
use embassy_rp::gpio::{Flex, Level};
#[cfg(feature = "hw-rev2")]
use embassy_rp::peripherals::PIO0;
#[cfg(feature = "hw-rev2")]
use embassy_rp::pio;
#[cfg(feature = "hw-rev2")]
use embassy_rp::pio_programs::onewire::{PioOneWire, PioOneWireProgram};
use embassy_rp::pwm::{self, Pwm};
#[cfg(feature = "hw-rev2")]
use embassy_rp::uart::{self, BufferedUart};
use embassy_rp::usb::Driver;
use embassy_rp::watchdog::Watchdog;
use embassy_sync::blocking_mutex::raw::CriticalSectionRawMutex;
use embassy_sync::blocking_mutex::raw::ThreadModeRawMutex;
use embassy_sync::channel::Channel;
use embassy_sync::signal::Signal;
use embassy_time::{Duration, Instant, Timer};
use embassy_usb::class::web_usb::{Config as WebUsbConfig, State as WebUsbState, Url, WebUsb};
use embassy_usb::{Config, UsbDevice};
use pico_de_gallo_internal::{
    AdcGetConfiguration, AdcRead, ENDPOINT_LIST, FIRMWARE_PACKET_BUFFER, GetDeviceInfo, GpioEdge, GpioEvent,
    GpioEventTopic, GpioGet, GpioPut, GpioSetConfiguration, GpioState, GpioSubscribe, GpioUnsubscribe, GpioWaitForAny,
    GpioWaitForFalling, GpioWaitForHigh, GpioWaitForLow, GpioWaitForRising, I2cBatch, I2cGetConfiguration, I2cRead,
    I2cScan, I2cSetConfiguration, I2cWrite, I2cWriteRead, MICROSOFT_VID, OneWireRead, OneWireReset, OneWireSearch,
    OneWireSearchNext, OneWireWrite, OneWireWritePullup, PICO_DE_GALLO_PID, PingEndpoint, PwmDisable, PwmEnable,
    PwmGetConfiguration, PwmGetDutyCycle, PwmSetConfiguration, PwmSetDutyCycle, SpiBatch, SpiFlush,
    SpiGetConfiguration, SpiRead, SpiSetConfiguration, SpiTransfer, SpiWrite, SystemResetSubscriptions, TOPICS_IN_LIST,
    TOPICS_OUT_LIST, UartFlush, UartGetConfiguration, UartRead, UartSetConfiguration, UartWrite, Version,
};
use postcard_rpc::{
    define_dispatch,
    header::VarKeyKind,
    server::{
        Dispatch, Sender, Server,
        impls::embassy_usb_v0_5::{
            PacketBuffers, USB_FS_MAX_PACKET_SIZE,
            dispatch_impl::{WireRxBuf, WireRxImpl, WireSpawnImpl, WireStorage, WireTxImpl},
        },
    },
};
use static_cell::ConstStaticCell;
use static_cell::StaticCell;
use {defmt_rtt as _, panic_probe as _};

use context::*;

use handlers::*;

/// Binary info entries for `picotool info` identification.
///
/// These entries are placed in the `.bi_entries` linker section and allow
/// `picotool` to display the firmware name, description, version, and
/// build info without running the firmware.
#[unsafe(link_section = ".bi_entries")]
#[used]
pub static PICOTOOL_ENTRIES: [embassy_rp::binary_info::EntryAddr; 4] = [
    embassy_rp::binary_info::rp_program_name!(c"Pico de Gallo"),
    embassy_rp::binary_info::rp_program_description!(c"USB bridge to various buses such as I2C, SPI, UART, and ADC"),
    embassy_rp::binary_info::rp_cargo_version!(),
    embassy_rp::binary_info::rp_program_build_attribute!(),
];

// auto-generated version information from Cargo.toml
include!(concat!(env!("OUT_DIR"), "/version.rs"));

// Bounds the generated value against the wire capacity: a BUILD_ID that
// would not fit `DeviceInfo::build_id` is a build failure here rather than
// a runtime `unwrap_or_default()` silently reporting an empty identity.
//
// Note what this does NOT do. `build.rs` duplicates the capacity literal
// because a build script cannot import from the crate it is building, and
// this assertion does not compare the two literals -- it only checks the
// value that was actually produced. A build.rs truncating at 128 would
// still pass here whenever `git describe` happened to emit under 64 bytes.
const _: () = assert!(BUILD_ID.len() <= pico_de_gallo_internal::BUILD_ID_CAPACITY);

/// Hardware revision. Bump when the physical board layout changes.
#[cfg(feature = "hw-rev1")]
pub(crate) const HW_VERSION: u8 = 1;
#[cfg(feature = "hw-rev2")]
pub(crate) const HW_VERSION: u8 = 2;

/// WebUSB landing page advertised in the URL descriptor.
///
/// Chrome surfaces this as a notification when the device is plugged in.
/// [`Url::new`] strips the scheme prefix and asserts that the remainder is at
/// most 252 bytes.
const WEBUSB_LANDING_URL: &str = "https://balbi.sh/pico-de-gallo/";

/// `Url::new` asserts the post-scheme-strip length fits the URL descriptor. Catch
/// an over-long URL at build time rather than as a boot panic: a panic in `main()`
/// happens before `watchdog_supervisor_task` is ever polled, so the watchdog and
/// dispatch-progress supervision would never arm and the device would hang dead.
const _: () = assert!(WEBUSB_LANDING_URL.len() <= 252);

/// `bRequest` value for WebUSB vendor control transfers.
///
/// Deliberately not `0`: postcard-rpc registers the Microsoft OS 2.0
/// descriptor at vendor code `0` (`init_without_build` calls
/// `msos_descriptor(WIN8_1, 0)`). embassy-usb 0.5.1 only intercepts that
/// request when `bRequest == 0 && wIndex == 7`, so `0` would not actually
/// collide with WebUSB's `GET_URL` (`wIndex == 2`) today, but keeping the two
/// vendor codes distinct avoids depending on that `wIndex` disambiguation.
const WEBUSB_VENDOR_CODE: u8 = 0x01;

/// USB driver type for the RP2350.
type AppDriver = Driver<'static, embassy_rp::peripherals::USB>;
/// postcard-rpc wire storage with ThreadMode mutex.
type AppStorage = WireStorage<ThreadModeRawMutex, AppDriver, 256, 256, 64, 256>;
/// Packet buffer storage, sized by
/// [`FIRMWARE_PACKET_BUFFER`](pico_de_gallo_internal::FIRMWARE_PACKET_BUFFER).
///
/// The constant lives in `pico-de-gallo-internal` rather than here because
/// the host derives [`MAX_REQUEST_FRAME`](pico_de_gallo_internal::MAX_REQUEST_FRAME)
/// from it: an over-ceiling request frame is discarded by `receive()`
/// before any handler runs, so the firmware cannot refuse it and the bound
/// has to be applied host-side. Using the constant here rather than
/// restating the arithmetic is what stops the two from drifting (issue
/// #186).
type BufStorage = PacketBuffers<{ FIRMWARE_PACKET_BUFFER }, { FIRMWARE_PACKET_BUFFER }>;
/// postcard-rpc transmit implementation.
type AppTx = progress::WatchedTx<WireTxImpl<ThreadModeRawMutex, AppDriver>>;
/// postcard-rpc receive implementation.
type AppRx = progress::WatchedRx<WireRxImpl<AppDriver>>;
/// The complete postcard-rpc server type.
type AppServer = Server<AppTx, AppRx, WireRxBuf, PicoDeGallo>;

static PBUFS: ConstStaticCell<BufStorage> = ConstStaticCell::new(BufStorage::new());
static STORAGE: AppStorage = AppStorage::new();

// --- GPIO event monitoring infrastructure ---

/// Channel for sending a (Flex, GpioEdge) pair to start monitoring pin `n`.
static GPIO_MONITOR_START: [Channel<CriticalSectionRawMutex, (Flex<'static>, GpioEdge), 1>; NUM_GPIOS] =
    [Channel::new(), Channel::new(), Channel::new(), Channel::new()];

/// Signal to stop monitoring pin `n`.
static GPIO_MONITOR_STOP: [Signal<CriticalSectionRawMutex, ()>; NUM_GPIOS] =
    [Signal::new(), Signal::new(), Signal::new(), Signal::new()];

/// Channel for returning the Flex pin after monitoring stops.
static GPIO_MONITOR_RETURN: [Channel<CriticalSectionRawMutex, Flex<'static>, 1>; NUM_GPIOS] =
    [Channel::new(), Channel::new(), Channel::new(), Channel::new()];

/// Ack channel: monitor task signals it is armed and listening.
static GPIO_MONITOR_ARMED: [Channel<CriticalSectionRawMutex, (), 1>; NUM_GPIOS] =
    [Channel::new(), Channel::new(), Channel::new(), Channel::new()];

/// Monotonic sequence counter for published GPIO events.
static GPIO_EVENT_SEQ: AtomicU16 = AtomicU16::new(0);

/// Background task that monitors GPIO pin `N` for edge events.
///
/// The task waits for a `(Flex, GpioEdge)` on `GPIO_MONITOR_START[N]`,
/// sends an armed ack, then loops detecting edges and publishing
/// `GpioEvent` topics until `GPIO_MONITOR_STOP[N]` is signalled.
/// After stopping, the `Flex` pin is returned via `GPIO_MONITOR_RETURN[N]`.
///
/// Edge detection is best-effort: if the pin changes faster than the
/// monitor loop cadence, intermediate transitions may be missed.
#[embassy_executor::task(pool_size = 4)]
async fn gpio_monitor_task(slot: usize, tx: AppTx, vkk: VarKeyKind) {
    let sender = Sender::new(tx, vkk);

    loop {
        // Wait for a subscribe request to hand us a pin
        let (mut flex, edge) = GPIO_MONITOR_START[slot].receive().await;

        // Configure as input for edge detection
        flex.set_as_input();

        // Signal that we are armed and listening
        GPIO_MONITOR_ARMED[slot].send(()).await;

        debug!("gpio monitor[{}]: armed, edge={=u8}", slot, edge as u8);

        // Monitor loop: wait for edge or stop signal
        loop {
            use embassy_futures::select::{Either, select};

            let edge_future = async {
                match edge {
                    GpioEdge::Rising => flex.wait_for_rising_edge().await,
                    GpioEdge::Falling => flex.wait_for_falling_edge().await,
                    GpioEdge::Any => flex.wait_for_any_edge().await,
                }
            };

            match select(edge_future, GPIO_MONITOR_STOP[slot].wait()).await {
                Either::First(()) => {
                    let state = match flex.get_level() {
                        Level::Low => GpioState::Low,
                        Level::High => GpioState::High,
                    };
                    let timestamp_us = Instant::now().as_micros();
                    let seq = GPIO_EVENT_SEQ.fetch_add(1, Ordering::Relaxed);

                    let event = GpioEvent {
                        pin: slot as u8,
                        edge,
                        state,
                        timestamp_us,
                    };

                    debug!(
                        "gpio monitor[{}]: edge detected, state={=u8}, ts={=u64}",
                        slot, state as u8, timestamp_us
                    );

                    let _ = sender.publish::<GpioEventTopic>(seq.into(), &event).await;
                }
                Either::Second(()) => {
                    debug!("gpio monitor[{}]: stop requested", slot);
                    GPIO_MONITOR_RETURN[slot].send(flex).await;
                    break;
                }
            }
        }
    }
}
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
async fn main(spawner: Spawner) {
    let config = embassy_rp::config::Config::new(ClockConfig::system_freq(150_000_000).unwrap());
    let p = embassy_rp::init(config);

    // Arm the hardware watchdog as defence-in-depth against handler hangs.
    // Read and clear any breadcrumb from a previous supervisor-forced reset
    // before handing the peripheral over.
    let mut watchdog = Watchdog::new(p.WATCHDOG);
    let reason = watchdog.reset_reason();
    let scratch_reason = watchdog.get_scratch(SCRATCH_REASON);
    if scratch_reason & 0xFFFF_FF00 == WEDGE_MAGIC {
        warn!(
            "previous boot ended in a supervisor-forced reset: slot={=u32} key={=u32:#010x}",
            scratch_reason & 0xFF,
            watchdog.get_scratch(SCRATCH_KEY)
        );
        watchdog.set_scratch(SCRATCH_REASON, 0);
        watchdog.set_scratch(SCRATCH_KEY, 0);
    } else if reason.is_some() {
        warn!("previous boot ended in a watchdog reset not raised by the supervisor");
    }
    spawner.must_spawn(watchdog_supervisor_task(watchdog));

    // Logged unconditionally at boot so an RTT capture records exactly which
    // image is running, independent of any host-side query.
    defmt::info!("build {}", BUILD_ID);

    // `hw-rev1` is deprecated. Warn on every boot so a device flashed with it
    // is identifiable from RTT alone, not only from the build log. Emitted
    // after the watchdog is armed so nothing runs ahead of it.
    #[cfg(feature = "hw-rev1")]
    warn!(
        "hw-rev1 firmware is DEPRECATED (v1.0 landing board): UART, ADC and 1-Wire return Unsupported. \
         Removal no earlier than 2031-09-01. Build the default hw-rev2 image for v1.1+ boards."
    );

    // USB/RPC INIT
    let driver = Driver::new(p.USB, Irqs);
    let pbufs = PBUFS.take();
    let config = usb_config();

    let i2c = embassy_rp::i2c::I2c::new_async(p.I2C1, p.PIN_3, p.PIN_2, Irqs, embassy_rp::i2c::Config::default());
    let spi = embassy_rp::spi::Spi::new(
        p.SPI0,
        p.PIN_6,
        p.PIN_7,
        p.PIN_4,
        p.DMA_CH0,
        p.DMA_CH1,
        Irqs,
        embassy_rp::spi::Config::default(),
    );

    let gpios = [
        Flex::new(p.PIN_8),
        Flex::new(p.PIN_9),
        Flex::new(p.PIN_10),
        Flex::new(p.PIN_11),
    ];

    // PWM on GPIO12-15 (slices 6-7)
    let pwm_config = pwm::Config::default();
    let pwm_slices = [
        Pwm::new_output_ab(p.PWM_SLICE6, p.PIN_12, p.PIN_13, pwm_config.clone()),
        Pwm::new_output_ab(p.PWM_SLICE7, p.PIN_14, p.PIN_15, pwm_config.clone()),
    ];
    let pwm_configs = [pwm::Config::default(), pwm::Config::default()];

    // UART0 on GPIO0 (TX) and GPIO1 (RX) — default Pico 2 header pins
    #[cfg(feature = "hw-rev2")]
    let uart = {
        static UART_TX_BUF: StaticCell<[u8; 1024]> = StaticCell::new();
        static UART_RX_BUF: StaticCell<[u8; 1024]> = StaticCell::new();
        let uart_tx_buf = UART_TX_BUF.init([0u8; 1024]);
        let uart_rx_buf = UART_RX_BUF.init([0u8; 1024]);
        BufferedUart::new(
            p.UART0,
            p.PIN_0,
            p.PIN_1,
            Rev2Irqs,
            uart_tx_buf,
            uart_rx_buf,
            uart::Config::default(),
        )
    };

    // ADC — blocking mode for single-shot reads (GPIO26–29)
    #[cfg(feature = "hw-rev2")]
    let adc = Adc::new_blocking(p.ADC, adc::Config::default());
    #[cfg(feature = "hw-rev2")]
    let adc_channels = [
        adc::Channel::new_pin(p.PIN_26, Pull::None),
        adc::Channel::new_pin(p.PIN_27, Pull::None),
        adc::Channel::new_pin(p.PIN_28, Pull::None),
        adc::Channel::new_pin(p.PIN_29, Pull::None),
    ];

    // 1-Wire — PIO0/SM0 on GPIO16
    #[cfg(feature = "hw-rev2")]
    let onewire = {
        let pio::Pio { mut common, sm0, .. } = pio::Pio::new(p.PIO0, Rev2Irqs);
        static OW_PROGRAM: StaticCell<PioOneWireProgram<'static, PIO0>> = StaticCell::new();
        let ow_program = OW_PROGRAM.init(PioOneWireProgram::new(&mut common));
        PioOneWire::new(&mut common, sm0, p.PIN_16, ow_program)
    };

    #[cfg(feature = "hw-rev2")]
    let context = Context::new(
        i2c,
        spi,
        uart,
        gpios,
        pwm_slices,
        pwm_configs,
        adc,
        adc_channels,
        onewire,
    );

    #[cfg(not(feature = "hw-rev2"))]
    let context = Context::new(i2c, spi, gpios, pwm_slices, pwm_configs);

    let (mut builder, tx_impl, rx_impl) =
        STORAGE.init_without_build(driver, config, pbufs.tx_buf.as_mut_slice(), USB_FS_MAX_PACKET_SIZE);
    // Wrap once here; `AppTx` is cloned into the GPIO monitor tasks and named
    // by `define_dispatch!`, so every downstream use picks the wrapper up.
    let tx_impl = progress::WatchedTx::new(tx_impl);

    // Advertise WebUSB so browsers can discover the device and surface the
    // landing page.
    //
    // This MUST run after init_without_build(): postcard-rpc's bulk interface
    // has to stay interface 0, because every host transport selects the FIRST
    // class-0xFF interface — postcard-rpc 0.12.1
    // `host_client::raw_nusb::try_new_raw_nusb` (first 0xFF on Linux/macOS,
    // hardcoded interface 0 on Windows) and `host_client::webusb::from_device`
    // (first 0xFF, then requires IN+OUT endpoints). WebUsb::configure() appends
    // a second class-0xFF interface with an identical class/subclass/protocol
    // triple and no endpoints, so ordering is the only thing distinguishing
    // them; if it ran first, the browser would fail with "Failed to find usable
    // interface" and Linux/macOS would silently claim the wrong one.
    //
    // Descriptor budgets (BOS, config) are set by the AppStorage type alias
    // above; overflowing either is a "Descriptor buffer full" panic.
    static WEBUSB_STATE: StaticCell<WebUsbState<'static>> = StaticCell::new();
    static WEBUSB_CONFIG: StaticCell<WebUsbConfig<'static>> = StaticCell::new();
    let webusb_config = WEBUSB_CONFIG.init(WebUsbConfig {
        // Inert: WebUsb::configure() creates no endpoints, and embassy-usb
        // 0.5.1 never reads this field. It has no Default, so it must be set.
        max_packet_size: USB_FS_MAX_PACKET_SIZE as u16,
        landing_url: Some(Url::new(WEBUSB_LANDING_URL)),
        vendor_code: WEBUSB_VENDOR_CODE,
    });
    WebUsb::configure(&mut builder, WEBUSB_STATE.init(WebUsbState::new()), webusb_config);

    let device = builder.build();
    let dispatcher = PicoDeGallo::new(context, spawner.into());
    let vkk = dispatcher.min_key_len();

    // Spawn GPIO monitor tasks before creating the server.
    // EUsbWireTx is Clone, so we clone tx_impl for each task.
    for slot in 0..NUM_GPIOS {
        spawner.must_spawn(gpio_monitor_task(slot, tx_impl.clone(), vkk));
    }

    let mut server: AppServer = Server::new(
        tx_impl,
        progress::WatchedRx::new(rx_impl),
        pbufs.rx_buf.as_mut_slice(),
        dispatcher,
        vkk,
    );
    spawner.must_spawn(usb_task(device));

    loop {
        // If the host disconnects, we'll return an error here.
        // If this happens, just wait until the host reconnects
        let _ = server.run().await;
    }
}

/// This handles the low level USB management
#[embassy_executor::task]
pub async fn usb_task(mut usb: UsbDevice<'static, AppDriver>) {
    usb.run().await;
}

/// Marks watchdog scratch slot 0 as ours.
///
/// `trigger_reset()` sets `CTRL.TRIGGER`, which `reset_reason()` reports as
/// `ResetReason::Forced` — but so does a `picotool reboot`, which goes through
/// the same path. This magic is what separates the two.
const WEDGE_MAGIC: u32 = 0x5044_4700; // "PDG\0"

// RP2350 bootrom owns WATCHDOG_SCRATCH2..7: 4-7 are the boot vector
// (magic/entry^magic/SP/entry) and 2-3 carry reboot() p0/p1, clobbered
// by picotool reboot and BOOTSEL (RP2350 Datasheet 2025-07-29 S5.2.4,
// pp.371-372). 0 and 1 appear nowhere in the datasheet or the published
// bootrom source, so they are the only free words -- no spare margin.
/// Scratch register holding [`WEDGE_MAGIC`] plus the slot discriminant.
const SCRATCH_REASON: usize = 0;
/// Scratch register holding the in-flight frame breadcrumb.
const SCRATCH_KEY: usize = 1;
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

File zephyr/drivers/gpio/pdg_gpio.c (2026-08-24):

/*
 * Copyright (c) 2026 Open Device Partnership and Contributors
 *
 * SPDX-License-Identifier: MIT
 *
 * Zephyr GPIO controller driver for the Pico de Gallo USB bridge.
 *
 * This file runs in the embedded/Zephyr context, which for this module means
 * the embedded half of native_sim. It translates Zephyr GPIO API calls into
 * the small host-context shim declared in pdg_gpio_bottom.h, which forwards
 * them to the Pico de Gallo C FFI.
 *
 * Every operation that reaches hardware is a blocking USB round trip; calls
 * rejected beforehand (interrupt context, invalid arguments, zero pin masks
 * and toggle) perform no I/O. Levels are queried afresh from
 * the board, while direction and pull are never cached locally; configuration
 * is sent directly to the firmware. This avoids the host/firmware divergence
 * class of defect recorded as issue #104.
 */

#define DT_DRV_COMPAT odp_pico_de_gallo_gpio

#include <inttypes.h>

#include <zephyr/device.h>
#include <zephyr/drivers/gpio.h>
#include <zephyr/drivers/gpio/gpio_utils.h>
#include <zephyr/kernel.h>
#include <zephyr/logging/log.h>

#include "pdg_gpio_bottom.h"

/*
 * Structural topology enforcement.
 *
 * This controller borrows its host connection from an odp,pico-de-gallo MFD
 * parent reached through DT_INST_PARENT(). Runtime readiness alone cannot
 * prove that the parent is the *right kind* of device: a child placed under an
 * unrelated but enabled and ready device would pass device_is_ready(), and
 * pdg_mfd_ctx() would then reinterpret that foreign driver's dev->data as
 * struct pdg_mfd_data and hand back an arbitrary pointer that no NULL check
 * can catch. DT_INST_PARENT() on a stale root-level child yields `/`, so
 * asserting status alone is likewise insufficient; the compatible must be
 * checked in its own right.
 *
 * The assertions are ordered compatible -> parent status -> parent serial
 * presence -> Kconfig, and that *source* order is the normative contract.
 * First prove this is the right enabled hardware node, then prove that GPIO
 * actuation has an explicit board identity, and only then diagnose the
 * software dependency. (_Static_assert is not fatal, so GCC reports every
 * failing assertion in one pass, but C does not specify the emission order;
 * observed diagnostic order is corroborating evidence only.)
 *
 * The serial-presence assertion exists because GPIO actuation drives physical
 * pins. A selector-less strict open cannot report which attached board it
 * selected, so an enabled GPIO child under a selector-less parent would
 * actuate unidentifiable hardware. Presence is not uniqueness: two parents
 * carrying the same explicit serial still alias to one board, as the MFD
 * binding already documents.
 *
 * The fifth assertion bounds ngpios. Binding YAML cannot express an integer
 * range, and gpio_port_pins_t is 32 bits wide on this target, so an
 * out-of-range ngpios would otherwise silently truncate the port_pin_mask that
 * GPIO_COMMON_CONFIG_FROM_DT_INST() derives from it.
 *
 * The whole block precedes the "pdg_mfd.h" include on purpose: when
 * CONFIG_MFD_PICO_DE_GALLO is `n` the MFD driver subdirectory is not added to
 * the build at all, so pdg_mfd.h is not on the include path. Asserting first
 * guarantees the readable configuration error is emitted before the include
 * failure, instead of an opaque "no such file" or an unresolved
 * __device_dts_ord_N at link time.
 */
#define PDG_GPIO_PARENT_ASSERTS(inst)						\
	BUILD_ASSERT(								\
		DT_NODE_HAS_COMPAT(DT_INST_PARENT(inst), odp_pico_de_gallo),	\
		"Enabled odp,pico-de-gallo-gpio controllers must be direct "	\
		"children of an odp,pico-de-gallo parent");			\
	BUILD_ASSERT(								\
		DT_NODE_HAS_STATUS_OKAY(DT_INST_PARENT(inst)),			\
		"Enabled odp,pico-de-gallo-gpio controllers require their "	\
		"odp,pico-de-gallo parent to have status okay");			\
	BUILD_ASSERT(								\
		DT_NODE_HAS_PROP(DT_INST_PARENT(inst), serial_number),		\
		"odp,pico-de-gallo-gpio parent must define serial-number");	\
	BUILD_ASSERT(								\
		IS_ENABLED(CONFIG_MFD_PICO_DE_GALLO),				\
		"Enabled Pico de Gallo child controllers require "		\
		"CONFIG_MFD_PICO_DE_GALLO=y");					\
	BUILD_ASSERT(								\
		(DT_INST_PROP(inst, ngpios) >= 1) &&				\
		(DT_INST_PROP(inst, ngpios) <= GPIO_MAX_PINS_PER_PORT),		\
		"odp,pico-de-gallo-gpio ngpios must be between 1 and 32");

DT_INST_FOREACH_STATUS_OKAY(PDG_GPIO_PARENT_ASSERTS)

#include "pdg_mfd.h"

LOG_MODULE_REGISTER(gpio_pico_de_gallo, CONFIG_GPIO_LOG_LEVEL);

/*
 * Positive allow-list of configuration flags this controller understands.
 *
 * Anything outside it is rejected rather than silently ignored, so a newly
 * defined Zephyr flag bit cannot quietly change the meaning of a call until a
 * reviewer deliberately adds and maps it here.
 */
#define PDG_GPIO_ALLOWED_FLAGS							\
	(GPIO_INPUT | GPIO_OUTPUT | GPIO_PULL_UP | GPIO_PULL_DOWN |		\
	 GPIO_OUTPUT_INIT_LOW | GPIO_OUTPUT_INIT_HIGH | GPIO_ACTIVE_LOW)
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

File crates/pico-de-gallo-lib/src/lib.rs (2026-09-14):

//! Host-side library for communicating with a Pico de Gallo USB bridge.
//!
//! This crate provides [`PicoDeGallo`], an async client for interacting with
//! the Pico de Gallo firmware over USB. It supports I2C reads/writes, SPI
//! operations (including full-duplex transfers), UART reads/writes, GPIO
//! control, PWM output, ADC sampling, 1-Wire bus operations, and device
//! configuration — all via [postcard-rpc](https://docs.rs/postcard-rpc)
//! endpoints.
//!
//! # Quick Start
//!
//! ```no_run
//! use pico_de_gallo_lib::PicoDeGallo;
//!
//! #[tokio::main]
//! async fn main() {
//!     let gallo = PicoDeGallo::new();
//!     let version = gallo.version().await.unwrap();
//!     println!("Firmware v{}.{}.{}", version.major, version.minor, version.patch);
//! }
//! ```
//!
//! # Multiple Devices
//!
//! When multiple Pico de Gallo boards are connected, use [`list_devices`] to
//! enumerate them and [`PicoDeGallo::new_with_serial_number`] to connect to a
//! specific board:
//!
//! ```no_run
//! use pico_de_gallo_lib::{PicoDeGallo, list_devices};
//!
//! #[tokio::main]
//! async fn main() {
//!     for dev in list_devices() {
//!         println!("Found: {:?}", dev.serial_number);
//!     }
//!     let gallo = PicoDeGallo::new_with_serial_number("ABCD1234");
//! }
//! ```
//!
//! # Error Handling
//!
//! All methods return [`Result<T, PicoDeGalloError<E>>`](PicoDeGalloError)
//! where `E` is the endpoint-specific error type. Errors are either
//! communication failures ([`PicoDeGalloError::Comms`]) or endpoint-level
//! errors ([`PicoDeGalloError::Endpoint`]).

pub mod decode;

use nusb::DeviceInfo as NusbDeviceInfo;
use pico_de_gallo_internal::{
    AdcGetConfiguration, AdcRead, AdcReadRequest, GetDeviceInfo, GpioEventTopic, GpioGet, GpioGetRequest, GpioPut,
    GpioPutRequest, GpioSetConfiguration, GpioSetConfigurationRequest, GpioSubscribe, GpioSubscribeRequest,
    GpioUnsubscribe, GpioUnsubscribeRequest, GpioWaitForAny, GpioWaitForFalling, GpioWaitForHigh, GpioWaitForLow,
    GpioWaitForRising, GpioWaitRequest, I2cBatch, I2cBatchRequest, I2cGetConfiguration, I2cRead, I2cReadRequest,
    I2cScan, I2cScanRequest, I2cSetConfiguration, I2cSetConfigurationRequest, I2cWrite, I2cWriteRead,
    I2cWriteReadRequest, I2cWriteRequest, MAX_HANDLER_TIMEOUT_MS, MICROSOFT_VID, OneWireRead, OneWireReadRequest,
    OneWireReset, OneWireSearch, OneWireSearchNext, OneWireWrite, OneWireWritePullup, OneWireWritePullupRequest,
    OneWireWriteRequest, PICO_DE_GALLO_PID, PwmDisable, PwmDisableRequest, PwmEnable, PwmEnableRequest,
    PwmGetConfiguration, PwmGetConfigurationRequest, PwmGetDutyCycle, PwmGetDutyCycleRequest, PwmSetConfiguration,
    PwmSetConfigurationRequest, PwmSetDutyCycle, PwmSetDutyCycleRequest, SCHEMA_VERSION_MAJOR, SCHEMA_VERSION_MINOR,
    SpiBatch, SpiBatchRequest, SpiFlush, SpiGetConfiguration, SpiRead, SpiReadRequest, SpiSetConfiguration,
    SpiSetConfigurationRequest, SpiTransfer, SpiTransferRequest, SpiWrite, SpiWriteRequest, SystemResetSubscriptions,
    UNDECLARED_DISPATCH_BUDGET_MS, UartFlush, UartGetConfiguration, UartRead, UartReadRequest, UartSetConfiguration,
    UartSetConfigurationRequest, UartWrite, UartWriteRequest, Version,
};

pub use pico_de_gallo_internal::{
    AdcChannel, AdcConfigurationInfo, Capabilities, DeviceInfo, GpioDirection, GpioEdge, GpioEvent, GpioPull,
    GpioState, I2cBatchOp, I2cFrequency, PwmConfigurationInfo, PwmDutyCycleInfo, SpiBatchOp, SpiConfigurationInfo,
    SpiPhase, SpiPolarity, UartConfigurationInfo, UartDataBits, UartParity, UartStopBits, VersionInfo,
};
pub use pico_de_gallo_internal::{
    AdcError, GpioError, I2cBatchError, I2cError, OneWireError, PwmError, SpiBatchError, SpiError, UartError,
};
pub use pico_de_gallo_internal::{
    BUILD_ID_CAPACITY, MAX_BATCH_OPS, MAX_REQUEST_FRAME, MAX_RESPONSE_PAYLOAD, MAX_TRANSFER_SIZE, NUM_GPIOS,
};
pub use pico_de_gallo_internal::{
    encode_i2c_batch_ops, encode_spi_batch_ops, i2c_batch_request_frame_len, i2c_batch_response_len,
    spi_batch_request_frame_len, spi_batch_response_len,
};

pub use postcard_rpc::host_client;
pub use postcard_rpc::host_client::HostErr;
pub use postcard_rpc::host_client::{IoClosed, MultiSubscription};
pub use postcard_rpc::standard_icd::WireError;
use postcard_rpc::{
    Endpoint,
    header::VarSeqKind,
    host_client::HostClient,
    postcard_schema::Schema,
    standard_icd::{ERROR_PATH, PingEndpoint},
};
use serde::Serialize;
use serde::de::DeserializeOwned;
use std::convert::Infallible;
use std::sync::{Arc, OnceLock};
use std::time::Duration;

/// Upper bound on how long a validated `device/info` round-trip may take
/// before [`PicoDeGallo::validate`] gives up with [`ValidateError::Timeout`].
///
/// Firmware dispatch is serial: one legal 64-operation SPI batch made
/// entirely of `DelayNs { ns: u32::MAX }` can occupy the dispatcher for
/// roughly 275 seconds, and a `device/info` queued behind it would be
/// delayed by that much without anything being wrong. Five minutes leaves
/// about 25 seconds of headroom for dispatch and USB overhead, so a healthy
/// maximum-length batch never produces a false timeout, while still giving
/// operators a finite, comprehensible upper bound instead of an
/// indefinite wait.
///
/// This bound is separate from [`DEFAULT_CALL_TIMEOUT`] and deliberately far
/// larger, because a queued `device/info` is exactly the case it must not
/// misdiagnose.
pub const DEVICE_INFO_TIMEOUT: Duration = Duration::from_secs(300);
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

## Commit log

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2025-08-27 Simplifying firmware
    Make sure that the entire FW requires only two endpoints, rather than
    a pair for each function. Otherwise memory requirements and USB HW EP
    requirements might be too much for the pico.
    [main.rs]
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2025-08-28 Add SetConfig method
    Still missing a way to configure then bus when allocating a new
    PicoDeGallo.
    [lib.rs, main.rs]
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2025-09-04 firmware: don't break in case of bus access errors
    Send the error code up to the caller.
    [main.rs]
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2025-09-23 clippy fixes
    run clippy on all crates fixing all warnings and errors.
    [lib.rs, main.rs]
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2026-07-27 feat(lib): Re-export HostErr and WireError for error mapping
    Additive public re-exports so downstream crates (gallo-mcp) can name
    the comms error types when mapping PicoDeGalloError to their own error
    representations. No behavior change; not a breaking change.
    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
    [lib.rs]
2026-07-27 feat(mcp): Map lib errors to MCP ErrorData
    Distinct 'no device attached' message for closed-connection comms
    errors; endpoint errors surfaced via Display; validate errors carry
    schema versions. Unit-tested.
    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
    [main.rs]
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2026-07-28 feat(mcp): Add 1-Wire tools
    onewire_read/search (search folds search_next via continue_search)
    annotated read-only; reset/write/write_pullup annotated destructive
    (reset drives a presence pulse, treated conservatively as a write).
    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
    [onewire.rs]
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2026-07-28 refactor(mcp): Remove temporary allow(dead_code)
    Every encoding validator and error helper now has a consumer across
    the peripheral tool modules, so the crate-level allow(dead_code)
    scaffold introduced during incremental development is no longer
    needed. clippy -D warnings stays clean without it.
    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
    [lib.rs]
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2026-07-28 fix(mcp): Open device per tool call, release between calls
    The MCP server constructed one PicoDeGallo in GalloMcp::new() and shared
    it for the whole server lifetime. Its background nusb worker claimed the
    USB interface until the process exited, so the board was busy forever and
    agentic (MCP) and traditional (gallo CLI) workflows could not compose.
    Replace the shared Arc<PicoDeGallo> + OnceCell<DeviceInfo> with a stored
    serial_number plus a shared connection lock, and open a fresh connection
    per tool call via a new GalloMcp::connect(), which validates schema
    compatibility and runs the connect-time subscription reset, returning a
    Device RAII guard that Derefs to PicoDeGallo. Each handler conn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
    [adc.rs, device.rs, gpio.rs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]
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2026-07-28 feat(lib): Add fallible try_new constructors, release 0.7.1
    new()/new_with_serial_number() call postcard-rpc's new_raw_nusb, which is
    try_new_raw_nusb(...).expect(...): it enumerates USB at construction and
    panics when no matching device is present or the interface claim fails. The
    prior doc comment ("constructing does not block or fail") was wrong.
    Add try_new()/try_new_with_serial_number() returning Result<Self, String>
    (thin wrappers over try_new_raw_nusb) so callers - notably gallo-mcp's
    per-call connect() - can report "no device attached" or retry a transient
    claim failure instead of panicking. new_inner now delegates to
    try_new_inner().expect(...), preserving the existing panicking be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
    [lib.rs]
2026-07-28 fix(mcp): Handle missing board and claim races in connect
    PicoDeGallo::new() panics when no board is present or the USB claim fails,
    so the per-call connect() could panic instead of returning a clean error -
    defeating status's attached:false path and the "starts even with no board"
    promise - and the previous connection's asynchronous USB release could make
    a fresh claim transiently fail on Windows (AGENTS.md 13.17) even with the
    serialization mutex.
    connect() now uses the fallible PicoDeGallo::try_new*(): a "Failed to find
    matching nusb device" error maps to a clean "no device attached" result, and
    other (claim) failures are retried up to 5 times with a 100ms backoff to
    absorb the async rel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
    [lib.rs]
2026-08-03 fix(ffi): Run pico-de-gallo-ffi calls on a Tokio runtime
    This commit tries to fix an issue that would spawn panics when using FFI on real hardware. It seems that
    postcard-rpc-0.12.1 uses tokio::task::spawn() under the hood, but the raw C FFI doesn't run in a runtime (causing its
    calls to futures::executor::block_on to panic). To fix this, this commit adds a `runtime()` function that stores a
    static runtime that can be used by all the FFI calls.
    This commit also fixes a smaller issue where the `/* I2C supported */` comment causes the C code to fail to build
    because it gets inserted into another C multi-line doc, causing that doc to end early (and as such the rest of the
    doc would get treated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
    [lib.rs]
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2026-08-05 feat(mcp): Add pure device selection policy
    Decide which board a tool call targets from the attached serials, the
    server's --serial-number pin, and the call's optional serial_number.
    The policy is deliberately free of USB and async so the whole matrix is
    unit-testable with no hardware: zero attached, one attached (with and
    without an argument), two or more attached, a pinned server, and boards
    that report no USB serial at all.
    Omitting serial_number stays legal at N==1, which keeps the common
    single-board path frictionless, and becomes an error at N>=2, where
    guessing would convert a recoverable mistake into a silent wrong
    answer. The error names the available serials so an agent recovers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
    [lib.rs, select.rs]
2026-08-05 fix(mcp): Refuse duplicate serials in selection
    resolve_target asked "is this serial present" via any(), not "how many
    boards answer to it". Two boards sharing a serial therefore resolved to
    Ok(Some(X)) and the caller opened whichever enumerated first — the
    exact silent wrong-board guess this module exists to prevent, except
    the response would carry a serial number lending it false credibility.
    That is reachable, not theoretical: the firmware falls back to a chip
    ID of 0 when the OTP read fails (pico-de-gallo-firmware/src/main.rs
    :243), which formats to the constant "0000000000000000", and the
    comment there notes it happens on some dev boards. Two such boards
    collide. Both the pinned and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
    [select.rs]
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2026-08-05 fix(mcp): Correct the vanished-board error message
    connect()'s not-found handler carried a comment saying that claiming
    "no device attached" would mislead once enumeration had already seen
    the board, and then its None arm said exactly that. That arm is only
    reachable when resolve_target returned Ok(None), which requires
    exactly one attached board: the empty case fails earlier with
    SelectError::NoDevice and never reaches the open at all. So the arm
    always described a board that went away between enumeration and open,
    it contradicted its own comment, and the previous commit's claim that
    a vanished board "now says so instead of claiming none was ever
    attached" was false for serial-less boards.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
    [lib.rs]
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2026-08-05 feat(mcp): Select the UART and ADC target per call
    Add the optional serial_number argument to every UART and ADC tool and
    return results through the device envelope. uart_flush,
    uart_get_config, and adc_get_config took no arguments before and now
    take the shared selector.
    Dropping ok_json from the imports makes any missed call site a compile
    error rather than a silently un-enveloped response.
    Widen read_params_deserialize in uart.rs to carry the serial, so the
    sibling fields are asserted to still land when it is present, and
    restore the blank-line spacing spi.rs uses between params structs,
    handlers, and tests.
    Assisted-by: GitHub Copilot:claude-opus-5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
    [adc.rs, uart.rs]
2026-08-05 test(mcp): Revert the UART read-params widening
    read_params_deserialize was widened to carry serial_number, but it
    targets UartReadParams with the same JSON literal that the new
    read_params_accept_an_optional_serial_number already parses in its
    `with` arm. Two tests, identical input, and the widened assertions are
    a strict subset of the new test's.
    The widening also dropped coverage. Before it, read_params_deserialize
    parsed the legacy payload {"count":4,"timeout_ms":1000} and asserted
    count and timeout_ms, so a client written before this feature was
    proven to still deserialize. After it, no test in uart.rs asserted the
    sibling fields on that payload: the new test's `without` arm parses it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
    [uart.rs]
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2026-08-05 feat(mcp): Select the GPIO and PWM target per call
    Add the optional serial_number argument to every GPIO and PWM tool and
    return results through the device envelope. Both modules already took
    parameters everywhere, so no shared selector is needed here; one field
    on GpioWaitParams covers three tools and one on PwmChannelParams covers
    four.
    Driving the wrong pin on the wrong board is the sharpest edge of the
    ambiguity this fixes, since gpio_set_config and gpio_put are a stateful
    pair across calls.
    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
    [gpio.rs, pwm.rs]
2026-08-05 test(mcp): Cover destructive GPIO and PWM params
    Move gpio's one new serial_number test from GpioWaitParams to
    GpioSetConfigParams. The wait struct backs three read-only tools, while
    gpio_set_config and gpio_put are the destructive pair this branch exists
    to disambiguate; the swap also pins the interaction between the new
    field and the pull field's serde default. GpioWaitParams keeps its
    coverage via the existing wait_params_deserialize.
    Restore the field-absent half of pwm's widened set_config_params test.
    Every other new test asserts both directions, and after the widening
    nothing asserted that the legacy payload agents and doc examples still
    emit deserializes PwmSetConfigParams.
    Also ho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
    [gpio.rs, pwm.rs]
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2026-08-05 feat(mcp): Select the 1-Wire target per call
    Add the optional serial_number argument to every 1-Wire tool and return
    results through the device envelope. onewire_reset took no arguments
    before and now takes the shared selector.
    ROM search is stateful across calls: onewire_search followed by
    onewire_search with continue_search only means anything against the
    board that started it. An echoed serial makes a continuation against
    the wrong board visible instead of silent.
    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
    [onewire.rs]
2026-08-05 fix(mcp): Name the board a ROM search continues
    continue_search resumed "a previous search", which assumed a previous
    search names a unique thing. Selecting the target per call is what made
    that reachable: search state is a per-board PioOneWireSearch built once
    at boot (firmware context.rs:88,123), and the reset-subscriptions call
    connect issues on every tool call tears down GPIO subscriptions only
    (firmware handlers/gpio.rs:366-384). The cursor therefore straddles both
    calls and boards.
    With two boards attached, searching A and then continuing against B
    returns B's first ROM, or None if B's search is already exhausted. Both
    look like data, neither raises an error. Say so in the field doc,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
    [onewire.rs]
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2026-08-05 fix(mcp): Correct the serial_number description
    The text replicated across all 26 params structs and TargetParams said
    the argument is "Required when two or more boards are attached; optional
    when exactly one is". That is wrong for a pinned server: with
    --serial-number A and boards A and B attached, resolve_target takes the
    pinned branch and omitting serial_number succeeds.
    So the schema declared the argument required in exactly the
    configuration where it is optional, and an agent that had just seen two
    serials from list_devices was as likely to supply the wrong one as the
    right one.
    Fix it now, while it is a mechanical replace across seven peripheral
    modules and select.rs. Task 8 hard-cod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
    [adc.rs, gpio.rs, i2c.rs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]
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2026-08-05 feat(mcp): Make list_devices and status honest
    status previously turned any connect failure into attached:false. Under
    the new ambiguity rule that would report "no board" while two were
    attached — a fresh silent lie in exactly the scenario this fixes. It now
    never errors and never lies: it reports attached, ambiguous, available,
    pinned, and a reason explaining any unresolved target, so it remains the
    one call an agent can always make to orient itself.
    list_devices becomes an object carrying per-entry pinned and
    default_target flags plus serial_number_required and a note, stating the
    rule where the agent is already reading serials. The top-level pinned
    field is separate from the per-entry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
    [device.rs, lib.rs]
2026-08-05 fix(mcp): Report ambiguity as a bench property
    StatusResult.ambiguous is documented as "True when two or more boards
    are attached and the server is unpinned", but build_status computed it
    from a resolution that included the call's own serial_number. The two
    disagreed whenever the caller named a board: with A and B attached and
    the server unpinned, status(serial_number: "A") resolved cleanly, so
    ambiguous was false and reason absent — while the bench was ambiguous
    for any bare call.
    That is the wrong signal from the one tool an agent uses to orient
    itself. "Is board A still up?" is naturally asked with an explicit
    serial, and the old answer implied that omitting serial_number on the
    next i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
    [device.rs]
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2026-08-05 fix(mcp): Lock connections per board, not server
    One server-wide mutex meant a tool call holding a connection blocked
    every other call, including calls naming a different board. That was
    invisible while the server could only ever reach one board. Now that it
    can reach several, gpio_wait_for_any_edge_with_timeout holds the lock
    for its whole wait — and validate_timeout_ms rejects only zero, so that
    wait can be 49.7 days. Every call to the other board would block, with
    no error and no diagnostic.
    The lock guards the exclusive WinUSB interface claim and postcard-rpc's
    asynchronous release window. Both are properties of one device, so two
    boards can be claimed at once and the lock belongs on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
    [lib.rs]
2026-08-05 test(mcp): Guard the per-board lock scoping
    Whether lock_for releases the map lock before awaiting the per-board
    lock is the single load-bearing property of c1fc236871e5: holding it
    across that await reintroduces the server-wide serialisation the commit
    exists to remove. That property shipped unguarded. Both tests added
    with it pass against the mis-scoped version — in the first, lock_for(A)
    has already returned before B is requested, so even the broken code has
    released the map guard; in the second nothing else contends for the map
    while the timeout runs. A doc comment is thin cover for that in a
    repository whose regression log is mostly concurrency bugs that stayed
    invisible until hardwar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
    [lib.rs]
2026-08-05 refactor(mcp): Make the map lock scoping enforced
    Whether lock_for releases the map guard before awaiting the per-board
    lock is the load-bearing property of c1fc236871e5, and it was protected
    only by a comment plus one test. The outer map's critical section is a
    hash probe and an Arc clone with no await in it, so it never needed an
    async mutex. Guarding it with std::sync::Mutex instead makes the
    regression impossible to compile: that guard is !Send, so holding it
    across the await makes every rmcp handler future !Send, and the build
    fails pointing at the guard binding.
    Note this is stronger than the clippy::await_holding_lock lint that
    motivated the change, and arrives by a different route: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
    [lib.rs]
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2026-08-05 test(mcp): Guard the tool surface, state the rule
    Assert over every registered tool that serial_number is present in the
    input schema and absent from `required`. The field was added by hand to
    28 structs; a single missed struct is invisible to review but would
    silently keep one tool unselectable.
    A second guard scans the peripheral sources for `connect(None)` and for
    `ok_json(`, exempting device.rs where list_devices and status
    legitimately answer without opening a board. Declaring the field and
    then dropping it compiles clean, passes the schema test and both
    per-module tests; only this catches it.
    Also state the N>=2 rule in the server instructions. The consumer is an
    LLM, which emits min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
    [lib.rs]
2026-08-05 test(mcp): Fail if a tool module escapes the scan
    The schema guard iterates the live router, so a ninth peripheral module
    extends it for free. The source scan's module list is hand-written,
    because `include_str!` needs literal paths — so the half that catches
    the split defect was the half that would silently miss a new module,
    and the compiler and the schema test both stay quiet about it.
    Derive the scan list from the `include_str!` array, then walk src/ and
    assert every file declaring tools appears in it. The needle is split
    with `concat!` so lib.rs does not match itself and report a module that
    registers nothing.
    Also assert the hardware-revision caveat in the server instructions.
    12 o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
    [lib.rs]
2026-08-05 test(mcp): Guard the router the server serves
    router_for_test duplicated the router sum from GalloMcp::new. Harmless
    when it backed one per-module registration test; not harmless now that
    it is the substrate of the surface-wide schema guard. A ninth module
    added to the copy — which is what turns a new registration test green —
    and forgotten in new() would leave the guard asserting over tools the
    server never serves. Build it from new(None) instead, which opens no
    USB connection. Tool count is unchanged: 43 registered, 42 asserted.
    The scan tripwire now rejects a subdirectory under src/. read_dir does
    not recurse and the extension filter skips directories silently, so
    src/peripherals/dac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
    [lib.rs]
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2026-08-05 test(mcp): Restore bus config after the leak test
    configuration_set_on_one_board_does_not_leak_to_the_other left board
    A at Fast (400 kHz) and B at Standard, and nothing put them back. The
    firmware keeps i2c_frequency in a boot-lifetime Context
    (pico-de-gallo-firmware/src/context.rs:79); no host path resets it,
    since the connect-time system_reset_subscriptions walks GPIO slots
    only (pico-de-gallo-firmware/src/handlers/gpio.rs:366).
    libtest runs tests in collection order, which is not a guarantee. If
    each_serial_reaches_its_own_board ran afterwards with the sensor on
    the board left at 400 kHz, a marginal bus could drop that sensor from
    i2c_scan, giving scan_a == scan_b == [] and failing the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
    [lib.rs]
2026-08-05 test(mcp): Keep bench faults out of assertions
    Three of these fixes share one failure mode: a problem with the bench
    surfacing inside an assertion about the server, on the first hardware
    run of a branch whose whole claim rests on these seven results. That
    reads as a selection defect at exactly the moment selection is being
    judged.
    serials() now checks both boards are attached, not merely that two
    different strings were supplied. A stale or mistyped serial used to
    fail inside a product assertion about the server's error text. Worse,
    a_pinned_server_serves_its_own_board_two_ways degenerated silently:
    with B absent, resolve_target returns A as the sole attached board
    rather than as the pinned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
    [lib.rs]
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2026-08-05 fix(mcp): Correct the --serial-number help text
    The flag's doc comment still said "(default: first match)", which is the
    behaviour issue #89 removed. With two boards attached and no -s there is
    no first match: resolve_target returns Ambiguous and the call is refused
    with the available serials. So `gallo-mcp --help` advertised the guess
    the crate now exists to prevent, and contradicted the book chapter,
    which describes the flag correctly as a pin.
    Describe what the flag actually does instead: it pins the server to one
    board, a call omitting serial_number uses that board, and a call naming
    a different one is refused (SelectError::PinConflict). Split across
    clap's short and long help so `-h` s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
    [main.rs]
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2026-08-05 fix(mcp): Warn on an unusable --serial-number pin
    `gallo-mcp -s <typo>` started clean and then failed every device call
    with PinnedNotFound for the rest of the session. That is worse than an
    ordinary typo: --serial-number is the only defence against addressing
    the wrong board that holds by construction rather than by agent
    diligence, and it failed open.
    `GalloMcp::warn_if_pin_unresolvable`, called once from main, defers to
    resolve_target rather than re-deriving "is the pin attached", so the
    warning cannot drift from the policy and a pin two boards answer to is
    reported for free. An empty bus is deliberately silent: a pin is
    trivially unresolvable when nothing is attached, but starting with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
    [lib.rs, main.rs, select.rs]
2026-08-05 fix(mcp): Show the pin warning without RUST_LOG
    The warning added in 7f8634443bbf could not reach the operator it was
    written for. `EnvFilter::from_default_env()` applies its default
    directive when RUST_LOG is unset, and MCP clients spawn this server with
    whatever environment they have -- which in practice means no RUST_LOG.
    So the one case the warning exists to catch, a mistyped --serial-number
    in a client config, was exactly the case that stayed silent.
    Fall back to an explicit filter when RUST_LOG is absent, via
    try_from_default_env, which errors only when the variable is unset or
    unparseable. A RUST_LOG that is set still wins outright.
    The fallback is `error,gallo_mcp=warn` rather than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
    [main.rs]
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2026-08-11 fix(zephyr): Correct two I2C log format strings
    Both defects reproduce under `gcc -Wall -Wextra -Wformat=2`.
    `freq_to_speed_()` built its diagnostic from `"(frequency=% "
    PRIu32 ")"`. The space between `%` and the `PRIu32` expansion makes
    `% u` a valid space-flagged conversion rather than a literal, so the
    compiler demands an argument that was never supplied:
    warning: ' ' flag used with '%u' gnu_printf format
    warning: format '%u' expects a matching 'unsigned int' argument
    Under CONFIG_LOG_MODE_DEFERRED, Zephyr's cbprintf packages arguments
    by compile-time count, so a `%u` conversion against a zero-argument
    package reads past the end of the package. The path is reachable from
    any d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
    [pdg_i2c.c]
2026-08-12 feat(ffi): Export transfer limits and config enums
    C consumers had to hard-code every limit and configuration value the
    FFI accepts, because the generated header exposed only `Status`, the
    `GALLO_CAP_*` bits, and three structs. Everything else was a bare
    `uint8_t` whose meaning lived in a doc comment, so each caller grew
    its own copy of 4096, 64, and the 0/1/2 encodings, with nothing to
    catch drift.
    Export the two firmware limits as `GALLO_MAX_TRANSFER_SIZE` and
    `GALLO_MAX_BATCH_OPS`, and name the integer encodings via
    `GalloI2cFrequency`, `GalloGpioDirection`, `GalloGpioPull`,
    `GalloGpioEdge`, `GalloI2cBatchOpTag`, and `GalloSpiBatchOpTag`.
    This is additive. Every `gallo_*` signature stil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
    [lib.rs]
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

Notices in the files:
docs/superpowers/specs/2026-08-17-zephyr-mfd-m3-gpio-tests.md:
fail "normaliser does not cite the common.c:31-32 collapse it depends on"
